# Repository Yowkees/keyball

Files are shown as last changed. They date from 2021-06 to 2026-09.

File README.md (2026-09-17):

# Keyball Series

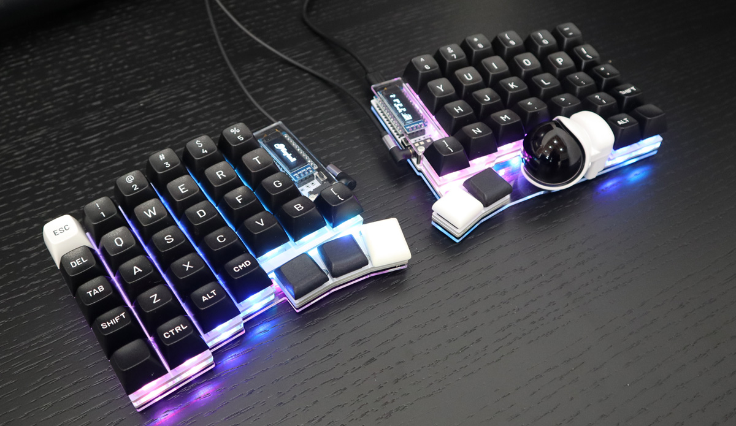
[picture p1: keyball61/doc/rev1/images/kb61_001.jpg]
Keyball61


Keyball series is keyboard family which have 100% track ball.

Keyboards in the family are:

* Available
    * Keyball39: split + 39 keys + a track ball
    * Keyball44: split + 44 keys + a track ball
    * Keyball61: split + 61 keys + a track ball
    * Keyball+ : split + 38 or 39 keys + a track ball
* Unavailable
    * Keyball46 (first one!)
    * One47

## Where to Buy

|Keyboard |Shirogane Lab / 白銀ラボ |Yushakobo / 遊舎工房 |
|---|---|---|
|Keyball39  |<https://shiroganelab.com/products/keyball39> |<https://shop.yushakobo.jp/products/5357>  |
|Keyball44  |<https://shiroganelab.com/products/keyball44> |<https://shop.yushakobo.jp/products/8337>  |
|Keyball61  |<https://shiroganelab.com/products/keyball61> |<https://shop.yushakobo.jp/products/5358>  |
|Keyball+  |[TOKYO KEYBOARD EXPO 2026](https://tkx.yushakobo.jp/tkx2026/)|[TOKYO KEYBOARD EXPO 2026](https://tkx.yushakobo.jp/tkx2026/)|

## Build Guide

*   Keyball39:
    [English/英語](/keyball39/doc/rev1/buildguide_en.md),
    [日本語/Japanese](./keyball39/doc/rev1/buildguide_jp.md)
*   Keyball44:
    [English/英語](./keyball44/doc/rev1/buildguide_en.md),
    [日本語/Japanese](./keyball44/doc/rev1/buildguide_jp.md)
*   Keyball61:
    [English/英語](./keyball61/doc/rev1/buildguide_en.md),
    [日本語/Japanese](./keyball61/doc/rev1/buildguide_jp.md)
*   Keyball+:
    [English/英語](./keyballplus/doc/rev1/buildguide_en.md),
    [日本語/Japanese](./keyballplus/doc/rev1/buildguide_jp.md)
    
## Firmware

See [document for firmware source code](./qmk_firmware/keyboards/keyball/readme.md).

### Pre-compiled Firmwares

(TO BE DOCUMENTED)

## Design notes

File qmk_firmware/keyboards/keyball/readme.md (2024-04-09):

# Keyball series

This directory includes source code of Keyball keyboard series:

| Name | Description
|---|---
|[Keyball46](./keyball46)|A split keyboard with 46 vertically staggered keys and 34mm track ball.
|[Keyball61](./keyball61)|A split keyboard with 61 vertically staggered keys and 34mm track ball.
|[Keyball39](./keyball39)|A split keyboard with 39 vertically staggered keys and 34mm track ball.
|[ONE47](./one47)|A keyboard with 47 vertically keys and 34mm trackball. It will support BLE Micro Pro.
|[Keyball44](./keyball44)|A split keyboard with 44 vertically staggered keys and 34mm track ball.

* Keyboard Designer: [@Yowkees](https://twitter.com/Yowkees)  
* Hardware Supported: ProMicro like footprint
* Hardware Availability: See [Where to Buy](../../../README.md#where-to-buy)

See each directories for each keyboards in a table above.

## How to build

1. Check out this repository.

    ```console
    $ git clone https://github.com/Yowkees/keyball.git keyball
    ```

2. Check out [qmk/qmk_firmware](https://github.com/qmk/qmk_firmware/) repository in another place.

    ```console
    $ git clone https://github.com/qmk/qmk_firmware.git --depth 1 --recurse-submodules --shallow-submodules -b 0.22.14 qmk
    ```

    Currently Keyball firmwares are verified to compile with QMK 0.22.14

3. Create a symbolic link to this `keyball/` directory from [qmk/qmk_firmware]'s `keyboards/` directory.

    ```console
    $ ls
    keyball/ qmk/

    $ cd qmk/keyboards
    $ ln -s ../../keyball/qmk_firmware/keyboards/keyball keyball
    $ ls keyball/
    drivers/  keyball39/  keyball44/  keyball46/  keyball61/  lib/  one47/  readme.md
    $ cd ..
    ```

4. `make` your Keyball firmware.

    ```console
    # Build Keyball39 firmware with "default" keymap
    $ make SKIP_GIT=yes keyball/keyball39:default

    # Build Keyball44 firmware with "default" keymap
    $ make SKIP_GIT=yes keyball/keyball44:default

    # Build Keyball61 firmware with "default" keymap
    $ make SKIP_GIT=yes keyball/keyball61:default
    ```

There are three keymaps provided at least:

* `via` - Standard version with [Remap](https://remap-keys.app/) or VIA to change keymap
* `test` - Easy-to-use version for checking operation at build time
* `default` - Base version for creating your own customized firmware

## How to create your keymap

1. Fork this Yowkees/keyball repository
2. Checkout forked repository
3. (OPTIONAL) Create a new branch
4. Add a your keymap, or make some changes
5. Commit changes and push it to your forked repository
6. Open your forked repository with web browser
7. Click and open "Actions" tab
8. Click "Build a firmware on demand" in Workflows on left panel
9. Press "Run workflow" button on right side, then you will see forms
10. (OPTIONAL) Select a your working branch
11. Select a "Keyboard" from drop-down list
12. Enter the "keymap" you want to build
13. Click "Run workflow"
14. Wait a minute until the firmware build is finished
15. Click a latest workflow run and open details
16. Download built firmware in "Artifacts" section

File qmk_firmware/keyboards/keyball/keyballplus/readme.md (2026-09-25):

# Keyballplus

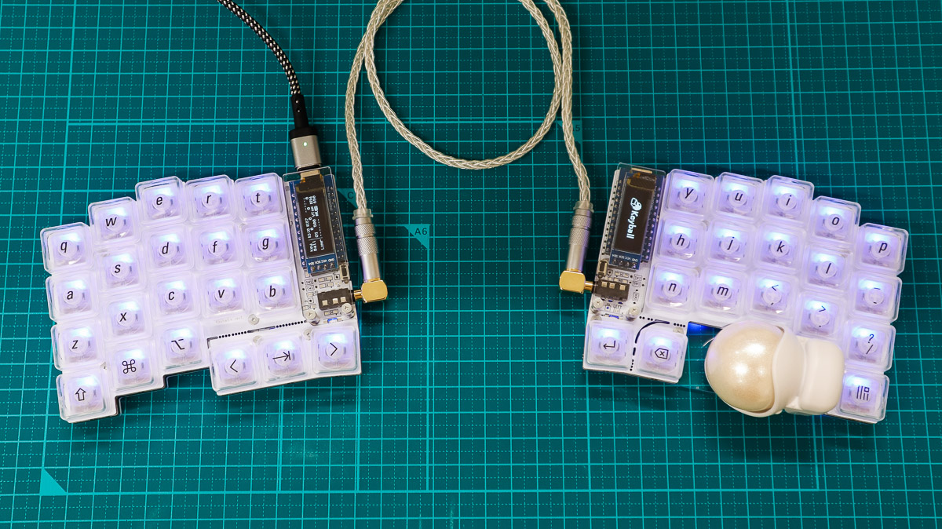
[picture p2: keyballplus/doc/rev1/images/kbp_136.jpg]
keyballplus


A split keyboard with 39 or 38 vertically staggered keys and 34mm track ball.

* Keyboard Maintainer: [@Yowkees](https://twitter.com/Yowkees)
* Hardware Supported: keyballPlus PCB, ProMicro
* Hardware Availability:
    * <https://shop.yushakobo.jp>
    * <https://shiroganelab.com>

Make example for this keyboard (after setting up your build environment):

    make keyball/keyballPlus:default

See the [build environment setup](https://docs.qmk.fm/#/getting_started_build_tools) and the [make instructions](https://docs.qmk.fm/#/getting_started_make_guide) for more information. Brand new to QMK? Start with our [Complete Newbs Guide](https://docs.qmk.fm/#/newbs).

## Special keycodes

See [Special Keycode](../lib/keyball/keycodes.md) file.

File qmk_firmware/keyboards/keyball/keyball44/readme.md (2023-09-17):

# Keyball44

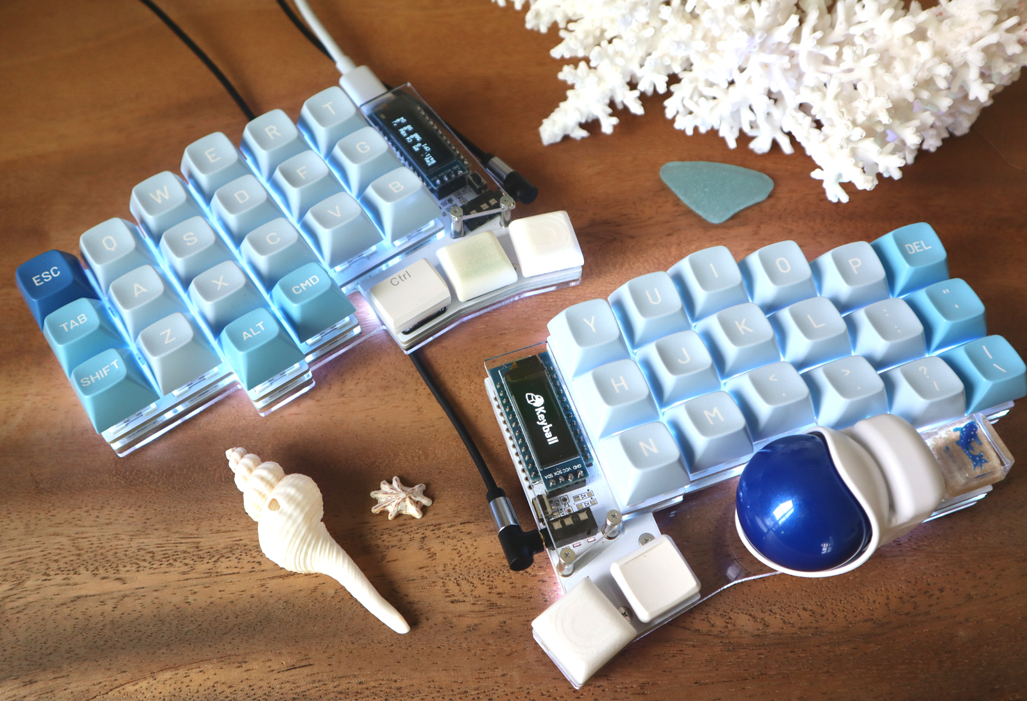
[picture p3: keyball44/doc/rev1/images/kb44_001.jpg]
Keyball44


A split keyboard with 44 vertically staggered keys and 34mm track ball.

* Keyboard Maintainer: [@Yowkees](https://twitter.com/Yowkees)
* Hardware Supported: Keyball44 PCB, ProMicro
* Hardware Availability:
    * <https://shirogane-lab.net/items/64b7a006eb6dbe00346cd0c5>

Make example for this keyboard (after setting up your build environment):

    make keyball/keyball44:default

See the [build environment setup](https://docs.qmk.fm/#/getting_started_build_tools) and the [make instructions](https://docs.qmk.fm/#/getting_started_make_guide) for more information. Brand new to QMK? Start with our [Complete Newbs Guide](https://docs.qmk.fm/#/newbs).

## Special keycodes

See [Special Keycode](../lib/keyball/keycodes.md) file.

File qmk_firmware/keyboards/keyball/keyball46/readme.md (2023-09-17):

# Keyball46

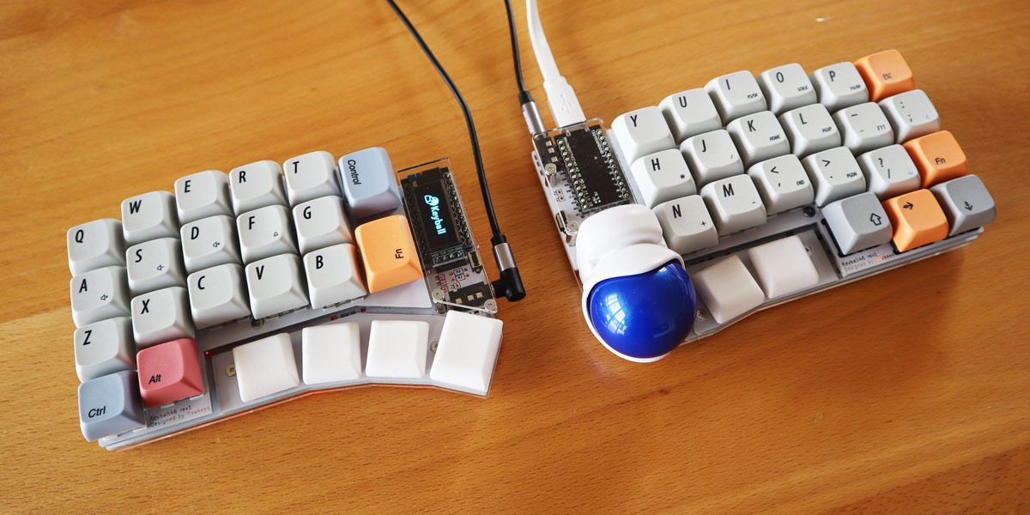
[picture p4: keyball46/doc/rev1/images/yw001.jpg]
Keyball46


A split keyboard with 4x6 vertically staggered keys and 34mm track ball.

* Keyboard Maintainer: [@Yowkees](https://twitter.com/Yowkees)
* Hardware Supported: Keyball46 PCB, ProMicro
* Hardware Availability:
  Unavailable
  * ~~[BOOTH](https://yowkees.booth.pm/)~~

Make example for this keyboard (after setting up your build environment):

    make keyball/keyball46:default

See the [build environment setup](https://docs.qmk.fm/#/getting_started_build_tools) and the [make instructions](https://docs.qmk.fm/#/getting_started_make_guide) for more information. Brand new to QMK? Start with our [Complete Newbs Guide](https://docs.qmk.fm/#/newbs).

## Special keycodes

See [Special Keycode](../lib/keyball/keycodes.md) file.

## Changes

* Keyball46 firmware V2 has some incompatibles with V1. See [document](./docs/diff_from_v1.md) for details.

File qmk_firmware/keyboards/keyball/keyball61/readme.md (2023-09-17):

# Keyball61

Keyball61

A split keyboard with 61 vertically staggered keys and 34mm track ball.

* Keyboard Maintainer: [@Yowkees](https://twitter.com/Yowkees)
* Hardware Supported: Keyball61 PCB, ProMicro
* Hardware Availability:
    * <https://shop.yushakobo.jp/products/5358>
    * <https://shirogane-lab.net/items/64b8ed191435c1002bc4cd30>

Make example for this keyboard (after setting up your build environment):

    make keyball/keyball61:default

See the [build environment setup](https://docs.qmk.fm/#/getting_started_build_tools) and the [make instructions](https://docs.qmk.fm/#/getting_started_make_guide) for more information. Brand new to QMK? Start with our [Complete Newbs Guide](https://docs.qmk.fm/#/newbs).

## Special keycodes

See [Special Keycode](../lib/keyball/keycodes.md) file.

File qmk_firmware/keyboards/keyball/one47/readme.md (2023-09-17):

# KeyballONE47

![KeyballONE47]()

A split keyboard with 47 vertically staggered keys and 34mm track ball.

* Keyboard Maintainer: [@Yowkees](https://twitter.com/Yowkees)
* Hardware Supported: KeyballONE47 PCB, ProMicro
* Hardware Availability:
    Unavailable

Make example for this keyboard (after setting up your build environment):

    make keyball/one47:test

See the [build environment setup](https://docs.qmk.fm/#/getting_started_build_tools) and the [make instructions](https://docs.qmk.fm/#/getting_started_make_guide) for more information. Brand new to QMK? Start with our [Complete Newbs Guide](https://docs.qmk.fm/#/newbs).

## Special keycodes

See [Special Keycode](../lib/keyball/keycodes.md) file.

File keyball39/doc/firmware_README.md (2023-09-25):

# Keyball39 firmwares README

## Description in English

This archive includes firmwares for Keyball39.

Included variations of firmware are below:

* `default` - base version for customization
* `test` - used for testing during assembly
* `via` - Recommended version that can use [Remap][remap]

The recommended usage of these firmwares is:

1.  Please use `test` version during assemble the keyboard.
    It is designed to help verifying that the soldering of diodes and switch
    sockets is correct, and easy to check the operation of RGB LED.
2.  After confirming the operation, rewrite it with `via` version.

## 日本語の説明

このアーカイブには Keyball39 のファームウェアが含まれています。

含まれているファームウェアのバリエーションは以下の通りです:

* `default` - カスタマイズの基礎となる版
* `test` - 組立時のテストに用いる版
* `via` - [Remap][remap] で利用できる、推奨版

推奨する使い方は次の通りです:

1.  キーボードを組み立てる際は `test` を使ってください。
    ダイオードやスイッチソケットのハンダ付けが正しいか確認できる他、
    RGB LEDの動作確認が容易になるように構成してあります。
2.  動作確認が取れたあとは `via` に書き換えて利用してください。

## Fixed keymap for `test`

This keymap does not use any layers or QMK function keys to make it easier to test.

```
KC_Q     KC_W     KC_E     KC_R     KC_T                            KC_Y     KC_U     KC_I     KC_O     KC_P
KC_A     KC_S     KC_D     KC_F     KC_G                            KC_H     KC_J     KC_K     KC_L     KC_SCLN
KC_Z     KC_X     KC_C     KC_V     KC_B                            KC_N     KC_M     KC_COMM  KC_DOT   KC_SLSH
KC_LCTL (KC_LGUI  KC_LALT  KC_ESC)  KC_SPC   KC_TAB        KC_BSPC  KC_ENT  (KC_ESC   KC_RALT  KC_RGUI) KC_RSFT
```

The area enclosed in parentheses may be replaced by a trackball.

<https://config.qmk.fm/#/test> is useful for testing keys.

[remap]:https://remap-keys.app/

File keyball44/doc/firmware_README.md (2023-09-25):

# Keyball44 firmwares README

## Description in English

This archive includes firmwares for Keyball44.

Included variations of firmware are below:

* `default` - base version for customization
* `test` - used for testing during assembly
* `via` - Recommended version that can use [Remap][remap]

The recommended usage of these firmwares is:

1.  Please use `test` version during assemble the keyboard.
    It is designed to help verifying that the soldering of diodes and switch
    sockets is correct, and easy to check the operation of RGB LED.
2.  After confirming the operation, rewrite it with `via` version.

## 日本語の説明

このアーカイブには Keyball44 のファームウェアが含まれています。

含まれているファームウェアのバリエーションは以下の通りです:

* `default` - カスタマイズの基礎となる版
* `test` - 組立時のテストに用いる版
* `via` - [Remap][remap] で利用できる、推奨版

推奨する使い方は次の通りです:

1.  キーボードを組み立てる際は `test` を使ってください。
    ダイオードやスイッチソケットのハンダ付けが正しいか確認できる他、
    RGB LEDの動作確認が容易になるように構成してあります。
2.  動作確認が取れたあとは `via` に書き換えて利用してください。

## Fixed keymap for `test`

This keymap does not use any layers or QMK function keys to make it easier to test.

```
KC_ESC   KC_Q     KC_W     KC_E     KC_R     KC_T                           KC_Y     KC_U     KC_I     KC_O     KC_P     KC_MINS
KC_TAB   KC_A     KC_S     KC_D     KC_F     KC_G                           KC_H     KC_J     KC_K     KC_L     KC_SCLN  KC_QUOT
KC_LSFT  KC_Z     KC_X     KC_C     KC_V     KC_B                           KC_N     KC_M     KC_COMM  KC_DOT   KC_SLSH  KC_RSFT
         KC_LCTL    (KC_LGUI   KC_LALT)      KC_SPC   KC_DEL       KC_BSPC  KC_ENT     (KC_RALT   KC_RGUI)      KC_RCTL
```

The area enclosed in parentheses may be replaced by a trackball.

<https://config.qmk.fm/#/test> is useful for testing keys.

[remap]:https://remap-keys.app/

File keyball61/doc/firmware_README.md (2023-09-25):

# Keyball61 firmwares README

## Description in English

This archive includes firmwares for Keyball61.

Included variations of firmware are below:

* `default` - base version for customization
* `test` - used for testing during assembly
* `via` - Recommended version that can use [Remap][remap]

The recommended usage of these firmwares is:

1.  Please use `test` version during assemble the keyboard.
    It is designed to help verifying that the soldering of diodes and switch
    sockets is correct, and easy to check the operation of RGB LED.
2.  After confirming the operation, rewrite it with `via` version.

## 日本語の説明

このアーカイブには Keyball61 のファームウェアが含まれています。

含まれているファームウェアのバリエーションは以下の通りです:

* `default` - カスタマイズの基礎となる版
* `test` - 組立時のテストに用いる版
* `via` - [Remap][remap] で利用できる、推奨版

推奨する使い方は次の通りです:

1.  キーボードを組み立てる際は `test` を使ってください。
    ダイオードやスイッチソケットのハンダ付けが正しいか確認できる他、
    RGB LEDの動作確認が容易になるように構成してあります。
2.  動作確認が取れたあとは `via` に書き換えて利用してください。

## Fixed keymap for `test`

This keymap does not use any layers or QMK function keys to make it easier to test.

```
KC_ESC   KC_1     KC_2     KC_3     KC_4     KC_5                            KC_6     KC_7     KC_8     KC_9     KC_0     KC_MINS
KC_GRV   KC_Q     KC_W     KC_E     KC_R     KC_T                            KC_Y     KC_U     KC_I     KC_O     KC_P     KC_EQL
KC_LCTL  KC_A     KC_S     KC_D     KC_F     KC_G                            KC_H     KC_J     KC_K     KC_L     KC_SCLN  KC_QUOT
KC_LSFT  KC_Z     KC_X     KC_C     KC_V     KC_B     KC_LBRC       KC_RBRC  KC_N     KC_M     KC_COMM  KC_DOT   KC_SLSH  KC_RSFT
KC_LGUI  KC_APP  (KC_HOME  KC_END   KC_LALT) KC_SPC   KC_TAB        KC_BSPC  KC_ENT  (KC_RALT  KC_PGUP  KC_PGDN) KC_BSLS  KC_RGUI
```

The area enclosed in parentheses may be replaced by a trackball.

<https://config.qmk.fm/#/test> is useful for testing keys.

[remap]:https://remap-keys.app/

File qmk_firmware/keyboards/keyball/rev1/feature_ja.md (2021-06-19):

# Keyball のカスタマイズ可能な機能

## トラックボール

### `TRACKBALL_DRIVER_DISABLE`

Keyballに付属のデフォルトのトラックボールドライバーを無効化する設定項目です。
各キーマップで独自のドライバーを用意する場合に設定することで、デフォルトドライ
バーが省略されその分ファームウェアが小さくなります。

各キーマップの config.h で設定できます。

設定例:

```c
#define TRACKBALL_DRIVER_DISABLE 100
```

### `TRACKBALL_SAMPLE_COUNT`

トラックボールでは光学センサから数回に渡って読み取った平均値をポインティングデ
バイスの移動量として送信しており、 `TRACKBALL_SAMPLE_COUNT` はその回数を指定す
る設定項目です。

各キーマップの config.h で設定できます。デフォルトは `10` で `0` 以下の値を設定
するとコンパイルエラーになります。

設定例:

```c
#define TRACKBALL_SAMPLE_COUNT 100
```

### `TRACKBALL_SCROLL_DIVIDER`

スクロールモードが有効な場合、トラックボールはトラックボールの移動量をマウスカーソルではなくスクロール量として送信しますが、送る時に移動量が小さくなるように割っており、 `TRACKBALL_SCROLL_DIVIDER` はその分母を指定する設定項目です。

各キーマップの config.h で設定できます。デフォルトは `10` で `0` 以下の値を設定
するとコンパイルエラーになります。

### `trackball_process_delta_user()`

`trackball_process_delta_user()` 関数を定義するとトラックボールの移動量をどのよ
うに扱うかをユーザーがカスタマイズできます。`trackball_process_delta_user()` は
ドライバーがトラックボールの移動を検知した際に、その移動量を引数にして呼び出し
ます。ユーザーはポインティングデバイスとしてレポートを送っても良いですし、それ
以外のことをしてもかまいません。

各キーマップの keymap.c で定義できます。

定義例: マウスカーソルに上下反転させて適用する

```c
void trackball_process_delta_user(int8_t dx, int8_t dy) {
    report_mouse_t r = pointing_device_get_report();
    r.x = -dx;
    r.y = -dy;
    pointing_device_set_report(r);
}
```

### `bool trackball_get_scroll_mode(void)` API

トラックボールの現在のスクロールモードを取得します。

### `void trackball_set_scroll_mode(bool mode)` API

トラックボールのスクロールモードを変更します。

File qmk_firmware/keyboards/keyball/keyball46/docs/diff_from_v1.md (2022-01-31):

# Differences from V1

* `KEYBALL_SCROLL_DIVIDER` - deleted

  V2 is able to change scroll divider dynamically by keycodes:

  * `SCRL_DVI` - increment scroll divider (maximum 7)
  * `SCRL_DVD` - decrement scroll divider (mininum 1)

  The effect of scroll divider is changed.
  It is applied as `1 / (2 ^ (n-1))`.
  Therefore, its divider will be like this table:

  Value | Divider
  -----:|-------:
  1     | 1 / 1
  2     | 1 / 2
  3     | 1 / 4
  4     | 1 / 8
  5     | 1 / 16
  6     | 1 / 32
  7     | 1 / 64

  Default is 4, it can be changed by defining `KEYBALL_SCROLL_DIV_DEFAULT` in your config.h

* `KEYBALL_POINTER_DIVIDER` - deleted

  V2 controls resolution (CPI) of optical sensor PMW3360DM directly.
  The minimum is 100, and the maximum is 12000, with 100 step.

  CPI can be changed by keycodes:

  * `CPI_I1K`  - increase 1000 CPI 
  * `CPI_I100` - increase 100 CPI
  * `CPI_D100` - decrease 100 CPI
  * `CPI_D1K`  - decrease 1000 CPI

  Default is 500, it can be changed by defiing `KEYBALL_CPI_DEFAULT` in your
  config.h

* `void keyball_process_trackball_default()` API - deleted

* `void keyball_process_trackball_user()` overridable function - deleted

* `TRACKBALL_MAX_NUMBER` constant - deleted

* `TRACKBALL_SAMPLE_COUNT` - deleted

  V2 controls resolution (CPI) of optical sensor PMW3360DM directly.

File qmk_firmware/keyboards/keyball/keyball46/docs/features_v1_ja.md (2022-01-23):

# Keyball のカスタマイズ可能な機能

## キーマップで利用可能な Keyball の機能

### `bool keyball_get_scroll_mode(void)` API

トラックボールの現在のスクロールモードを取得します。

### `void keyball_set_scroll_mode(bool mode)` API

トラックボールのスクロールモードを変更します。

### `KEYBALL_SCROLL_DIVIDER`

スクロールモードではトラックボールの移動量を `KEYBALL_SCROLL_DIVIDER` で割るこ
とで程よいスクロール量に調整しています。

各キーマップの config.h で設定できます。デフォルトは `10` で `0` 以下の値を設定
するとコンパイルエラーになります。

### `KEYBALL_POINTER_DIVIDER`

トラックボールによるポインタの移動量を `KEYBALL_POINTER_DIVIDER` で割ることで調
整できます。

各キーマップの config.h で設定できます。デフォルトは `1` で `0` 以下の値を設定
するとコンパイルエラーになります。

### `void keyball_process_trackball_default()` API

トラックボールイベントのデフォルトハンドラです。1つ目のトラックボールはマウスポ
インタに、2つ目のトラックボールはスクロール量に反映されます。

### `void keyball_process_trackball_user()` オーバーライド可能な関数

トラックボールの移動方法を独自に定義できます。トラックボールの移動量をOLEDに表
示したい時などに `keyball_process_trackball_default` と合わせて利用できます。

例:

```c
void keyball_process_trackball_user(
        const trackball_delta_t *primary,
        const trackball_delta_t *secondary) {
    // FIXME: modify or apply deltas for your purpose.
}
```

## トラックボールドライバ

Keyballに搭載されているトラックボールのドライバーです。

### `TRACKBALL_MAX_NUMBER` 定数

サポート可能な最大のトラックボール数で現在は `2` です。

### `TRACKBALL_SAMPLE_COUNT`

トラックボールでは光学センサから数回に渡って読み取った平均値をポインティングデ
バイスの移動量として送信しており `TRACKBALL_SAMPLE_COUNT` はその回数を指定する
設定項目です。

各キーマップの config.h で設定できます。デフォルトは `10` で `0` 以下の値を設定
するとコンパイルエラーになります。

設定例:

```c
#define TRACKBALL_SAMPLE_COUNT 100
```

## OLED Kit

OLED KitはKeyballのキーマップがOLEDにロゴなどの各種情報を表示するのを容易にする
ためのライブラリです。キーマップの rules.mk に `OLED_ENABLE = yes` を追
加すれば自動的に利用されますが、キーマップで表示内容をカスタマイズすることもで
きます。

表示内容をカスタマイズするには keymap.c 等に以下の2つを追加してください。

1. `#include "lib/oledkit/oledkit.h"`
2. `void oledkit_render_info_user(void)` を定義する

`oledkit_render_info_user()` はプライマリ(USBケーブルが接続されている)側のキー
ボードに情報を表示する際にコールバックされる関数です。レイヤー状態などの各種情
報を `oled_write_*()` を用いてプライマリ側のOLEDに描画することができます。

例: keymaps/default/keymap.c より抜粋

```c
#ifdef OLED_ENABLE

void oledkit_render_info_user(void) {
    const char *n;
    switch (get_highest_layer(layer_state)) {
        case _QWERTY:
            n = PSTR("Default");
            break;
        case _RAISE:
            n = PSTR("Raise");
            break;
        case _LOWER:
            n = PSTR("Lower");
            break;
        case _BALL:
            n = PSTR("Adjust");
            break;
        default:
            n = PSTR("Undefined");
            break;
    }
    oled_write_P(PSTR("Layer: "), false);
    oled_write_ln_P(n, false);
}

#endif
```

この例は現在アクティブなレイヤー名を表示するという、OLEDの良くある利用方法で
す。

以下では OLED Kit の設定項目を解説します。

### `OLEDKIT_DISABLE` define マクロ

OLED Kitを無効化する設定項目です。各キーマップでOLED Kitを使いたくない場合、す
なわちOLED表示を完全に自身でコントロールしたい場合に設定してください。

各キーマップの config.h で設定できます。

設定例:

```c
#define OLEDKIT_DISABLE
```

### `oledkit_render_info_user()` オーバーライド可能関数

`oledkit_render_info_user()` 関数を定義するとプライマリ側のOLEDに表示する内容を
カスタマイズできます。デフォルトではロゴを表示するようになっています。

各キーマップの keymap.c で定義できます。

設定例は上述してあります。

### `oledkit_render_logo_user()` オーバーライド可能関数

`oledkit_render_logo_user` 関数を定義するとセカンダリ(USBケーブルが接続されてい
ない)側のOLEDに表示する内容をカスタマイズできます。デフォルトではロゴを表示する
ようになっています。ただしキーボードとしての主要な情報はほぼプライマリ側に集約
されているため、アクティブなレイヤーやタイプしたキーなどの情報を表示することは
できません。

各キーマップの keymap.c で定義できます。

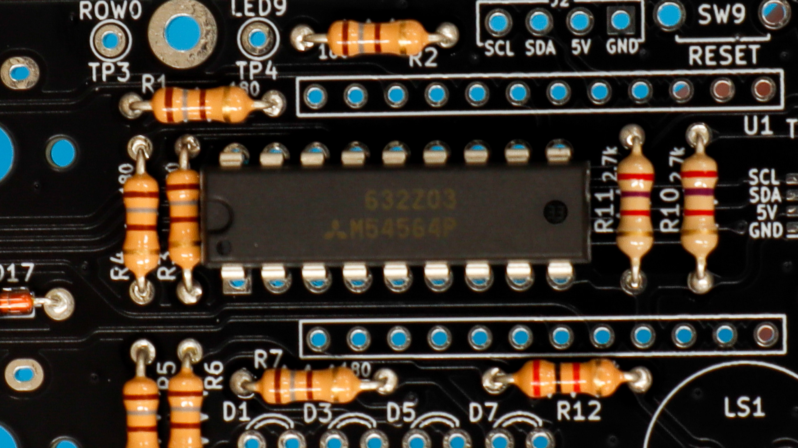
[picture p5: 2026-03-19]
Keybit8/doc/rev1/images/_MG_8466.jpg

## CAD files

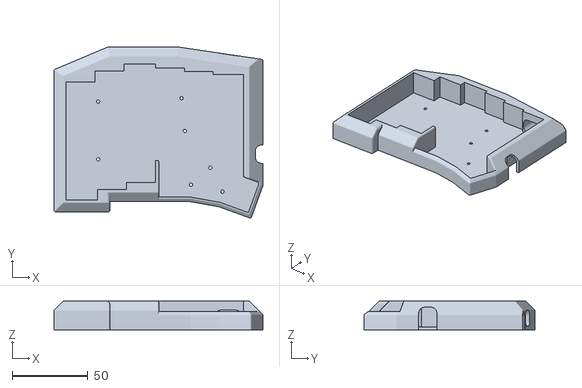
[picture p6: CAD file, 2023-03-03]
keyball39/3D_Printer_STL/Keyball39Case1_NoBall_Left_mm.stl
138.0 x 112.9 x 19.0

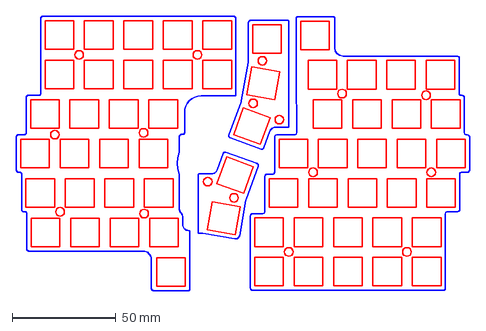
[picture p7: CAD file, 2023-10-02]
keyball61/design_data/Keyball61_MiddleAcryl_3mm.dxf
218.6 x 132.3 mm

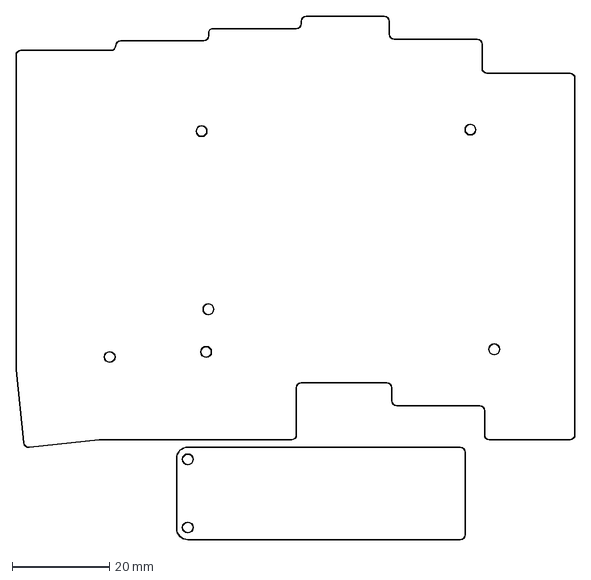
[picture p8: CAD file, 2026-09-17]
keyballplus/design_data/KeyballPlus_Left_Bottom_AcrylicPlate_2mm.dxf
114.7 x 107.4 mm

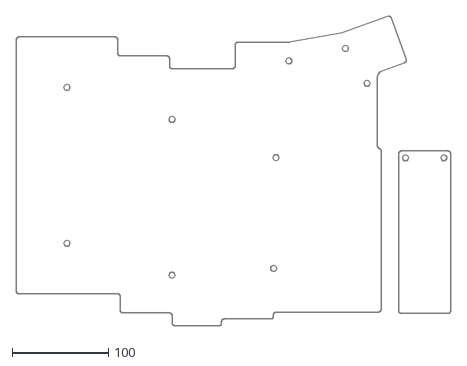
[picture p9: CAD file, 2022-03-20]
keyball61/design_data/Keyball61_Rev1_NoBallSide_Bottom_Acryl_Clear2mm.dxf
450.9 x 321.5

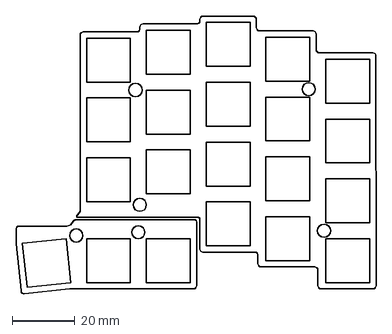
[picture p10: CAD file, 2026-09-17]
keyballplus/design_data/KeyballPlus_Left_Middle_AcrylicPlate_3mm.dxf
114.7 x 88.5 mm

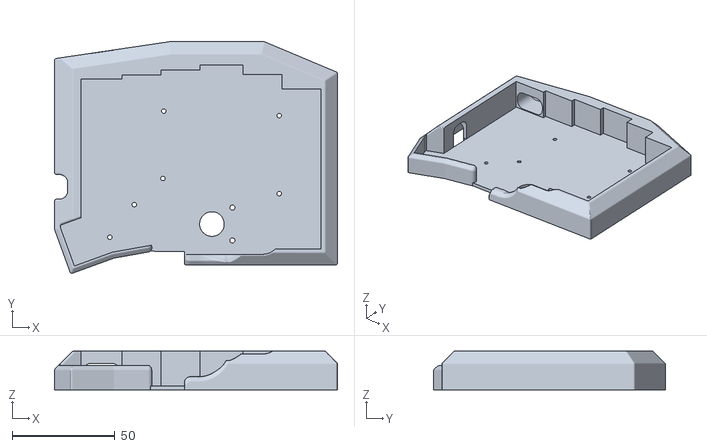
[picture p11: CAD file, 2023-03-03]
keyball39/3D_Printer_STL/Keyball39Case1_Ball_Right_mm.stl
138.0 x 112.9 x 19.0

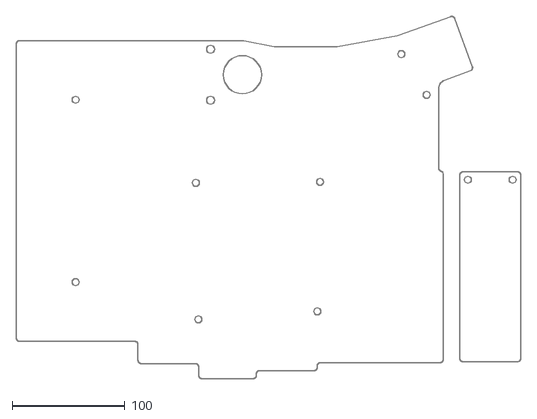
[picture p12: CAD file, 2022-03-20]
keyball61/design_data/Keyball61_Rev1_BallSide_Bottom_Acryl_Clear2mm.dxf
447.2 x 321.2

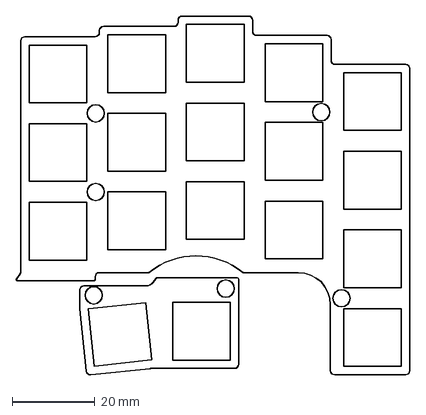
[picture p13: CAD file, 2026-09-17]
keyballplus/design_data/KeyballPlus_Right_Middle_AcrylicPlate_3mm.dxf
95.4 x 87.0 mm

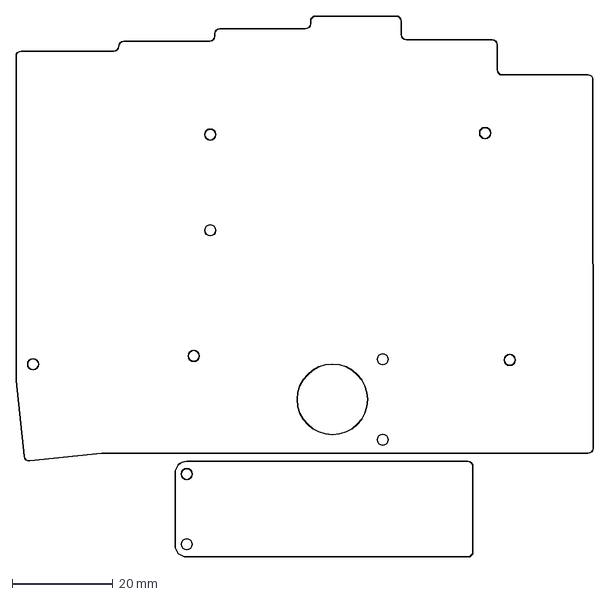
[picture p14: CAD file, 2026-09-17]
keyballplus/design_data/KeyballPlus_Right_Bottom_AcrylicPlate_2mm.dxf
114.7 x 107.5 mm

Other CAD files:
keyball39/design_data/Keyball39_BottomAcryl_2mm_136x185mm.dxf
keyball39/3D_Printer_STL/Keyball39Case1_NoBall_Right_mm.stl
keyball39/design_data/Keyball39_MiddleAcryl_3mm_98x187mm.dxf

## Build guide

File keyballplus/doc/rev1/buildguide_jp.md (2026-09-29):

<!--
  このビルドガイドは Keyball39 のビルドガイド（keyball39/doc/rev1/buildguide_jp.md）をベースに、
  Keyball+ 向けに書き起こした「たたき台」です。
  - キット同梱品リスト（1章）は Keyball+ の説明書（＋説明書A4）の内容を反映済みです。
  - images/ 内の画像は暫定的に Keyball39 のものをコピーして流用しています。
    Keyball+ の実物写真が用意でき次第、同じファイル名で差し替えてください。
  - 残りの「TODO」コメントは、いずれも Keyball+ の実物写真への差し替え待ちです。
-->

# Build Guide for Keyball+

このガイドでは、Keyball+ の組み立て手順を詳しく説明します。

Keyball+ はトラックボール付きの左右分割キーボードキット（39キー）です。Keyball39 をベースに、
MX スイッチとロープロファイル（Kailh Choc）スイッチの**両方**に対応しており、キットには MX 用・
Choc 用それぞれの PCB ソケットとスペーサーが同梱されています。お好みでどちらか一方（または混在）で
組み立てられます。
右手側の親指キーを1つ切り離して 38キー で組むこともできます（[6章](#anchor6)）。

**English build guide for Keyball+ is [here](buildguide_en.md).**

<!-- TODO: Keyball+ の外観写真に差し替え -->


## 【目次】

> **準備編**
 - [1. 部品確認](#anchor1)
   - [1-1. キット同梱品](#anchor1-1)
   - [1-2. 組立前にお客様自身で準備いただく部品](#anchor1-2)
   - [1-3. 組立後でも取り付けられる部品とオプション](#anchor1-3)
 - [2. 準備](#anchor2)
   - [2-1. 必要な工具](#anchor2-1)
   - [2-2. ファームウェア](#anchor2-2)

> **実装編**
 - [3. 実装](#anchor3)
   - [3-1. はんだ付けの前に](#anchor3-1)
   - [3-2. ダイオードの取り付け](#anchor3-2)
   - [3-3. キーソケットのはんだ付け](#anchor3-3)
   - [3-4. LED（オプション）のはんだ付け](#anchor3-4)
   - [3-5. ジャンパのはんだ付け](#anchor3-5)
   - [3-6. TRRSソケット・タクトスイッチ・4連ピンソケット](#anchor3-6)
   - [3-7. ProMicroのはんだ付け](#anchor3-7)
 - [4. トラックボール読み取り基板の組み立て](#anchor4)
   - [4-1. センサーのはんだ付け](#anchor4-1)
   - [4-2. L字コンスルーのはんだ付け](#anchor4-2)
 - [5. 左手側の左右判定ジャンパーをはんだ付け](#anchor5)
 - [6. トッププレートのカット（オプション）](#anchor6)

> **組み立て編**
 - [7. 組み立て](#anchor7)
   - [7-1. 保護プレートの取り付け](#anchor7-1)
   - [7-2. トッププレートの組み立て](#anchor7-2)
   - [7-3. ファームウェアの書き込みと動作確認](#anchor7-3)
   - [7-4. ボトムプレートの組み立て](#anchor7-4)
 - [8. トラックボール取り付け](#anchor8)
   - [8-1. ボール読み取り基板差し込み](#anchor8-1)
   - [8-2. トラックボールケースの組み立て](#anchor8-2)
   - [8-3. トラックボールケース装着](#anchor8-3)

> **仕上げ編**
 - [9. 総仕上げ](#anchor9)
 - [10. キーマップの変更・ファームウェアの更新](#anchor10)
 - [11. Keyball+の使い方♪](#anchor11)

## 1. 部品確認

キットが届きましたらキット同梱品がすべて入っているかご確認ください。

### 1-1. キット同梱品

標準セットは左右どちらかに1つ親指トラックボールを搭載できます。

<!--左右両方にトラックボールを搭載するデュアルボール仕様や、左右両方トラックボール無しで組み立てることもできるように、片手のみのキットも販売しています。--> 

<!--片手セットやデュアルボールセットをご購入の場合は、キットに同封の部品リストにて同梱品をご確認ください。-->

**Keyball+ キットの同梱品一覧**
| 部品名 | 数量 | 備考 |
|:---|:----:|:-----|
| ミドルPCB(左右) | 1組 | メインボード |
| トップPCB(左右) | 1組 | キースイッチ固定用 |
| ミドルアクリルプレート(左右) | 1組 | 親指部を含む |
| ボトムアクリルプレート(左右) | 1組 | 底面カバー |
| ProMicro保護プレート | 2枚 | 基板保護用 |
| 34mmトラックボール保持ケース(上下) | 1組 | ボール固定用 |
| トラックボール読取り基板 | 1枚 | センサー基板 |
| L字コンスルーピン(7ピン) | 1個 | センサー接続用 |
| トラックボール読取りIC＋レンズ | 1セット | PMW3360＋光学レンズ |
| 平頭ネジ M1.7 | 2本 | トラックボールケース固定用 |
| 小頭ネジ M1.7 | 2本 | トラックボールケース同士の固定用 |
| TRRSジャック | 2個 | TRRSケーブル接続用 |
| タクトスイッチ | 2個 | ProMicroリセット用 |
| コンスルーピン(12ピン) | 4個 | ProMicro接続用 |
| ダイオード（チップタイプ） | 48個 | キーマトリクス誤認識防止用（実装はトラックボール側21個・無し側24個の計45個、残りは予備） |
| OLEDモジュール | 2個 | ディスプレイ |
| OLED用ピンソケット＋ピンヘッダ | 2セット | OLED接続用 |
| MXスイッチ用PCBソケット | 40個 | MX仕様で組む場合に使用（実装39個＋予備1個） |
| Chocスイッチ用PCBソケット | 40個 | ロープロ仕様で組む場合に使用（実装39個＋予備1個） |
| スペーサー M2 9mm | 4本 | ProMicro保護プレート用 |
| スペーサー M2 7mm | 12本 | MX仕様のトッププレート用 |
| スペーサー M2 4mm | 12本 | ロープロ仕様のトッププレート用 |
| ネジ M2 3.5mm | 32本 | プレート固定用 |
| クッションゴム | 8個 | 底面の滑り止め用 |

> MX スイッチ用ソケットと Choc スイッチ用ソケットは、実際に使うのはどちらか一方です（キー単位で混在させることもできます）。スペーサーも同様に、MX 仕様なら 7mm、ロープロ仕様なら 4mm を使用します。

### 1-2. 組立前にお客様自身で準備いただく部品

以下の部品はキットに含まれていないため、別途ご購入いただく必要があります。

| 部品名 | 数量 | 備考 |
|:---|:----:|:-----|
| ProMicro | 2個 | 安価なものやUSB Type-C対応のもの等選べます |
| キースイッチ | 39個 | MX 互換 または ロープロファイル（Kailh Choc）。MX/Choc の使い分けは [3-3章](#anchor3-3) 参照。右手親指キーを1つ切り離す場合は38個（[6章](#anchor6)） |
| キーキャップ | 39個 | 1u。使用するスイッチ（MX／Choc）に合わせたもの。右手親指キーを切り離す場合は38個 |
| 直径34mmトラックボール | 1個 | トラックボール使用時に必要 |
| TRSケーブル | 1本 | 左右の接続用。TRRS(4極)ケーブルでも可 |
| USBケーブル | 1本 | PCとの接続用。ご購入いただいたProMicroに対応するもの |

<!-- TODO: Keyball+ 向けの写真に差し替え -->
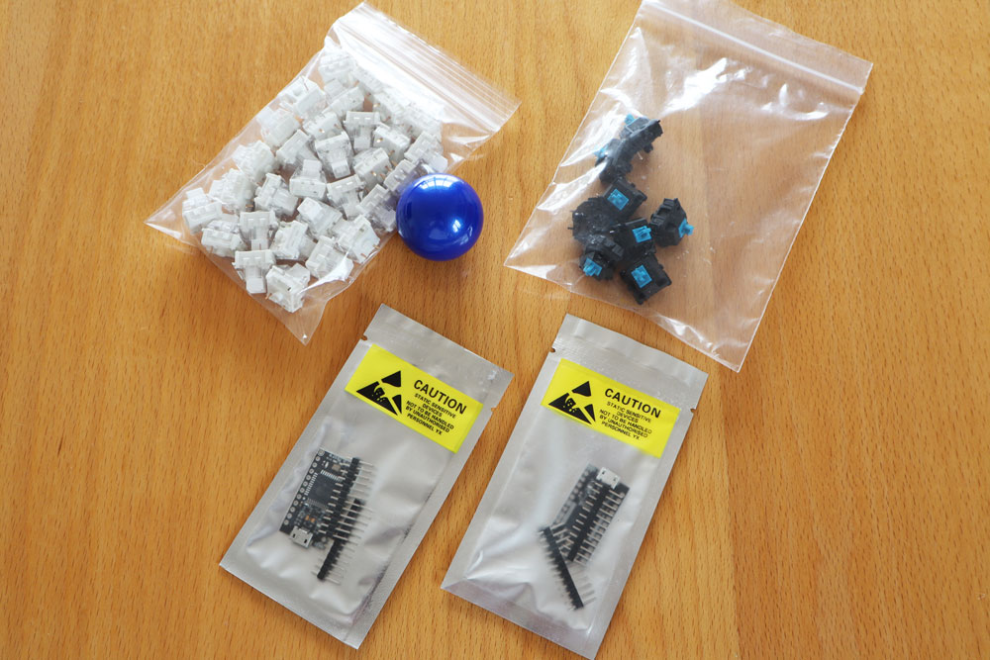
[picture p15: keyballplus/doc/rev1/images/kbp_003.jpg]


### 1-3. 組立後でも取り付けられる部品とオプション

以下の部品はお好みで搭載でき、組み立て後でも取り付けられます。

| 部品名 | 数量 | 備考 |
|:---|:----:|:-----|
| フルカラーLED（YS-SK6812MINI-E） | 55個 | 各キー裏＋アンダーグロー。左手29個・右手26個。右手親指キーを切り離す場合は54個（[6章](#anchor6)）※SK6812MINIは使用できません |

<!-- TODO: Keyball+ 向けの写真に差し替え -->
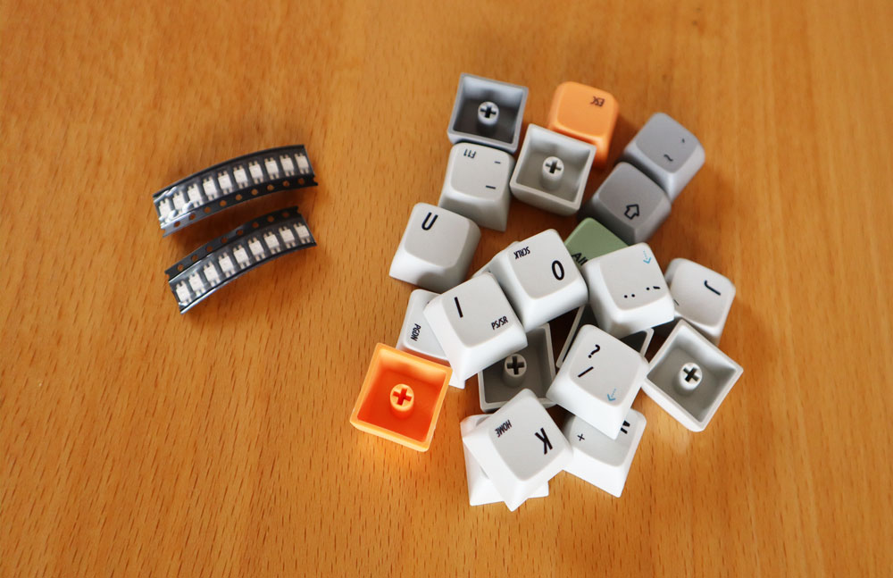
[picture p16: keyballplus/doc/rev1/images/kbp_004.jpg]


## 2. 準備

### 2-1. 必要な工具

Keyball+ の組み立てには下記の工具が必要です。すべて揃っているかご確認ください。

| 工具名 | 用途 |
|:---|:-----|
| はんだごて(LEDを実装する場合は温度調整可能なもの) | はんだ付け作業 |
| はんだ(LEDを実装する場合は低融点のものが有効) | 接続用 |
| 0番＋精密ドライバー | ネジ締め用 |
| ピンセット | 部品取り扱い用 |
| 150番手くらいの紙やすり | プレートを切り離した時の研磨用 |

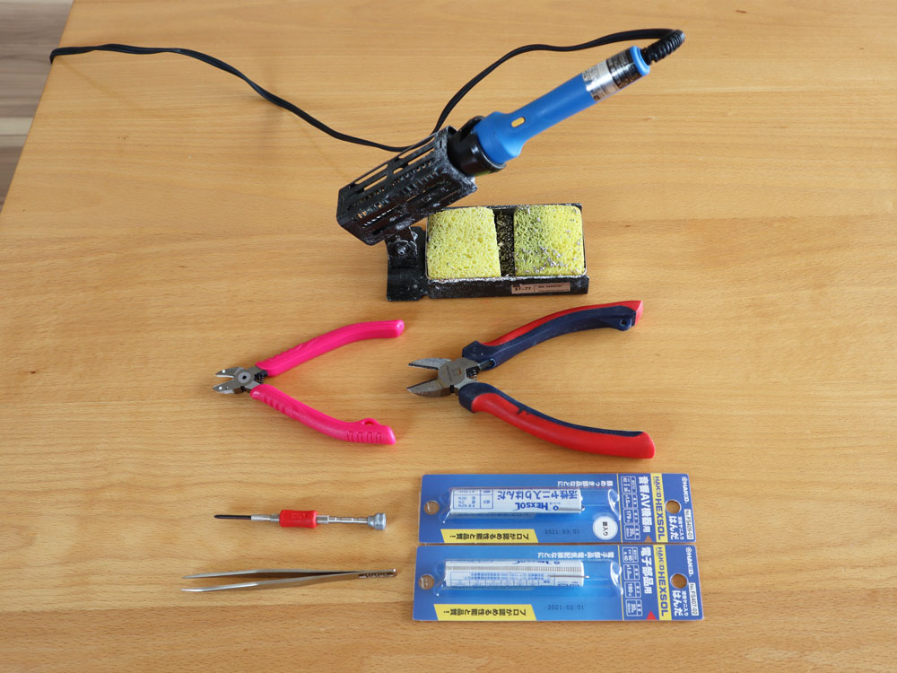
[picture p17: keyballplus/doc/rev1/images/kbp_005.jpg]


### 2-2. ファームウェア

Keyball+ を動作させるには、ご購入いただいたProMicroへのファームウェアの書き込みが必要です。

Keyball+ のファームウェアは、ブラウザから直接キーマップの編集・書き込みができるWebツール **[Keyball Link](https://keyball-link.shiroganelab.com/)** から書き込みます。特別なソフトのインストールは不要です（Google Chrome など WebHID/WebSerial に対応したブラウザが必要です）。

## 3. 実装

ここからはんだ付け作業に入ります。

PCBはリバーシブルになっているので、最初にどちらを左手用/右手用にするか決めます。
右手親指でトラックボールを操作する場合は下写真の赤丸で示した、PCBが欠けている部分にトラックボールが付きます。

<!-- TODO: Keyball+ のPCB写真に差し替え -->
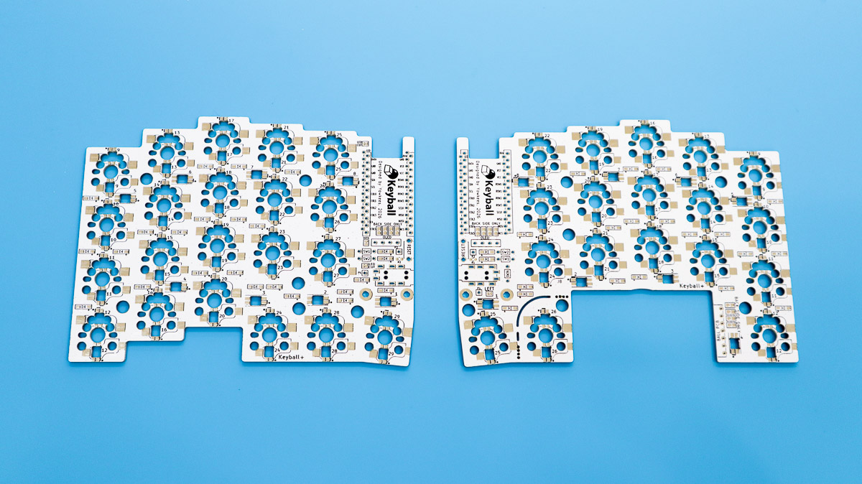
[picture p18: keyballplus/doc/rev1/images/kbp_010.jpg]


左手親指でトラックボールを操作する場合は下写真のような配置です。

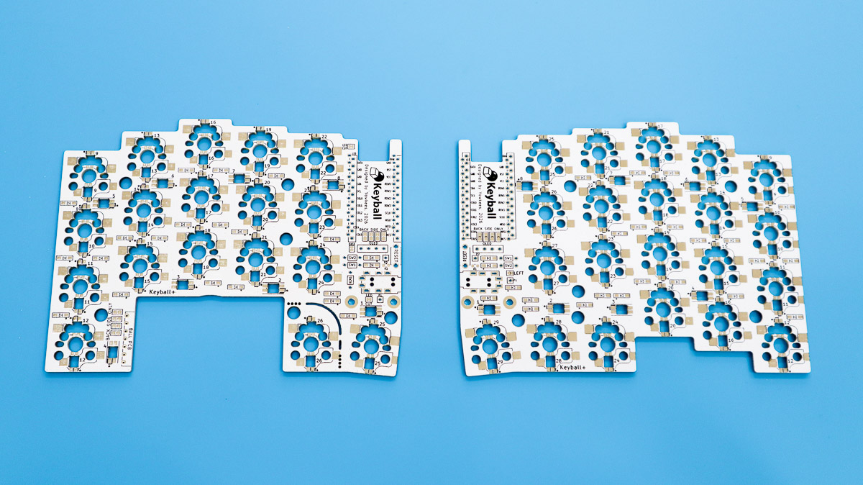
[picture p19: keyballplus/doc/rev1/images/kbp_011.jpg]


本ビルドガイドでは右手にトラックボール付ける仕様で説明します。
>**⚡️ 注意**:裏表を間違えてはんだ付けをしてしまうとやり直しが非常に困難になります。
>下記写真のようにミス防止のため表面にマスキングテープ等の目印を付けてください。

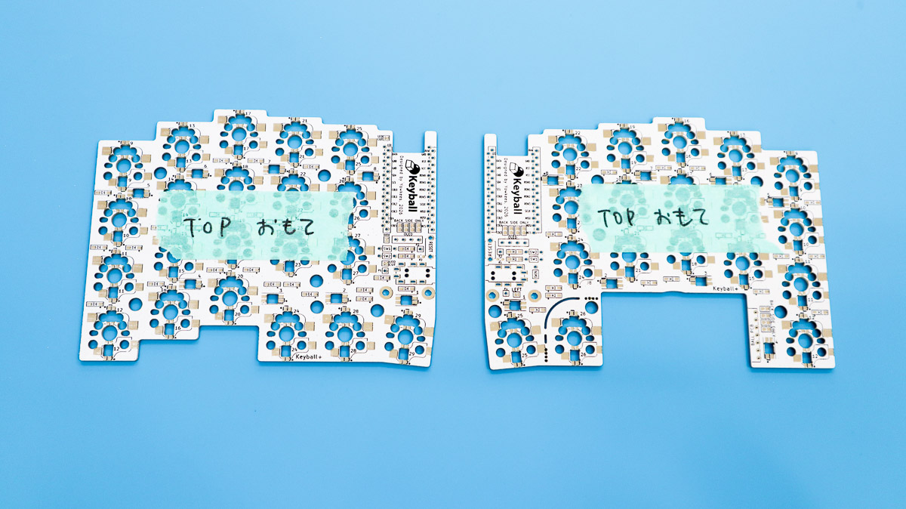
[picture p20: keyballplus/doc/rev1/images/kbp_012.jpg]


### 3-1. はんだ付けの前に
はんだごての"こて先"は竹槍の先端のような形状のものだと平面にはんだを乗せたり、余分なはんだを"すくい取る"事が出来るので使いやすいです。

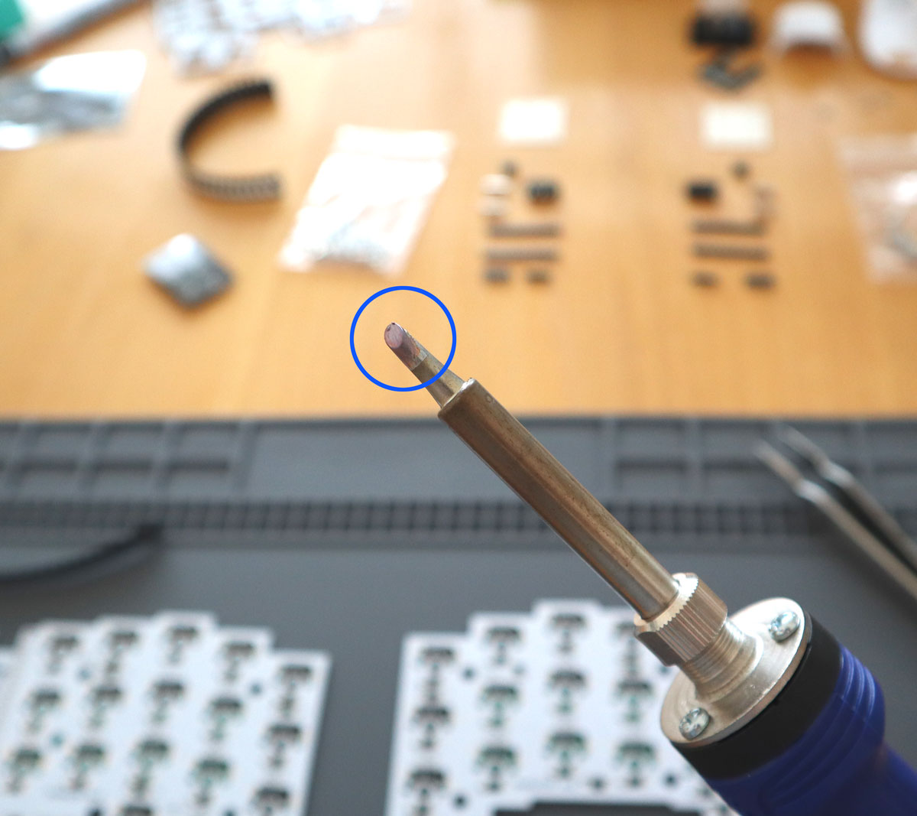
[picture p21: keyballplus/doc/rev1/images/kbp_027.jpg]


### 3-2. ダイオードの取り付け
それではダイオードを順にはんだ付けしていきます。
ダイオードはすべて**裏面**にはんだ付けします。

ダイオードのシルクマークは下写真の矢印で示したマークで、**トラックボール側21個・トラックボール無し側24個（左右で合計45個）** あります。
> **⚡️注意**: ダイオードには極性がありますので、正しい向きで取り付けてください。
向きは部品上の直線とシルクマーク内の矢印の先についている直線が一致する方向です。
> 下記写真をよく見て向きを確認してください。
> 同一基板上のダイオードの向きはすべて同じ向きで配置されています。
はんだ付けを進める中で回りのダイオードと同じ向きになっているか確認しながら行ってください。

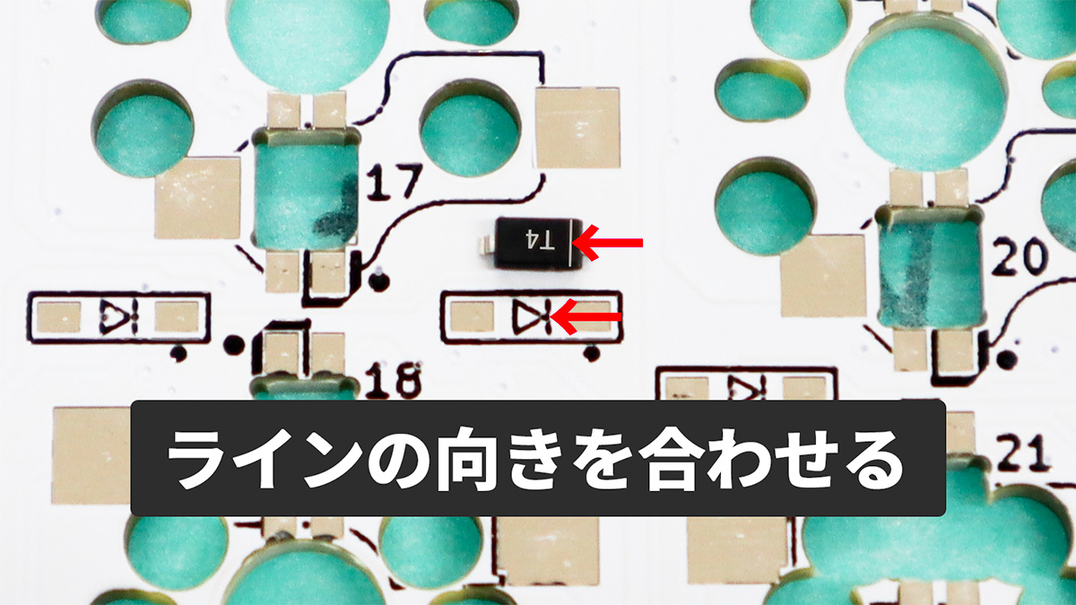
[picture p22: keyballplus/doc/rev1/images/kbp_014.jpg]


ダイオードのシルクには下記写真の赤で示すような黒点があるのでダイオードのはんだ付け後にも極性確認ができます。

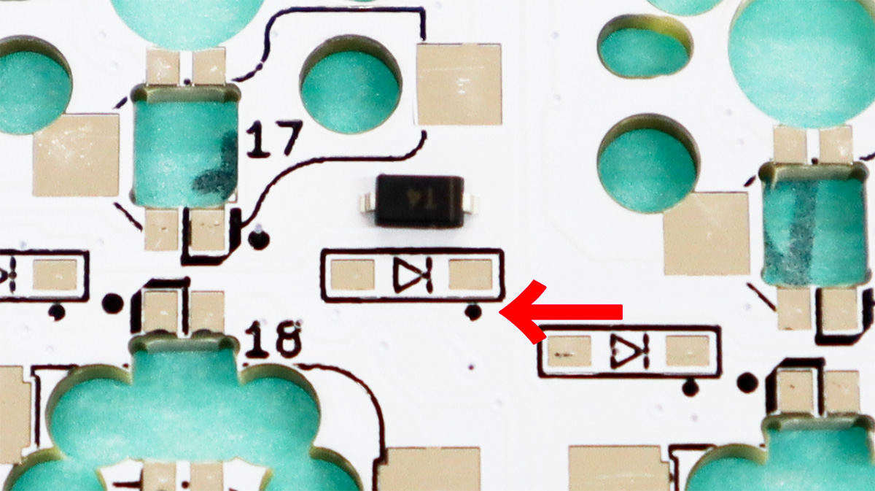
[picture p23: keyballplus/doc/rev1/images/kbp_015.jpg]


はんだ付け開始です。
まずダイオード用パッドの片側にはんだを盛ります。

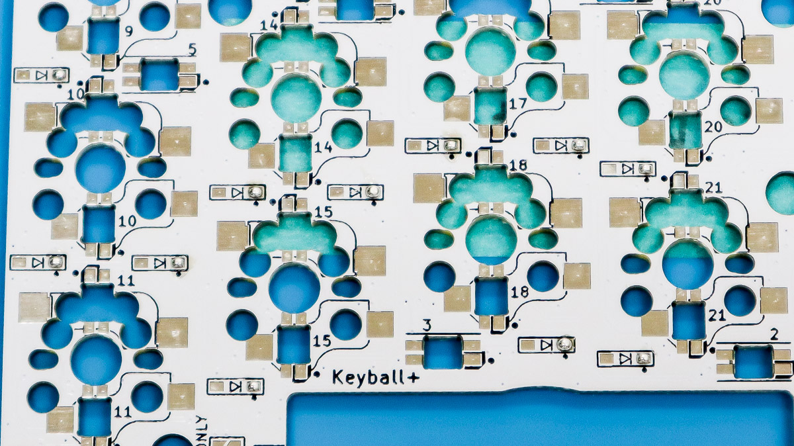
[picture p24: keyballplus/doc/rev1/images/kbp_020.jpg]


ピンセットでダイオードを掴み、事前に盛ったはんだを溶かしながらダイオードを固定します。

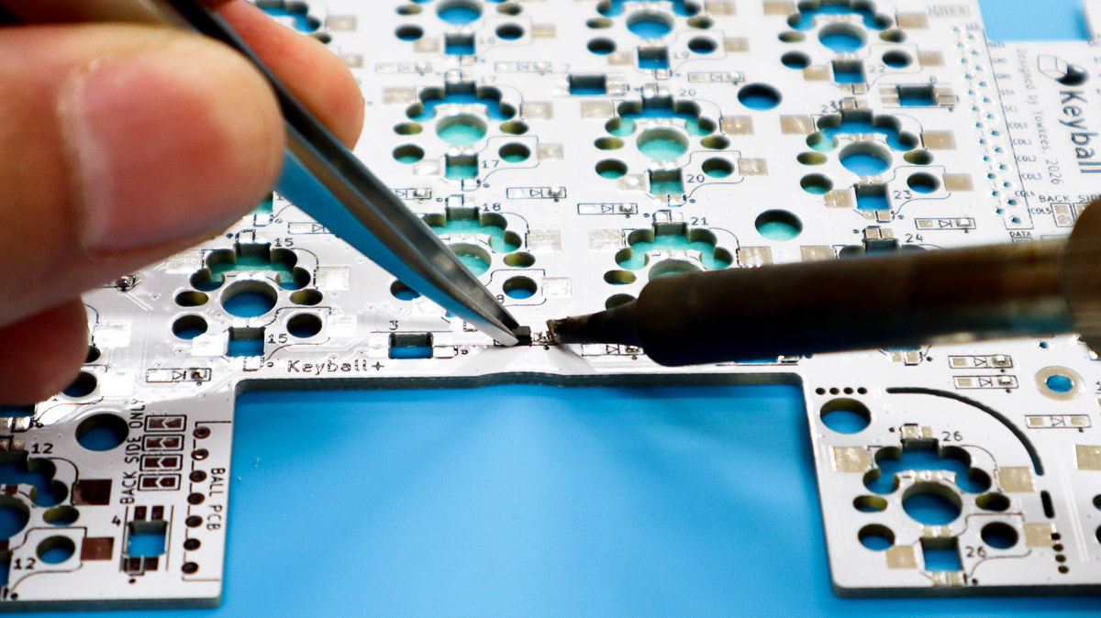
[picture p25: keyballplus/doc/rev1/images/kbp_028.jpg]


基板を180度回転させてダイオードの反対側の足にもはんだを流します。
最後に両方の足をこて先で触り、ダイオードが脱落しなければ両足ともはんだ付けされています。

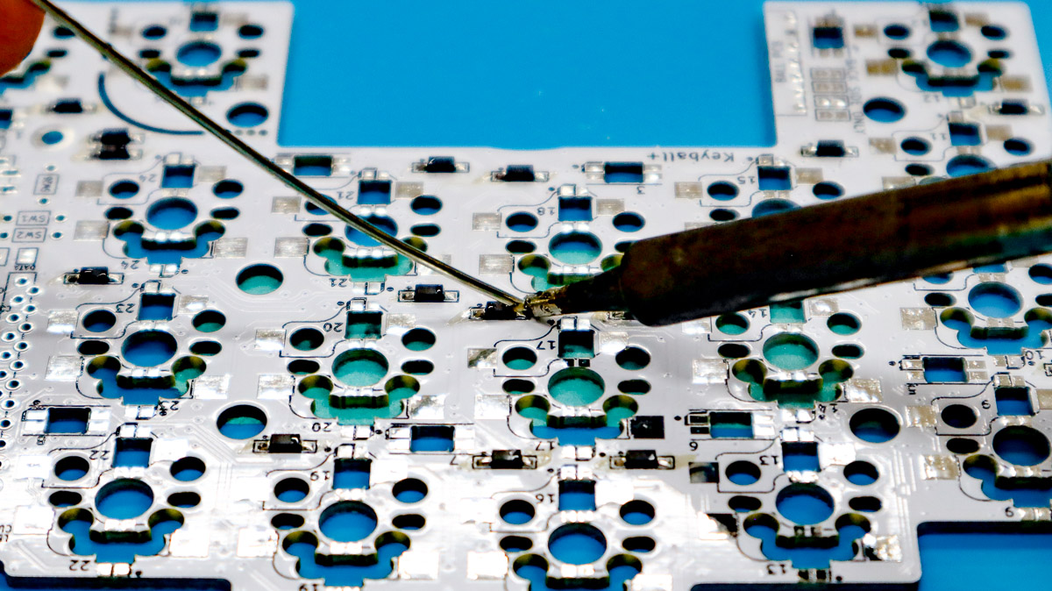
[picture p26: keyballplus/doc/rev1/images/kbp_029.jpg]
反対の足もはんだ付け


トラックボール側21個・トラックボール無し側24個、左右で合計45個のダイオードを取り付けます。

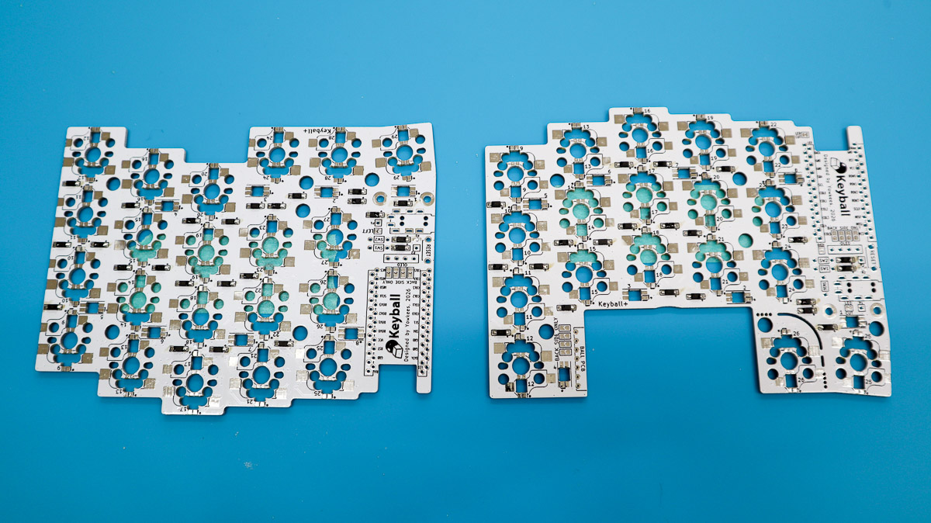
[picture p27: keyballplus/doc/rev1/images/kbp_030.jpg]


### 3-3. キーソケットのはんだ付け
キーソケットはダイオードと同様にすべて**裏面**にはんだ付けします。
Keyball+ には **MXスイッチ用ソケット** と **Chocスイッチ用ソケット** の両方が同梱されています。

下記の **3通り** のうちどれか1つを選んではんだ付けします（キーごとに選べます）。

**ビルドガイドではChoc＋LEDの組み合わせで進めていきます。**

| 組み合わせ | 使えるスイッチ | LED |
|:--|:--|:--:|
| **MXソケット ＋ Chocソケット** | MX / Choc の両方（スイッチを差し替えて使い分け可能） | 付けられない |
| **MXソケット ＋ LED** | MX のみ | 付けられる |
| **Chocソケット ＋ LED** | Choc のみ | 付けられる |

> MX と Choc を差し替えて両方使いたい場合はLEDなし、LEDを付けたい場合は MX か Choc のどちらか一方に固定、という選択になります。LEDのはんだ付けは [3-4章](#anchor3-4) で行います。

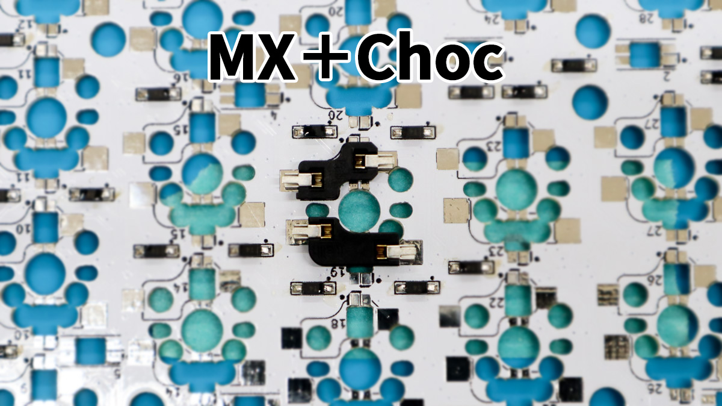
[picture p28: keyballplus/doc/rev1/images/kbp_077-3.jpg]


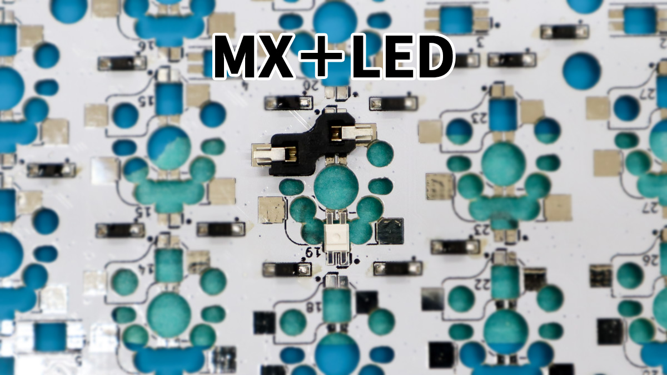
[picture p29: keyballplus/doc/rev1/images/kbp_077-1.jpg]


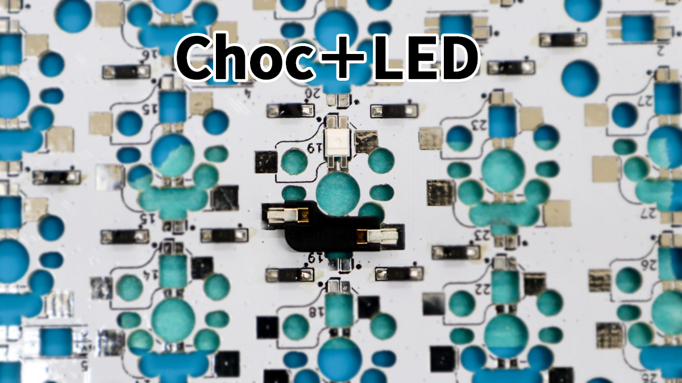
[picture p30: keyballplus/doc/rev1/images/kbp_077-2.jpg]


はんだ付けするソケットの数は、選んだ組み合わせによって変わります。MX と Choc の両方を付ける位置は1か所につき2個（MX用＋Choc用）、LEDを付ける位置は1個です。
右手親指キーを1つ切り離して38キーにする場合（[6章](#anchor6)）は、その位置のソケットは省略できます。
シルクマークと形状が合うようにセットしてはんだ付けします。

>**⚡️注意**:シルクからはみ出すようであれば方向が違います。
>正しい向きを下記写真で確認してください。

**MXスイッチ用ソケットの場合**

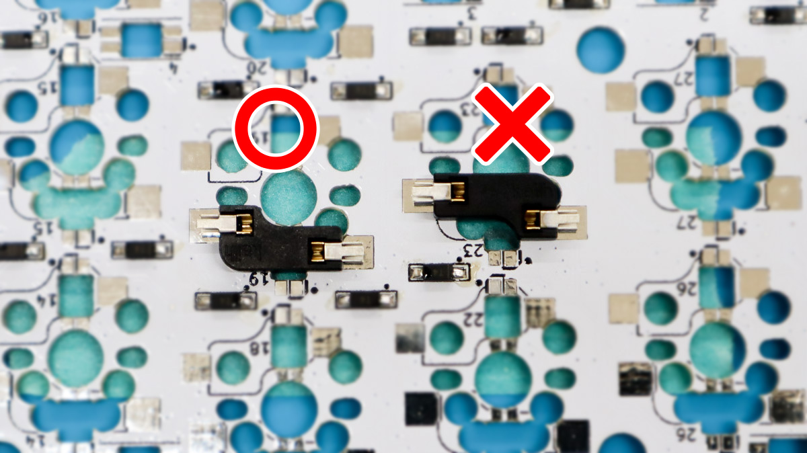
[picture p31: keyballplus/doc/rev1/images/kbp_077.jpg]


**Chocスイッチ用ソケットの場合**
Chocソケットにも向きがあります。下記写真のように黒い樹脂部分が八角形のような形の端子をスイッチの中心付近に配置します。

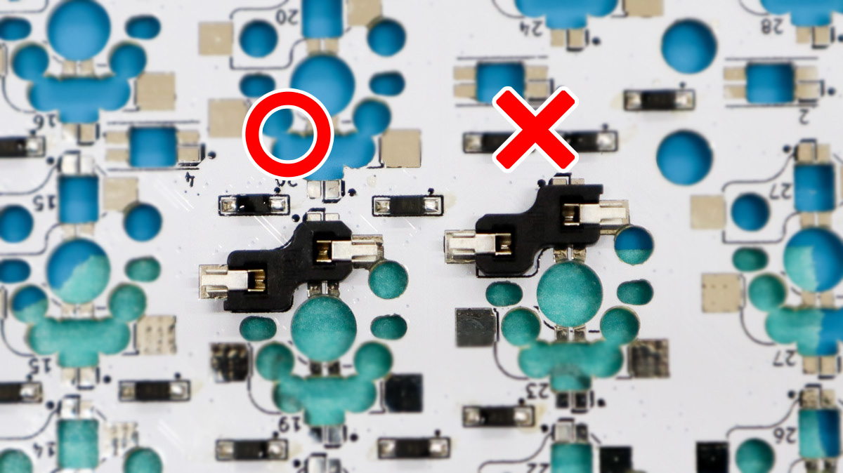
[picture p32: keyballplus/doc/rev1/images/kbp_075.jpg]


ソケットの両端のツメを写真のようにピンセットなどで折り曲げてからはんだ付けしてください。

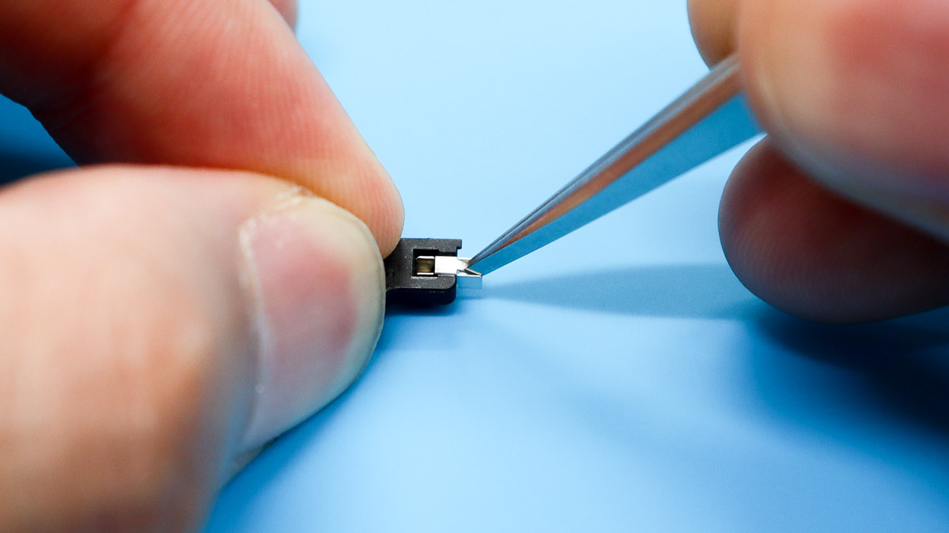
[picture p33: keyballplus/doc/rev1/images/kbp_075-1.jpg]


はんだ付けは青丸で示すように事前にソケット用パッドの片側にはんだを盛っておきます。

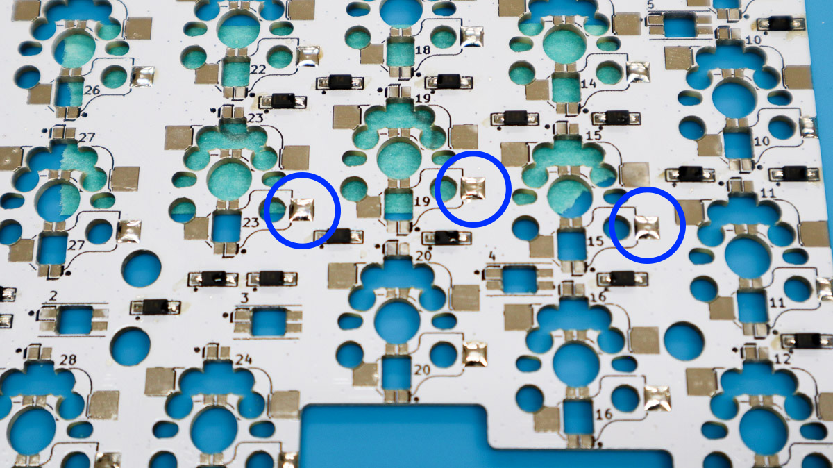
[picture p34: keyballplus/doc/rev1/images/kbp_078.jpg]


ソケットをはめて上からピンセットで抑えて端子の横からはんだを少し載せたこて先を当てると、はんだが溶けてソケットが沈み込みます。
経験上、この方法が一番テンプラ（接続不良）しにくいです。

Chocソケットをはんだ付けする場合はソケット位置がずれやすいので、位置を調整しながら取り付けてください。

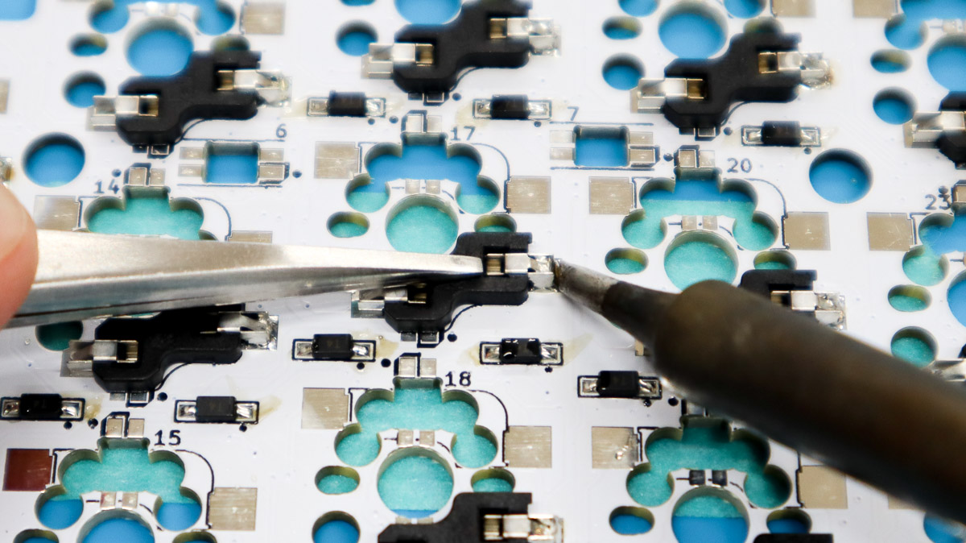
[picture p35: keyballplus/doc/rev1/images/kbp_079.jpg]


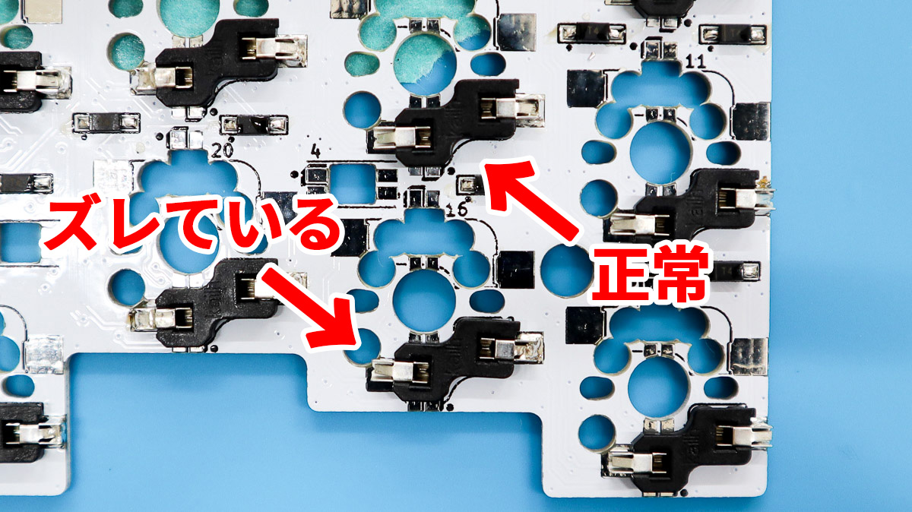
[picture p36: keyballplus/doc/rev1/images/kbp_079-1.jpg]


基板を180度回転させて反対側の端子もはんだ付けします。

39か所（右手親指キーを切り離した場合は38か所）すべてのキー位置に、選んだソケットをはんだ付けして完了です。

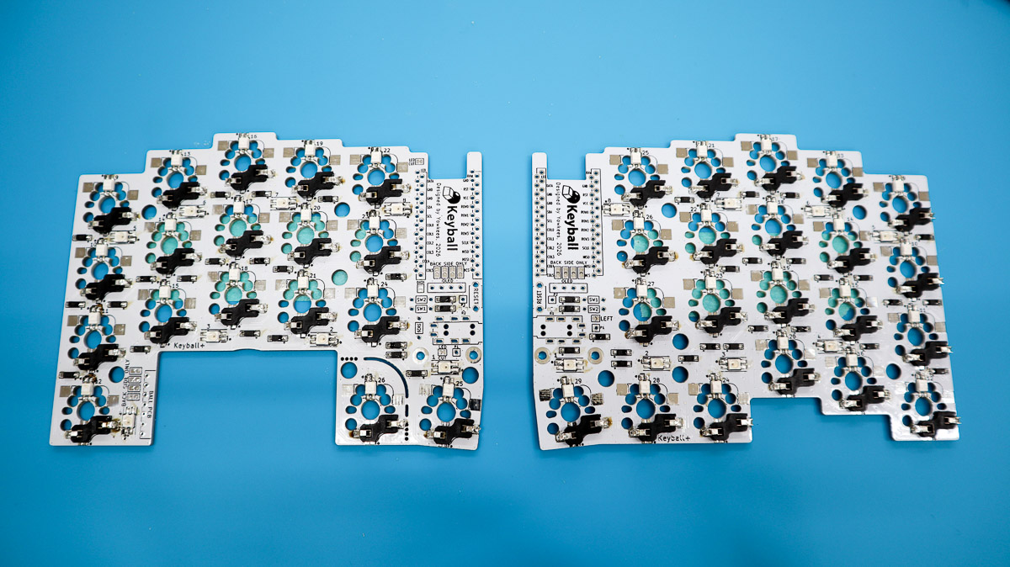
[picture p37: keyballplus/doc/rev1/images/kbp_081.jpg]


### 3-4. LED（オプション）のはんだ付け
LED（YS-SK6812MINI-E）はオプションになります。
Keyball+ は各キー裏＋アンダーグロー用として、**左手側29個・右手側26個（合計55個）** 取り付け可能です。左右で個数が異なる点にご注意ください（トラックボールを搭載する側が26個、搭載しない側が29個です）。
右手親指キーを切り離して38キーにした場合（[6章](#anchor6)）は、その位置の LED も無くなるため、トラックボール側が25個・合計54個になります。

>**⚡️注意**:LEDを付けられるのは、[3-3章](#anchor3-3) でキーソケットを **MX・Choc のどちらか一方だけ** にした位置です。MX と Choc の両方のソケットを付けた位置には、そのキー裏のLEDは付けられません（アンダーグロー用のLEDは影響を受けません）。
ただしLEDは非常に熱に弱いので、こて先温度を**220度～280度**に調整して行ってください。
こて先の温度が低いため、パッドに熱が伝わらずはんだがテンプラ（接続不良）しやすいです。
LED無しでもキーボードは使用できますし、すべてのLEDを点灯させるのは難易度が高いです。
まずはLEDなしで完成させることをおすすめします。後からでもLEDを追加できます。

LEDはすべて**裏面**にはんだ付けします。

YS-SK6812MINI-Eの4ピンのうち切り欠きがある足と、マーキングされているパッドを合わせてLEDを載せてはんだ付けします。

LEDには上向きと下向きに付けるものが混在しますが、下写真のようにピンの切り欠きとマーキングを合わせると自動的に上下が合います。

一度に4ピンすべてのはんだ付けをすると部品の温度が上がり壊れやすいので、2ピンづつを目安に時間を空けながらはんだ付けしてください。
そのために10個ほどのLEDを一度に載せて、一度はんだを当てたら次のLEDのはんだ付けに移るようにします。
こうすると1つのLEDに熱を加え続けることを防げます。

<!-- TODO: Keyball+ のLED配置写真に差し替え（左右非対称・合計55個） -->
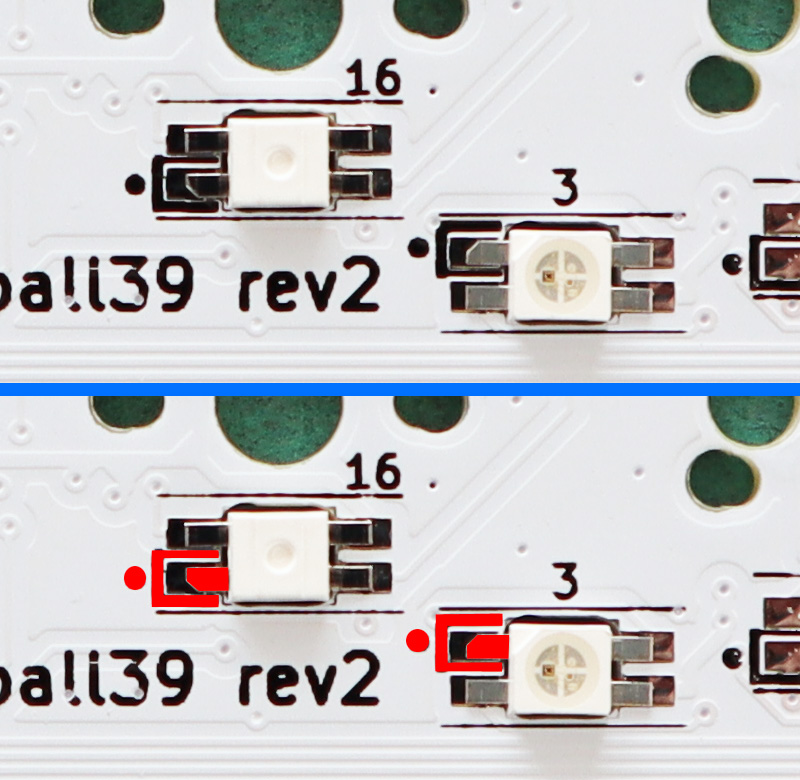
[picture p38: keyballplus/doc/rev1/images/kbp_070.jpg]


全てのLEDのはんだ付けが完了したら次の工程へ進めます。
LEDの点灯確認は、キースイッチを取り付けたあと [7-3章](#anchor7-3) で行います。

### 3-5. ジャンパのはんだ付け
OLEDモジュールを動作させるためにジャンパをショートさせる必要があります。

>**⚡️注意**:ジャンパのはんだ付けも**裏面のみ**に行います。
"Back Side Only"の表示があり、左右の基板に各【4個ずつ】あります。
パッドをこて先で温めてから、はんだを溶かすとブリッジできます。

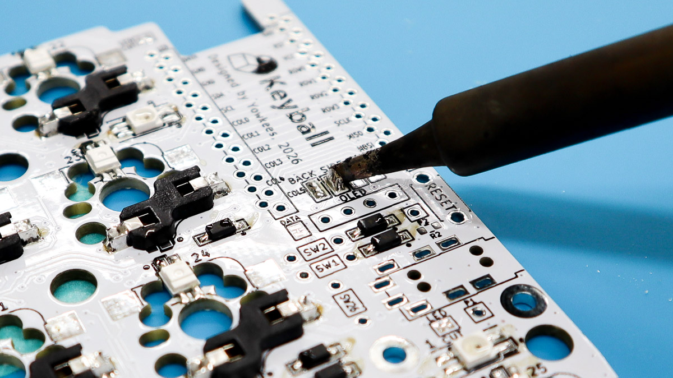
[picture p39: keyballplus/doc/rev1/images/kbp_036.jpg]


はんだ付けに自信が無い方やブリッジ作業が苦手な方は、下記写真のようにまずは8個のパッドにはんだを付ける事を行ってみてください。

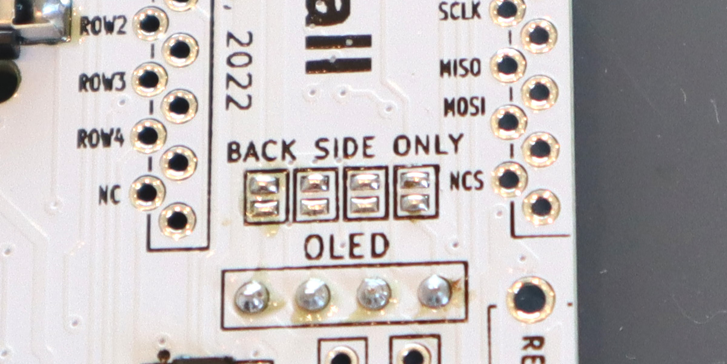
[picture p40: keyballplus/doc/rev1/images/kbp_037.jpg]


ここにはんだを追加することで、楽にブリッジさせられると思います。

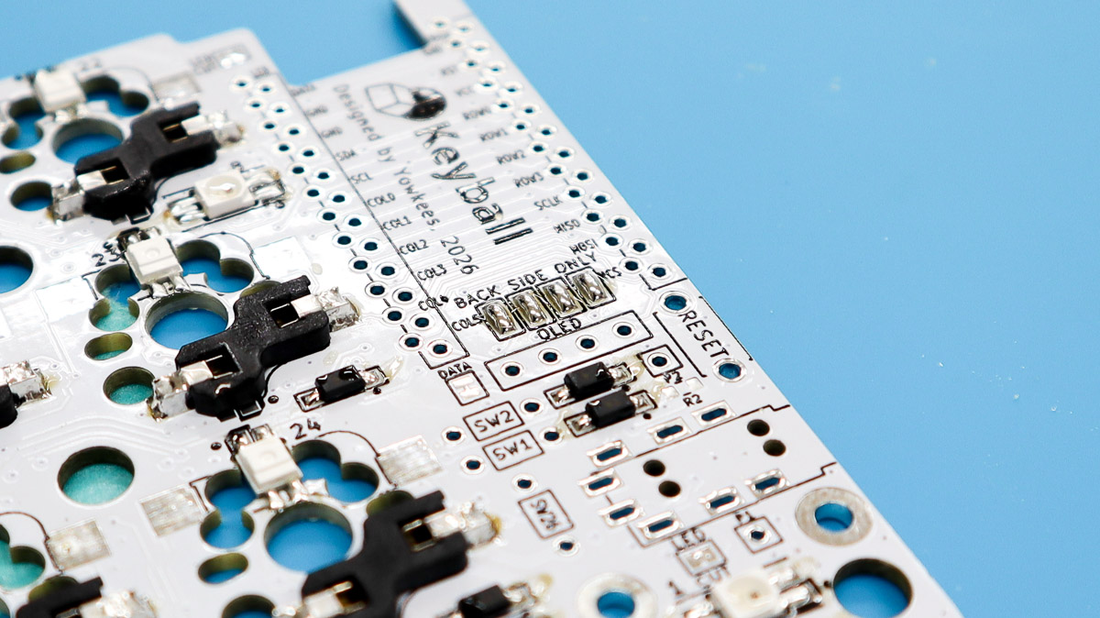
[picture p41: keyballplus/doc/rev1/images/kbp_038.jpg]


はんだの鮮度が落ちる（何度も温め直す）と表面張力が落ちてうまくブリッジできません。
一度はんだを払ってしまい、はんだやフラックスを足してやり直してください。
うまくブリッジできると下写真のようになります。
左右とも、計8か所をブリッジします。

この他にもジャンパがいくつかあると思いますが、これらは追って説明しますので、ひとまず左右4箇所ずつだけはんだ付けしてください。

### 3-6. TRRSソケット・タクトスイッチ・4連ピンソケット
下記写真の部品をはんだ付けします。
>**⚡️注意**:今度はすべて**表面のみ**に取付けますのでご注意ください。

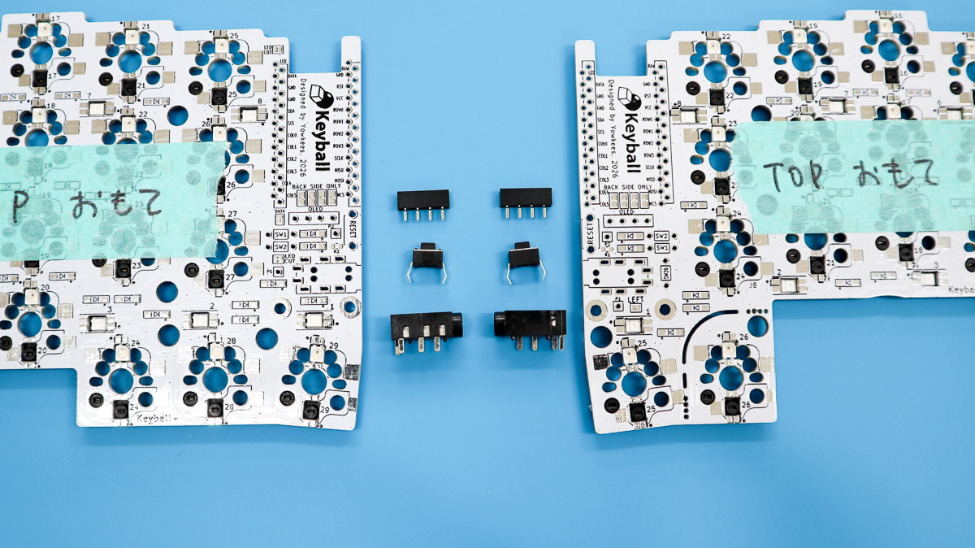
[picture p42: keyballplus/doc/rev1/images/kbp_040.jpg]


部品が浮いてしまうのが心配であれば、マスキングテープ等で固定してはんだ付けします。

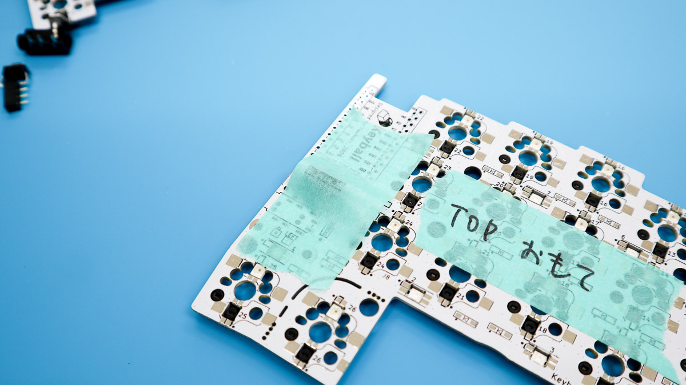
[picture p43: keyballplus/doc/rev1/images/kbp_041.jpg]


すべて取り付けると下写真のようになります。

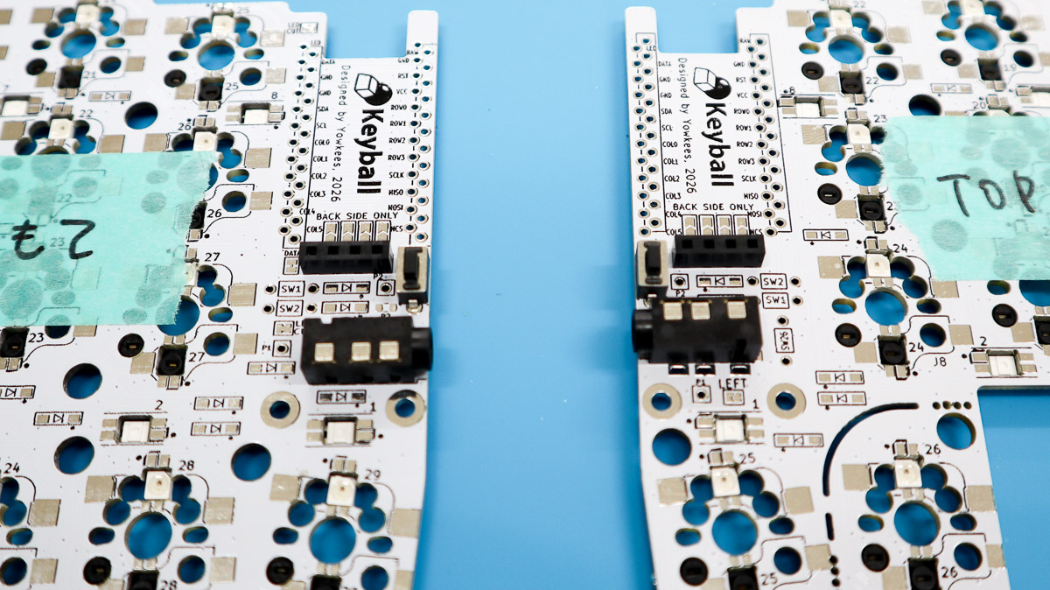
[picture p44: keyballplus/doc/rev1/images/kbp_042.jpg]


### 3-7. ProMicroのはんだ付け
ProMicroは下記写真のコンスルーピンを使用してはんだ付けすることで、ProMicroの故障時に交換が容易になります。
コンスルーピンには取付け方向がありますので写真をよく見て作業してください。

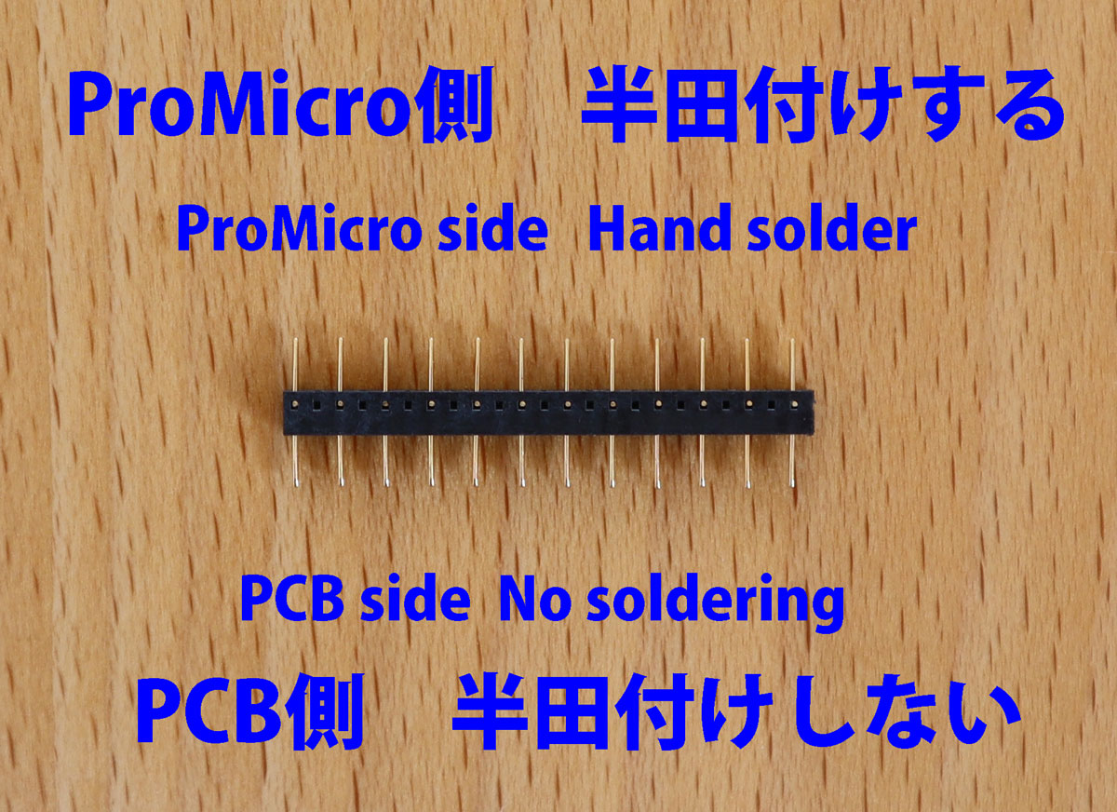
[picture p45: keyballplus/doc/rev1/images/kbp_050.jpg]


まずコンスルーピンを基板【表面】に軽く差し込みます。（しっかりと差し込まなくて大丈夫です）

**シルクの四角枠**に合うようにコンスルーを差し込んでください。
シルクの黒枠がコンスルーとずれているようであれば差し込む穴が間違っています。

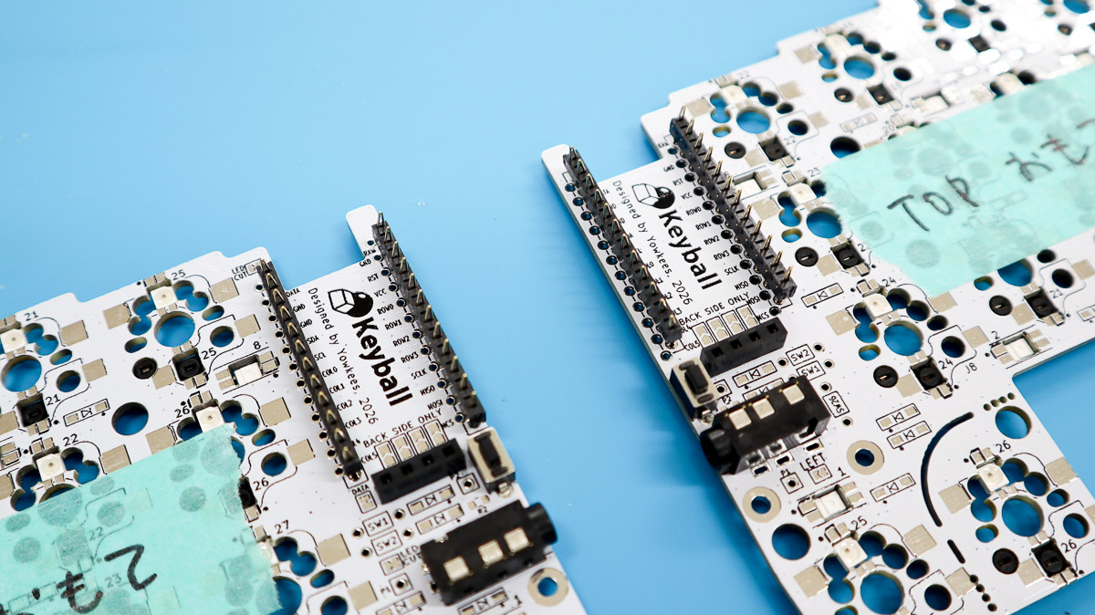
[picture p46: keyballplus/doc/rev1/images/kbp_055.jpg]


差し込んだコンスルーピンにProMicroを軽く乗せてProMicroを押し込むことでコンスルーピンもしっかりと差し込むことができます。

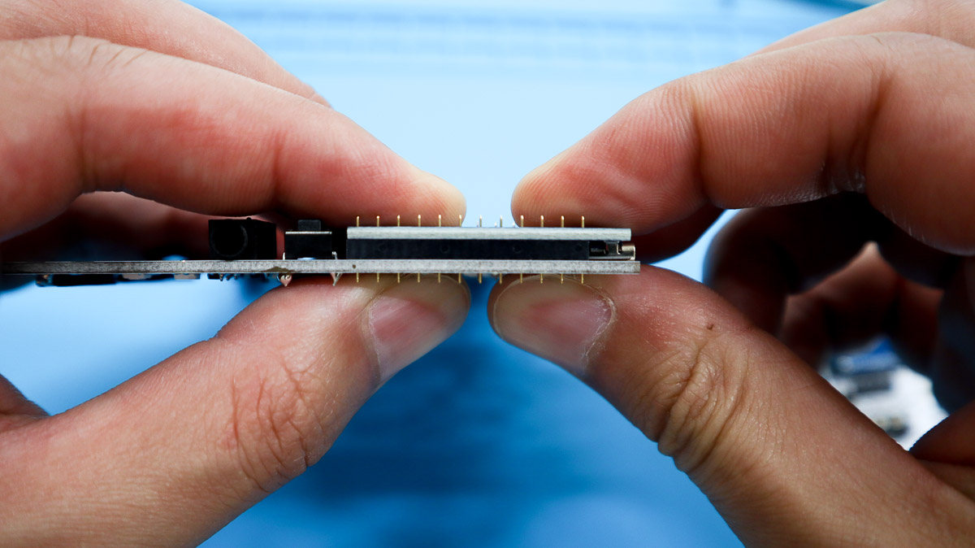
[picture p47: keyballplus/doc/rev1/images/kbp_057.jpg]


しっかり最後まで差し込んだ状態で**ProMicro側のみ**はんだ付けします。
基板に差し込んだ状態ではんだ付けすることで、コンスルーピンが斜めに取り付けられてしまうことを防げます。
>**⚡️注意**:コンスルーピンをミドルPCB側にもはんだ付けしてしまうとProMicro故障時に取り替えが非常に困難になります。

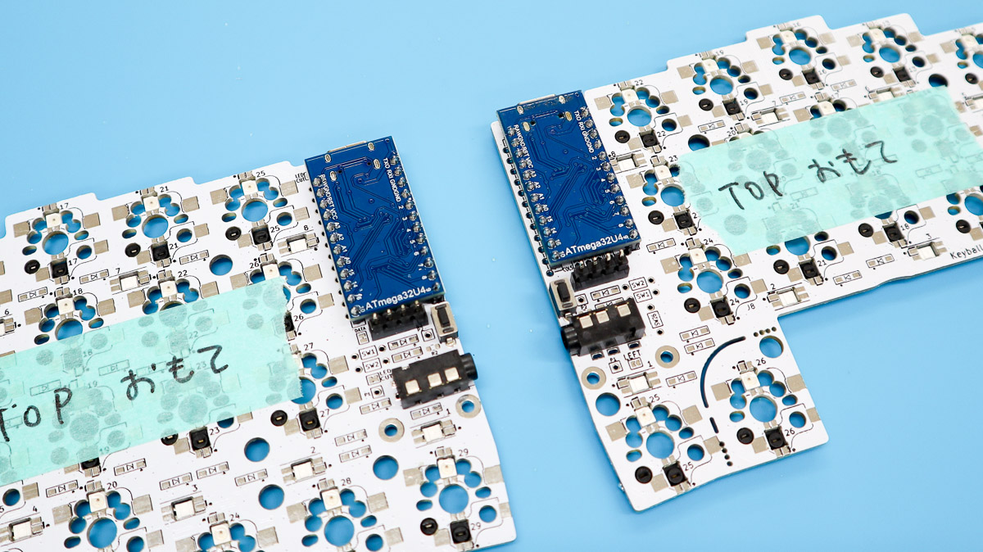
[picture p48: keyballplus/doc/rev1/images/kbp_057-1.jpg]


左右の基板には標準でOLEDが搭載できます。
4連ピンソケットに4連ピンヘッダを挿入してOLEDモジュールを載せます。
そして、4ピンのうちの**1つだけ**をはんだ付けします。

1つだけはんだ付けしたピンのはんだを溶かしながらOLEDモジュールを上から押して浮かないようにします。
またProMicroと並行になるように調整すると見栄えが良くなります。

位置が決まったら残り3ピンをはんだ付けします。

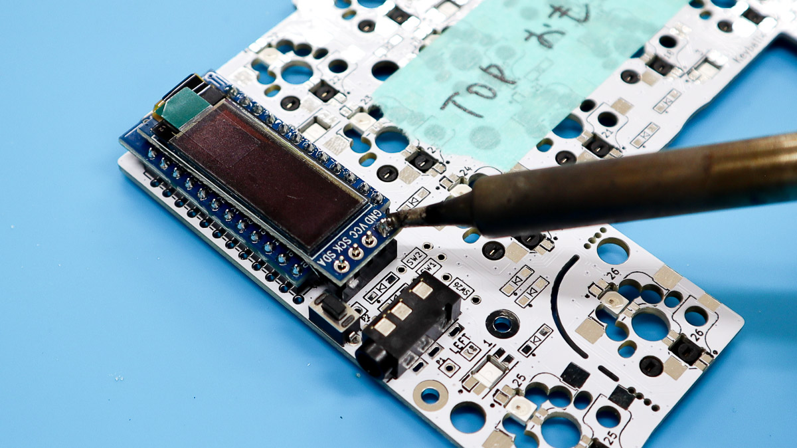
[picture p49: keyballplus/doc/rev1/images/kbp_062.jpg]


メイン基板側のはんだ付けはこれで完了です（このあと [4章](#anchor4) でトラックボール読み取り基板、[5章](#anchor5) で左右判定ジャンパのはんだ付けがあります）。
ファームウェアの書き込みとキー入力・LEDの動作確認は、キースイッチを取り付けたあと [7-3章](#anchor7-3) で行います。

## 4. トラックボール読み取り基板の組み立て
下写真の基板（以下、ボール基板）と光学センサーを準備します。

※センサーや基板の品質確認のため、はんだ付け済のボール基板が届く場合があります。
その際はこの工程を飛ばして、[4-2章](#anchor4-2)のL字コンスルーはんだ付けに進んでください。

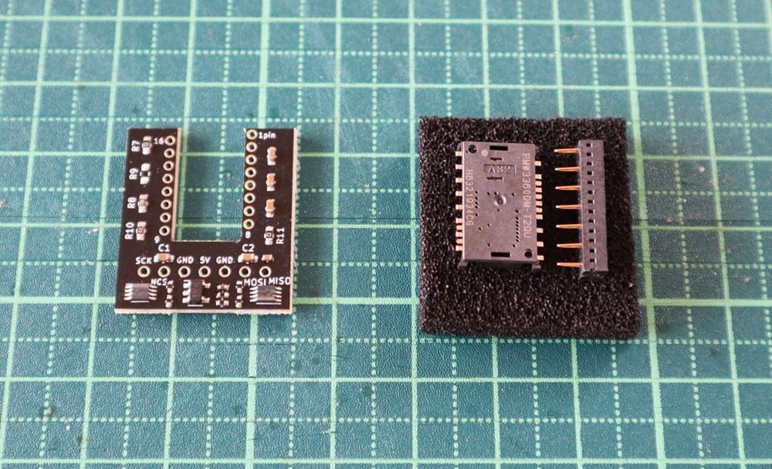
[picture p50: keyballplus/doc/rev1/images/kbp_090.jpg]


### 4-1. センサーのはんだ付け

センサーICはボール基板の部品が実装されていない裏面から差し込みます。
>**⚡️注意**:センサーの極性を間違えると、修理がとても大変です！
正しい向きで、正しい方向から挿入しているかしっかりと確認してからはんだ付けしてください！
ICの１ピンを示すくぼみと基板の【1pin】のシルクを合わせます。

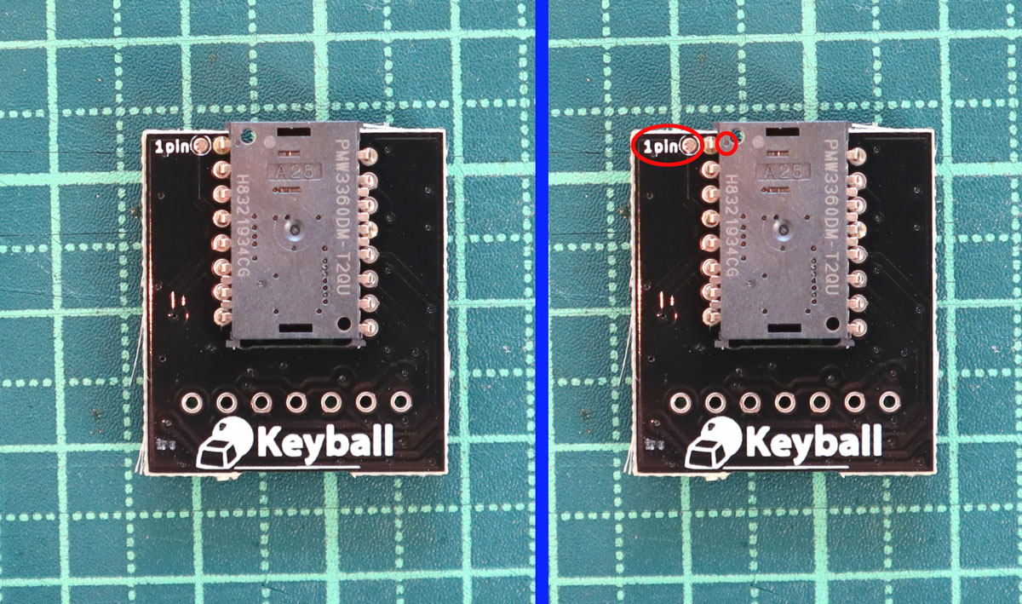
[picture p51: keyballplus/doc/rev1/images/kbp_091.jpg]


ICを裏から見るとこのような方向です。
表面実装部品が実装されている表面側（Keyballロゴの無い面側）から全ピンをはんだ付けしてください。

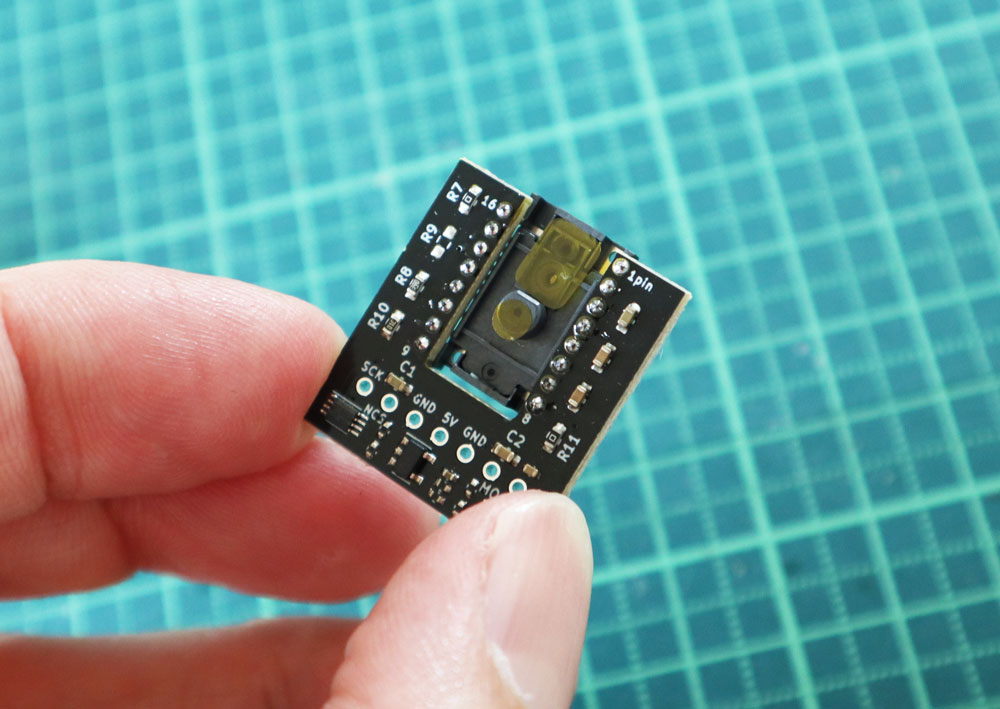
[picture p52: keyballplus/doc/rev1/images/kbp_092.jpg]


ピンセットを使って保護シール【２枚】をはがします。

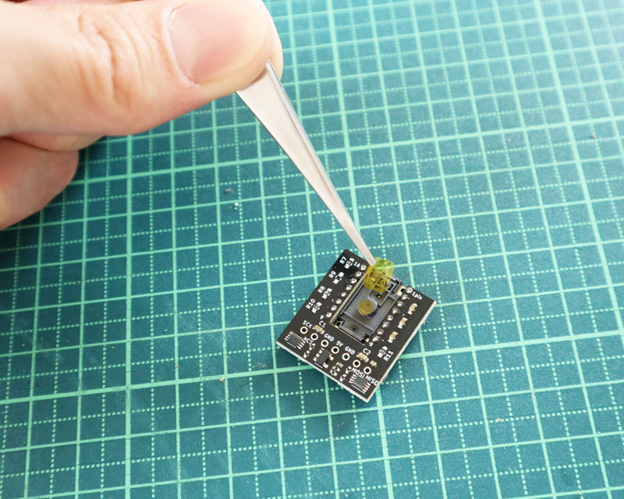
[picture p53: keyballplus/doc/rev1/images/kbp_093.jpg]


保護シールをはがした面側にセンサーレンズを取り付けます。
レンズには方向があり、方向が違うとレンズの細いピン2本が折れてしまう恐れがあるため方向をしっかりとご確認ください。
レンズ手前に下記写真の矢印のような突起があり、これが上側にくるように取り付けます。

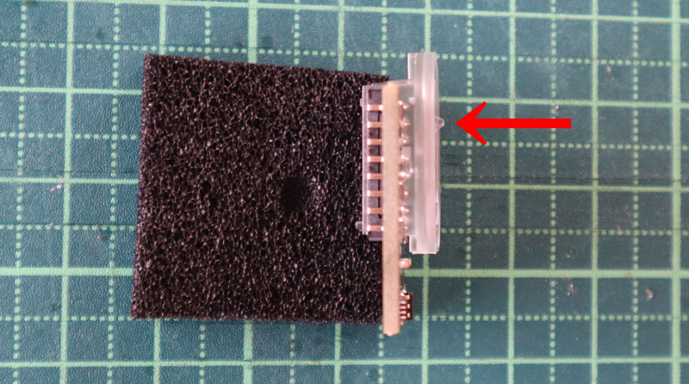
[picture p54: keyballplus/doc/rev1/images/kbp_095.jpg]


レンズとICの方向が合えば、レンズのピン2本がICに無理なく差し込めるはずです。ゆっくりと差し込んでください。



### 4-2. L字コンスルーのはんだ付け
次にL字コンスルーピンをトラックボールを搭載する基板の**表面**に取付けます。
L字コンスルーにも方向があります。
ピンがU字型になっていない方をミドル基板に差し込んではんだ付けします。



部品が浮かないようにマスキングテープ等を貼って裏面からはんだ付けしてください。



次に光学センサー用信号線のジャンパ４個をはんだ付けします。
>**⚡️注意**:はんだ付けしたコンスルーの近くにジャンパがありますので、これを**裏面のみ**はんだを盛って下記写真のようにショートさせてください。



## 5. 左手側の左右判定ジャンパーをはんだ付け

>**⚡️注意**:Keyball+ の標準ファームウェアにはキーボードの左右を自動で判定する機能があります。
判定のために**左手側の基板だけ**に１個所ジャンパーをはんだ付けします。

左手側基板を裏から見ると下記写真赤丸部に**LEFT**というシルクがあります。
この隣のジャンパをはんだ付けしてショートさせてください。



左手側にトラックボールを載せる場合は位置が少し異なり、LEFTジャンパは下写真の位置になります。

>**⚡️注意**:必ず**左手側の基板だけ**にジャンパーします。



以上ではんだ付け作業は完了です。

余談ですがはんだごての電気を落とす前に、こて先にたっっぷりとはんだを付けておきましょう。次回使用するときにこのはんだを落とせば、ピカピカのこて先で作業を再開できますよ！



## 6. トッププレートのカット（オプション）

トッププレートには、必要な場合のみ切り離せる部分がミシン目で用意されています。
MXスイッチとChocスイッチを組み合わせて使用する場合はミシン目で切り離してください。
切り離す場合は、カッターで表面と裏面のミシン目に切り込みを入れてから折って切り離し、断面を150番手くらいの紙やすりで整えます。

### ① 右手親指キーを1つ減らす（38キーにする）

<!-- TODO: 右手親指キーの切り離し位置がわかる Keyball+ の写真を追加 -->
トラックボール側の親指キーのうち、**トラックボールに最も近い1キー**を切り離せます。
トラックボール操作時に親指がこのキーに当たってしまう方向けのオプションです。
切り離すと総キー数は **38キー** になります。この位置は LED も一緒に切り離されるため、LED を実装する場合はトラックボール側が1個減り **合計54個** になります。
この場合、別途用意するキースイッチとキーキャップは **38個** で足ります。切り離した位置のキーソケットは、はんだ付けしても使用しないため省略してかまいません。

### ② 親指部分だけ Choc、その他は MX にする

親指部分を Choc スイッチ、それ以外を MX スイッチにする組み方ができます（逆の組み合わせもできますが実用的なスイッチの混在はこの組み合わせのみです）。
この場合、親指部分（Choc＝4mm スペーサ）とそれ以外（MX＝7mm スペーサ）でトッププレートの高さが変わるため、親指部分をミシン目で切り離します。
**すべて MX、またはすべて Choc で組む場合は、このカットは不要です。**

この組み方ではすべてのキー位置でスイッチ種が固定されるため、**親指を「Choc＋LED」、その他を「MX＋LED」** にすれば全キー位置にキー裏LEDを付けられます（合計55個。[3-3章](#anchor3-3) の組み合わせを参照）。



切り離した断面は150番手くらいの紙やすりで整えてください。



## 7. 組み立て

### 7-1. 保護プレートの取り付け

ミドル基板にProMicro保護プレートを取り付けます。

まず 9mm スペーサをネジ止めしてからアクリル保護プレートをスペーサにネジ止めします。

トラックボール有側も無側も保護プレートの形状は共通です。表裏もありません。



### 7-2. トッププレートの組み立て

トッププレートの**裏面**にスペーサをネジ止めします。
MX スイッチで組む場合は **7mm** スペーサ、ロープロファイル（Choc）スイッチで組む場合は **4mm** スペーサを使用します（左右で計12本）。



まずトッププレートの四隅にキースイッチをはめ込みます。こうしておくとプレート同士の位置決め精度が上がります。

MXスイッチを取り付ける場合はトッププレートとミドルアクリルプレートのネジ穴を合わせ、プレート同士を重ねます。



次にはんだ付けしたミドル基板もネジ穴を合わせ、キースイッチの端子がしっかりキーソケットに入ることを確認しながら重ねます。



プレートを重ねたら、**残りのキースイッチをすべて取り付けます**（38キー仕様なら38個）。スイッチの端子が曲がっていないか確認しながらトッププレート側から垂直に押し込み、ミドル基板裏側のソケットから端子が2本とも出ていることを確認してください。この後の [7-3章](#anchor7-3) でキー入力を確認するため、この段階で全キー分のスイッチが必要です。

### 7-3. ファームウェアの書き込みと動作確認

キースイッチを取り付けたこの段階で、ファームウェアを書き込み、キー入力とLEDの動作を確認します。
**ボトムプレートを取り付けると ProMicro・LED・基板裏面に手が届かなくなるため、この段階で確認してください。**

Keyball+ には Keyball39 のようなテスト専用ファームウェアはありません。[Keyball Link](https://keyball-link.shiroganelab.com/) から製品版ファームウェアを書き込みます。
ファームウェアには **通常版** と **LED版** の2種類があり、**LEDを実装した場合は「LED版」、実装していない場合は「通常版」** を選びます（「通常版」はLEDが点灯しない代わりに、より多くの機能が使えます）。
Keyball+ のファームウェアは、トラックボールを左右どちら側に載せた場合でも共通です。

Keyball Link を開き、Keyball+ をUSBケーブルでPCに接続してから、画面の案内にしたがってファームウェアを書き込み（FLASH）してください。
USBケーブルを接続しているのにキーボードが認識されない場合は、はんだ付けしたRESETスイッチを素早く2回押すと認識されると思います。
※必ず左右両方の Pro Micro に同じ版のファームウェアを書き込んでください。

書き込みが完了したら、テキストエディタなどを開いて **すべてのキーを1つずつ押し、正しく入力されるか** を確認します。
左右が反転している場合は [5章](#anchor5) の左右判定ジャンパを見直してください。反応しないキーがあれば、そのキーのソケットとダイオードのはんだ付けをやり直します。



LEDを実装した場合は点灯確認も行います。
LEDは直列に配線されているので、途中までしか光らない場合の不具合箇所の特定がしやすいです。
例えば12番のLEDまでは点灯したが13番以降が点灯しない場合、【12番か13番】のLEDのはんだ付けに問題がある可能性が高いので、それらをやり直してください。改善しない場合は13番のLEDを交換します。
点灯確認とはんだ付け修正を繰り返して、すべてのLEDが点灯するようにします。

Keyball+ のファームウェアを直接編集してご自身でビルドしたい場合は、[keyball-plus-firmware リポジトリ](https://github.com/ineno771/keyball-plus-firmware) をご活用ください（詳しくは [10章](#anchor10)）。

### 7-4. ボトムプレートの組み立て

動作確認が終わったら、アクリルボトムプレートの保護シートを剥がし、本体裏面に重ねてネジ止めします。
次にキーボード裏の四隅にクッションゴムを張り付けてください。

## 8. トラックボール取り付け

### 8-1. ボール読み取り基板差し込み

組み立てたトラックボール読み取り基板を７ピンコンスルーへ差し込みます。
基板は垂直にして差し込みます。



### 8-2. トラックボールケースの組み立て

トラックボールケースには事前にセラミックボール3個が固定されています。
万が一セラミックボールが脱落している場合にはお手数ですが予備のセラミックボールを適当なボンドで固定してください。
セラミックボールの予備は今後ボールを紛失した時のために保管しておいてください。

ケースを振ってみて、セラミックボールが脱落しないか確認してください。



ケース下の穴へ、ケース上のピン２本が挿入できます。
上下からゆっくり力を入れて結合します。（ぴったりと結合しなくてもこの後のネジ絞めでくっつきますので大丈夫です。）



M1.7のタッピングネジを付けます。
キットには**頭の小さなネジ**と**頭の平らなネジ**が同梱されていますが、**頭の小さなネジ**を使用します。



ケース裏から見て、この２個所をネジ止めします。
>**⚡️注意**:締め付けすぎにご注意ください。



### 8-3. トラックボールケース装着

完成したケースを本体に取付けます。
ケース裏側のセンサー収納部にボール基板が入ります。
矢印で示すボール基板がケース中央くらいにくるようにしながら、上からゆっくりとはめます。
引っ掛かりがある場合は無理に押し込まず、一度引き抜いて再度入れ直してください。

それほど力を入れなくても最後まで入るはずです。



本体裏から確認するとメイン基板とボール基板の間に、矢印で示すような隙間が出来ている場合があります。



その時は、軽～くケース手前（指マークの方向）から押します。
力を入れすぎるとL字コンスルーが破損する可能性があるので、やさしく押してください。
下写真のように隙間がなくなれば、青丸部のネジ穴が合うと思います。



キットに同梱のM1.7トルクスネジの**頭が平らなネジ**２本を本体裏から絞めます。
この時ボール保持ケースが回転しないように指で抑えながらネジを絞めてください。

## 9. 総仕上げ

完成間近です！最後に34mmトラックボールとキーキャップを取り付けて完成です！
お疲れ様でした。



<!-- TODO: Keyball+ の完成写真に差し替え -->
keyball+完成品

## 10. キーマップの変更・ファームウェアの更新

ファームウェアの書き込みは [7-3章](#anchor7-3) で完了しています。この章は、あとからキーマップを変更したり、ファームウェアを新しい版に入れ直したりするときの参考です。

Keyball+ のキーマップは、Keyball専用のWebツール **[Keyball Link](https://keyball-link.shiroganelab.com/)** からブラウザで変更・書き込みできます。特別なソフトのインストールは不要です。

ファームウェアを入れ直す場合は **通常版** と **LED版** に注意してください。
**LEDをはんだ付けした場合は「LED版」、はんだ付けしていない場合は「通常版」** を選びます（LEDを載せていないのにLED版を書き込むと、使わないLED制御に容量が取られ、通常版で使える一部の機能が省かれます）。

>**⚡️注意**:必ず左右両方のPro Microに同じ版のファームウェアを書き込んでください。キーマップはUSBケーブルを差した側のProMicroへ書き込まれます。

**ご自身でファームウェアをビルドする場合**
Keyball+ の最新ファームウェアは [keyballplus-firmware リポジトリ](https://github.com/Yowkees/keyball/tree/main/qmk_firmware/keyboards/keyball/keyballplus) にて公開しています。
リポジトリ内の `keyboards/keyball` フォルダをお手持ちの QMK Firmware の `keyboards` へコピーして、自由にキーマップ等を編集してビルドしてください。

## 11. Keyball+の使い方♪
   - トラックボールはスクロールレイヤーに切り替わっている間は上下左右スクロールに変わります。

   - [Keyball Link](https://keyball-link.shiroganelab.com/) で簡単にキーマップの確認・変更・書込みが可能です。

   - USBケーブルは左右どちらに差しても使用できます。
   ただしキーマップはUSBケーブルを差した側のProMicroへ書き込まれるため、初めて差し替えた場合はキーマップを見直してください。

   - Keyballシリーズ用に特別に用意されたキーコードが用意されています。
   トラックボールをスクロールに変化させたり、カーソル速度やスクロール速度変更に使用できます。

   >**⚡️注意**:KeyballとPCを接続した状態（電源が入った状態）でTRSケーブルを抜くと故障の原因となります。
   TRSケーブルを抜き挿しする際は必ず先にUSBケーブルを抜いてから行ってください。

以上で Keyball+ のビルドガイドは終了です。
Keyball+ についてのご質問や不具合等については [Yowkees/keyball の Discussions](https://github.com/Yowkees/keyball/discussions) へご投稿ください。
なるべく早くご回答させていただきます。

―謝辞―
Keyball+ のファームウェアは、Keyball39 のファームウェアをベースにしています。Keyball39 のファームウェアは [KoRoN@香り屋様](https://www.kaoriya.net/) の多大なるご協力のおかげでトラックボールの動作が大幅にスムーズになったことに加え、メモリ容量の大幅な削減によりとてもたくさんのLEDアクションが楽しめます。この場を借りて深くお礼させていただきます。本当にありがとうございました。
　@Yowkees

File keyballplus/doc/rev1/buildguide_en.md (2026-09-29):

<!--
  This build guide is a DRAFT written by adapting the Keyball39 build guide
  (keyball39/doc/rev1/buildguide_en.md) for Keyball+.
  - The kit contents list (chapter 1) reflects the Keyball+ instruction sheet.
  - The images under images/ are provisional copies of Keyball39's photos.
    Replace them in place (same file names) with Keyball+ photos once available.
  - The remaining "TODO" comments are all placeholders waiting for real Keyball+ photos.
-->

# Build Guide for Keyball+

This guide provides detailed instructions for assembling the Keyball+.

Keyball+ is a split keyboard kit with a thumb trackball (39 keys). Based on Keyball39, it supports
**both** MX switches and low-profile (Kailh Choc) switches; the kit includes PCB sockets and spacers
for each. You can build it with either type (or mix them per key). The key count and key layout are
identical to Keyball39, and most of the assembly procedure is shared with Keyball39.
You can also separate one right-hand thumb key and build it as a **38-key** board (see [Chapter 6](#anchor6)).

**日本語版のKeyball+ビルドガイドは[こちら](buildguide_jp.md)です。**

<!-- TODO: replace with a photo of Keyball+ -->


## 【Table of Contents】

> **Preparation**
 - [1. Parts Check](#anchor1)
   - [1-1. Kit Contents](#anchor1-1)
   - [1-2. Parts You Need to Prepare Yourself Before Assembly](#anchor1-2)
   - [1-3. Parts and Options That Can Be Installed After Assembly](#anchor1-3)
 - [2. Preparation](#anchor2)
   - [2-1. Required Tools](#anchor2-1)
   - [2-2. Firmware](#anchor2-2)

> **Implementation**
 - [3. Implementation](#anchor3)
   - [3-1. Before Soldering](#anchor3-1)
   - [3-2. Installing Diodes](#anchor3-2)
   - [3-3. Soldering Key Sockets](#anchor3-3)
   - [3-4. Soldering LEDs (Optional)](#anchor3-4)
   - [3-5. Soldering Jumpers](#anchor3-5)
   - [3-6. TRRS Socket, Tactile Switch, and 4-pin Socket](#anchor3-6)
   - [3-7. Soldering ProMicro](#anchor3-7)
 - [4. Assembling the Trackball Reading Board](#anchor4)
   - [4-1. Soldering the Sensor](#anchor4-1)
   - [4-2. Soldering the L-shaped Connector](#anchor4-2)
 - [5. Soldering the Left-Right Detection Jumper on the Left Side](#anchor5)
 - [6. Cutting the Top Plate (Optional)](#anchor6)

> **Assembly**
 - [7. Assembly](#anchor7)
   - [7-1. Installing the Protection Plate](#anchor7-1)
   - [7-2. Assembling the Top Plate](#anchor7-2)
   - [7-3. Writing the Firmware and Checking Operation](#anchor7-3)
   - [7-4. Assembling the Bottom Plate](#anchor7-4)
 - [8. Installing the Trackball](#anchor8)
   - [8-1. Inserting the Ball Reading Board](#anchor8-1)
   - [8-2. Assembling the Trackball Case](#anchor8-2)
   - [8-3. Installing the Trackball Case](#anchor8-3)

> **Finishing**
 - [9. Final Assembly](#anchor9)
 - [10. Changing the Keymap / Updating the Firmware](#anchor10)
 - [11. How to Use Keyball+♪](#anchor11)

## 1. Parts Check

Please check that all kit contents are included when your kit arrives.

### 1-1. Kit Contents

The standard set can accommodate one thumb trackball on either the left or right side.

<!-- Single-hand kits are also available for dual-ball specifications with trackballs on both sides, or for assembly without trackballs on either side. -->

<!-- If you purchased a single-hand set or dual-ball set, please check the included parts list in your kit for the contents. -->

**Keyball+ Kit Contents**
| Part Name | Quantity | Notes |
|:---|:----:|:-----|
| Middle PCB (Left/Right) | 1 set | Main board |
| Top PCB (Left/Right) | 1 set | For key switch mounting |
| Middle Acrylic Plate (Left/Right) | 1 set | Includes the thumb section |
| Bottom Acrylic Plate (Left/Right) | 1 set | Bottom cover |
| ProMicro Protection Plate | 2 pieces | For board protection |
| 34mm Trackball Holding Case (Top/Bottom) | 1 set | For ball mounting |
| Trackball Reading Board | 1 piece | Sensor board |
| L-shaped Connector Pin (7-pin) | 1 piece | For sensor connection |
| Trackball Reading IC + Lens | 1 set | PMW3360 + optical lens |
| Flat Head Screw M1.7 | 2 pieces | For trackball case mounting |
| Small Head Screw M1.7 | 2 pieces | For trackball case assembly |
| TRRS Jack | 2 pieces | For TRRS cable connection |
| Tactile Switch | 2 pieces | For ProMicro reset |
| Connector Pin (12-pin) | 4 pieces | For ProMicro connection |
| Diode (chip type) | 48 pieces | For key matrix error prevention (21 mounted on the trackball side + 24 on the non-trackball side = 45; the rest are spares) |
| OLED Module | 2 pieces | Display |
| OLED Pin Socket + Pin Header | 2 sets | For OLED connection |
| PCB Socket for MX switches | 40 pieces | Use when building with MX switches (39 mounted + 1 spare) |
| PCB Socket for Choc switches | 40 pieces | Use when building with low-profile switches (39 mounted + 1 spare) |
| Spacer M2 9mm | 4 pieces | For the ProMicro protection plate |
| Spacer M2 7mm | 12 pieces | For the top plate in the MX build |
| Spacer M2 4mm | 12 pieces | For the top plate in the low-profile build |
| Screw M2 3.5mm | 32 pieces | For plate mounting |
| Cushion Rubber | 8 pieces | For bottom anti-slip |

> You only use one of the two socket types (MX or Choc); they can also be mixed per key. Likewise, use the 7mm spacers for an MX build and the 4mm spacers for a low-profile build.

<!-- TODO: replace with a photo of the Keyball+ kit contents -->


### 1-2. Parts You Need to Prepare Yourself Before Assembly

The following parts are not included in the kit and need to be purchased separately.

| Part Name | Quantity | Notes |
|:---|:----:|:-----|
| ProMicro | 2 pieces | You can choose inexpensive ones or USB Type-C compatible ones |
| Key Switches | 39 pieces | MX compatible or low-profile (Kailh Choc). See [Chapter 3-3](#anchor3-3) for how MX/Choc are used. 38 pieces if you separate one right-hand thumb key ([Chapter 6](#anchor6)) |
| Keycaps | 39 pieces | 1u. Match the switch type you use (MX / Choc). 38 pieces if you separate the right-hand thumb key |
| 34mm Diameter Trackball | 1 piece | Required when using trackball |
| TRS Cable | 1 piece | For left/right connection. TRRS (4-pole) cable is also acceptable |
| USB Cable | 1 piece | For connecting to a PC. Compatible with the ProMicro you purchased |

<!-- TODO: replace with a photo for Keyball+ -->


### 1-3. Parts and Options That Can Be Installed After Assembly

The following parts are optional and can be installed even after assembly.

| Part Name | Quantity | Notes |
|:---|:----:|:-----|
| Full-color LED (YS-SK6812MINI-E) | 55 pieces | Under each key + underglow. 29 on the left / 26 on the right. 54 pieces if you separate the right-hand thumb key ([Chapter 6](#anchor6)) ※SK6812MINI cannot be used |

<!-- TODO: replace with a photo for Keyball+ -->


## 2. Preparation

### 2-1. Required Tools

The following tools are required for assembling Keyball+. Please check that you have all of them.

| Tool Name | Purpose |
|:---|:-----|
| Soldering Iron (Temperature adjustable if implementing LEDs) | Soldering work |
| Solder (Low melting point is effective if implementing LEDs) | For connections |
| #0 + Precision Driver | For screw tightening |
| Tweezers | For handling parts |
| 150 grit sandpaper | For polishing when cutting plates |



### 2-2. Firmware

To operate Keyball+, firmware needs to be written to the ProMicro you purchased.

Keyball+ firmware is written using **[Keyball Link](https://keyball-link.shiroganelab.com/)**, a web tool that lets you edit keymaps and flash firmware directly from your browser. No special software installation is required (a WebHID/WebSerial capable browser such as Google Chrome is needed).

## 3. Implementation

Now we begin soldering work.

The PCB is reversible, so first decide which side will be left/right hand.
When operating the trackball with your right thumb, the trackball will be attached to the area where the PCB is cut, as shown in the red circle in the photo below.

<!-- TODO: replace with a photo of the Keyball+ PCB -->


When operating the trackball with your left thumb, the layout is as shown in the photo below.



This build guide explains the specification with the trackball on the right hand.
>**⚡️ Warning**: If you solder the wrong side, rework will be very difficult.
>Please mark the front side with masking tape or similar as shown in the photo below to prevent mistakes.



### 3-1. Before Soldering
The soldering iron tip should be shaped like a bamboo spear tip, which makes it easier to place solder on flat surfaces and "scoop up" excess solder.



### 3-2. Installing Diodes
Now let's solder the diodes in order.
All diodes are soldered on the **back side**.

The diode silk marks are the marks shown by the arrows in the photo below: **21 on the trackball side and 24 on the non-trackball side (45 pieces total for both sides)**.
> **⚡️Warning**: Diodes have polarity, so please install them in the correct orientation.
The orientation is where the straight line on the component matches the straight line at the tip of the arrow in the silk mark.
> Please check the orientation carefully by looking at the photo below.
> All diodes on the same board are arranged in the same orientation.
Please check that the orientation matches the surrounding diodes as you proceed with soldering.



The diode silk has black dots as shown in red in the photo below, so you can verify polarity after soldering the diodes.



Let's start soldering.
First, apply solder to one side of the diode pad.



Grab the diode with tweezers and fix it while melting the pre-applied solder.



Rotate the board 180 degrees and flow solder to the other leg of the diode.
Finally, touch both legs with the iron tip, and if the diode doesn't fall off, both legs are soldered.

Solder the other leg

Install 21 diodes on the trackball side and 24 on the non-trackball side, for a total of 45 on both sides.



### 3-3. Soldering Key Sockets
Key sockets are soldered on the **back side** like diodes.
The kit includes both **MX switch sockets** and **Choc switch sockets**.

For each key position, choose **one of the three combinations** below and solder that (you can choose per key).

**This build guide proceeds with the Choc + LED combination.**

| Combination | Usable switches | LED at this position |
|:--|:--|:--:|
| **MX socket + Choc socket** | Both MX and Choc (swap the switch to change type) | Not possible |
| **MX socket + LED** | MX only | Possible |
| **Choc socket + LED** | Choc only | Possible |

> A position where you want to swap between MX and Choc gets no LED; a position where you want an LED is fixed to either MX or Choc. LED soldering is done in [Chapter 3-4](#anchor3-4).







The number of sockets you solder depends on the combinations you chose: a position with both MX and Choc uses 2 sockets (MX + Choc), a position with an LED uses 1.
If you separate one right-hand thumb key to make a 38-key board (see [Chapter 6](#anchor6)), the socket at that position can be omitted.
Set them to match the silk mark and shape for soldering.

>**⚡️Warning**: If they protrude from the silk, the orientation is wrong.
>Please check the correct orientation in the photo below.

**For MX switch sockets**



**For Choc switch sockets**
Choc sockets also have an orientation. As shown in the photo below, place the terminal with the black resin part in an octagonal shape near the center of the switch.



Bend both tabs at the ends of the socket with tweezers or similar, as shown in the photo, before soldering.



For soldering, apply solder to one side of the socket pad as shown in the blue circle.



Fit the socket and press down with tweezers from above, then touch the iron tip with a little solder from the side of the terminal, and the solder will melt and the socket will sink.
Based on experience, this method is least likely to cause "tempura" (poor connection).

Choc sockets tend to shift position when soldered, so adjust the position as you attach it.





Rotate the board 180 degrees and solder the other terminal.

Solder the chosen socket(s) at all 39 key positions (38 if you separated the right-hand thumb key).



### 3-4. Soldering LEDs (Optional)
LEDs (YS-SK6812MINI-E) are optional.
On Keyball+, LEDs are placed under each key plus underglow: **29 on the left side and 26 on the right side (55 total)**. Note that the count differs between left and right (the side with the trackball has 26, the side without has 29).
If you separate the right-hand thumb key to make a 38-key board (see [Chapter 6](#anchor6)), the LED at that position is also removed, so the trackball side has 25 and the total is 54.

>**⚡️Warning**: A per-key (under-key) LED can only be fitted at a position where the key socket in [Chapter 3-3](#anchor3-3) is **MX only or Choc only**. A position with both MX and Choc sockets cannot have its under-key LED (underglow LEDs are unaffected).
However, LEDs are very sensitive to heat, so please adjust the iron tip temperature to **220°C to 280°C**.
Since the iron tip temperature is low, heat may not transfer to the pad, making it easy for solder to become "tempura" (poor connection).
The keyboard can be used without LEDs, and lighting all LEDs is quite difficult.
We recommend completing it without LEDs first. LEDs can be added later.

All LEDs are soldered on the **back side**.

Match the leg with the notch on the YS-SK6812MINI-E 4-pin with the marked pad and place the LED for soldering.

LEDs are mixed with upward and downward facing ones, but if you match the pin notch with the marking as shown in the photo below, the up/down orientation will automatically match.

Soldering all 4 pins at once can cause the component temperature to rise and damage it, so please solder 2 pins at a time with intervals.
For this reason, place about 10 LEDs at once, and move to the next LED soldering after applying solder once.
This prevents continuously heating one LED.

<!-- TODO: replace with a photo of the Keyball+ LED layout (asymmetric, 55 total) -->


After all LED soldering is complete, proceed to the next step.
The LED lighting check is done after the key switches are mounted, in [Chapter 7-3](#anchor7-3).

### 3-5. Soldering Jumpers
Jumpers need to be shorted to operate the OLED module.

>**⚡️Warning**: Jumper soldering is done **only on the back side**.
There are "Back Side Only" markings, with [4 pieces each] on the left and right boards.
Warm the pad with the iron tip, then melt solder to create a bridge.



If you're not confident in soldering or not good at bridge work, try applying solder to the 8 pads first as shown in the photo below.

40b

Adding solder here should make bridging easier.

40b

If the solder freshness deteriorates (heated multiple times), surface tension decreases and bridging becomes difficult.
Scrape off the solder once and add solder or flux to try again.
When bridging is successful, it should look like the photo below.
Bridge a total of 8 locations on both sides.

There are other jumpers, but these will be explained later, so please solder only 4 locations each on the left and right for now.

### 3-6. TRRS Socket, Tactile Switch, and 4-pin Socket
Solder the parts shown in the photo below.
>**⚡️Warning**: This time all are installed **only on the front side**, so please be careful.



If you're worried about parts floating, fix them with masking tape or similar for soldering.



When all are installed, it should look like the photo below.



### 3-7. Soldering ProMicro
ProMicro is soldered using the connector pins shown in the photo below, which makes replacement easier when ProMicro fails.
Connector pins have installation direction, so please look at the photo carefully for the work.



First, insert the connector pin into the board [front side] loosely. (It does not need to be fully seated yet.)

Insert the connector to match the **square silk frame**.
If the black silk frame is misaligned with the connector, the insertion hole is wrong.



Rest ProMicro loosely on the inserted connector pin, then press ProMicro down — this also seats the connector pin firmly.



Solder **only the ProMicro side** in a state where it's firmly inserted to the end.
Soldering while inserted into the board prevents the connector pin from being installed at an angle.
>**⚡️Warning**: If you solder the connector pin to the middle PCB side as well, replacement will be very difficult when ProMicro fails.



OLED can be installed on both left and right boards as standard.
Insert a 4-pin header into the 4-pin socket and place the OLED module.
Then solder **only one** of the 4 pins.

While melting the solder of the single soldered pin, press the OLED module from above to prevent it from floating.
Also, adjusting it to be parallel with ProMicro will look better.

Once the position is determined, solder the remaining 3 pins.



The main-board soldering is done here (the trackball reading board follows in [Chapter 4](#anchor4), and the left-right detection jumper in [Chapter 5](#anchor5)).
Firmware writing and the key-input / LED operation check are done after the key switches are mounted, in [Chapter 7-3](#anchor7-3).

## 4. Assembling the Trackball Reading Board
Prepare the board shown in the photo below (hereinafter, ball board) and optical sensor.

※For quality confirmation of sensors and boards, pre-soldered ball boards may arrive.
In that case, skip this step and proceed to L-shaped connector soldering in [Chapter 4-2](#anchor4-2).



### 4-1. Soldering the Sensor

The sensor IC is inserted from the back side where no components are mounted on the ball board.
>**⚡️Warning**: If the sensor polarity is wrong, repair will be very difficult!
Please carefully confirm that it's inserted in the correct orientation and from the correct direction before soldering!
Match the notch indicating pin 1 of the IC with the [1pin] silk on the board.



The IC looks like this from the back.
Solder all pins from the front side where SMD components are mounted (the side without the Keyball logo).



Use tweezers to peel off the protective seals [2 pieces].



Attach the sensor lens to the side where the protective seals were peeled off.
The lens has direction, and if the direction is wrong, the two thin pins of the lens may break, so please check the direction carefully.
There's a protrusion like the arrow in the photo below at the front of the lens, and this should be on the top side when mounting.



If the lens and IC directions match, the two pins of the lens should insert into the IC without force. Please insert slowly.



### 4-2. Soldering the L-shaped Connector
Next, install the L-shaped connector pin on the **front side** of the board where the trackball will be mounted.
The L-shaped connector also has direction.
Insert the side where the pins are not U-shaped into the middle board for soldering.



Apply masking tape or similar to prevent parts from floating and solder from the back side.



Next, solder the 4 jumpers for optical sensor signal lines.
>**⚡️Warning**: There are jumpers near the soldered connector, so apply solder to **only the back side** and short them as shown in the photo below.



## 5. Soldering the Left-Right Detection Jumper on the Left Side

>**⚡️Warning**: The standard Keyball+ firmware has a function to automatically detect the left/right of the keyboard.
For detection, solder a jumper at **one location only on the left side board**.

When looking at the left side board from the back, there's a **LEFT** silk as shown in the red circle in the photo below.
Please solder the jumper next to this to short it.



If mounting the trackball on the left side, the position is slightly different, and the LEFT jumper will be at the position shown in the photo below.

>**⚡️Warning**: Be sure to jumper **only the left side board**.



The soldering work is now complete.

As a side note, before turning off the soldering iron, apply plenty of solder to the tip. When you use it next time, if you remove this solder, you can resume work with a shiny tip!



## 6. Cutting the Top Plate (Optional)

The top plate has sections that can be separated along a perforation only if you need to.
If you are combining MX and Choc switches, cut along the perforation.
When cutting, use a cutter to score the perforation on both the front and back sides, then fold to separate, and polish the cut edge with about 150 grit sandpaper.

### ① Remove one right-hand thumb key (make it a 38-key board)

<!-- TODO: add a Keyball+ photo showing where the right-hand thumb key is separated -->
You can separate the **thumb key closest to the trackball**, on the trackball side.
This is an option for people whose thumb hits this key while operating the trackball.
After separating it, the board has **38 keys**. The LED at that position is separated together with the key, so if you install LEDs the trackball side has one fewer, for **54 in total**.
In that case you only need **38** key switches and **38** keycaps. The key socket at that position is unused even if soldered, so you may skip it.

### ② Choc thumb section with MX everywhere else

You can build the thumb section with Choc switches and the rest with MX switches (the reverse combination is also possible, but this is the only practical switch mix).
In that case the thumb section (Choc = 4mm spacer) and the rest (MX = 7mm spacer) end up at different top-plate heights, so separate the thumb section along the perforation.
**If you build with all MX or all Choc switches, this cut is not needed.**

Since every key position has a fixed switch type in this build, you can use **"Choc + LED" for the thumb keys and "MX + LED" for the rest** to fit an under-key LED at every position (55 total; see the combinations in [Chapter 3-3](#anchor3-3)).



Polish the cut surface with about 150 grit sandpaper.



## 7. Assembly

### 7-1. Installing the Protection Plate

Install the ProMicro protection plate on the middle board.

First screw the 9mm spacer, then screw the acrylic protection plate to it.

The protection plate shape is common for both trackball and non-trackball sides. There's no front/back.



### 7-2. Assembling the Top Plate

Screw the spacer to the **back side** of the top plate.
Use the **7mm** spacers for an MX build, or the **4mm** spacers for a low-profile (Choc) build (12 pieces total for both sides).



First, insert key switches into the four corners of the top plate. This improves the positioning accuracy between plates.

For an MX build, match the screw holes of the top plate and middle acrylic plate, and stack the plates.



Next, also match the screw holes of the soldered middle board, and stack while confirming that the key switch terminals fit firmly into the key sockets.



Once the plates are stacked, **install all the remaining key switches** (38 for a 38-key build). Push each switch straight down from the top-plate side, checking that the terminals don't bend, and confirm on the back of the middle board that both terminals came out of the socket. You need every switch installed at this stage so you can check key input in [Chapter 7-3](#anchor7-3).

### 7-3. Writing the Firmware and Checking Operation

Now that the key switches are installed, write the firmware and check key input and LED operation.
**Once the bottom plate is attached you can no longer reach the ProMicro, LEDs, or the back of the boards, so check at this stage.**

Keyball+ has no test-only firmware like Keyball39. You write the production firmware from [Keyball Link](https://keyball-link.shiroganelab.com/).
There are two versions, a **standard version** and an **LED version**: choose the **LED version if you installed LEDs, or the standard version if you did not** (the standard version does not light LEDs but lets you use more features).
Keyball+ firmware is common regardless of which side the trackball is mounted on.

Open Keyball Link, connect Keyball+ to your PC with a USB cable, and follow the on-screen instructions to write (FLASH) the firmware.
If the keyboard is not recognized even with the USB cable connected, try pressing the soldered RESET switch quickly twice.
※Be sure to write the same firmware version to both left and right Pro Micros.

When writing is done, open a text editor and **press every key one by one to confirm it registers correctly**.
If left and right are reversed, re-check the left-right detection jumper in [Chapter 5](#anchor5). If a key does not respond, redo the soldering of that key's socket and diode.



If you installed LEDs, also check that they light up.
LEDs are wired in series, so it's easy to identify a problem area if only some light up.
For example, if LEDs up to number 12 light up but number 13 onward do not, the soldering of [LED 12 or 13] is likely at fault, so redo those. If that does not help, replace LED 13.
Repeat the lighting check and soldering correction until all LEDs light up.

If you want to directly edit Keyball+ firmware and build it yourself, use the [keyball-plus-firmware repository](https://github.com/ineno771/keyball-plus-firmware) (see [Chapter 10](#anchor10)).

### 7-4. Assembling the Bottom Plate

Once the operation check is done, peel off the protective sheet of the acrylic bottom plate, place it on the back of the main body, and screw it.
Next, attach cushion rubber to the four corners of the keyboard back.

## 8. Installing the Trackball

### 8-1. Inserting the Ball Reading Board

Insert the assembled trackball reading board into the 7-pin connector.
Insert the board vertically.



### 8-2. Assembling the Trackball Case

The trackball case has 3 ceramic balls pre-fixed.
If ceramic balls happen to fall off, please fix the spare ceramic ball with appropriate bond.
Please keep the spare ceramic ball for future use in case you lose the ball.

Shake the case to check that the ceramic balls don't fall off.



The two pins on the case top can be inserted into the hole in the case bottom.
Apply force slowly from top and bottom to combine. (It doesn't need to fit perfectly as it will stick together with the subsequent screw tightening.)



Attach M1.7 tapping screws.
The kit includes **small head screws** and **flat head screws**, but use the **small head screws**.



From the back of the case, screw these 2 locations.
>**⚡️Warning**: Be careful not to overtighten.



### 8-3. Installing the Trackball Case

Install the completed case to the main body.
The ball board goes into the sensor storage area on the back of the case.
While making sure the ball board shown by the arrow is around the center of the case, slowly fit it from above.
If there's resistance, don't force it in, but pull it out once and try inserting again.

It should go all the way in without much force.



When checking from the back of the main body, there may be a gap as shown by the arrow between the main board and ball board.



In that case, gently push from the front of the case (in the direction of the finger mark).
Applying too much force may damage the L-shaped connector, so push gently.
When the gap disappears as shown in the photo below, the screw holes in the blue circle should match.



Tighten the **flat head screws** 2 pieces of M1.7 torx screws included in the kit from the back of the main body.
At this time, hold the ball holding case with your finger to prevent it from rotating while tightening the screws.

## 9. Final Assembly

Almost complete! Finish by pushing in the 34mm trackball and fitting your keycaps!
Thank you for your hard work.



<!-- TODO: replace with a photo of the completed Keyball+ -->
Keyball+ completed

## 10. Changing the Keymap / Updating the Firmware

The firmware was already written in [Chapter 7-3](#anchor7-3). This chapter is for reference when you later change the keymap or re-flash the firmware to a newer version.

The Keyball+ keymap can be changed and flashed from your browser with the dedicated web tool **[Keyball Link](https://keyball-link.shiroganelab.com/)**. No special software installation is required.

If you re-flash the firmware, mind the **standard version** vs **LED version**.
Choose the **LED version if you soldered the LEDs, or the standard version if you did not** (if you flash the LED version without any LEDs installed, capacity is spent on unused LED control and some features available in the standard version are dropped).

>**⚡️Warning**: Be sure to write the same firmware version to both left and right Pro Micros. The keymap is written to the ProMicro on the side where the USB cable is connected.

**If you want to build firmware yourself**
The latest Keyball+ firmware is published in the [keyballplus-firmware repository](https://github.com/Yowkees/keyball/tree/main/qmk_firmware/keyboards/keyball/keyballplus).
Copy the `keyboards/keyball` folder from the repository to your QMK Firmware `keyboards` directory and freely edit keymaps etc. to build.

## 11. How to Use Keyball+♪
   - The trackball changes to up/down/left/right scroll while switched to the scroll layer.

   - [Keyball Link](https://keyball-link.shiroganelab.com/) allows easy keymap checking, changing, and writing.

   - USB cable can be inserted into either left or right side.
   However, keymaps are written to the ProMicro on the side where the USB cable is inserted, so please review the keymap when switching for the first time.

   - Specially prepared keycodes for the Keyball series are available.
   They can be used to change the trackball to scroll, or change cursor speed and scroll speed.

   >**⚡️Warning**: Disconnecting the TRS cable while Keyball is connected to PC (powered on) can cause malfunction.
   When disconnecting/connecting the TRS cable, always disconnect the USB cable first.

This concludes the Keyball+ build guide.
For questions or issues about Keyball+, please post to the [Yowkees/keyball Discussions](https://github.com/Yowkees/keyball/discussions).
We will respond as quickly as possible.

―Acknowledgments―
The Keyball+ firmware is based on the Keyball39 firmware. Thanks to the tremendous cooperation of [KoRoN@Kaoriya](https://www.kaoriya.net/), the Keyball39 firmware has significantly improved trackball operation smoothness, and the substantial memory reduction allows enjoyment of many LED actions. I would like to express my deep gratitude here. Thank you very much.
　@Yowkees

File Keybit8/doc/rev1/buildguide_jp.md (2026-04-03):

# Build Guide for Keybit8

このガイドでは、Keybit8の組み立て手順から使い方まで詳しく説明します。 
Keybit8キットのご購入は[こちら](https://shiroganelab.com/products/keybit8)から。  
基板の色は不定期で変更になることがあります。  
本ビルドガイドは黒基板を元に説明していますが、基板の色によって手順が変わることはありません。



## 【目次】

> **準備編**
 - [1. キット同梱品の確認](#anchor1)
 - [2. 準備](#anchor2)
   - [2-1. 必要な工具](#anchor2-1)
   - [2-2. ファームウェア](#anchor2-2)

> **実装**
 - [3. 実装・組み立て](#anchor3)
   - [3-1. はんだ付けの前に](#anchor3-1)
   - [3-2. 抵抗器の取り付け](#anchor3-2)
   - [3-3. ダイオードの取り付け](#anchor3-3)
   - [3-4. トランジスタアレイの取り付け](#anchor3-4)
   - [3-5. LEDの取り付け](#anchor3-5)
   - [3-6. ProMicro・ピンヘッダ・ピンソケットの取り付け](#anchor3-6)
   - [3-7. タクトスイッチ・圧電スピーカーの取り付け](#anchor3-7)
   - [3-8. キースイッチの取り付け](#anchor3-8)

> **仕上げ編**
 - [4. 仕上げ](#anchor4)
 - [5. 正規ファームウェアの書き込み](#anchor5)
 - [6. キーマップの変更方法](#anchor6)
 - [7. Arduino IDEの使用方法](#anchor7)

## 1. キット同梱品の確認
まず最初にキットに同梱されている内容物一覧を確認し、内容物が全て入っているかご確認ください。

**Keybit8 標準キットの同梱品一覧**
| 部品名 | 回路番号 | 数量 | 備考 |
|:---|:---:|:-----:|-----:|
| 抵抗器180Ω 茶灰茶金 | R1〜R9 | 9本 |  |
| 抵抗器2.7kΩ 赤紫赤金 | R10,R11 | 2本 |  |
| 抵抗器2kΩ 赤黒赤金 | R12 | 1本 |  |
| 赤色LED（透明色レンズ）| D1〜D8 | 8本 |  |
| 緑色LED（緑色レンズ）| D9 | 1本 |  |
| ガラス封入ダイオード | D10〜D17 | 8本 |  |
| ProMicro / USB type-Cコネクタ版 | U1 | 1本 | 教材用キットにのみ同梱されています |
| ProMicro用ピンヘッダ 12P 1.5mm | U1 | 2本 |  |
| ProMicro用ピンソケット 12P 3.5mm | U1 | 2本 |  |
| 8ch トランジスタアレイ TBD62783A | U2 | 1本 |  |
| 圧電スピーカー 13mm | LS1 | 1本 |  |
| サイレントリニア MX クリアスイッチ | SW1〜SW8 | 8個 | 同梱されていない一般向けキットがあります |
| タクトスイッチ | SW9 | 1個 |  |
| キーキャップ |  | 8個 | 同梱されていない一般向けキットがあります |
| クッションゴム |  | 4個 |  |
| Keybit8 基板 |  | 1枚 |  |
| 保護プレート |  | 1枚 | 教材用キットには同梱されていません |
| M2丸型スペーサー 11mm (ARB-2011E) |  | 4本 | 教材用キットには同梱されていません |
| M2ネジ L3.5mm 「FX-0235E」 |  | 8本 | 教材用キットには同梱されていません |



## 2. 準備

### 2-1. 必要な工具

Keybit8の組み立てには下記の工具が必要です。すべて揃っているかご確認ください。

| 工具名 | 用途 |
|:---|:-----|
| はんだごて| はんだ付け作業 |
| はんだ| 接続用 |
| ニッパー | 余分なピンの切断用 |
| ピンセット | 部品取り扱い用 |
| 0番＋精密ドライバー | 保護プレート組み立て用（教材用セットの場合は不要） |



### 2-2. ファームウェア

Keybit8を動作させるには、ProMicroへのファームウェアの書き込みが必要です。  
すでにビルド済みのファームウェアを、[REMAP](https://remap-keys.app/)というウェブ上のキーボード管理ソフトにて簡単に書き込みができます。  
書き込みについてはこの後の[5章](#5-正規ファームウェアの書き込み)で製品版ファームウェアの書き込みについて詳しく説明しています。

## 3. 実装・組み立て

ここからはんだ付けと組み立て作業を行なっていきます。  
はんだ付けパーツは全て基板の表面から差し込んで裏面にはんだ付けをしていきます。  

下記画像が基板（表面）です。  
  

下記画像が基板（裏面）です。  
  

### 3-1. はんだ付けの前に
はんだごての"こて先"は竹槍の先端のような形状のものだと平面にはんだを乗せたり、余分なはんだを"すくい取る"事が出来るので使いやすいです。  


### 3-2. 抵抗器の取り付け
それでは抵抗器を取り付けていきます。  
画像を参考にし、基板に記載されている抵抗値と抵抗器の色帯を確認しながら、正しい抵抗器を取り付けてください。    

>**⚡️注意**:抵抗器の取り付け箇所を間違えると動作しなくなるので、1個ずつ確認しながら取り付けを行ってください。  
取り付け箇所を間違えた場合は、はんだ吸い取り機、又ははんだ吸い取り線ではんだを除去して部品を取り外してください。

まずR12の抵抗器（赤黒赤金の色帯）を取り付けて、はんだ付けをします。  
   

画像のように抵抗器のピンを折り曲げて基板のスルーホールに差し込みます。  
  

基板裏面から抵抗器のピンを折り曲げて抵抗器が外れないように固定すると、はんだ付けしやすいです。  
  
  
はんだ付けをした後は余分なピンをニッパーでカットします。  
ピンをカットした後はんだを再加熱すると、きれいに仕上がります。（気になる方は実施してください。）  


次にR10とR11の抵抗器（赤紫赤金の色帯）を1個ずつ取り付けて、はんだ付けをしてください。   
 

最後にR1〜R9までの抵抗器（茶灰茶金の色帯）を同様に1個ずつ取り付けて、はんだ付けをしてください。  
全部で12本の抵抗器を取り付けます。  
取り付けた抵抗器が抵抗値と一致しているか最後に確認をしてください。  


### 3-3. ダイオードの取り付け
次にダイオードを取り付けていきます。ダイオードには取り付ける方向があるので注意してください。  
ダイオードは全部で8本取り付けます。  
抵抗器と同じようにピンを折り曲げてからスルーホールに差し込みます。  


ダイオードの黒いライン（極性マーク）の向きを基板上の白いラインと合わせて取り付けます。
>**⚡️注意**:ダイオードの向きは8個全て同じ向きで取り付けます。  
はんだ付けをする前に極性マークの向きと、他のダイオードと同じ向きになっているか、確認してからはんだ付けしてください。   



抵抗器と同様に差し込んだ後にピンを折り曲げて固定すると、はんだ付けしやすいです。  


はんだ付け後  


### 3-4. トランジスタアレイの取り付け
トランジスタアレイを取り付けていきます。  
  

トランジスタアレイには半円形の切り欠きがあります。  
基板上の半円形マークと向きを合わせて差し込みます。  
  

トランジスタアレイを差し込んだ状態で、余ったピンをカットしてからはんだ付けすると、きれいに仕上がります。  
>**⚡️注意**:トランジスタアレイが浮いた状態ではんだ付けをしてしまうと修正が難しいので、はんだ付けをする前にしっかりと差し込まれた状態か確認してからはんだ付けをしてください。  
（難しい場合はマスキングテープで固定をすると作業しやすいです。）    



### 3-5. LEDの取り付け
LEDを取り付けていきます。  
LEDにも極性があり、下記画像のようにLEDの切り欠き（平らな部分）と基板の円形マークの切り欠き部分に合わせて取り付けてください。  
LEDには赤LED（透明レンズ）が8本と緑LED（緑レンズ）が1本あります。  
緑LEDの取り付け箇所には「GREEN」の表記があるので間違えないように注意してください。  


LEDの切り欠き部分を基板のシルクの円形の切り欠き部分に合わせて差し込みます。  


ピンが短い方が切り欠き方向になります。  


LEDも同様にはんだ付けが難しい場合はマスキングテープなどで固定してからはんだ付けしてください。  
はんだ付け後は余分なピンをカットしてください。  


取り付け後イメージ  


### 3-6. ProMicro・ピンヘッダ・ピンソケットの取り付け

後から差し込みづらくならないようにProMicro・ピンヘッダ・ピンソケットを全て基板に取り付けた状態ではんだ付けを行ってください。  
ピンヘッダーをピンソケットに差し込むにはコツが必要です。  
ProMicro・ピンヘッダ・ピンソケットを全て基板に軽く差し込んだ状態でProMicroを押さえながら差し込むと、しっかり奥まで差し込むことができます。  
※ピンヘッダとピンソケットは、はんだ付け後も着脱可能な状態が正常です。  
  

ProMicroのはんだ付けをする際はProMicroの基板をマスキングテープで保護してからはんだ付けをしてください。  
はんだカスがProMicroの基板部分に付着して故障の原因になることがあります。
>⚠️ピンの数が多いパーツはまず1〜2箇所はんだ付けを行い、目視でパーツが浮いていないことを確認してから残りのはんだ付けも完了させます。



### 3-7. タクトスイッチ・圧電スピーカーの取り付け

タクトスイッチの取り付けを行います。  
  

タクトスイッチを差し込んだ後に、余ったピンをニッパーでカットしてから、はんだ付けをするときれいに仕上がります。  


仕上がりイメージ  


次に圧電スピーカーの取り付けを行います。  
余分なピンをカットしてから基板に差し込みます。  
差し込んだ後にピンを折り曲げて固定してから、はんだ付けを行います。  


はんだ付け後、余分なピンをカットします。  
気になる方は、はんだを再加熱してきれいに仕上げてください。  


### 3-8. キースイッチの取り付け

キースイッチは8個全てを差し込んでから、はんだ付けをすると安定して取り付けられます。  


ピンは折れ曲がりやすいので、8個全て基板に当たって折れ曲がっていないか確認をしてください。  


スルーホールからはみ出した余分なピンはカットしてからはんだ付けをすると、きれいに仕上がります。  


## 4. 仕上げ

最後にキーキャップを取り付けて、クッションゴムを基板裏面の4つ角に取り付けたらKeybit8の完成です！  
お疲れ様でした。  

完成イメージ 表  
  

完成イメージ 裏  
 

## 5. 正規ファームウェアの書き込み

それでは最後に正規のファームウェアをProMicroに書き込みましょう。  

Keybit8は[Remap](https://remap-keys.app/)に対応しているので、特別なソフトをインストールしなくても、ブラウザからファームウェアの書き込みとキーマップの変更が可能です。  
Remapの使用方法について詳しく知りたい方は[自キ温泉ガイドのサリチル酸](https://salicylic-acid3.hatenablog.com/entry/remap-manual)の記事をご覧ください。

Remapを使用するために[RemapカタログのKeybit8ファームウェアページ](https://remap-keys.app/catalog/LeRwa1B3uvwBCAaavuI7)を開き、Keybit8_viaのファームウェアを書き込みます。  
※上記のリンクからアクセスした場合は手順3から始めてください。

1.[Remap](https://remap-keys.app/)にアクセスしてトップページの「キーボードを探す」を選択します。  
   

2.「Keybit8」を検索して選択します。  
 

3.「ファームウェア」のタブを選択し、Keybit8をUSBケーブルでデバイスに接続してから「書き込み」を選択します。  
 
  
4.再度「書き込み」を選択してからKeybit8のポートを選択します。  
USBケーブルを接続しているのにキーボードが認識されない場合は、はんだ付けしたリセットスイッチ（タクトスイッチ）を素早く2回押すと認識されます。  
Keybit8のポートを選択し、「接続」を押すとファームウェアの書き込みが開始されます。  
 

これで書き込みは完了です。  

**ご自身でファームウェアをビルドする場合**   
Keybit8の最新ファームウェアは[Githubのリポジトリ](https://github.com/Yowkees/qmk_firmware/tree/master/keyboards/keybit8)にて公開しています。  
このkeybit8フォルダをお手持ちのQMK_Firmware/keyboardsへコピーして自由にキーマップ等を編集してmakeしてください。  

## 6. キーマップの変更方法 
   [Remap](https://remap-keys.app/configure)で簡単にキーマップの確認・変更・書き込みが可能です。  
   [Remap](https://remap-keys.app/)のトップページから「キーボードをカスタマイズ」を選択し、「+キーボード」からKeybit8を選択します。

   ①変更したいキーのレイヤーを選択します。  
      

   ②使用したいキーを変更したいキーへドラッグ&ドロップするだけで簡単に変更できます。  
      

   その他の変更方法として、変更したいキーをクリックすると下記画像のようにポップアップが表示されるので、「キーコード」の入力欄に使用したいキーを入力します。  
   又は「キーコード」の入力欄を選択すると、使用できるキーの一覧が表示されるので、一覧から使用したいキーを選択することも可能です。  
   「Ctrl＋C」等のショートカットキーを1キーで入力したい場合は下記画像のように修飾キーを選択します。  
      

   「ホールド/タップ」タブを選択すると、キーを短く押したとき（タップ）と押し続けたとき（ホールド）で、それぞれ異なるキー入力を設定できます。  
     

   「カスタム」のタブでは使用したいキーが見つからない場合等に16進数でキーを割り当てることが可能です。  
   分からない場合はAIに「〇〇（入力したいキーや機能）のVIAキーコードの16進数は？」等と質問すると回答してくれるので、コピペして設定することも可能です。  
   「ラベル」には自動で名前が付けられますが、自分で名前をつけることもできます。  
      

   Keybit8はキーボードとして使用する方法以外に、8個のキーと9個のLEDと圧電スピーカーを使用したゲームで遊ぶことができます。  
   左側4つのキー(1.2.3.4)を同時に長押しすることで「キー入力モード」と「ゲームモード」を切り替えられます。 （キーの番号は下記画像を参照） 

   ゲームモードのとき、次のキーの組み合わせを同時に押すと、それぞれのゲームで遊ぶことができます  
   1 + 3 を同時に押す → 「オルガン」  
   1 + 5 を同時に押す → 「ルーレットゲーム  
   1 + 7 を同時に押す → 「タイピングゲーム」  

   以上の3つのゲームが正規のファームウェアに書き込まれています。   

   各ゲームを終了するには右側4つのキー(5.6.7.8)を同時に長押ししてください。※各ゲームを終了しても引き続きゲームモードの状態は維持されています。  
   キー入力モードに切り替えたい場合は左側4つのキー(1.2.3.4)を同時に長押ししてください。  
    

## 7. Arduino IDEの使用方法

   Keybit8は[Arduino IDE](https://www.arduino.cc/en/software)を使用して自分でプログラムを書くことで、ゲームなどを作成して楽しむことができます。

   [Arduino IDE](https://www.arduino.cc/en/software)の使用方法  
   
   1.Arduino IDEをインストールする。  
   

   2.Arduino IDEを開いてボードの設定をする。（ツール → ボード → Arduino AVR Boards → Arduino Leonardo を選ぶ）  
   

   3.コードを書く  
   

   4.Keybit8をPCに接続してからTool → PortでKeybit8のポートを選ぶ。  
   どれがKeybit8のポートか分からない場合は、一度ケーブルを抜き、再度挿した時に新しく増えた番号を選択してください。  
   ポートが表示されない場合はKeybit8のリセットスイッチを2回素早く押すと表示されます。   
   多くの場合、Port番号の末尾に「Arduino Leonardo」と記載があります。  
     

   5.画面左上のマイコンボードに書き込むボタン（赤枠のボタン）を押して、Keybit8のリセットスイッチを「カチカチッ」と素早く2回押します。  
     
   画面右下に「Done uploading」と表示されれば成功です。

   - Arduino IDEの入門としてLEDをチカチカさせるコードを2通り記載します。ぜひお試しください。
      ```
      // LED を1秒ごとにチカチカさせる

      int ledPin = 9;  // 緑LEDのピン番号

      void setup() {
        pinMode(ledPin, OUTPUT);  // ピンを出力に設定
      }

      void loop() {
        digitalWrite(ledPin, HIGH);  // 点灯
        delay(1000);                 // 1秒待つ
        digitalWrite(ledPin, LOW);   // 消灯
        delay(1000);                 // 1秒待つ
      }
      // delay(1000) の数字を変えると点滅の速さが変わるので試してみてください。
      ```
      
      ```
      // キーを押すとLEDがチカチカする

      // キースイッチマトリクス（2×4）
      const int ROW[2] = {21, 20};
      const int COL[4] = {4, 5, 6, 7};

      // キー対応LED 9個　LED[0]～LED[7]が赤、LED[9]が緑
      const int LED[9] = {1, 0, 8, 16, 14, 15, 18, 19, 9};

      // 圧電スピーカー
      const int buzzerPin = 10;

      void setup() {
        pinMode(LED[0], OUTPUT);  // LED1を出力に設定
        pinMode(ROW[0], OUTPUT);  // ROW1を出力に設定
        pinMode(COL[0], INPUT_PULLUP);  // COL1を入力に設定
        digitalWrite(ROW[0], LOW);  //ROW1をLOW(GND)にする
      }

      void loop() {
        digitalWrite(LED[0], HIGH); // LED1点灯
        delay(500); //500ミリ秒待ち
        digitalWrite(LED[0], LOW); // LED1消灯
        if(digitalRead(COL[0]) == LOW){
          delay(500); //もしSW1が押されていれば500mS待ち
        }
      }
      ```

以上でKeybit8のビルドガイドは終了です。    
お疲れ様でした。  

Keybit8についてのご質問や不具合等についてはShiroganeLabオンラインショップの[お問い合わせ](https://shiroganelab.com/pages/contact)からお気軽にご連絡下さい。    
プログラミングで自分だけのゲームを作ったり、使いやすいキーボードに設定したりして、ぜひいろいろ試して楽しんでください。

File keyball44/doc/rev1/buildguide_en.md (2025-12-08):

# Build Guide for Keyball44

This guide provides detailed instructions for assembling the Keyball44.  
※This guide uses photos of the white PCB version of Keyball44, but the same procedure applies to the black PCB version.  
Sections that require special attention for black PCB sets are marked with ⚫️ at the beginning.

**日本語版のKeyball44ビルドガイドは[こちら](buildguide_jp2.md)です。**



## 【Table of Contents】

> **Preparation**
 - [1. Parts Check](#anchor1)
   - [1-1. Kit Contents](#anchor11)
   - [1-2. Parts You Need to Prepare Yourself Before Assembly](#anchor1-2)
   - [1-3. Parts and Options That Can Be Installed After Assembly](#anchor1-3)
 - [2. Preparation](#anchor2)
   - [2-1. Required Tools](#anchor2-1)
   - [2-2. Firmware](#anchor2-2)

> **Implementation**
 - [3. Implementation](#anchor4)
   - [3-1. Before Soldering](#anchor3-1)
   - [3-2. Installing Diodes](#anchor3-2)
   - [3-3. Soldering LEDs (Optional)](#anchor3-8)
   - [3-4. Soldering Key Sockets](#anchor3-3)
   - [3-5. Soldering Jumpers](#anchor3-4)
   - [3-6. TRRS Socket, Tactile Switch, and 4-pin Socket](#anchor3-5)
   - [3-7. Soldering ProMicro](#anchor3-6)
   - [3-8. ProMicro Programming and Operation Check](#anchor3-7)
 - [4. Assembling the Trackball Reading Board](#anchor4)
   - [4-1. Soldering the Sensor](#anchor4-1)
   - [4-2. Soldering the L-shaped Connector](#anchor4-2)
 - [5. Cutting the Top Plate (Optional)](#anchor5)

> **Assembly**
 - [6. Assembly](#anchor6)
   - [6-1. Installing the Protection Plate](#anchor6-1)
   - [6-2. Assembling the Top Plate](#anchor6-2)
   - [6-3. Assembling the Bottom Plate](#anchor6-3)
 - [7. Installing the Trackball](#anchor7)
   - [7-1. Inserting the Ball Reading Board](#anchor7-1)
   - [7-2. Assembling the Trackball Case](#anchor7-2)
   - [7-3. Installing the Trackball Case](#anchor7-3)

> **Finishing**
 - [8. Final Assembly](#anchor8)
 - [9. Writing the Official Firmware](#anchor9)
 - [10. How to Use Keyball♪](#anchor10)

## 1. Parts Check

Please check that all kit contents are included when your kit arrives.

### 1-1. Kit Contents

The standard set can accommodate one thumb trackball on either the left or right side.

Single-hand kits are also available for dual-ball specifications with trackballs on both sides, or for assembly without trackballs on either side.

If you purchased a single-hand set or dual-ball set, please check the included parts list in your kit for the contents.

 ⚠️ If ProMicro pin headers + pin sockets are included instead of 12P connectors, please use the [build guide here](https://github.com/Yowkees/keyball/blob/main/keyball44/doc/rev1/buildguide_jp_pinheader.md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).

**Keyball44 Standard Kit Contents**
| Part Name | Quantity | Notes |
|:---|:----:|:-----|
| Middle PCB (Left/Right) | 1 set | Main board |
| Top PCB Plate (Left/Right) | 1 set | For key switch mounting |
| Middle Acrylic Plate (Left/Right)| 1 set | For key switch mounting |
| Bottom Acrylic Plate (Left/Right) | 1 set | Bottom cover |
| ProMicro Protection Plate | 2 pieces | For board protection |
| Trackball Holding Case (Top/Bottom) | 1 set | For ball mounting |
| Φ2 Ceramic Ball | 1 piece | Spare |
| Trackball Reading Board | 1 piece | Sensor board |
| L-shaped Connector Pin (7-pin) | 1 piece | For sensor connection |
| Trackball Reading IC | 1 piece | PMW3360 |
| Reading IC Lens | 1 piece | Optical lens |
| Flat Head Tapping Screw M1.7 | 2 pieces | For trackball case mounting |
| Small Head Tapping Screw M1.7 | 2 pieces | For trackball case assembly |
| TRRS Jack | 2 pieces | For left/right connection |
| Tactile Switch | 2 pieces | For reset |
| Straight Connector Pin (12-pin) | 4 pieces | For ProMicro connection |
| Diode (SMD type) | 50+ pieces | For key matrix error prevention |
| Kailh PCB Socket CherryMX compatible | 44+ pieces | For key switches |
| Kailh PCB Socket choc compatible| 5 pieces | Used when modifying thumb keys to low profile |
| OLED Module | 2 pieces | Display |
| 4-pin Header  | 2 pieces | For OLED connection |
| 4-pin Socket | 2 pieces | For OLED connection |
| Spacer M2 7mm | 14+ pieces | Standard spacers |
| Spacer M2 9mm | 4 pieces | For height adjustment |
| Spacer M2 4mm | 4 pieces | Used for thumb low profile specification |
| Screw M2 3.5mm | 36+ pieces | For plate mounting |
| Cushion Rubber | 10 pieces | For bottom anti-slip |



### 1-2. Parts You Need to Prepare Yourself Before Assembly

The following parts are not included in the kit and need to be purchased separately.

| Part Name | Quantity | Notes |
|:---|:----:|:-----|
| ProMicro | 2 pieces | You can choose inexpensive ones or USB Type-C compatible ones |
| CherryMX Compatible Key Switches | 44 pieces | 39 pieces if using thumb low profile specification |
| Low Profile Key Switches | 5 pieces | Only if using thumb low profile specification |
| 34mm Diameter Trackball | 1 piece | Required when using trackball |
| TRS (3-pole) Cable | 1 piece | TRRS (4-pole) cable is also acceptable |
| Micro USB Cable | 1 piece | Compatible with the ProMicro you purchased |



### 1-3. Parts and Options That Can Be Installed After Assembly

The following parts can be installed after assembly and can be customized according to your preferences.

| Part Name | Quantity | Notes |
|:---|:----:|:-----|
| Keycaps | 44 pieces | 1u 44 pieces |
| Low Profile Keycaps | 5 pieces | Only for thumb low profile specification - 1u 5 pieces |
| YS-SK6812MINI-E | 59 pieces | ※SK6812MINI cannot be used |



## 2. Preparation

### 2-1. Required Tools

The following tools are required for assembling Keyball44. Please check that you have all of them.

| Tool Name | Purpose |
|:---|:-----|
| Soldering Iron (Temperature adjustable if implementing LEDs) | Soldering work |
| Solder (Low melting point is effective if implementing LEDs) | For connections |
| #0 + Precision Driver | For screw tightening |
| Tweezers | For handling parts |
| Cutter | For cutting thumb section parts of top plate |
| 150 grit sandpaper | For polishing when cutting plates |



### 2-2. Firmware

To operate Keyball44, firmware needs to be written to the ProMicro you purchased.

 Pre-built firmware can be easily written using [REMAP](https://remap-keys.app/), a web-based keyboard management software.
 
 Writing is explained in detail in [Chapter 3-7](#anchor3-7) for test firmware writing and [Chapter 10](#anchor10) for production firmware writing.

## 3. Implementation

Now we begin soldering work. 

 The PCB is reversible, so first decide which side will be left/right hand.  
 When operating the trackball with your right thumb, the trackball will be attached to the area where the PCB is cut, as shown in the red circle in the photo below.    



When operating the trackball with your left thumb, the layout is as shown in the photo below. 



This build guide explains the specification with the trackball on the right hand.  
>**⚡️ Warning**: If you solder the wrong side, rework will be very difficult.  
>Please mark the front side with masking tape or similar as shown in the photo below to prevent mistakes.



⚫️ For black PCB sets, you can optionally fill the sides of the top PCB and middle PCB with a black marker for a cleaner finish.



### 3-1. Before Soldering
The soldering iron tip should be shaped like a bamboo spear tip, which makes it easier to place solder on flat surfaces and "scoop up" excess solder.



### 3-2. Installing Diodes
Now let's solder the diodes in order.  
All diodes are soldered on the **back side**.  
  
The diode silk marks are the marks shown by the arrows in the photo below, with a total of 46 pieces on both sides.  
> **⚡️Warning**: Diodes have polarity, so please install them in the correct orientation.  
The orientation is where the straight line on the component matches the straight line at the tip of the arrow in the silk mark.  
> Please check the orientation carefully by looking at the photo below.  
> All diodes on the same board are arranged in the same orientation.  
Please check that the orientation matches the surrounding diodes as you proceed with soldering.


  
The diode silk has black dots as shown in red in the photo below, so you can verify polarity after soldering the diodes.



Let's start soldering.  
First, apply solder to one side of the diode pad.



Grab the diode with tweezers and fix it while melting the pre-applied solder.



Rotate the board 180 degrees and flow solder to the other leg of the diode.  
Finally, touch both legs with the iron tip, and if the diode doesn't fall off, both legs are soldered.

Solder the other leg

Install a total of 46 diodes on both sides.



### 3-3. Soldering LEDs (Optional)
LEDs (YS-SK6812MINI-E) are optional.  
A total of 59 pieces can be installed on both sides.  
However, LEDs are very sensitive to heat, so please adjust the iron tip temperature to **220°C to 280°C**. 
Silver-containing solder or other low-melting point solder works well.  
Since the iron tip temperature is low, heat may not transfer to the pad, making it easy for solder to become "tempura" (poor connection).  
The keyboard can be used without LEDs, and lighting all LEDs is quite difficult.  
We recommend completing it without LEDs first. LEDs can be added later. 

If you're soldering LEDs, this timing is good for workability.

All LEDs are soldered on the **back side**. 
  
Match the leg with the notch on the YS-SK6812MINI-E 4-pin with the marked pad and place the LED for soldering.

LEDs are mixed with upward and downward facing ones, but if you match the pin notch with the marking as shown in the photo below, the up/down orientation will automatically match.

Soldering all 4 pins at once can cause the component temperature to rise and damage it, so please solder 2 pins at a time with intervals.  
For this reason, place about 10 LEDs at once, and move to the next LED soldering after applying solder once.  
This prevents continuously heating one LED.



After all LED soldering is complete, proceed to the next step.  
LED lighting check will be performed later.



### 3-4. Soldering Key Sockets
Key sockets are soldered on the **back side** like diodes.  
Set them to match the silk mark and shape for soldering.  

>**⚡️Warning**: If they protrude from the silk, the orientation is wrong.  
>Please check the correct orientation in the photo below.



If assembling thumb keys in low profile specification, solder low profile sockets to the thumb key locations (5 keys on both sides).  
These low profile sockets also have orientation.

As shown in the photo below, place the terminal with the black resin part in an octagonal shape near the center of the switch.



For soldering, apply solder to one side of the socket pad as shown in the blue circle.



Fit the socket and press down with tweezers from above, then touch the iron tip with a little solder from the side of the terminal, and the solder will melt and the socket will sink.  
Based on experience, this method is least likely to cause "tempura" (poor connection).  



Rotate the board 180 degrees and solder the other terminal.

Solder a total of 44 pieces on both sides.  
For thumb key PCB sockets, either CherryMX compatible sockets or low profile sockets alone are fine.  
※Both are installed in the photo.



### 3-5. Soldering Jumpers
Jumpers need to be shorted to operate the OLED module.

>**⚡️Warning**: Jumper soldering is done **only on the back side**.  
There are "Back Side Only" markings, with [4 pieces each] on the left and right boards.  
Warm the pad with the iron tip, then melt solder to create a bridge.



If you're not confident in soldering or not good at bridge work, try applying solder to the 8 pads first as shown in the photo below.

40b

Adding solder here should make bridging easier.

40b

If the solder freshness deteriorates (heated multiple times), surface tension decreases and bridging becomes difficult.  
Scrape off the solder once and add solder or flux to try again.  
Bridge a total of 8 locations on both sides.

Next, short the jumpers for trackball signal lines.  
Solder the 4 jumpers at the positions shown in the photo below as shown in the photo.  
This is also done **only on the back side**.

40b

Finally, short the left hand detection jumper.  
As shown in the photo below, there's one jumper with **LEFT** marking near the pinky key on the side designated as left hand.  
This is also shorted **only on the back side**.

40b

The completion of all jumper soldering is shown in the photo below.  
Please check that all 4 blue circle areas are soldered.

40b

### 3-6. TRRS Socket, Tactile Switch, and 4-pin Socket
Solder the parts shown in the photo below.  
>**⚡️Warning**: This time all are installed **only on the front side**, so please be careful.  



If you're worried about parts floating, fix them with masking tape or similar for soldering.



When all are installed, it should look like the photo below.



Photo of the back side after soldering.



### 3-7. Soldering ProMicro
ProMicro is soldered using the connector pins shown in the photo below, which makes replacement easier when ProMicro fails.  
Connector pins have installation direction, so please look at the photo carefully for the work.

>⚠️ If ProMicro pin headers + pin sockets are included instead of 12P connectors, please use the [build guide here](https://github.com/Yowkees/keyball/blob/main/keyball44/doc/rev1/buildguide_jp_pinheader.md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).



First, insert the connector pin into the board [front side].

Insert the connector to match the **square silk frame**.  
If the black silk frame is misaligned with the connector, the insertion hole is wrong.



Insert ProMicro into the inserted connector pin.  
Solder **only the ProMicro side** in a state where it's firmly inserted to the end.  
Soldering while inserted into the board prevents the connector pin from being installed at an angle.
>**⚡️Warning**: If you solder the connector pin to the middle PCB side as well, replacement will be very difficult when ProMicro fails.



OLED can be installed on both left and right boards as standard.  
Insert a 4-pin header into the 4-pin socket and place the OLED module.
Then solder **only one** of the 4 pins.  

While melting the solder of the single soldered pin, press the OLED module from above to prevent it from floating.  
Also, adjusting it to be parallel with ProMicro will look better.

Once the position is determined, solder the remaining 3 pins.



### 3-8. ProMicro Programming and Operation Check
Let's write test firmware to ProMicro.   
The test firmware has a keymap layout that's easy to verify operation, and LEDs light up in red→green→blue sequence, making it easy to find problematic areas.  
If you're skipping LED soldering, etc., and don't need test firmware, you can write the official firmware from [Chapter 10](#anchor10) here.

Keyball44 firmware is common regardless of which side the trackball is mounted on.  
Please write (FLASH) the [Keyball_test.hex](https://remap-keys.app/catalog/tAJ9Htme4oNabUkx4832/firmware) registered in REMAP.
Clicking the FLASH button in the link above will display instructions for the writing method.  
If the keyboard is not recognized even with the USB cable connected, try pressing the soldered RESET switch quickly twice.  
※Be sure to write the same hex file to both left and right Pro Micros.

  If you want to directly edit Keyball44 firmware and build it yourself, source files are available in [this repository](https://github.com/Yowkees/keyball/tree/main/qmk_firmware/keyboards/keyball), so please download and use them.

After writing is complete, check that characters are input to a text editor by shorting the key switch pad with tweezers as shown in the photo below. 
The keyboard left and right may be reversed, but that's not a problem for now.  
Please just check that some characters are input and ProMicro is working.  
You don't need to test all keys yet, but checking operation early makes problem isolation easier.  
※Firmware writing must be done for both left and right Pro Micros.  

At this timing, also perform LED lighting check.  
LEDs are wired in series, so it's easy to identify the problematic area if only some light up.

For example, if LEDs up to number 12 light up but LEDs from number 13 onwards don't light up, there's likely a problem with the soldering of [LED number 12 or 13], so please redo the soldering of those LEDs.  
If it still doesn't improve, LED failure is suspected, so please replace LED number 13.

Repeat the lighting check and soldering correction until all LEDs light up.



## 4. Assembling the Trackball Reading Board
Prepare the board shown in the photo below (hereinafter, ball board) and optical sensor.

※For quality confirmation of sensors and boards, pre-soldered ball boards may arrive.  
In that case, skip this step and proceed to L-shaped connector soldering in [Chapter 4-2](#anchor4-2).

  

### 4-1. Soldering the Sensor  

The sensor IC is inserted from the back side where no components are mounted on the ball board.  
>**⚡️Warning**: If the sensor polarity is wrong, repair will be very difficult!  
Please carefully confirm that it's inserted in the correct orientation and from the correct direction before soldering!  
Match the notch indicating pin 1 of the IC with the [1pin] silk on the board.



The IC looks like this from the back.  
Solder all pins from the front side where SMD components are mounted (the side without the Keyball logo).



Use tweezers to peel off the protective seals [2 pieces].



Attach the sensor lens to the side where the protective seals were peeled off.  
The lens has direction, and if the direction is wrong, the two thin pins of the lens may break, so please check the direction carefully.  
There's a protrusion like the arrow in the photo below at the front of the lens, and this should be on the top side when mounting.



If the lens and IC directions match, the two pins of the lens should insert into the IC without force. Please insert slowly.



### 4-2. Soldering the L-shaped Connector
Next, install the L-shaped connector pin on the **front side** of the board where the trackball will be mounted.  
The L-shaped connector also has direction.
Insert the side where the pins are not U-shaped into the middle board for soldering.



Apply masking tape or similar to prevent parts from floating and solder from the back side.



Solder the 7 pins from the back side.



The soldering work is now complete.

As a side note, before turning off the soldering iron, apply plenty of solder to the tip. When you use it next time, if you remove this solder, you can resume work with a shiny tip!



## 5. Cutting the Top Plate (Optional)

Keyball44 can switch 5 thumb keys to choc low profile switches.  
In that case, the plate height for thumb keys changes, so the perforated section of the top plate needs to be cut.

If cutting, use a cutter to make cuts in the perforated sections on both front and back sides, then fold and separate.

If using normal Cherry MX switches for thumb keys, there's no need to cut the board, but if you want to use both, we recommend cutting it.



Polish the cut surface with about 150 grit sandpaper.



## 6. Assembly 

### 6-1. Installing the Protection Plate

Install the ProMicro protection plate on the middle board.
First, screw the 9mm spacer.



Screw the acrylic protection plate to the spacer.

The protection plate shape is common for both trackball and non-trackball sides. There's no front/back.  

  

### 6-2. Assembling the Top Plate

Screw the 7mm spacer to the **back side** of the top plate.  

If assembling thumb keys in low profile specification, attach 4mm spacers to the thumb key top plate.



Insert key switches into the four corners of the top plate and the thumb plate.

This improves the positioning accuracy between plates.



Match the screw holes of the top plate and middle acrylic plate, and stack the plates.



Next, also match the screw holes of the soldered middle board, and stack while confirming that the key switch terminals fit firmly into the key sockets.



### 6-3. Assembling the Bottom Plate

Peel off the protective sheet of the acrylic bottom plate, place it on the back of the main body, and screw it.  
Next, attach cushion rubber to the four corners of the keyboard back.



## 7. Installing the Trackball 

### 7-1. Inserting the Ball Reading Board

Insert the assembled trackball reading board into the 7-pin connector.  
It's shown at an angle for clarity, but insert the board vertically.



The ball board is now standing vertically.



### 7-2. Assembling the Trackball Case

The trackball case has 3 ceramic balls pre-fixed.  
If ceramic balls happen to fall off, please fix the spare ceramic ball with appropriate bond.  
Please keep the spare ceramic ball for future use in case you lose the ball.

Shake the case to check that the ceramic balls don't fall off.



The two pins on the case top can be inserted into the hole in the case bottom.  
Apply force slowly from top and bottom to combine. (It doesn't need to fit perfectly as it will stick together with the subsequent screw tightening.)



Attach M1.7 tapping screws.  
The kit includes **small head screws** and **flat head screws**, but use the **small head screws**.  



From the back of the case, screw these 2 locations.
>**⚡️Warning**: Be careful not to overtighten.



### 7-3. Installing the Trackball Case

Install the completed case to the main body.  
The ball board goes into the sensor storage area on the back of the case.  
While making sure the ball board shown by the arrow is around the center of the case, slowly fit it from above.  
If there's resistance, don't force it in, but pull it out once and try inserting again.

It should go all the way in without much force.



When checking from the back of the main body, there may be a gap as shown by the arrow between the main board and ball board.



In that case, gently push from the front of the case (in the direction of the finger mark).  
Applying too much force may damage the L-shaped connector, so push gently.  
When the gap disappears as shown in the photo below, the screw holes in the blue circle should match.



Tighten the **flat head screws** 2 pieces of M1.7 torx screws included in the kit from the back of the main body.  
At this time, hold the ball holding case with your finger to prevent it from rotating while tightening the screws.



## 8. Final Assembly 

Almost complete! Insert your preferred key switches and keycaps.

Finally, push the 34mm trackball into the case to complete!  
Thank you for your hard work.  



Keyball44 completed

## 9. Writing the Official Firmware 

Now let's write the official firmware to ProMicro as the final step.

Keyball44 is compatible with [ReMAP](https://remap-keys.app/configure), so firmware writing and keymap changes are possible without installing special software. For instructions on using Remap, please refer to the article by [Salicylic Acid's Self-Key Onsen Guide](https://salicylic-acid3.hatenablog.com/entry/remap-manual) for detailed information.  

To use ReMAP, open the [REMAP catalog Keyball44 firmware page](https://remap-keys.app/catalog/tAJ9Htme4oNabUkx4832/firmware) and FLASH (write) the Keyball44_via firmware.

As written in [Chapter 3-7](#anchor3-7), clicking the FLASH button will display instructions for the writing method.
If the keyboard is not recognized even with the USB cable connected, try pressing the soldered RESET switch quickly twice.

>**⚡️Warning**: Be sure to write the same hex file to both left and right Pro Micros.

**If you want to build firmware yourself**   
The latest Keyball44 firmware is published in the [Github repository](https://github.com/Yowkees/keyball/tree/main/qmk_firmware/keyboards/keyball).  
Copy this keyball folder to your QMK_Firmware/keyboards and freely edit keymaps etc. to make.  

## 10. How to Use Keyball♪ 
   - The trackball changes to [up/down/left/right scroll](../../../qmk_firmware/keyboards/keyball/lib/keyball/README.md#scroll-snap-spec) while switched to layer 3.

   - [ReMAP](https://remap-keys.app/configure) allows easy keymap checking, changing, and writing.

   - USB cable can be inserted into either left or right side.  
   However, keymaps are written to the ProMicro on the side where the USB cable is inserted, so please review the keymap when switching for the first time.

   - Specially prepared keycodes for the Keyball series are arranged in layer 3.  
   They can be used to change the trackball to scroll, or change cursor speed and scroll speed.  
   For details, please refer to the [Keycode List](../../../qmk_firmware/keyboards/keyball/lib/keyball/keycodes.md#japanese).

   >**⚡️Warning**: Disconnecting the TRS cable while Keyball is connected to PC (powered on) can cause malfunction.  
   When disconnecting/connecting the TRS cable, always disconnect the USB cable first.

This concludes the Keyball44 build guide.  
For questions or issues about Keyball44, please post to the Github repository, [Yowkees/keyball Discussions](https://github.com/Yowkees/keyball/discussions).  
We will respond as quickly as possible.

―Acknowledgments―  
Thanks to the tremendous cooperation of [KoRoN@Kaoriya](https://www.kaoriya.net/), the Keyball44 firmware has significantly improved trackball operation smoothness, and the substantial memory reduction allows enjoyment of many LED actions. With such wonderful firmware created quickly, we were able to start selling Keyball44 very smoothly. I would like to express my deep gratitude here. Thank you very much.
　@Yowkees

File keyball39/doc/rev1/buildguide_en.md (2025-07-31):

# Build Guide for Keyball39

This guide provides detailed instructions for assembling the Keyball39.  
※This guide uses photos of the white PCB version of Keyball39, but the same procedure applies to the black PCB version.  
Sections that require special attention for black PCB sets are marked with ⚫️ at the beginning.

**日本語版のKeyball39ビルドガイドは[こちら](buildguide_jp2.md)です。**



## 【Table of Contents】

> **Preparation**
 - [1. Parts Check](#anchor1)
   - [1-1. Kit Contents](#anchor1-1)
   - [1-2. Parts You Need to Prepare Yourself Before Assembly](#anchor1-2)
   - [1-3. Parts and Options That Can Be Installed After Assembly](#anchor1-3)
 - [2. Preparation](#anchor2)
   - [2-1. Required Tools](#anchor2-1)
   - [2-2. Firmware](#anchor2-2)

> **Implementation**
 - [3. Implementation](#anchor3)
   - [3-1. Before Soldering](#anchor3-1)
   - [3-2. Installing Diodes](#anchor3-2)
   - [3-3. Soldering LEDs (Optional)](#anchor3-3)
   - [3-4. Soldering Key Sockets](#anchor3-4)
   - [3-5. Soldering Jumpers](#anchor3-5)
   - [3-6. TRRS Socket, Tactile Switch, and 4-pin Socket](#anchor3-6)
   - [3-7. Soldering ProMicro](#anchor3-7)
   - [3-8. ProMicro Programming and Operation Check](#anchor3-8)
 - [4. Assembling the Trackball Reading Board](#anchor4)
   - [4-1. Soldering the Sensor](#anchor4-1)
   - [4-2. Soldering the L-shaped Connector](#anchor4-2)
 - [5. Soldering the Left-Right Detection Jumper on the Left Side](#anchor5)
 - [6. Cutting the Top Plate (Optional)](#anchor6)

> **Assembly**
 - [7. Assembly](#anchor7)
   - [7-1. Installing the Protection Plate](#anchor7-1)
   - [7-2. Assembling the Top Plate](#anchor7-2)
   - [7-3. Assembling the Bottom Plate](#anchor7-3)
 - [8. Installing the Trackball](#anchor8)
   - [8-1. Inserting the Ball Reading Board](#anchor8-1)
   - [8-2. Assembling the Trackball Case](#anchor8-2)
   - [8-3. Installing the Trackball Case](#anchor8-3)

> **Finishing**
 - [9. Final Assembly](#anchor9)
 - [10. Writing the Official Firmware](#anchor10)
 - [11. How to Use Keyball♪](#anchor11)

## 1. Parts Check

Please check that all kit contents are included when your kit arrives.

### 1-1. Kit Contents

The standard set can accommodate one thumb trackball on either the left or right side.

Single-hand kits are also available for dual-ball specifications with trackballs on both sides, or for assembly without trackballs on either side.

If you purchased a single-hand set or dual-ball set, please check the included parts list in your kit for the contents.

 ⚠️ If ProMicro pin headers + pin sockets are included instead of 12P connectors, please use the [build guide here](https://github.com/Yowkees/keyball/blob/main/keyball39/doc/rev1/buildguide_jp_pinheader.md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).

**Keyball39 Standard Kit Contents**
| Part Name | Quantity | Notes |
|:---|:----:|:-----|
| Middle PCB (Left/Right) | 1 set | Main board |
| Top PCB Plate (Left/Right) | 1 set | For key switch mounting |
| Middle Acrylic Plate (Left/Right)| 1 set | For key switch mounting |
| Bottom Acrylic Plate (Left/Right) | 1 set | Bottom cover |
| ProMicro Protection Plate | 2 pieces | For board protection |
| Trackball Holding Case (Top/Bottom) | 1 set | For ball mounting |
| Φ2 Ceramic Ball | 1 piece | Spare |
| Trackball Reading Board | 1 piece | Sensor board |
| L-shaped Connector Pin (7-pin) | 1 piece | For sensor connection |
| Trackball Reading IC | 1 piece | PMW3360 |
| Reading IC Lens | 1 piece | Optical lens |
| Flat Head Tapping Screw M1.7 | 2 pieces | For trackball case mounting |
| Small Head Tapping Screw M1.7 | 2 pieces | For trackball case assembly |
| TRRS Jack | 2 pieces | For left/right connection |
| Tactile Switch | 2 pieces | For reset |
| Straight Connector Pin (12-pin) | 4 pieces | For ProMicro connection |
| Diode (SMD type) | 50+ pieces | For key matrix error prevention |
| Kailh PCB Socket CherryMX compatible | 42+ pieces | For key switches |
| Kailh PCB Socket choc compatible| 5 pieces | Used when modifying thumb keys to low profile |
| OLED Module | 2 pieces | Display |
| 4-pin Header  | 2 pieces | For OLED connection |
| 4-pin Socket | 2 pieces | For OLED connection |
| Spacer M2 7mm | 13+ pieces | Standard spacers |
| Spacer M2 9mm | 4 pieces | For height adjustment |
| Spacer M2 4mm | 5 pieces | Used for thumb low profile specification |
| Screw M2 3.5mm | 34+ pieces | For plate mounting |
| Cushion Rubber | 4 pieces | For bottom anti-slip |



### 1-2. Parts You Need to Prepare Yourself Before Assembly

The following parts are not included in the kit and need to be purchased separately.

| Part Name | Quantity | Notes |
|:---|:----:|:-----|
| ProMicro | 2 pieces | You can choose inexpensive ones or USB Type-C compatible ones |
| CherryMX Compatible Key Switches | 39 pieces | 34 pieces if using thumb low profile specification |
| Low Profile Key Switches | 5 pieces | Only if using thumb low profile specification |
| 34mm Diameter Trackball | 1 piece | Required when using trackball |
| TRS (3-pole) Cable | 1 piece | TRRS (4-pole) cable is also acceptable |
| Micro USB Cable | 1 piece | Compatible with the ProMicro you purchased |



### 1-3. Parts and Options That Can Be Installed After Assembly

The following parts can be installed after assembly and can be customized according to your preferences.

| Part Name | Quantity | Notes |
|:---|:----:|:-----|
| Keycaps | 39 pieces | 1u 39 pieces |
| Low Profile Keycaps | 5 pieces | Only for thumb low profile specification - 1u 5 pieces |
| YS-SK6812MINI-E | 46 pieces | ※SK6812MINI cannot be used |



## 2. Preparation

### 2-1. Required Tools

The following tools are required for assembling Keyball39. Please check that you have all of them.

| Tool Name | Purpose |
|:---|:-----|
| Soldering Iron (Temperature adjustable if implementing LEDs) | Soldering work |
| Solder (Low melting point is effective if implementing LEDs) | For connections |
| #0 + Precision Driver | For screw tightening |
| Tweezers | For handling parts |
| 150 grit sandpaper | For polishing when cutting plates |



### 2-2. Firmware

To operate Keyball39, firmware needs to be written to the ProMicro you purchased.

 Pre-built firmware can be easily written using [REMAP](https://remap-keys.app/), a web-based keyboard management software.
 
 Writing is explained in detail in [Chapter 3-7](#anchor3-7) for test firmware writing and [Chapter 10](#anchor10) for production firmware writing.

## 3. Implementation

Now we begin soldering work. 

 The PCB is reversible, so first decide which side will be left/right hand.  
 When operating the trackball with your right thumb, the trackball will be attached to the area where the PCB is cut, as shown in the red circle in the photo below.    



When operating the trackball with your left thumb, the layout is as shown in the photo below. 



This build guide explains the specification with the trackball on the right hand.  
>**⚡️ Warning**: If you solder the wrong side, rework will be very difficult.  
>Please mark the front side with masking tape or similar as shown in the photo below to prevent mistakes.



⚫️ For black PCB sets, you can optionally fill the sides of the top PCB and middle PCB with a black marker for a cleaner finish.



### 3-1. Before Soldering
The soldering iron tip should be shaped like a bamboo spear tip, which makes it easier to place solder on flat surfaces and "scoop up" excess solder.



### 3-2. Installing Diodes
Now let's solder the diodes in order.  
All diodes are soldered on the **back side**.  
  
The diode silk marks are the marks shown by the arrows in the photo below, with a total of 45 pieces on both sides.  
> **⚡️Warning**: Diodes have polarity, so please install them in the correct orientation.  
The orientation is where the straight line on the component matches the straight line at the tip of the arrow in the silk mark.  
> Please check the orientation carefully by looking at the photo below.  
> All diodes on the same board are arranged in the same orientation.  
Please check that the orientation matches the surrounding diodes as you proceed with soldering.


  
The diode silk has black dots as shown in red in the photo below, so you can verify polarity after soldering the diodes.



Let's start soldering.  
First, apply solder to one side of the diode pad.



Grab the diode with tweezers and fix it while melting the pre-applied solder.



Rotate the board 180 degrees and flow solder to the other leg of the diode.  
Finally, touch both legs with the iron tip, and if the diode doesn't fall off, both legs are soldered.

Solder the other leg

Install a total of 45 diodes on both sides.



### 3-3. Soldering LEDs (Optional)
LEDs (YS-SK6812MINI-E) are optional.  
A total of 46 pieces can be installed on both sides.  
However, LEDs are very sensitive to heat, so please adjust the iron tip temperature to **220°C to 280°C**.  
Since the iron tip temperature is low, heat may not transfer to the pad, making it easy for solder to become "tempura" (poor connection).  
The keyboard can be used without LEDs, and lighting all LEDs is quite difficult.  
We recommend completing it without LEDs first. LEDs can be added later.

All LEDs are soldered on the **back side**. 
  
Match the leg with the notch on the YS-SK6812MINI-E 4-pin with the marked pad and place the LED for soldering.

LEDs are mixed with upward and downward facing ones, but if you match the pin notch with the marking as shown in the photo below, the up/down orientation will automatically match.

Soldering all 4 pins at once can cause the component temperature to rise and damage it, so please solder 2 pins at a time with intervals.  
For this reason, place about 10 LEDs at once, and move to the next LED soldering after applying solder once.  
This prevents continuously heating one LED.



After soldering is complete, connect the USB cable and check the lighting. 

LEDs are wired in series, so it's easy to identify the problematic area if only some light up.

For example, if LEDs up to number 12 light up but LEDs from number 13 onwards don't light up, there's likely a problem with the soldering of [LED number 12 or 13], so please redo the soldering of those LEDs.  
If it still doesn't improve, LED failure is suspected, so please replace LED number 13.

Repeat the lighting check and soldering correction until all LEDs light up.



### 3-4. Soldering Key Sockets
Key sockets are soldered on the **back side** like diodes.  
Set them to match the silk mark and shape for soldering.  

>**⚡️Warning**: If they protrude from the silk, the orientation is wrong.  
>Please check the correct orientation in the photo below.



If assembling thumb keys in low profile specification, solder low profile sockets to the thumb key locations (5 keys on both sides).  
These low profile sockets also have orientation.

As shown in the photo below, place the terminal with the black resin part in an octagonal shape near the center of the switch.



For soldering, apply solder to one side of the socket pad as shown in the blue circle.



Fit the socket and press down with tweezers from above, then touch the iron tip with a little solder from the side of the terminal, and the solder will melt and the socket will sink.  
Based on experience, this method is least likely to cause "tempura" (poor connection).  



Rotate the board 180 degrees and solder the other terminal.

Solder a total of 39 pieces on both sides.  
For thumb key PCB sockets, either CherryMX compatible sockets or low profile sockets alone are fine.  
※Both are installed in the photo.



### 3-5. Soldering Jumpers
Jumpers need to be shorted to operate the OLED module.

>**⚡️Warning**: Jumper soldering is done **only on the back side**.  
There are "Back Side Only" markings, with [4 pieces each] on the left and right boards.  
Warm the pad with the iron tip, then melt solder to create a bridge.



If you're not confident in soldering or not good at bridge work, try applying solder to the 8 pads first as shown in the photo below.

40b

Adding solder here should make bridging easier.

40b

If the solder freshness deteriorates (heated multiple times), surface tension decreases and bridging becomes difficult.  
Scrape off the solder once and add solder or flux to try again.  
When bridging is successful, it should look like the photo below.
Bridge a total of 8 locations on both sides.

There are other jumpers, but these will be explained later, so please solder only 4 locations each on the left and right for now.

### 3-6. TRRS Socket, Tactile Switch, and 4-pin Socket
Solder the parts shown in the photo below.  
>**⚡️Warning**: This time all are installed **only on the front side**, so please be careful.  



If you're worried about parts floating, fix them with masking tape or similar for soldering.



When all are installed, it should look like the photo below.



### 3-7. Soldering ProMicro
ProMicro is soldered using the connector pins shown in the photo below, which makes replacement easier when ProMicro fails.  
Connector pins have installation direction, so please look at the photo carefully for the work.

>⚠️ If ProMicro pin headers + pin sockets are included instead of 12P connectors, please use the [build guide here](https://github.com/Yowkees/keyball/blob/main/keyball39/doc/rev1/buildguide_jp_pinheader.md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).



First, insert the connector pin into the board [front side].



Insert the connector to match the **square silk frame**.  
If the black silk frame is misaligned with the connector, the insertion hole is wrong.



Insert ProMicro into the inserted connector pin.  
Solder **only the ProMicro side** in a state where it's firmly inserted to the end.  
Soldering while inserted into the board prevents the connector pin from being installed at an angle.
>**⚡️Warning**: If you solder the connector pin to the middle PCB side as well, replacement will be very difficult when ProMicro fails.



OLED can be installed on both left and right boards as standard.  
Insert a 4-pin header into the 4-pin socket and place the OLED module.
Then solder **only one** of the 4 pins.  

While melting the solder of the single soldered pin, press the OLED module from above to prevent it from floating.  
Also, adjusting it to be parallel with ProMicro will look better.

Once the position is determined, solder the remaining 3 pins.



### 3-8. ProMicro Programming and Operation Check
Let's write test firmware to ProMicro.   
The test firmware has a keymap layout that's easy to verify operation, and LEDs light up in red→green→blue sequence, making it easy to find problematic areas.  
If you're skipping LED soldering, etc., and don't need test firmware, you can write the official firmware from [Chapter 10](#anchor10) here.

Keyball39 firmware is common regardless of which side the trackball is mounted on.  
Please write (FLASH) the [Keyball_test.hex](https://remap-keys.app/catalog/k895xiCpsM5zlYZCPTEN/firmware) registered in REMAP.  
Clicking the FLASH button in the link above will display instructions for the writing method.  
If the keyboard is not recognized even with the USB cable connected, try pressing the soldered RESET switch quickly twice.  
※Be sure to write the same hex file to both left and right Pro Micros.

  If you want to directly edit Keyball39 firmware and build it yourself, source files are available in [this repository](https://github.com/Yowkees/keyball/tree/main/qmk_firmware/keyboards/keyball), so please download and use them.

After writing is complete, check that characters are input to a text editor by shorting the key switch pad with tweezers as shown in the photo below. 
The keyboard left and right may be reversed, but that's not a problem for now.  
Please just check that some characters are input and ProMicro is working.  
You don't need to test all keys yet, but checking operation early makes problem isolation easier.  
※Firmware writing must be done for both left and right Pro Micros.



## 4. Assembling the Trackball Reading Board
Prepare the board shown in the photo below (hereinafter, ball board) and optical sensor.

※For quality confirmation of sensors and boards, pre-soldered ball boards may arrive.  
In that case, skip this step and proceed to L-shaped connector soldering in [Chapter 4-2](#anchor4-2).

  

### 4-1. Soldering the Sensor  

The sensor IC is inserted from the back side where no components are mounted on the ball board.  
>**⚡️Warning**: If the sensor polarity is wrong, repair will be very difficult!  
Please carefully confirm that it's inserted in the correct orientation and from the correct direction before soldering!  
Match the notch indicating pin 1 of the IC with the [1pin] silk on the board.



The IC looks like this from the back.  
Solder all pins from the front side where SMD components are mounted (the side without the Keyball logo).



Use tweezers to peel off the protective seals [2 pieces].



Attach the sensor lens to the side where the protective seals were peeled off.  
The lens has direction, and if the direction is wrong, the two thin pins of the lens may break, so please check the direction carefully.  
There's a protrusion like the arrow in the photo below at the front of the lens, and this should be on the top side when mounting.



If the lens and IC directions match, the two pins of the lens should insert into the IC without force. Please insert slowly.



### 4-2. Soldering the L-shaped Connector
Next, install the L-shaped connector pin on the **front side** of the board where the trackball will be mounted.  
The L-shaped connector also has direction.
Insert the side where the pins are not U-shaped into the middle board for soldering.



Apply masking tape or similar to prevent parts from floating and solder from the back side.



Next, solder the 4 jumpers for optical sensor signal lines.
>**⚡️Warning**: There are jumpers near the soldered connector, so apply solder to **only the back side** and short them as shown in the photo below.



## 5. Soldering the Left-Right Detection Jumper on the Left Side

>**⚡️Warning**: The standard Keyball39 firmware has a function to automatically detect the left/right of the keyboard.  
For detection, solder a jumper at **one location only on the left side board**.  

When looking at the left side board from the back, there's a **LEFT** silk as shown in the red circle in the photo below.  
Please solder the jumper next to this to short it.



If mounting the trackball on the left side, the position is slightly different, and the LEFT jumper will be at the position shown in the photo below.

>**⚡️Warning**: Be sure to jumper **only the left side board**.



The soldering work is now complete.

As a side note, before turning off the soldering iron, apply plenty of solder to the tip. When you use it next time, if you remove this solder, you can resume work with a shiny tip!



## 6. Cutting the Top Plate (Optional)

Keyball39 requires cutting the perforated thumb key section of the top plate for assembly.  
Use a cutter to make cuts in the perforated sections on both front and back sides, then fold and separate.



Polish the cut surface with about 150 grit sandpaper.



## 7. Assembly 

### 7-1. Installing the Protection Plate

Install the ProMicro protection plate on the middle board.
First, screw the 9mm spacer.



Screw the acrylic protection plate to the spacer.

The protection plate shape is common for both trackball and non-trackball sides. There's no front/back.  

  

### 7-2. Assembling the Top Plate

Screw the 7mm spacer to the **back side** of the top plate.  

If assembling thumb keys in low profile specification, attach 4mm spacers to the thumb key top plate.



Insert key switches into the four corners of the top plate and the thumb plate.

This improves the positioning accuracy between plates.



Match the screw holes of the top plate and middle acrylic plate, and stack the plates.



Next, also match the screw holes of the soldered middle board, and stack while confirming that the key switch terminals fit firmly into the key sockets.



### 7-3. Assembling the Bottom Plate

※Previously there were donut-shaped acrylic spacers, but they were discontinued because the effect couldn't be obtained due to variations in acrylic thickness.  
If acrylic spacers are included in your kit, please discard them.

Peel off the protective sheet of the acrylic bottom plate, place it on the back of the main body, and screw it.  
Next, attach cushion rubber to the four corners of the keyboard back.

## 8. Installing the Trackball 

### 8-1. Inserting the Ball Reading Board

Insert the assembled trackball reading board into the 7-pin connector.  
It's shown at an angle for clarity, but insert the board vertically.



The ball board is now standing vertically.



### 8-2. Assembling the Trackball Case

The trackball case has 3 ceramic balls pre-fixed.  
If ceramic balls happen to fall off, please fix the spare ceramic ball with appropriate bond.  
Please keep the spare ceramic ball for future use in case you lose the ball.

Shake the case to check that the ceramic balls don't fall off.



The two pins on the case top can be inserted into the hole in the case bottom.  
Apply force slowly from top and bottom to combine. (It doesn't need to fit perfectly as it will stick together with the subsequent screw tightening.)



Attach M1.7 tapping screws.  
The kit includes **small head screws** and **flat head screws**, but use the **small head screws**.  



From the back of the case, screw these 2 locations.
>**⚡️Warning**: Be careful not to overtighten.



### 8-3. Installing the Trackball Case

Install the completed case to the main body.  
The ball board goes into the sensor storage area on the back of the case.  
While making sure the ball board shown by the arrow is around the center of the case, slowly fit it from above.  
If there's resistance, don't force it in, but pull it out once and try inserting again.

It should go all the way in without much force.



When checking from the back of the main body, there may be a gap as shown by the arrow between the main board and ball board.



In that case, gently push from the front of the case (in the direction of the finger mark).  
Applying too much force may damage the L-shaped connector, so push gently.  
When the gap disappears as shown in the photo below, the screw holes in the blue circle should match.



Tighten the **flat head screws** 2 pieces of M1.7 torx screws included in the kit from the back of the main body.  
At this time, hold the ball holding case with your finger to prevent it from rotating while tightening the screws.



## 9. Final Assembly 

Almost complete! Insert your preferred key switches and keycaps.

Finally, push the 34mm trackball into the case to complete!  
Thank you for your hard work.  



Keyball39 completed

## 10. Writing the Official Firmware 

Now let's write the official firmware to ProMicro as the final step.

Keyball39 is compatible with [ReMAP](https://remap-keys.app/configure), so firmware writing and keymap changes are possible without installing special software. For instructions on using Remap, please refer to the article by [Salicylic Acid's Self-Key Onsen Guide](https://salicylic-acid3.hatenablog.com/entry/remap-manual) for detailed information.  

To use ReMAP, open the [REMAP catalog Keyball39 firmware page](https://remap-keys.app/catalog/k895xiCpsM5zlYZCPTEN/firmware) and FLASH (write) the Keyball39_via firmware.

As written in [Chapter 3-7](#anchor3-7), clicking the FLASH button will display instructions for the writing method.
If the keyboard is not recognized even with the USB cable connected, try pressing the soldered RESET switch quickly twice.

>**⚡️Warning**: Be sure to write the same hex file to both left and right Pro Micros.

**If you want to build firmware yourself**   
The latest Keyball39 firmware is published in the [Github repository](https://github.com/Yowkees/keyball/tree/main/qmk_firmware/keyboards/keyball).  
Copy this keyball folder to your QMK_Firmware/keyboards and freely edit keymaps etc. to make.  

## 11. How to Use Keyball♪ 
   - The trackball changes to [up/down/left/right scroll](../../../qmk_firmware/keyboards/keyball/lib/keyball/README.md#scroll-snap-spec) while switched to layer 3.

   - [ReMAP](https://remap-keys.app/configure) allows easy keymap checking, changing, and writing.

   - USB cable can be inserted into either left or right side.  
   However, keymaps are written to the ProMicro on the side where the USB cable is inserted, so please review the keymap when switching for the first time.

   - Specially prepared keycodes for the Keyball series are arranged in layer 3.  
   They can be used to change the trackball to scroll, or change cursor speed and scroll speed.  
   For details, please refer to the [Keycode List](../../../qmk_firmware/keyboards/keyball/lib/keyball/keycodes.md#japanese).

   >**⚡️Warning**: Disconnecting the TRS cable while Keyball is connected to PC (powered on) can cause malfunction.  
   When disconnecting/connecting the TRS cable, always disconnect the USB cable first.

This concludes the Keyball39 build guide.  
For questions or issues about Keyball39, please post to the Github repository, [Yowkees/keyball Discussions](https://github.com/Yowkees/keyball/discussions).  
We will respond as quickly as possible.

―Acknowledgments―  
Thanks to the tremendous cooperation of [KoRoN@Kaoriya](https://www.kaoriya.net/), the Keyball39 firmware has significantly improved trackball operation smoothness, and the substantial memory reduction allows enjoyment of many LED actions. With such wonderful firmware created quickly, we were able to start selling Keyball39 very smoothly. I would like to express my deep gratitude here. Thank you very much.
　@Yowkees

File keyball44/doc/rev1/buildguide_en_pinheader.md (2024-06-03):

# Build Guide for Keyball44

This is the build guide for Keyball44.

●[日本語のビルドガイドはこちら](https://github.com/Yowkees/keyball/blob/main/keyball44/doc/rev1/buildguide_jp.md).



## 【Contents of Build Guide for Keyball44】

  - [1. Parts Check](#1)
    - [1-1. Items included in the kit](#1-1)
    - [1-2. Parts to be prepared by the customer before assembly](#1-2)
    - [1-3. Parts and options that can be installed after assembly](#1-3)
  - [2. Preparation](#2)
    - [2-1. Required Tools](#2-1)
    - [2-2．Firmware](#2-2)
  - [3. Mounting](#3)
    - [3-1. Before Soldering](#3-1)
    - [3-2. Soldering the Diodes](#3-2)
    - [3-3. Soldering LEDs (option)](#3-3)
    - [3-4. Soldering the key socket](#3-4)
    - [3-5. Soldering Jumpers](#3-5)
    - [3-6. 4 pin sockets, TRRS socket, tact switch](#3-6)
    - [3-7. Soldering ProMicro and OLED](#3-7)
    - [3-8. Writing and operation check of ProMicro](#3-8)
  - [4. Assemble the ball reader board](#4)
    - [4-1. Soldering the sensor](#4-1)
  - [5. Soldering the L-shaped spring-loaded pin headers](#5)
  - [6. Cut the top plate (option)](#6)
  - [7. Assembly](#7)
    - [7-1. Assemble the Top Plate](#7-1)
    - [7-2. Assemble the Bottom Plate](#7-2)
    - [7-3. Install the protection plate](#7-3)
  - [8. Trackball Installation](#8)
    - [8-1. Insert ball reader board](#8-1)
    - [8-2. Assemble the trackball case](#8-2)
    - [8-3. Trackball Case Installation](#8-3)
  - [9. Finishing](#9)
  - [10. Write the official firmware](#10)
  - [11. How to use Keyball](#11)

## 1. Parts Check

When you receive your kit, please make sure whether all the items included in the kit.

### 1-1. Items included in the kit

The Keyball44 has one Trackball that can be attached on Right or Left side.

Included parts in the Keyball44 Standard Kit are the following

*If your kit includes 12P conthru pinheaders instead of 12P pinsockets, please see [this buildguide](https://github.com/Yowkees/keyball/blob/main/keyball44/doc/rev1/buildguide_en.md#1-1).

| Name | Number | Note |
|:-|:-|:-|
| Middle PCBs (left and right) | 1 set | |
| Top PCB plates (left and right) | 1 set | |
| Middle Acrylic plates (left and right) | 1 set | Main and Thumb plates |
| Bottom Acrylic plates (left and right) | 1 set | |
| ProMicro protection plate (left and right) | 1 set ||
| Trackball holding case white (top and bottom) | 1 set ||
| Φ2 Ceramic ball (spare) | 1 pcs ||
| Trackball reader circuit board | 1 plate ||
| Trackball readout IC | 1 pcs ||
| Lense for Trackball readout IC | 1 pcs ||
| L-shaped Conthrough pin (7-pin) | 1 pcs ||
| Flat head screw M1.7 | 2 pcs ||
| Small head screw M1.7 | 2 pcs ||
| TRRS Jack | 2 pcs ||
| Tact Switch | 2 pcs ||
| Pinheader and Pinsockets for ProMicro (12 pin) | 4 sets | |
| Diodes (Surface mounting type) | more 50 pcs ||
| Kailh PCB Socket for Cherry MX | more 44 pcs ||
| Kailh PCB Socket for choc | 5 pcs | For Thumb low-profile modification |
| OLED module | 2 pcs ||
| Pin header for OLED (4 pin) | 2 pcs ||
| Pin socket for OLED (4 pin) | 2 pcs ||
| Spacer M2 7mm | more 14 pcs ||
| Spacer M2 11mm | 4 pcs ||
| Spacer M2 4mm | 4 pcs | For Thumb low-profile modification |
| Screws M2 3.5mm | more 36 pcs + ||
| Cushion rubber | 10 pcs ||



### 1-2．Parts to be prepared by customers themselves before assembly

| Name | Number | Note |
|:-|:-|:-|
| ProMicro | 2 pcs |  You can choose from inexpensive ones or USB Type-C supported ones. |
| CherryMX Compatible Key Switches | 44 pcs | 39 pcs for Thumb low-profile |
| Low-profile choc Key Switches | 5  pcs | For Thumb low-profile |
| Trackball (34mm diameter) | 1 pc | Used to check operation |
| TRS (3-pole) cable | 1 cable | TRRS (4-pole) cable is also acceptable |
| Micro USB cable | 1 cable | Compatible with ProMicro you purchased |



### 1-3． Parts and options that can be installed even after assembled.

| Name | Number | Note |
|:-|:-|:-|
| CherryMX Compatible Keycaps | 44  pcs | 1u size x 44 pcs |
| Low-profile choc Keycaps | 5 pcs | For Thumb low-profile |
| [YS-SK6812MINI-E](https://shirogane-lab.net/items/64b8f178cbce52004b9555f9) | 59 pcs | *Notice: Cannot be used with SK6812MINI. |

## ２．Preparation

### 2-1．Required tools

You will need the following tools to assemble the Keyball44.

| Name |
|:-|
| Soldering iron (with adjustable temperature if you are mounting LEDs) |
| Solder (low melting point is effective when mounting LEDs) 
| No. 0 + precision screwdriver |
| Tweezers |
| cutter |
| Sandpaper of about 150-grit |



### 2-2．Firmware

In order for the Keyball44 to work, the firmware must be written to the ProMicro that you purchased.
Already-built firmware is available for easy writing with [REMAP](https://remap-keys.app/)a web-based keyboard management software.

Writing is explained in detail in [Chapter 3-8](#3-8Promicro Writing and Operation Verification) and [Chapter 10](#10 Writing the Firmware for the Product Version).

## ３. Mounting parts

Now it's time to start the soldering process.    
The PCB is reversible, so you first need to decide which one is for the left hand and which one is for the right hand.   

The trackball will be attached to the PCB missing position, indicated by the red circle.  
If you want to use your right thumb to control the trackball, Placement will look like the picture below.   



If you operate the trackball with your left hand, Placement is as shown in the picture below.  



In this build guide, we will use the specification to put the trackball on the right hand.  
Place the PCB as shown below, and put masking tape on the surface to prevent mistakes.
I wanted to write "TOP FACE" on masking tape.



### 3-1．Before soldering
The tip of the soldering iron should be shaped like a bamboo spear, so that you can put solder on a flat surface and scoop out excess solder.



### 3-2．Soldering the diodes
Now let's solder the diodes one by one.   
All the diodes should be soldered on 【BACK SIDE ONLY】.  
  
The silk marks on the diodes look like the arrows in the picture below. There are 45 diodes in total.  
Diodes have polarity, so be sure to install them in the correct orientation. The orientation is the direction where the straight line on the component matches the straight line on the end of the arrow on the silk mark.  

Look carefully at the picture below to confirm the orientation.  
All the diodes on the same board are oriented in the same direction, except for the diodes that are rotated 90 degrees. As you proceed with the soldering, make sure that the diodes are facing the same direction as the diodes around them.


  
The diode silk is marked with a black dot as shown in red in the following photo. So you can check the polarity even after the diode is soldered.



Aligning the diodes and counting the number of diodes before soldering will prevent reversing or forgetting to solder the diodes.

Twenty-two diodes are aligned near the board on the side with the trackball, and 24 diodes are aligned near the board on the side without the trackball.



Now let's start soldering. At first, put some solder on one side of the diode pad.



Grab the diode with tweezers and hold it in place while you melt the solder that was previously applied.



Rotate the board 180 degrees and apply solder to the legs on the other side of the diode.
Finally, touch both legs with a soldering tip, and if the diode does not fall out, both legs are soldered.

Soldering other side

Install a total of 46 diodes on the left and right sides.

Please check the diode in the blue circle in the photo below, as we often forget to attach the diode.



### 3-3．Soldering the LEDs (optional)
LEDs (YS-SK6812MINI-E) are option.It is not included in the kit and should be obtained from[here](https://shirogane-lab.net/items/64b8f178cbce52004b9555f9)or other sources.

A total of 59 LEDs can be installed on both sides.

However, LEDs are very sensitive to heat, so adjust the soldering iron temperature from 220°C to 280°C, before soldering.

Since the tip temperature is low, the heat will not be transferred to the pad and it is easy to be failure soldering.  
The keyboard can be used without LEDs. I recommend to complete the project without LEDs first. You can add LEDs later.  

If LEDs are to be soldered, this is a good time to work with them.

Please note that all LEDs are soldered on the 【BACK SIDE】
  
Place the LED on the YS-SK6812MINI-E and solder by aligning the notched leg of the four pins of the YS-SK6812MINI-E with the marked pad.

Some LED faces up and some LED faces down, but as long as the notches and markings on the pins are aligned as shown in the photo below, the top and bottom will automatically align.

Soldering all four pins at once will cause the component to overheat and break easily, so solder two pins at a time. To do this, put about 10 LEDs on the board at a time, and once the solder is applied, move on to soldering the next LED. This way you can avoid continually applying heat to one LED.



When all LEDs have been soldered, we cannot yet confirm that the LEDs are lit at this time, so we proceed to the next step.



### 3-4．Soldering the key socket
The key socket is soldered on the 【BACK SIDE】 as diodes.

Set the key socket. Key socket's shape matches the silk mark, and solder it.  
If it protrudes from the silk, the direction is wrong.



When assembling with thumb low-profile specifications, solder low-profile sockets to the thumb keys (Total 5 keys). This low-profile socket also has a direction.

Please confirm the direction with the following pictures. The correct direction is that the terminal with the black plastic part close to the octagonal shape is near the middle of the switch.



First, insert the PCB socket in the correct orientation before soldering.



While warming the socket terminals, melt the solder from the direction of the red arrow (the other side).      



If you apply a tip with a little solder on it from the side of the terminal and hold the socket by tweezers from above, the solder will melt and the socket will sink.  
In my experience, this method is the least likely to result in a poor connection.  



Rotate the board 180 degrees and solder the terminals on the other side in the same way.

44 of these are soldered on the left and right sides together, This task is finished.
The PCB socket for the thumb keys can be just either a CherryMX compatible socket or a low-pro socket. In the photo, both are attached.



### 3-5. Soldering the jumpers
You need to short the jumpers to control the OLED module and trackball sensor.

The jumper is soldered on __【Back Side Only】__.  

First, short the jumper for the OLED.

"Back Side Only" is indicated, and there are 【4】 each on the left and right boards, so jumper them all.

The photo below shows the two left sides jumpered.
The pattern has been changed to a triangle type pattern for easier bridging.

You can bridge the pads by heating them with an iron tip to melt the solder.



If the solder is not fresh enough, the surface tension will drop and it will not bridge properly.
In this case, remove the solder and add more fresh solder or flux and try again.

Next, short the jumpers on the signal line for the trackball.
Solder the four jumpers in the positions shown in the photo below as shown in the photo. This is also done only on the [back side].



Finally, short the left hand judgment jumper.
There should be one jumper near the pinky key on the left-hand side of the board that is labeled LEFT, as shown in the photo below. Short-circuit this as well, but only on the back side.



The photo below shows all jumpers soldered in place.

Make sure that all four blue circles are soldered.



### 3-6．TRRS Socket・Tact Swicth・4-pin Socket
Solder the components shown in the photo below.  
Mount all of them on the __【TOP SURFACE】__.  



If you are worried about the parts floating around or moving, fix them with masking tape before soldering.

Note that too much solder (too long working time) when soldering a pin socket may cause the solder to flow inside the pin socket and prevent the pin header from sticking.
If you feel that solder is being sucked into a through-hole, finish soldering that pin and move on to the next pin.



When all are installed, it will look like the photo below.



Insert the component from the [front side] and solder the [back side] as shown in the photo below.



### 3-7．Soldering of ProMicro and OLED
ProMicro by soldering using pin sockets and pin headers for ProMicro,Facilitates replacement in the event of ProMicro failure.
【The pin headers included with ProMicro are not used】

If 12P Conthrough were included instead of pin headers + pin sockets for ProMicro[【here】](https://github.com/Yowkees/keyball/blob/main/keyball44/doc/rev1/buildguide_en.md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)Please use this build guide.

First, insert the Conthrough pin headers on【TOP FACE】 of board.

Insert the conslue so that it fits the square frame of the silk. If the black frame of the silk is out of alignment with the conslue, the hole to insert is wrong.



Secure the pin socket with masking tape or other means to prevent it from floating or falling out.



Turn the board over and solder on the [back side] and fix the pin sockets.
If you are worried about the parts floating, secure them with masking tape or other means and solder them.

Note that too much solder (too long working time) when soldering a pin socket may cause solder to flow inside the pin socket and prevent the pin header from sticking.

When solder is felt being sucked into the through-hole, soldering of that terminal should be completed and the next terminal should be moved on.



Once soldered, insert the 12-pin header into the 12-pin socket.[Do not use the pin headers included with ProMicro] Use the pin headers in the same bag as the pin sockets (the height of the parts is different)] Insert them properly all the way to the back.



Insert the ProMicro into the inserted pin header.  
Solder the ProMicro side as shown in the photo below.



The top of ProMicro can be equipped with an OLED.  
Insert a 4-pin header into the 4-pin socket and place the OLED module on it.
And solder only one pin of 4 pins.  

While melting the solder, push the OLED module from above so that it does not float. You can also adjust it so that it is parallel to the ProMicro for a better look.



Once the position is set, solder the remaining 3 pins.

### 3-8．Write and check operation of ProMicro
OK, let's write the test firmware to the ProMicro.

The test firmware has a concise keymap for easy operation checks, and the RGB LEDs light red, green, and blue in that order, making it easy to detect solder defects.
If you think you do not need the test firmware, for example, if you are forgoing LED soldering this time, you can use the regular firmware in [Chapter 10](#10 Writing Regular Firmware) You may write it here.
  
The firmware for the Keyball44 is the same whether the trackball is placed in the right or left hand.
Please write (FLASH) [Keyball44_test.hex](https://remap-keys.app/catalog/tAJ9Htme4oNabUkx4832/firmware)that is registered in REMAP.
Press the FLASH button in the above link to see the instructions on how to write.

If the keyboard is not recognized even though the USB cable is connected, it will be recognized when the soldered RESET switch is pressed twice quickly.

*Be sure to write the same hex file to both the left and right ProMicro.

If you want to edit the Keyball44 firmware directly and build it yourself, you can find the source in [this repository](https://github.com/Yowkees/keyball/tree/main/qmk_firmware/keyboards/keyball).Source code is available for download.

After the writing is completed, short the key switch pad with tweezers as shown in the picture below to check the operation.  
sides of the keyboard may be reversed, but this is no problem right now. Please just check that some characters are entered and that ProMicro is working. It is not necessary to try all keys yet.
The earlier you check the operation, the easier it will be to isolate the problem.

Also, check the LEDs at this time.
The LEDs are wired in series and assigned numbers. If LEDs 1 through 12 light up, but 13 and beyond do not, there is a problem with the soldering of LEDs 12 or 13. Try re-soldering or replacing the LEDs.

*Be sure to write the same hex file to both the left and right ProMicro.



## ４．Assemble the ball-reading board
Prepare the board shown in the photo below (hereinafter referred to as the "ball board") and the sensor.

In some cases, you may receive a pre-soldered board to check the quality of the sensor and board. If this case, please skip this step and proceed to Chapter 5, Soldering the L-shaped 7pin Conthrough header.

  

## 4-1. Soldering the optical sensor  

Insert the sensor IC from the __【BACK SIDE】__ of the ball board where no electric components are mounted.
Align the indentation indicating pin 1 of the IC with the pad mark on the board.



This is the direction of the IC when viewed from the back. Solder all pins from the surface where the component is mounted.



Use tweezers to peel off the protective stickers 【2 sheets】.



Attach the sensor lens to the side where the stickers were removed.
The lens has an direction. Please make sure the direction is correct, as the two thin pins of the lens may break if the direction is wrong.  
The lens has a protrusion in front of it as shown by the arrow in the photo below.



If the direction of the lens and IC match, the two pins of the lens should be able to be inserted into the IC softly and smoothly. Notice: Insert Lens slowly!



### ５．Soldering the L-shaped conthrough pin header
Next, attach the L-shaped spring-loaded 7pin headers to the right-hand board __【TOP FACE】__.  
The L-shaped spring-loaded pin headers also have a direction, and should be installed in the same way as in the picture below.  
Solder the one straight pins that does not have a U-shape.



Put a masking tape on the component to prevent it from floating.



And solder it from back side.



This completes the soldering process.

As a side note, before de-energizing the soldering iron, put plenty of solder on the tip. The next time you use the soldering iron, you can remove the solder and resume work with a shiny soldering tip!



## ６．Cutting of top plate  

Keyball44 can switch 5 thumb keys to choc low profile switches.

In this case, the perforations on the top plate must be cut away.

To cut them off, use a cutter to cut into the perforated areas on the front and back sides, then fold and separate them.

If you want to use regular Cherry MX switches for the thumb keys, you do not need to detach the board.

Even if you detach the board, you can install either choc switches or MX switches on the thumb keys, so if you want to try using both, we recommend you to detach the board here.



The detached cross section should be prepared with about 150-grit sandpaper.



## ７．Assembly 

### 7-1. Assembling the top plates  

Screw the 7mm spacers to the 【BACK SIDE】 of the top plate.

When assembling thumbs with low-profile specifications, install 4mm spacers on the top plate for thumb keys.



Next, screw the four 11mm spacers to the left and right middle boards.

Note that if you forget to do this and install the bottom plate, the 11mm spacers will not be able to be screwed in place.



Insert the key switches into the four corners of the top plate and the thumb plate.

This will improve the positioning accuracy between the plates.



Align the screw holes on the top plate and middle acrylic plate and stack the plates on top of each other.



Next, the soldered middle board is also stacked, making sure that the screw holes are aligned and the key switch terminals are firmly inserted into the key sockets.



### 7-2. Assembling the bottom plates 

Overlap the acrylic bottom plate from the back side and screw it in place.
Next, attach the cushion rubbers to the four corners of the keyboard.



### 7-3.Installation of protection plate  

Screw the acrylic protection plate onto the 11mm spacer.

The shape of the protection plate is the same for both sides with and without trackball. There is no front or back.

  

## ８．Trackball installation 

### 8-1. Insert the trackball reading board  

Insert the assembled trackball reader board into the 7-pin conthrough pin header. The board should be inserted vertically.



The ball board is now standing vertically.



### 8-2.Assemble the trackball case  

3 ceramic balls are fixed to the trackball case in advance. If the ceramic balls have fallen off, please fix by spare ceramic ball with a suitable bond.  
Please keep the spare ceramic ball in case you lose them in the future.

Shake the case to make sure the ceramic ball does not fall out.



The 2 pins on the top case can be inserted into the holes on the bottom case.  
Gently apply pressure from above and below to join them. (It's okay if you don't get a tight fit, because it will stick after this screw tightening.)



Attach an M1.7 tapping screw. The kit includes two types of screws: "small head screws" and "flat head screws". In this process, please use "small head screws".



Screw in these two locations as seen from the back of the case. Be careful not to over-tighten them.



### 8-3. Trackball case installation  

Attach the completed ball case to the main unit. The ball board is placed in the sensor compartment on the back side of the case.  
Gently fit the case from the top, making sure that the ball board indicated by the arrow is at the center of the case. If there is any sticking, do not force it in, but pull it out and reinsert it.

It should go all the way in without much effort.



If you check from the back of the unit, there may be a gap between the main board and the ball board, as indicated by the arrow.



In this case, lightly push from the front of the case (in the direction of the finger mark). If you use too much force, the L-shaped construe may be damaged, so press lightly.  
If the gap disappears as shown in the picture below, the screw holes in the blue circle will fit.



Tighten the two M1.7 Torx screws with __【wide flat heads】__ from the back of the body. Tighten the screws while holding the ball retainer case with your fingers to prevent it from rotating.



## ９．Total finish 

We are nearing completion! Fit the key switches of your choice.

Finally, push the 34mm trackball into the case and Keyball61 Building have done! 
Thank you for your hard working.  



keyball44完成品

## １０．Write the regular firmware

Finally, let's write the firmware to ProMicro.

Keyball44 supports[ReMAP](https://remap-keys.app/configure), you can write firmware and change the keymap without installing any special software. 

To use REMAP, please write the following VIA-supported firmware

   - Keyball44 VIA-supported firmware [Keyball44 firmware page in the REMAP catalog](https://remap-keys.app/catalog/tAJ9Htme4oNabUkx4832/firmware), open the Keyball44_via and FLASH the firmware.

For writing, as written in[Chapter 3-8](#3-8 Write and check operation of ProMicro),press the FLASH button and instructions on how to write will appear.
If the keyboard is not recognized even though the USB cable is connected, press the soldered RESET switch twice quickly and it will be recognized.

*Be sure to write the same hex file to both left and right Pro Micro.

■If you want to build the firmware by yourself   
The latest firmware for Keyball44 is available at[Github repository](https://github.com/Yowkees/keyball/tree/main/qmk_firmware/keyboards/keyball). Copy this keyball folder to your QMK_Firmware/keyboards and edit the keymap etc. freely and build.  

## １１． How to use Keyball
   - The trackball motion will change to scroll up, down, left and right while switching to layer 3.
   - Keyball supports [ReMAP](https://remap-keys.app/configure),so you can check, change and write keymap easily.
   - The USB cable can be plugged in either left or right. However, since the keymap is written to the ProMicro on the side where the USB cable is plugged in, please review the keymap when replacing the cable for the first time.
   - There are Special keys for Keyball users as below list. It is located on Layer 3. These key codes can be used for switching Cursor action to Scroll or Changing CPI and Speed of Scroll.

See [Special Keycode](../../../qmk_firmware/keyboards/keyball/lib/keyball/keycodes.md#japanese) also.

This concludes the Keyball44 build guide.
If you have any questions or problems with Keyball, please post them to the Github repository 
[Yowkees/keyball Discussions](https://github.com/Yowkees/keyball/discussions). We'll get back to you as soon as possible.

Thank you very much. @Yowkees

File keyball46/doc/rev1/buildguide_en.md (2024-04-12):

# Build Guide for Keyball46

This is the build guide for Keyball46.

Keyball46 is a split keyboard with integrated thumb trackball.

●[日本語のビルドガイドはこちら](https://github.com/Yowkees/keyball/blob/main/keyball46/doc/rev1/buildguide_jp.md)



## [Contents of Build Guide for Keyball46]
  - [1. Parts Check](#1)
    - [1-1. Kit Bundled Items](#1-1)
    - [1-2. Parts to be prepared by the customer before assembly](#1-2)
    - [1-3. Parts and options that can be installed after assembly](#1-3)
  - [2. Preparation](#2)
    - [2-1. Required Tools](#2-1)
    - [2-2. Firmware](#2-2)
  - [3. Mounting](#3)
    - [3-1. Before Soldering](#3-1)
    - [3-2. Soldering the Diodes](#3-2)
    - [3-3. Soldering Jumpers](#3-3)
    - [3-4. 4 pin sockets, TRRS socket, tact switch](#3-4)
    - [3-5. Soldering ProMicro](#3-5)
    - [3-6. Writing and operation check of ProMicro](#3-6)
    - [3-7. Soldering the underglow LED (option)](#3-7)
    - [3-8. Soldering the key socket](#3-8)
  - [4. Assemble the ball reader board](#4)
  - [4-1. Soldering the sensor](#4-1)
    - [4-2. Soldering the L-shaped spring-loaded pin headers](#4-2)
  - [5. Solder the left-hand side left-right jumper](#5)
  - [6. Cut the top plate (option)](#6)
  - [7. Assembly](#7)
    - [7-1. Install the protection plate](#7-1)
    - [7-2. Assemble the Top Plate](#7-2)
    - [7-3. Assemble the Bottom Plate](#7-3)
  - [8. Trackball Installation](#8)
    - [8-1. Insert ball reader board](#8-1)
    - [8-2. Assemble the trackball case](#8-2)
    - [8-3. Trackball Case Installation](#8-3)
  - [9. Finishing](#9)
  - [10. Write the official firmware](#10)
  - [11. How to use Keyball](#11)

## 1. Check the parts

When you receive your kit, please make sure whether all the items included in the kit.

### 1-1. Items included in the kit

| Name | Number | Note |
|:-|:-|:-|
| PCB (left and right) | 1 set | | 
| Top PCB plate (left and right) | 1 set | | 
| Bottom acrylic plate (left and right) | 1 set ||
| ProMicro protection plate (left and right) | 1 set ||
| Trackball holding case white (top and bottom) | 1 set ||
| Φ2 Ceramic ball (spare) | 1 pcs ||
| Trackball reader circuit board | 1 plate ||
| Trackball readout IC | 1 pcs ||
| Lense for Trackball readout IC | 1 pcs ||
| Flat head screw M1.7 | 2 pcs ||
| Small head screw M1.7 | 2 pcs ||
| TRRS Jack | 2 pcs ||
| Tact Switch | 2 pcs ||
| Diode (Surface mounting type) | 52 pcs + | Lead type also available (option) |
| Kailh PCB Socket | 50 pcs ||
| OLED module | 2 pcs ||
| Pin header (4 pin) | 2 pcs ||
| Pin socket (4 pin) | 2 pcs ||
| Spacer M2 7mm | 15 pcs ||
| Spacer M2 9mm | 5 pcs ||
| Screws M2 3.5mm | 38 pcs + ||
| Cushion rubber | 8 pcs ||



### 1-2. Parts to be prepared by customers themselves before assembly

The following are the parts you need to prepare before assembly.

| Name | Number | Note |
|:-|:-|:-|
| ProMicro | 2 pcs | You can choose from inexpensive ones or USB Type-C supported ones. |
| Keyswitches | 46 pcs | CherryMX compatible keyswitches |
| Trackball (34mm diameter) | 1 pc | Used to check operation |
| TRS (3-pole) cable | 1 cable | TRRS (4-pole) cable is also acceptable |
| Micro USB cable | 1 cable | Compatible with ProMicro you purchased |



### 1-3. Parts and options that can be installed even after assembled.

| Name | Number | Note |
|:-|:-|:-|
| Keycaps | 46 pcs | 1U size x 45 pcs, 1.25U size x 1 pcs |
| YS-SK6812MINI-E | 14 pcs | For underglow *Notice: Cannot be used with SK6812MINI. |



## 2. Preparation

### 2-1. Required tools

You will need the following tools to assemble the Keyball46.

| Name |
|:-|
| Soldering iron (with adjustable temperature if you are mounting LEDs) |
| Solder (low melting point is effective when mounting LEDs) |
| Nippers |
| No. 0 + precision screwdriver |
| Tweezers |



### 2-2. Firmware

In order to run the Keyball46, you need to write the firmware to the ProMicros you purchased.
For more information about QMK Toolbox, please refer to [Corne's Firmware](https://github.com/foostan/crkbd/blob/fbb146fe372ce8b2b1543ced67367bf19e910945/doc/firmware_en.md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) about QMK Toolbox, please read the first half of the link and prepare QMK Toolbox.  

For more information on writing firmware, see [Chapter 3-6](#3-6) for writing test firmware, and [Chapter 10](#10) for writing production firmware.

<a id="3"></A></a>
## 3. Mounting

Now it's time to start the soldering process.  
The PCB is reversible, so you first need to decide which one is for the left hand and which one is for the right hand.  

The trackball will be attached to the PCB missing position, indicated by the red circle.  
If you want to use your right thumb to control the trackball, Placement will look like the picture below.  



If you operate the trackball with your left hand, Placement is as shown in the picture below. 



In this build guide, we will use the specification to put the trackball on the right hand.  
Place the PCB as shown below, and put masking tape on the surface to prevent mistakes.
I wanted to write "TOP FACE" on masking tape.



### 3-1. Before Soldering
The tip of the soldering iron should be shaped like a bamboo spear, so that you can put solder on a flat surface and scoop out excess solder.



.
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

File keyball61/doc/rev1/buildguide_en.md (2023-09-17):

# Build Guide for Keyball61

This is the build guide for Keyball61.

Keyball61 is a 60% split keyboard with integrated 100% useful thumb trackball.

●[日本語のビルドガイドはこちら](https://github.com/Yowkees/keyball/blob/main/keyball61/doc/rev1/buildguide_jp.md)



## [Contents of Build Guide for Keyball61]

  - [1. Parts Check](#1)
    - [1-1. Items included in the kit](#1-1)
    - [1-2. Parts to be prepared by the customer before assembly](#1-2)
    - [1-3. Parts and options that can be installed after assembly](#1-3)
  - [2. Preparation](#2)
    - [2-1. Required Tools](#2-1)
  - [3. Mounting](#3)
    - [3-1. Before Soldering](#3-1)
    - [3-2. Soldering the Diodes](#3-2)
    - [3-3. Soldering the key socket](#3-3)
    - [3-4. Soldering Jumpers](#3-4)
    - [3-5. 4 pin sockets, TRRS socket, tact switch](#3-5)
    - [3-6. Soldering ProMicro](#3-6)
    - [3-7. Writing and operation check of ProMicro](#3-7)
    - [3-8. Soldering LEDs (option)](#3-8)
  - [4. Assemble the ball reader board](#4)
    - [4-1. Soldering the sensor](#4-1)
    - [4-2. Soldering the L-shaped spring-loaded pin headers](#4-2)
  - [5. Solder the left-hand side left-right jumper](#5)
  - [6. Cut the top plate (option)](#6)
  - [7. Assembly](#7)
    - [7-1. Install the protection plate](#7-1)
    - [7-2. Assemble the Top Plate](#7-2)
    - [7-3. Assemble the Bottom Plate](#7-3)
  - [8. Trackball Installation](#8)
    - [8-1. Insert ball reader board](#8-1)
    - [8-2. Assemble the trackball case](#8-2)
    - [8-3. Trackball Case Installation](#8-3)
  - [9. Finishing](#9)
  - [10. Write the official firmware](#10)
  - [11. How to use Keyball](#11)

## 1. Parts Check

When you receive your kit, please make sure whether all the items included in the kit.

### 1-1. Items included in the kit

The Keyball61 Standard set has one Trackball that can be attached on Right or Left side.

Other choices are also available in a dual-ball version with trackballs on both the left and right sides, or in a single-handed version with separate left and right keyboards so that they can be assembled without trackballs.

Included parts in the Keyball61 Standard Kit are the following
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

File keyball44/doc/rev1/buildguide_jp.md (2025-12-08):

# Build Guide for Keyball44

このガイドでは、Keyball44の組み立て手順を詳しく説明します。  
※Keyball44の白基板の写真をメインに説明していますが黒基板も同様の手順になります。  
黒基板セットのみ対応が必要な箇所は文頭に ⚫️ を付けています。

**English build guide for Keyball44 is [here](buildguide_en.md).**



## 【目次】

> **準備編**
 - [1. 部品確認](#anchor1)
   - [1-1. キット同梱品](#anchor11)
   - [1-2. 組立前にお客様自身で準備いただく部品](#anchor1-2)
   - [1-3. 組立後でも取り付けられる部品とオプション](#anchor1-3)
 - [2. 準備](#anchor2)
   - [2-1. 必要な工具](#anchor2-1)
   - [2-2. ファームウェア](#anchor2-2)
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

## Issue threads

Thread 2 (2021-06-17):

エポキシ接着剤の着色についての言及を検討

koron, 2021-06-17:
トラックボールケースにエポキシ接着剤を付ける時に
接着剤が透明がかった白なので
付いたかどうか非常に分かりにくく不安でした。

[ちょっと調べるとレジン用の着色剤など油性のものと相性が良い](https://sweetsdeco.co.kr/article.php?contentsno=159&lang=ja) ようです。
作りやすさを考慮すると接着剤を着色するというオプションに言及するのが良いのではないでしょうか。

Yowkees, 2021-06-19:
いろいろ検討しまして、やはりセラミックボールは全数私がボンド付けして出荷することとしました。エポキシ接着剤は不要となります。

Closed 2021-06-19.

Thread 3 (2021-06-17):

左右のうちトラックボールがある方にUSBを接続する制限があることを付け加える

koron, 2021-06-17:
これはファームウェアの熟成で解決されることかもしれませんが、
現在はトラックボールがある方をmaster(=USB接続がある)にしなければ
トラックボールが機能しません。

そのことをビルドガイドに書いておけば、
いざ完成してトラックボールをテストしてみよう
となった時のトラブルが減ると予想されます。

Yowkees, 2021-06-19:
ビルドガイドに注記を追加しました。

Closed 2021-06-19.

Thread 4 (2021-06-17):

LEDのマーキングが判別しにくいのをフォローする

koron, 2021-06-17:
製造時の個体差・誤差かもしれませんが
PCB上のLEDのマーキングがパッドに近く判別しにくかったです。

対処法としては以下が考えられます。

* 次回製造時に線描だけでなく、少し(1mmくらい?)離れた位置にドット等を追加する
* 全体を写した写真にマーキングの意味をアノテーションする

    アノテーションに使う画像の1候補

    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

Yowkees, 2021-06-19:
ご意見ありがとうございます。次回ロットよりシルクを変更します。

Closed 2021-06-19.

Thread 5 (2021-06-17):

LEDの点灯順序を明示する

koron, 2021-06-17:
LEDの点灯順序(配線順序)をビルドガイド中に明示してあると助かります。

SK6812mini-Eは慣れるとハンダ付けの失敗もそうそうしませんが
逆に言えば慣れない人はやはり失敗します。
そのような時に番号がふってあれば
どのLEDに問題があるのかが伝えやすくなります。

また少し慣れた人であれば配線順序がわかれば
それをもとに不良個所を推定でき自己解決しやすくなるでしょう。

Yowkees, 2021-06-19:
次回ロットより番号を追加します！

Closed 2021-06-19.

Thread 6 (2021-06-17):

組み立て済みボール読み取り基板について言及する

koron, 2021-06-17:
購入したキットではボール読み取り基板が組み立て済みでした。

そのため [この手順](https://github.com/Yowkees/keyball/blob/main/keyball46/doc/rev1/buildguide_jp.md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) に到達した際に若干困惑しました。
ひとこと言及があると助かります。

Yowkees, 2021-06-19:
ビルドガイドに組み立て済みである場合があることを追記しました。

Closed 2021-06-19.

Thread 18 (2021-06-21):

ボールの有無で2種類のファームを作る

koron, 2021-06-21:
ボールの有無=基板の種類で2種類のファームを作る。

名前は rev1/ball および rev1/noball とする。

それに先立ち `LAYOUT` の整理をしたほうが良い。
これについては別途 issue を作ります。

---

### Discussed in https://github.com/Yowkees/keyball/discussions/17

<div type='discussions-op-text'>

<sup>Originally posted by **koron** June 21, 2021</sup>
いまボールの有無(基板の違い)によらずファームは1種類ですが、これを分けたほうが良いのではないかとのアイデアを得ました。思考の推移は以下の通りです。

* 左右自動判定やボールの有無の自動判定をやりたい
* ボールの有無の自動判定は何らかの方法でできそう (PMWにResetなげてレスポンスを見てみる)
* 左右の自動判定は無理そう

    ProMicroの未使用ピンがない & 異なる基板で未使用マトリックスが異なるため、1種のファームで2種の基板の左右を判定する(4通り!)ほどよい手段がない。ボールの有無を判定したのち、それに応じてチェックする未使用マトリックスを変えることはできるかもだが…複雑であまり好ましいアイデアとはいえない。

* ならいっそPCB毎に別のファームを用意したらどうか(名前の例: `rev1/onball`, `rev1/offball`)

    名前はあとで変更可

* これなら未使用マトリックスで左右判定できる
* ファームウェアのサイズ削減にもつながり一石二鳥
    * offballはPMWのファームがまるまる要らなくなる(大きな効果)
    * onballはトラックボールの有無判定が要らなくなる(小さな効果)
    * offballにだけviaを入れてUSBを繋ぐ(masterにする)ようにすると、onballからviaを消せてファームに余裕ができるのでは?

        VIAはUSBを繋いでるほうだけで良いはず。TRRSの通信内容はマトリクスの転送やRGB LEDのタイミング同期だけでVIA固有のものはない

* 判定に使うマトリクスは onball が `F7, B5` で offball が `F6, B5` を予定
    * これはonballが右手の default キーマップでは MBTN1 と MBTN2 に相当
* `rev1` は引き続き自動判定なし、トラックボール側にUSBを接続する&左手ボールの場合は適切なファームを使う、で使える</div>

koron, 2021-06-21:
@Yowkees 問題なければぼく = koron に assign しておいてください。

Yowkees, 2021-06-21:
@koron Git初心者でお手数おかけします。assignしました！

koron, 2021-06-23:
#23 でボール有用のファームウェアが完了しました。

あとはボール無し用のファームウェア作って…
両者をつなぐ組み合わせの対応をする必要があります。

koron, 2021-06-24:
おおよそめどはたったのでここで残りの問題点を整理

* [ ] single trackball on secondary のケースでマウスカーソルの動きが1/10になってしまう
* [ ] secondary に繋いでいるモノ次第、それに依存して matrix_mask を変更する必要がある
* [ ] RGBLIGHTのアニメーションを増やす
* [ ] VIAを含めたファームを検討する
* [ ] [VUSBに逆流するProMicro](https://zenn.dev/koron/articles/7cdfd5382f9ee3)への対応を入れる(暫定的にやったらキーボードがハングした)

koron, 2021-06-26:
> single trackball on secondary のケースでマウスカーソルの動きが1/10になってしまう

trackball 周りのファームを書き直して整理しなおしました。

> VIAを含めたファームを検討する

rev1/ball/via, rev1/noball/via, rev1/ball/via_Left, rev1/noball/via_Left がコンパイルできることを確認しました。

最新版はココで作業してます。
https://github.com/koron/qmk_firmware/commit/9a3c4825dbd8516658e0003ce2acc6bf1564b839

koron, 2021-06-26:
> RGBLIGHTのアニメーションを増やす

Via無しでギリギリ入った。

Yowkees, 2021-06-27:
ファームウェアの整備、誠にありがとうございます！
最新版のファームを試してみました！USBをどちらに差しても使用できるのは実に爽快です！TRSケーブル内にトラックボール情報が流れてるのか～と見入ってしまいました。
koronさんは現在ご自身のリポジトリで作業されているということで、Keyball46のビルドガイドに掲載する最新ファームウェアのリンク先をkoron/qmk_firmwareとしても大丈夫でしょうか？

それと１点、わたしのキーボードですとレイヤー３への切り替えが機能しないようなのですが、koronさんのものでは問題ないでしょうか？私のmakeや書き込みが悪かったのかもしれませんので、もう少しいろいろ試してみます。

koron, 2021-06-27:
ああ最新のファームウェアは
こちらの Yowkees さんのレポジトリに置きませんか?
やはり Yowkees さんのハードなんで。

後程方法を考えましょう。DisussionのAnnouncementにZIPで添付するのが良いかもしれません。

koron, 2021-06-27:
> secondary に繋いでいるモノ次第、それに依存して matrix_mask を変更する必要がある

done

> RGBLIGHTのアニメーションを増やす

容量的に VIA + フルRGBLIGHT + トラックボールドライバは不可能なので初版では諦めましょう。

将来的には トラックボール無し側にVIA+ フルRGBLIGHTのファームを、
トラックボール有り側に RGBLIGHT + トラックボールドライバのファームを書いて
トラックボール側にUSBを繋ぐという制限でVIA+RGBLIGHTが同居できるとは思います。

koron, 2021-06-27:
> VUSBに逆流するProMicroへの対応を入れる(暫定的にやったらキーボードがハングした)

試したところ待ち時間を200msくらいにするとハングした。
正確には secondary と判断されてUSBキーボードとして機能しなくなる。
手元では300msにすれば問題なく動くが、安全マージンを見て500msにしておく。

Yowkees, 2021-06-27:
最新ファームウェアの位置了解しました。お送りいただければこちらで管理いたします。

koron, 2021-06-27:
> わたしのキーボードですとレイヤー３への切り替えが機能しないようなのですが、koronさんのものでは問題ないでしょうか？

いま default キーマップと via で試してみましたが、問題なく _BALL レイヤーに切り替えられました。
一応これで作業がひと段落したので、いまからPR作ります。

Closed 2021-06-27.

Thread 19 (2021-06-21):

`LAYOUT` マクロの修正&整理

koron, 2021-06-21:
related https://github.com/Yowkees/keyball/issues/18

今の `LAYOUT` マクロにはいくつか問題があるので修正したほうが良いです。
修正内容は以下の通り。

* 右側ボール、左側ボール、ダブルボール、ノーボール(これいる?)の構成に向けてそれぞれ LAYOUT を用意する

    命名例: `LAYOUT_rightball`, `LAYOUT_leftball`, `LAYOUT_doubleballs`, and `LAYOUT_noballs`

* `LAYOUT` を `LAYOUT_rightball` のエイリアスとする

* 各レイアウトで割当不可能なキー隠す

    例: 右側ボールにおける左の F6, B5 と 右の F7, B5

    handiness の自動判定を考慮すると使えないキーにはキーマップを設定できないほう良い。

* `LAYOUT_kc` の廃止

    `MO(1)` などを記述するのにわざわざ `KC_*` なキーコードを定義する必要があり、QMKの流儀とは著しく異なる。多少手間でも `KC_Q` などはそのまま書いておいた方が良い。qmk c2json や json2c のことを考えるとあまり良いアイデアとは言えない。

    * 既存の `LAYOUT_kc` を使ってるキーマップを前述の `LAYOUT_rightball` もしくは `LAYOUT` を使ったものに置き換える

koron, 2021-06-21:
@Yowkees こちら、問題なければわたし=koronにassignしておいてください。

koron, 2021-06-21:
今の `LAYOUT_kc` そのものは残しておくことはできます。
ただ提供しているキーマップでは使わない方が良いでしょう。

Yowkees, 2021-06-21:
ノーボールを選択する稀有な方はいないでしょうが、一応準備しますか？

>多少手間でも KC_Q などはそのまま書いておいた方が良い。
そうなのですね。ご指摘ありがとうございます！勉強になります。

koron, 2021-06-22:
#22 で完了しました。これでダブルトラックボールの本題に取り掛かれます。

Closed 2021-06-22.

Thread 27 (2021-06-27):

ダブルトラックボールにおけるポインタのhandness設定

koron, 2021-06-27:
現在、ダブルトラックボール構成ではUSBを繋いだ側がポインタ、
繋いでいない側がスクロールとなっています。

これをconfig.hで左右により固定できるようにします。
ただしdual ballで使ってる人はほぼいないので後回し。

---

When you use Keyball with double ball combination,
a ball on USB connected side is treated as mouse move.
And other side ball is scroll wheel.

We make it configurable by config.h or so: depending right or left.
But this is low priority because there are few peoples who use double ball.

koron, 2022-09-10:
需要が見込めないのでやらない、ということで閉じます。

---

I close this because I can't expect the demand.

Yowkees, 2022-09-10:
dual ball仕様でKeyballを長いこと使ってみましたがなかなか２つのボールを活用できる方法が見つかっていません。
ゲーム用途、CAD用途等でハマる活用法があったら良かったのですが、今後そういう話をいただくことに期待したいです。

Closed 2022-09-10.

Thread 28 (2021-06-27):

レイヤー３への切り替え不具合

Yowkees, 2021-06-27:
最新ファームウェアにてレイヤー３への切り替えが出来ていないかも知れません。
レイヤー３はRGBの変更の他、トラックボールをスクロールに変える機能を持っています。
デフォルトキーマップでは左手親指の一番内側のキーに割り当てられています。

ご確認いただければ幸いです。

koron, 2021-06-27:
https://github.com/Yowkees/keyball/pull/29 こちらでPRしたファームウェアを用いたところ、
問題なくレイヤー3への切り替えができていますので、そちらをお試しください。

なおリリース候補のファームウェアは現在準備中です。

koron, 2021-06-27:
> なおリリース候補のファームウェアは現在準備中です

こちらにビルド済みファームウェアを置きました!

https://github.com/Yowkees/keyball/discussions/31

本当はタグ打ってGithubのリリースを作った方が良いのかもですが
あくまでも仮=RC1ということで。

Yowkees, 2021-06-27:
ありがとうございました！確認します！

Yowkees, 2021-06-27:
申し訳ありません。まったく問題なくレイヤー３使用できました！
これで今後のキット購入者への対応もばっちりだと思います。本当にありがとうございます！

Closed 2021-06-27.

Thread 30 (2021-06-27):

VIAのPRODUCT_IDについて

Yowkees, 2021-06-27:
VIA対応をするために、右きき版と左きき版のjsonファイルを作成しました。
VIAを起動した際に自動でどちらが接続されているか判別する方法として、PRODUCT_ID＝0001なら右、0002なら左と判定しようと考えています。
今はmake前にrev1/config.hの中を１→２と手で書き換えていますが、これが自動で切り替わるようにPRODUCT_IDの位置を変更できると嬉しいです。
それか別のアイデアがあればご提案いただければと思います。
ご検討いただければ幸いです。

koron, 2021-06-27:
ああ僕がやっときますのでアサインお願いします。

* `1` = 右トラックボール
* `2` = 左トラックボール
* `3` = ダブルトラックボールとしときましょうか

koron, 2021-06-27:
ビルド済みファームはここに上げておきました。

https://github.com/Yowkees/keyball/discussions/31#discussioncomment-927740

Yowkees, 2021-06-27:
早速のご対応ありがとうございました！

Closed 2021-06-27.

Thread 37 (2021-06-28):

TRSケーブルを繋がないとボールが動かない

koron, 2021-06-28:
ボールのある側だけをUSBにつないで
TRSをつながないとボールが反応しない。

シリアル通信成功後に光学センサーをスキャンしていることが原因。
TRSを繋いでいない場合はシリアル通信が決して成功せずスキャンしない。

スキャンしてからシリアル通信をするように変更する。
またボールのhandness判定も問題で左の片側だけだとポインタが動かないのも併せて修正する。

koron, 2021-06-28:
1.0.0-rc.2 でなおしました。

Closed 2021-06-28.

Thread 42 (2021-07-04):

Remap Review Result

yoichiro, 2021-07-04:
Hi, thank you for submitting the review request for this keyboard. However, we have rejected the request, because the PRODUCT value does not match the value written in the `config.h` file. For instance, you filled `Keyball64` in to the review request form, but the value in the `config.h` file is [`keyball`](https://github.com/qmk/qmk_firmware/pull/13185/files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). You need to fill `keyball` in to the review request form, or you need to change the PRODUCT value in the `config.h` file to `Keyball64`. Then, please resend the review request.

こんにちは、このキーボードについてレビュー申請を送っていただきまして、ありがとうございます。しかし、そのリクエストは既にリジェクトさせていただいております。理由といたしましては、PRODUCT値が `config.h` ファイルに書かれた値と一致していません。具体的には、レビューリクエストフォームに `Keyball64` と記入されていましたが、 `config.h` ファイル内の値は、 [`keyball`](https://github.com/qmk/qmk_firmware/pull/13185/files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) でした。レビューリクエストフォームに `keyball` と記載していただくか、もしくは `config.h` ファイル内の PRODUCT 値を `Keyball64` に変更していただく必要がございます。その後、レビューリクエストを再送信していただけますと助かります。

Yowkees, 2021-07-12:
ご連絡ありがとうございます。
丁寧に教えていただいた通りPRODUCT値を修正して、無事にレビュー通ったようです。
すばらしいRemapサービスのご提供、ありがとうございます！

yoichiro, 2021-07-12:
再申請ありがとうございました。閉じます。

Closed 2021-07-12.

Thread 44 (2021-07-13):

KC_BTN1~8を使えるようにする

koron, 2021-07-13:
https://twitter.com/Ryo46671803/status/1414767783083008002

> 左右クリックが設定できない😭
> 「Mouse Btn1」と「Mouse Btn2」を設定しても実行されない。

サイズ削減のためにMOUSEKEYが無効なので
KC_MS_BTN1\~8 (=KC_BTN1\~8) が解釈されていない。
代替として自前でKC_MBTNを定義してるが
これではVIAなどで設定が容易ではない。

おそらくVIAはKC_BTNを設定していると推測される。
なのでKC_BTNを独自に解釈すれば対応できるはず。

修正のための参考コード。
まだテストはしていない。

https://github.com/koron/qmk_firmware/commit/fa08f61500194397faf6aba4ad27a7c05214eaa0

koron, 2021-07-13:
この修正を取り込んだ各ファームを https://github.com/Yowkees/keyball/discussions/46 にアップロードしておきました。

Closed 2021-07-13.

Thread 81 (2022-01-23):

Keyball61 firmware

koron, 2022-01-23:
* [x] duplex matrix scanner
* [x] new PMW3360DM (optical sensor) driver
* [x] new left right communication
* [x] declare combination by layout options in VIA
* [x] configurable CPI
* [x] scroll mode keycodes
* [x] configurable scroll divider
* [x] pack many features in VIA firmware
* [x] brush up
* [x] test (QC)
* [ ] document

koron, 2022-01-23:
#82 merged to main branch

koron, 2022-03-07:
documentation task is not completed.
but it should make a issue for  documentation.

Closed 2022-03-07.

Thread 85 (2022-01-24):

Scroll_modeへの入り方について

Yowkees, 2022-01-24:
@koron 様
公開されましたKeyball61のVIA対応ファームウェアを使用してみてのご提案になります。REMAPを使用してみました。
新しいファームウェアでは、"SCRL_MO"が追加され、これを押下中にスクロールモードに入ることを理解しました。

私が以前より使い慣れたキー配列ですと、左手親指キーの外側キーは、HOLDでLayer3＝scrollモードになり、TAPでかな入力になるように使用していました。これと同じキー配置にしようと試したところ、"SCRL_MO"はHOLDに設定できないようです。@yoichiro さんに伺ったところ、HOLDに指定できるキーはQMK_Firmware側で限定されていたような、、との回答でおそらく出来ないようです。

そこで、新設の"SCRL_MO"は残したまま、Layer3に切り替え中にScrollモードとなる仕様を復活させるのはどうでしょうか？
もし、「Layer3とスクロールモードの連動で問題が発生したために"SCRL_MO"を新設した」というような事情があるようでしたら、作戦考えたいと思いますのでお教えいただければ幸いです。

大変お手数ですが、ご検討いただければ幸いです。

koron, 2022-01-24:
そうですね。VIAキーマップでのみLayer 3でscroll modeをenableする仕様を組み込みましょう。

koron, 2022-01-24:
@Yowkees https://github.com/Yowkees/keyball/actions/runs/1739670752

とりあえず `via` キーマップのみ layer 3 に同期して scroll mode をenableするようにしました。
これで問題ないか確認してみてください。

その上で `default` キーマップにも適用するか検討しましょう。

なお `test` と `develop` にはこれらのキーマップの目的から使い道がないので適用しません。

Yowkees, 2022-01-24:
早速のご対応ありがとうございます！
自キ始めた頃の僕のようなReMAP以外は無理っなユーザーへの自由度が上がると思います🙏
よーし！もう完璧な気はしてますが最終確認です！

koron, 2022-01-24:
せっかくなんで Keyball46 に合わせる意味も込めて `default` も入れておきましょう。

Closed 2022-01-24.

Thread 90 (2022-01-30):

Keyball46 failed to resume from sleep

koron, 2022-01-30:
https://twitter.com/kaspinMTH/status/1487649434263785472

> windows 10 proを使用しているのですが、スリープモードから復帰した際、keyball46を認識しません。OLEDにkeyballのロゴが表示された状態になります。 TRRSケーブルを抜き差ししたら認識します。
どうすればスリープ復帰した時点でkeyball46を認識しますか？

QMK由来の問題か、Keyballとの合わせ技の問題か、まずその切り分けが必要。

kaspinning, 2022-01-30:
PC側のUSB3.0端子に直差ししていたケーブルをUSB2.0端子に繋ぎ変えたら解決しました。

PCをスリープモードにすると、keyballの基板LEDは点灯したままで、トラックボール以外のキーを入力するとスリープモードから復帰し、keyballは認識されたまま使えました。

yswallow, 2022-01-30:
ProMicroのみで左手のファームウェアを試したところ、Ball Rightの左手のみだと問題がなく、Ball Leftの左手のみだと問題が発生したので、Keyballとの合わせ技の問題だと思います。マウスの移動情報を送り続けているためだと思っています。

~~仮説が正しければBall Rightでも左右を接続して左手にUSBケーブルを挿すと問題が発生するはずですがいかがでしょうか？（Ball Leftなら 右手のみ→問題なし、左右接続して右手にUSB→問題あり となるはず）~~

↑手元で試します

koron, 2022-09-10:
no one reports how to reproduce this problem.
so we can't fix it now.

i'll close this once.

please open this again, when you have further information.

---

問題を再現する方法を誰も提示できないので、現在のところ修正の見通しがありません。

よって本件はいったん閉じます。

もしも再現に関して追加情報があったら、再度issueを開きましょう。

Closed 2022-09-10.

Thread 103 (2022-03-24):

Unit of DXF files

fooker, 2022-03-24:
The provided DXF files are (per design) untiless. They do not seem to be in millimeters nor inch. What is the unit of these files?

Yowkees, 2022-03-27:
My Adobe Illustrator said 1 unit = 1 Points.
I am not good at DXF files. If you need another scaled DXF, Please tell me.
Thank you.

fooker, 2022-03-29:
No worries. Usually it is 1 unit = 1 inch or 1 unit = 1 mm (preferred).

For the record: 1 point is 0.352778 mm.

Closed 2022-03-29.

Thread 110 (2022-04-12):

auto shift doesn't work in remote desktop: adjust tap code parameters

koron, 2022-04-12:
One reports me that auto shift does't work correctly in Windows's remote desktop with Keyball61.
And I found an issue in QMK https://github.com/qmk/qmk_firmware/issues/13708

It says `TAP_CODE_DELAY` work for the case.
But I don't try it yet.

Additionaly, there are some version inconsistencies in the issue.
It says 0.13.x has issue. But I verified that 0.15.x is not affected, and 0.16.x is affected again.

Anyway, it would be better to start TAP parameter adjusting.

koron, 2022-04-12:
it may not "auto shift".

`*Shift+` or `(*S+` keycodes in remap-keys.app

koron, 2022-04-12:
related? https://superuser.com/questions/219461/shift-and-control-keys-out-of-sync-with-normal-keys-over-rdp

koron, 2022-04-16:
> You may also run into issues when using Remote Desktop Connection on Windows. Because these keycodes send key events faster than a human, Remote Desktop could miss them. To fix this, open Remote Desktop Connection, click on “Show Options”, open the “Local Resources” tab, and in the keyboard section, change the drop down to “On this Computer”. This will fix the issue, and allow the characters to work correctly. It can also be mitigated by increasing [TAP_CODE_DELAY](https://docs.qmk.fm/#/config_options?id=behaviors-that-can-be-configured).

https://docs.qmk.fm/#/mod_tap?id=caveats

koron, 2022-04-16:
Japanese translation

> これを解決するには、Remote Desktop Connectionを開き、「オプションを表示」をクリックし、「ローカルリソース」タブを開き、キーボードセクションのドロップダウンを「このコンピュータ上」に変更します。

Closed 2022-09-10.

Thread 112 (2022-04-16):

Keyball61: another key is pressed when pressing two keys

koron, 2022-04-16:
Keyball61, without the ball, left side.

when pressing `v` and `a`, `]` is pressed unexpectedly.

Original report: https://twitter.com/jomatsu_/status/1514968357841543168

> 自分のkeyball61はvとaを同時押しすると[が入力されてしまいます。

(He maps  `[` at `]`'s default position)

koron, 2022-04-16:
We know that Keyball61 has a problem that when pressing specified two keys
(a key on left side of row 3 and a key on right side of row 4)
other key on  row4 and col3 (`]`) is pressed by noise sometime.

koron, 2022-04-16:
But I confirmed that it doesn't happen when using QMK + ProMicro with my Keyball61.
So there may be some conditions to reproduce this problem:

* soldering status
* enviornmental radio wave
* or so

koron, 2022-04-17:
It looks like that pressing three keys make Keyball61 unstable.

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

---

describe in Japanese

3つのキーを押すと3つのダイオードを通してROW3が L となっても不思議ではない。
ダイオードによる電圧降下を0.7V程度と見做せば、2.6~2.9V程度にはなっていそう。
仮にRP2040で動かした場合は1.1V程度でかなり不安定になりそう。

なお左手側ではLEFT判定のJP9がショートしているので条件を満たしやすい。

koron, 2022-04-17:
> 仮にRP2040で動かした場合は1.1V程度でかなり不安定になりそう。

実際に1N4148使って実験した結果、
1.6VでLo判定で、ちょっとしたノイズでHiにもなりそうだった。

koron, 2022-04-17:
1N4148Wのデータシートによると電流が小さくなると順電圧が小さくなるので、
ハンダ付け不良などにより抵抗が大きくなってLo判定を受ける、という仮説を思いついた。

koron, 2022-04-18:
参考情報: https://blog.ikejima.org/make/keyboard/2019/12/14/keyboard-circuit.html

> 理想的なダイオードは片方に電気を完全に通し、 逆方向には全く通さない。 しかし、現実のダイオードはいくつか理想的ではないふるまいをする。 例えば、ダイオードを図のように接続すると、完全に0Vではなく電位差がある。 良く使われている1N4148はキーボードに使うと最高0.9V低くなる。

これは「最高0.9V低くなる」であって場合によっては「0.5Vしか低くならない場合もある」
このケースにひっかかると0.5x3で1.5Vになり、Lo判定≒ゴーストが発生しうる。
また0.85Vになって2.55Vとなると辛うじてHi判定になるが、
ちょっとしたノイズなどで2.5Vを割ってしまい、ノイズ耐性がないということが起こりうる。

Yowkees, 2022-04-18:
詳細なご考察、ゴースト発生個所に関する図まで本当にありがとうございます。とても分かりやすく理解できました。
また、参考情報リンクも読ませていただきました。ダイオードの電位差のバラつき次第でギリギリなのですね。けっこう危ない橋を渡っていることに気づかされました。
ProMicroが市場からなくなった際にはKeyball61は再設計の必要があると覚悟しました。

koron, 2022-09-10:
rev.2 では回路が修正されたため閉じます。

修正の具体的な内容は、裏のマトリックスとの間でrowかco線のどちらかにダイオードを1個ずつ追加すること。

Closed 2022-09-10.

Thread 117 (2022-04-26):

Question: Upstreaming with QMK?

fooker, 2022-04-26:
While hacking on the firmware of my keyball61, I have seen that there are a few components that are self-implemented. Remarkable this is the support for the pmw3360 sensor and the mouse key handling. Is there any reason why these are implemented differently from what upstream QMK provides?

I have managed to build a firmware using the upstream drivers. It looks like it"s working fine. Is there interest in a pull-request for such a change?

In addition I would like to to see support for the keyball boards in upstream QMK. I think that would simplify firware builds and increases visibility of these great keyboards.

Yowkees, 2022-04-26:
Ummm..
I want ask about it Mr.KoRoN.
I think he would find some problem (bug) in PMW3360 upstream drivers.

I hope some day qmk firmware accepts my pull requests.

Any way, thank you for your suggestion. See you on QMK firmware. Thanks!

fooker, 2022-04-26:
Oh, I did not realize that there are already attempts to bring it upstream.

koron, 2022-05-08:
> Is there any reason why these are implemented differently from what upstream QMK provides?

There were two problems on a driver in upstream to use with Keyball.

* The size is too big
    Upstream one includes a frimware for PMW3360DM called SROM.
    But it is not mandatory for PMW3360DM working.

* BUG: can't read registers
    There is a bug to read registers from PMW3360DM.
    Reading registers is required to checking trackball is provided or not.

> Is there interest in a pull-request for such a change?

No thanks.
Current Keyball's driver is working very fine for Keyball.
I don't want to have any extra hassle that doesn't involve Keyball.

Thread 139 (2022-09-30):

Keyball61 is missing top PCB

shigmas, 2022-09-30:
Bottom acrylic, mid PCB is there. But, no top PBC/acrylic.

Yowkees, 2022-10-25:
Hi. I am sorry for my late reply.
I added gerber data of Keyball61's Top PCB.
Check it out.

shigmas, 2022-10-26:
Great! Thanks!

Closed 2022-10-25.

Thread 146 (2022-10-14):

Added to upstream

drashna, 2022-10-14:
These really should be PRed to upstream QMK.

If you need any help with that, I'd be more than willing to help out.

Yowkees, 2022-10-25:
OK! I will PR later! Thank you for your help.

drashna, 2022-10-26:
In case it helps, the pointing device code has significantly improved in the last year.  Including support for splits in the core code:

https://docs.qmk.fm/#/feature_pointing_device?id=split-keyboard-configuration
and
https://docs.qmk.fm/#/feature_pointing_device?id=split-keyboard-callbacks-and-functions

There are also a number of keyboards you can look at for reference (bastardkb has the charybdis and dilemma, both of which are split boards with pointing device support).

koron, 2023-01-22:
It looks like there is no time to add it to the upstream.

So let's close this isssue and reopen it when we can take that time.

Closed 2023-01-22.

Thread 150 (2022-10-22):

can't combine KC_BTN1 with C(...)

koron, 2022-10-22:
`C(KC_BTN1)` doesn't work.
Because, Keyball firmware implements own minimal MOUSE key feature for size.

koron, 2022-10-23:
fixed by #152

koron, 2022-10-23:
keycodeの判定時に`QK_MODS` を考慮しない値で比較していたため、
`C(KC_BTN1)` のようなmodifierを伴うキーコードが機能しなくなっていた。

* QK_MODS をあらかじめ消した上で比較するようにした
* KC_BTN1~8の場合はprocess_record_kbでtrueを返すようにした
  QK_MODS分をQMKに処置させるため

Yowkees, 2022-10-23:
Keyballシリーズのソフトメンテナンスにご尽力いただき本当にありがとうございます！
私も気づいていなかった不具合でしたが益々ファームウェアの完成度が上がりました。
早速正規ファームウェアとして公開したいと思います。
誠にありがとうございます！！

Closed 2022-10-23.

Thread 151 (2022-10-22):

compile error with `MOUSEKEY_ENABLE = yes`

koron, 2022-10-22:
it will be failed that compile with `MOUSEKEY_ENABLE = yes` in rules.mk

koron, 2022-10-23:
fixed by #152

koron, 2022-10-23:
switch 内の {} ブロックの範囲が間違っており、
マクロのdefine次第で無効なブロックができてしまってた。

Closed 2022-10-23.

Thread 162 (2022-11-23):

Trackball not working with qmk>= 0.18.0

zhyu, 2022-11-23:
The last qmk version which works well with my keyball39 is 0.17.9.

There are some minor changes needed to compile with qmk 0.18.0, e.g., [RESET to QK_BOOT migration](https://docs.qmk.fm/#/ChangeLog/20220827?id=reset-2-qk_boot), but I still managed to compile keyball firmware with qmk 0.18.0. However, after flashing the firmware, the movement of the trackball is not recognized at all. Maybe it's related to the [pointing device improvements](https://docs.qmk.fm/#/ChangeLog/20220827?id=pointing-device-improvements) mentioned in the changelog.

**Why update?**

There would be a nice feature coming in the next breaking release of qmk that allows automatically activate the mouse layer when the mouse cursor is moved (https://github.com/qmk/qmk_firmware/pull/17962).

Btw, as #126 pointed out, `SAFE_RANGE` has been changed. From my experience, the special keycodes of keyball should be `+1` (e.g., `0x5DA5` -> `0x5DA6`) in qmk 0.16.x. And it should be `+8` (e.g., `0x5DA5` -> `0x5DAD`) in qmk 0.17.x.

zhyu, 2022-12-03:
I have tried to build various commits between qmk 0.17.9 and 0.18.0, and it seems https://github.com/qmk/qmk_firmware/pull/17840 is the change that causing the issue.

zhyu, 2022-12-03:
Confirmed the trackball works fine with qmk 0.18.17 (the last release before 0.19.0) after reverting the commit causing issues.

I tried to build qmk 0.19.0 as well. The trackball still works fine, however, the keymap is no longer recognized by REMAP any more. I guess it could be related to the VIA V3 update: https://github.com/qmk/qmk_firmware/pull/18222

zhyu, 2022-12-03:
Cherrypicked the auto mouse layer feature on qmk 0.18.17, and everything works as expected. So I'm happy with it right now.

If I could find time and fix the trackball issue without reverting the upstream commit, I could send a PR to make keyball firmwares compatible with qmk 0.18.x.

Yowkees, 2022-12-03:
I am sorry I haven't had any action about this issue, because of I am quiet busy lately.
This PR will be helpful to catch up QMK.

Thank you so much for your cooperation;-)

zhyu, 2022-12-04:
Since the issue preventing the trackball from working is about RPC, as a workaround, instead of reverting the corresponding commit, plugging the USB cable to the side with the trackball also works.

This way, the trackball is on the master side, so no slave-to-master trackball reporting is needed, then no RPC issues :)

Closed 2023-01-22.

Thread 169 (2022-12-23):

can't work with USB hub (docking station)

knttnk, 2022-12-23:
USBハブに接続して使おうとしても、すべてのキーとトラックボールが動作しません。

USBハブを使わず、PCに直接繋いだりtypeC-typeA変換ケーブルに繋いだりすると、正常に動作します。
普通のマウスはこのUSBハブに接続しても動作しますので、USBハブの問題ではないと思います。

通常繋いだ方のKeyballにはキーやボールの情報が表示されると思いますが、USBハブに繋ぐとKeyballのロゴが表示されます。この現象と関連がある気がしますが、いかがでしょうか？

### 環境
- Keyball61 rev2
- ファーム: https://remap-keys.app/catalog/RZSU1CrvEW4lns0ww5BM/firmware のKeyball61_via
- USBハブ: https://direct.sanwa.co.jp/ItemPage/400-HUB091S など

koron, 2023-01-22:
こちらで把握している問題としては、
バスパワー(ACアダプタ無し)のUSBハブを用いると電力不足で不安定になるケースがある
というモノがあります。
特にその際はOLEDの表示がされないか不安定になることが知られてします。

ですので、まずはいったんACアダプタを繋いだ状態でも、
引き継き問題が発生するか確認してみてください。

その上で knttnk さんが紹介されている製品 400-HUB091S は、
正確にはUSBハブではなくドッキングステーションであるため、
いわゆる普通のUSBハブとは若干性質が異なっています。
Keyballが利用している、
Pro Microに搭載されているMCUチップ=ATmega32U4や
ベースとなる共通ファームウェア=QMK firmwareが
それらに対応できていない可能性も、わずかながら存在しています。

そのような場合は別の接続手段を取るようにしてください。

knttnk, 2023-01-24:
コメントありがとうございます。

ACアダプタをドッキングステーションに繋いでも、変わりませんでした。

knttnk, 2023-01-24:
masterとslaveの認識がうまく行っていないように見えたので、`qmk_firmware\keyboards\keyball\keyball61\config.h`の
```h config.h
#define SPLIT_USB_DETECT
#define SPLIT_USB_TIMEOUT       500
```
の部分をコメントアウトしてみたところ、使えるようになりました。

もっとうまい解決策はあるでしょうか？これで生じる弊害がなければこのままでもいいのですが。

koron, 2023-09-16:
knttnk さんの環境で `SPLIT_USB_DETECT` を無効化することでうまく動くのであれば
そのようにして使っていただいて大丈夫です。
とくに問題はないと思います。

しかしデフォルトの設定としては現状のままとします。

ProMicroには互換機が何種類もあります。
そのうちの入手が容易ないくつかは `SPLIT_USB_DETECT` が無いと
secondary (slave) 側が動かないという不具合を生じることがわかっています。
(参考: https://zenn.dev/koron/articles/7cdfd5382f9ee3)

そのため、ユーザーが利用しているProMicro互換機を指定できない以上、
この `SPLIT_USB_DETECT` の設定はデフォルトでしておいた方が有利であると
考えて現状維持と決定しました。

あしからずご了承ください。

koron, 2023-09-16:
## まとめ

`SPLIT_USB_DETECT` を設定することで
ドッキングステーション経由でKeyballが認識されない問題が生じることが分かった。

ドッキングステーションにUSB HIDデバイスを接続した(≒Keyballに電源が入った)際に
USBの通信が確率するまでに500msec以上の時間が経過していることが原因だと推定される。

しかし `SPLIT_USB_DETECT` は有効なままとすることにした。
雑多なProMicro互換機の中にはこれがないと正常に機能しないものがあり
(参考: https://zenn.dev/koron/articles/7cdfd5382f9ee3)
現時点においてはそのケースを救うほうを優先した。

knttnk, 2023-09-17:
なるほど，丁寧なご対応ありがとうございました．

zhyu, 2023-10-29:
I was facing the same issue.

I understand `SPLIT_USB_DETECT` is required for some ProMicro compatible boards, but probably setting `SPLIT_WATCHDOG_ENABLE` as well is a better default.

By enabling the watchdog, the keyboard will be rebooted automatically if `SPLIT_USB_DETECT` fails, I can confirm it resolves my issue with a USB switch.

Ref:
* https://docs.qmk.fm/#/feature_split_keyboard?id=hardware-configuration-options
* https://github.com/qmk/qmk_firmware/pull/18599

Closed 2023-09-16.

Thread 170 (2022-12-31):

QMK firmware update: ファームウェアが破壊的なアップデートをして昔のプログラムがエラーになる

metoro0530, 2022-12-31:
http://www.neko.ne.jp/~freewing/hardware/qmk_update_program_with_newest_firmware_2022/
As I found something like this article happen, and in the end, this gives such a error:

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

`register_button' is not defined.
How this suppose to work? And how can it be fixed?

koron, 2023-01-22:
https://github.com/Yowkees/keyball/pull/182#issuecomment-1399414981

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

please use QMK 0.16.x (0.16.3 recommended/tested), or use `support-qmk_firmware-0.19-or-above` branch which include #182

metoro0530, 2023-01-22:
Although I somehow managed to use keyball after uninstalling drivers and replacing a USB cable which was too long and could not supply power enough, this advice should be the point.
Thank you.

Closed 2023-01-22.

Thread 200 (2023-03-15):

stl files for the trackball mount

shigmas, 2023-03-15:
Since this has been out of stock for such a long time, I am looking at printing everything myself. I assume the trackball PCB in keyball46 is universal. But, it seems like there is no 3D printer files for the trackball mount.

Am I missing something?

Yowkees, 2023-04-06:
Sorry. I have not released stl data of ball case, because it is not good design for 3D printing.

shigmas, 2023-04-12:
Okay. I missed the one day it was available last time. I'll wait for the next time.

Closed 2023-04-06.

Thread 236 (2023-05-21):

Left keyball PCB doesn't work

AlgusDark, 2023-05-21:
Hi, I followed the tutorial for keyball44.
I'm in the testing part. I can't make the left PCB (the one without trackball) to work.

I can write the hex on the pro micro, so that makes sure it works; but I just don't know what else could I do to test. I finished the trackball right hand side and everything works correctly.

Any tips would be helpful 🙏

This are the things I did:

- I tried to click reset button on PCB twice. Doesn't work.
- I tried to jump ground and reset while pro micro mounted on PCB. Doesn't work.
- if I do the above when the pro micro isn't attached to the PCB, I can write the hex. Once I insert it again, I can't make it work.
- I switched pro micro's and both work correct on the right hand side (the one with the trackball)
- I checked all the diode continuity (all working)

I also sent an email through the contact mail from shirogane-lab.com if you need more information from the purchase I can provide.

Thank you!

Yowkees, 2023-05-22:
Hi. OK.
I want to see your PCB picture.
I will e-mail you. Thank you.

Closed 2023-05-22.

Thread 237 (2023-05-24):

スクロールモードから復帰したあと、中クリックの１クリック目が反応しない

bambooRake, 2023-05-24:
・0x5DADを押してのスクロール
・Layer3に移行してのスクロール
どちらの場合でも、復帰後中クリック(MouseBtn3)の１クリック目が反応しない
２クリック目以降は反応する。

備考：
復帰後にMouseBtn1,2をクリックしたりしても変わらず、
MouseBtn3は2回目以降のクリックしか反応しない

私の環境だけでしたら申し訳ないのですが、ご報告までに。

bambooRake, 2023-05-27:
申し訳ございません。常駐ソフト(AHK)による影響でした。
keyball自体は問題ございませんでした。
閉じます。

問題なく動くようになって改めて、すばらしい製品だと思いました。

Closed 2023-05-27.

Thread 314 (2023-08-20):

Support current version of QMK

sohrab-, 2023-08-20:
The QMK configuration in this repository is implemented using a QMK version from 2-3 years ago. It does not work with the current version of QMK.

For users that have advanced QMK configuration, they have to compile the firmware from source, instead of REMAP/VIA. This is currently not possible unless we drop down to a much older version of QMK.

Is it possible to update the QMK config to be compatible with the newer versions of QMK? Starting point would be defining a [`info.json`](https://docs.qmk.fm/#/reference_info_json) file. Thanks!

PS. I believe QMK now [supports](https://docs.qmk.fm/#/feature_pointing_device?id=pmw-3360-and-pmw-3389-sensor) pmw-3360 out of the box.

koron, 2023-09-16:
have supported QMK 0.19.10 now. cf https://github.com/Yowkees/keyball/pull/183
i'm going to upgrade QMK 0.22.x

(it is happen by [remap supporting 0.22.2 or higher](https://remap-keys.app/docs/support-qmk-022))

> I believe QMK now [supports](https://docs.qmk.fm/#/feature_pointing_device?id=pmw-3360-and-pmw-3389-sensor) pmw-3360 out of the box.

i know it. but it had many problems with bundled driver.
so i keep to using own one.

koron, 2023-09-16:
Continue to https://github.com/Yowkees/keyball/issues/342

Closed 2023-09-16.

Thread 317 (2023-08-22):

Support RGB_MATRIX

hden, 2023-08-22:
## これは何か

キー操作と連動した LED アニメーションを利用することが可能になります。

## 課題

```
RGB_MATRIX_ENABLE = no      # Enable RGB_MATRIX (not work yet)
```

[rules.mk](https://github.com/Yowkees/keyball/blob/main/qmk_firmware/keyboards/keyball/keyball61/rules.mk#L38) にも書かれていたとおり現状 RGB_MATRIX への対応が未実装だがたまたま成功例を発見しましたので共有します。

ref: https://note.com/co_ke/n/nf89d0de0d718

koron, 2024-03-21:
There are no plans to support RGB_MATRIX.
Therefore, this issue will be closed for now.

However, pull requests to support it are welcome.

koron, 2024-03-21:
RGB_MATRIXに対応する計画は現時点ではありません。
よって一旦このissueは閉じます。

しかしPRは歓迎します。

Closed 2024-03-21.

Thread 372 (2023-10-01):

keyball39の動作について

nakahata106, 2023-10-01:
先日、遊舎工房でkeyball39を購入し、制作しましたが、キーの動作を確認したところ、３つのキーを除く全てのキーが反応しませんでした。
半田付けが完全かはわかりませんが、工房の方に電気が通るか確認していただいたところ、通っているとのことです。この状態でほとんどのキーが反応しないとなると、その方だと原因が特定できるかわからないので、こちらで相談した方が良いとご提案いただきご連絡差し上げました。
以降の対処についてご指示を頂ければ幸いです。よろしくお願いします。

Closed 2023-10-09.

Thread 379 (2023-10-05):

stl files for the trackball mount

glompos21, 2023-10-05:
I want to try to build a hand wire Keyball44 but i cannot find the stl for the trackball mount. Where i can found it?

mskry, 2024-08-14:
> I want to try to build a hand wire Keyball44 but i cannot find the stl for the trackball mount. Where i can found it?
Here
https://www.thingiverse.com/kepeo/designs

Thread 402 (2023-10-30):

keyball61 rev2 トラックボールをつけるとトラックボール側（右側）の横四つのキーが反応しない

emp-temp, 2023-10-30:
突然すみません。先日keyball61を遊舎工房にて購入し、トラックボールICを壊してしまったためshirogane labより購入させていただいたものです。届いたので取り付けたところ、写真にある通り4つのキーが反応しなくなってしまいました。トラックボール基盤を指す前まではちゃんと使えていました。解決する方法がわからないので教えていただけると幸いです。
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

Yowkees, 2023-11-09:
ご連絡ありがとうございます。
ご質問はDiscussionsに書いていただければ幸いです。気付くのが遅くなってしまいました。

症状了解しました。
下記画像の赤丸２か所が隣の端子とショートしてしまっているように見えます。
ご指摘の４キーはROW3という信号線を使用しており、ちょうど緑矢印の端子がROW3なので症状と合いそうです。

半田ごてでショートしている部分を加熱して、半田を引き離してください。

以上、お手数ですがご対応お願いいたします。

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

Closed 2023-11-09.

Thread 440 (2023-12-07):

Impossible to compile for RP2040

tcastelly, 2023-12-07:
Hello,

I'm trying to compile for RP2040, I've this output:

> qmk compile -kb keyball/keyball44 -km default -e CONVERT_TO=elite_pi

```
Compiling: keyboards/keyball/drivers/pmw3360/pmw3360.c                                             keyboards/keyball/drivers/pmw3360/pmw3360.c: In function 'pmw3360_spi_start':
keyboards/keyball/drivers/pmw3360/pmw3360.c:22:30: error: 'F_CPU' undeclared (first use in this function); did you mean 'HF_CONU'?
 #define PMW3360_SPI_DIVISOR (F_CPU / PMW3360_CLOCKS)
                              ^~~~~
keyboards/keyball/drivers/pmw3360/pmw3360.c:26:64: note: in expansion of macro 'PMW3360_SPI_DIVISOR'
     return spi_start(PMW3360_NCS_PIN, false, PMW3360_SPI_MODE, PMW3360_SPI_DIVISOR);
                                                                ^~~~~~~~~~~~~~~~~~~
keyboards/keyball/drivers/pmw3360/pmw3360.c:22:30: note: each undeclared identifier is reported only once for each function it appears in
 #define PMW3360_SPI_DIVISOR (F_CPU / PMW3360_CLOCKS)
                              ^~~~~
keyboards/keyball/drivers/pmw3360/pmw3360.c:26:64: note: in expansion of macro 'PMW3360_SPI_DIVISOR'
     return spi_start(PMW3360_NCS_PIN, false, PMW3360_SPI_MODE, PMW3360_SPI_DIVISOR);
                                                                ^~~~~~~~~~~~~~~~~~~
keyboards/keyball/drivers/pmw3360/pmw3360.c:27:1: error: control reaches end of non-void function [-Werror=return-type]
 }
 ^
cc1: all warnings being treated as errors
 [ERRORS]
 |
 ```

I'm not sure that setting a value for `F_CPU` is a good solution.

## My setup:
> qmk doctor
```
qmk doctor
Ψ QMK Doctor is checking your environment.
Ψ CLI version: 1.1.2
Ψ QMK home: /Users/tcy/qmk_firmware
Ψ Detected macOS 14.1 (Apple Silicon).
Ψ Userspace enabled: False
Ψ Git branch: master
Ψ Repo version: 0.22.14
Ψ - Latest master: 2023-12-07 11:44:00 +0100 (6baad0f26c) -- Merge branch 'master' of https://github.com/qmk/qmk_firmware
Ψ - Latest upstream/master: 2023-12-06 17:39:59 +0000 (834fb0b1fe) -- [Keyboard] Add Argyle (#22607)
Ψ - Latest upstream/develop: 2023-11-23 05:08:37 +0000 (3a74fa5bf7) -- Merge remote-tracking branch 'origin/master' into develop
Ψ - Common ancestor with upstream/master: 2023-12-06 17:39:59 +0000 (834fb0b1fe) -- [Keyboard] Add Argyle (#22607)
Ψ - Common ancestor with upstream/develop: 2023-11-23 05:08:37 +0000 (3a74fa5bf7) -- Merge remote-tracking branch 'origin/master' into develop
Ψ CLI installed in virtualenv.
Ψ All dependencies are installed.
Ψ Found arm-none-eabi-gcc version 8.3.1
Ψ Found avr-gcc version 8.5.0
Ψ Found avrdude version 7.2
Ψ Found dfu-programmer version 1.1.0
Ψ Found dfu-util version 0.11
Ψ Submodules are up to date.
Ψ Submodule status:
Ψ - lib/chibios: 2023-04-15 13:48:04 +0000 --  (11edb1610)
Ψ - lib/chibios-contrib: 2023-07-17 11:39:05 +0200 --  (da78eb37)
Ψ - lib/googletest: 2021-06-11 06:37:43 -0700 --  (e2239ee6)
Ψ - lib/lufa: 2022-08-26 12:09:55 +1000 --  (549b97320)
Ψ - lib/vusb: 2022-06-13 09:18:17 +1000 --  (819dbc1)
Ψ - lib/printf: 2022-06-29 23:59:58 +0300 --  (c2e3b4e)
Ψ - lib/pico-sdk: 2023-02-12 20:19:37 +0100 --  (a3398d8)
Ψ - lib/lvgl: 2022-04-11 04:44:53 -0600 --  (e19410f8)
Ψ QMK is ready to go
```

I'm up-to-date on the `main` branch of:
> git@github.com:Yowkees/keyball.git

Thank you very much.

idank, 2023-12-11:
It looks like the stock driver in QMK is doing this:

```
#if !defined(PMW33XX_SPI_DIVISOR)
#    ifdef __AVR__
#        define PMW33XX_SPI_DIVISOR (F_CPU / PMW33XX_CLOCK_SPEED)
#    else
#        define PMW33XX_SPI_DIVISOR 64
#    endif
#endif
```

So try setting the divisor to 64?

@Yowkees any reason you're not using the driver provided by QMK?

tcastelly, 2023-12-11:
> So try setting the divisor to 64?

Hello,

Thank you for your help.

I've tried to define F_CPU and PMW33XX_SPI_DIVISOR. And I've a bunch of other errors.

```
platforms/chibios/drivers/spi_master.h:31:25: error: 'B13' undeclared (first use in this function); did you mean 'B1'?
 #    define SPI_SCK_PIN B13
                         ^~~
./lib/chibios/os/hal/ports/RP/LLD/GPIOv1/hal_pal_lld.h:389:32: note: in definition of macro 'pal_lld_setpadmode'
   __pal_lld_pad_set_mode(port, pad, mode)
                                ^~~
./lib/chibios/os/hal/include/hal_pal.h:809:3: note: in expansion of macro 'palSetPadMode'
   palSetPadMode(PAL_PORT(line), PAL_PAD(line), mode)
   ^~~~~~~~~~~~~
./lib/chibios/os/hal/include/hal_pal.h:809:33: note: in expansion of macro 'PAL_PAD'
   palSetPadMode(PAL_PORT(line), PAL_PAD(line), mode)
                                 ^~~~~~~
platforms/chibios/gpio.h:25:26: note: in expansion of macro 'palSetLineMode'
 #define setPinInput(pin) palSetLineMode((pin), PAL_MODE_INPUT)
```

I've tried to add `promicro` as `pin_compatible`, same errors.

https://github.com/tcastelly/qmk_firmware/commit/42219470cd89152f1d8b456a6253b914be34e421

idank, 2023-12-13:
You're trying to convert from promicro to rp2040, but promicro doesn't have a `B13` pin. Just assign `SPI_SCK_PIN` to the GPxx pin.

koron, 2024-03-21:
I don't plan to support RP2040 for now.

So I close this issue, but I am welcome the pull request to fix this.

Closed 2024-03-21.

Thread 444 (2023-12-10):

Sensor pcb broken

tangbonze, 2023-12-10:
Hi there: I try to build a keyball by myself, found sensor pcb gerber you provide is broken. Could you please kindly check? Thanks a lot.

tangbonze, 2023-12-10:
https://github.com/Yowkees/keyball/blob/main/keyball46/ball_design_data/Trackball_PCB_gerber.zip
here's the file.

koron, 2024-03-24:
FYI @Yowkees

KastenTaco, 2024-04-15:
This issue is still persisting it seems?

tangbonze, 2024-04-22:
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
This is gerber file I upload to jlc. You can see it definitely broken.

tangbonze, 2024-05-24:
any update? If this pcb is close source, please just let me know. thanks.

tangbonze, 2024-06-14:
close this by myself since no response at all. If it is close sourced material, you can just say it.

ya-luotao, 2024-11-04:
I also encountered the same issue; it seems that the drill layer is missing in the exported Gerber file.

Closed 2024-06-14.

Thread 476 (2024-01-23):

基盤にmicroproを挿し込むとPC側で認識できなくなる

ancoromochi100, 2024-01-23:
質問失礼致します。
現在keyball61の作成をしています。

【現状】
基盤に挿し込む前にusb接続をするとキーボードとして認識できるのですが、基盤に取り付けると認識できなくなってしまいます。

【原因】
可能性としてはOLEDのソケットの半田付けに失敗してしまったのですが、原因となりうるでしょうか…？

お手数をおかけしてしまい恐縮ですが、お助けいただけると幸いです。
よろしくお願いいたします。

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

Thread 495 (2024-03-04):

Incorrect handedness since qmk 0.24.0

zhyu, 2024-03-04:
The default behavior of `SPLIT_HAND_MATRIX_GRID` has been changed in https://github.com/qmk/qmk_firmware/pull/22775.

We need to define `SPLIT_HAND_MATRIX_GRID_LOW_IS_LEFT` to make keyball works with qmk 0.24.0.

koron, 2024-03-24:
Currently, there are no reasons to use QMK 0.24.x.
So we won't do it now.

Of course, if we find out the benefits of going to 0.24 or higher, we'll do it then.

koron, 2024-03-25:
There are no plans to respond at this time, so I close the issue.

Please let me know and re-open this if there are any benefits for 0.24 or later.

Closed 2024-03-25.

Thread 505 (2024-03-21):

PCに接続しましたが認識されません。KEYBALL44。

etom423, 2024-03-21:
当方初心者です。
作り方に従って作業し、テスト用のファームウェアをkeymicroに書き込むところで、PCが認識していない？ようで、ファームウェアの書き込みができない状態になってしまいました。

BOOTHで販売されているkey microを使用しています。コンスルーに対応しているとのことで、はんだ付けは行っておりません。
ケーブルの抜き差し、リセットボタンを押すと接続、切断の音はなるのですが。。。
どなたかご教授いただけると幸いです。
よろしくお願いいたします。

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

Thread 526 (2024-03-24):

Secondary OLED don't resume when operate primary

koron, 2024-03-24:
1. wait a moment without touching Keyball
2. Logo disappears on secondary
3. Touch primary (type key or move ball)

Expected: at 3, logo is resumed
Actual: keep off

I have the keyball set up so that the LED lights up when the layer changes.
When I tried AML, when I moved the ball, the layers changed and the LEDs lit up.
At that time, it felt very unnatural that the OLED did not turn on.

koron, 2024-03-25:
https://docs.qmk.fm/#/feature_split_keyboard?id=data-sync-options

There is SPLIT_OLED_ENABLE in data sync option.
This might be worth a try.

koron, 2024-03-25:
I confirmed `SPLIT_OLED_ENABLE` works for the issue.

Closed 2024-03-25.

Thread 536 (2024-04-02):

[Keyball44] コンスルーを用いてビルドしたときにファームウェアの書き込みができない

kk-shinoda, 2024-04-02:
## 背景
Keyball44 と別途 12P 2.5mm のコンスルーを購入し、[ビルドガイド](https://github.com/Yowkees/keyball/blob/main/keyball44/doc/rev1/buildguide_jp_sub.md#build-guide-for-keyball44) を参考に組み立てを行っています。

ただ、[3.8章 ProMicroの書き込みと動作確認](https://github.com/Yowkees/keyball/blob/main/keyball44/doc/rev1/buildguide_jp_sub.md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) でファームウェアの書き込みができず困っています。

### ファームウェアの書き込みができない

左右ともに同じ症状が発生しているため、はんだづけ等の問題というより何か勘違いがありそうなので相談させていただきたいです。何か誤った組み立てや確認事項に漏れがあればご教示ください。

**症状**
- PC に接続しても OLED になにも出力されない
- remap から以下のファームウェアの書き込みを試みたが、そもそも接続の候補に Keyball が上がってこない
    - Firmware: Keyball44_test_v1.3.2 for Keyball44
    - Bootloader: caterina

**確認したこと**
- PC への接続
ProMicro に USB を接続すると赤い LED が点灯するため PC への接続は問題なさそうです。

- コンスルーの向き
[ブログ記事](https://yushakobo.zendesk.com/hc/ja/articles/360044233974-%E3%82%B3%E3%83%B3%E3%82%B9%E3%83%AB%E3%83%BC-%E3%82%B9%E3%83%97%E3%83%AA%E3%83%B3%E3%82%B0%E3%83%94%E3%83%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) を参考にピン窓に近い方に ProMicro が来ることと、2つのコンスルーのピン窓が同じ方向(画像手前側)を向いていることを確認しました。

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

- シルクの場所
コンスルーと ProMicro をはんだづけした部品を基盤のシルクに合わせました。また、他方の列に装着してもうまくいかなかったためここは被疑箇所ではないと思っています。

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

kk-shinoda, 2024-04-02:
https://github.com/Yowkees/keyball/discussions/538 にて質問させていただいたため、こちらではクローズさせていただきます。

kk-shinoda, 2024-04-02:
https://github.com/Yowkees/keyball/discussions/538 にて質問させていただいたため、こちらではクローズさせていただきます。

Closed 2024-04-02.

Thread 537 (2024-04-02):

[Keyball44] コンスルーを用いてビルドしたときに OLED と ProMicro 間の隙間が気になる

kk-shinoda, 2024-04-02:
## 背景
Keyball44 と別途 12P 2.5mm のコンスルーを購入し、[ビルドガイド](https://github.com/Yowkees/keyball/blob/main/keyball44/doc/rev1/buildguide_jp_sub.md#build-guide-for-keyball44) を参考に組み立てを行っています。

その際、OLED の高さ(ソケット+ピンヘッダ)に対して ProMicro(コンスルー+ProMicro の高さ) の高さが低いため支えてあげないと OLED が垂れてしまいます。

なにか解決方法があれば教えていただきたいです。

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

Closed 2024-04-02.

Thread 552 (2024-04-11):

QMK Toolboxの使い方のリンク切れ

sounisi5011, 2024-04-11:
例えば、以下の文章内において、「[Corneのファームウェア](https://github.com/foostan/crkbd/blob/master/doc/firmware_jp.md)」へのリンクが切れています。

[https://github.com/Yowkees/keyball/blob/f5665173e073a343132da147f429458be47283cf/keyball61/doc/rev1/buildguide_jp.md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ファームウェア](https://github.com/Yowkees/keyball/blob/f5665173e073a343132da147f429458be47283cf/keyball61/doc/rev1/buildguide_jp.md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)

URLが同じであることから、おそらく他のドキュメントでも同様のことが起こっているものと思われます。

https://github.com/search?q=repo%3AYowkees%2Fkeyball%20crkbd&type=code

koron, 2024-04-12:
本来やりたいことはQMK Toolboxの使い方を説明すること。
Corneのドキュメントにリンクすることではない。
現行の[Corneのドキュメント](https://github.com/foostan/crkbd/blob/5cda058e32b16c7600dd50a4d55f43982eb20254/docs/firmware/rev1/firmware_jp.md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)を見てみたが、
QMK Toolboxの解説として適切とは考えられない。

それを踏まえて検討すると取れる対策は以下のどれか

1. 古いCorneのドキュメントをチェックしたうえで、良さそうならpermalinkでリンクしなおす
2. QMK Toolbox のより良い解説文章を探してリンクする
3. いっそ自分で書いちゃう

koron, 2024-04-12:
> 古いCorneのドキュメントをチェックしたうえで、良さそうならpermalinkでリンクしなおす

* 日本語: https://github.com/foostan/crkbd/blob/fbb146fe372ce8b2b1543ced67367bf19e910945/doc/firmware_jp.md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
* English: https://github.com/foostan/crkbd/blob/fbb146fe372ce8b2b1543ced67367bf19e910945/doc/firmware_en.md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

悪くはなさそう。とりあえずこちらへのリンク差し替えで対応するべきだろう。

koron, 2024-04-12:
チェックしたところリンクが使われているのは 46 と 61 の合計4つのファイルだけだった。
#553 で修正を用意した。

念のため 39 と 44 も再度確認する。

koron, 2024-04-12:
みてみたところ Remap のリンクを案内しているようだった。

例: https://remap-keys.app/catalog/tAJ9Htme4oNabUkx4832/firmware

46は良いとして、61のほうは書き換えたほうが良いかもしれない。

koron, 2024-04-12:
61のドキュメントを見たら、英語版からは当該リンクを含む `2-2 ファームウェア` がなくなってる。
というか最初の commit からなかった。
消しちゃって良さそう。

koron, 2024-04-12:
39と44の日本語版には別の書き方がされてそう。それにあわせるか。

koron, 2024-04-12:
## まとめ

QMK Toolboxの説明に関して、切れていたリンクは4ファイル4か所でした。
その内、現状販売されていないKeyball 46の2ファイル2か所についてはpermalinkを用いてリンクを書き換えました。

現行機種であるKeyball 61については
同じく現行機種であるKeyball 39 や Keyball 44 のドキュメントに合わせて
REMAPへと案内するように文言の修正をした結果、
該当リンクを削除することになりました。

変更の詳細は #553 を参考にしてください。

Closed 2024-04-12.

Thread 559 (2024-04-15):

Scroll snap methods

koron, 2024-04-15:
Current scroll snap supports only vertical.
This is sufficient for many people, but is a bit inflexible

Problems are:

* Does not support horizontal scroll snap
* An extra step to use free scrolling needed

It is not realistic to use the rotation of the trackball to solve these problems.
I tried such an experiment in the past, but it wasn't good.

## Idea 1: how about using keys to switch the scroll snapping methods?

There are three mods:

1. Vertical scroll snap
2. Horizontal scroll snap
3. Free scroll

You can switch/toggle between these modes with some keys.
It is necessary to consider whether to keep the current behavior of transitioning to free scrolling
when moving strongly to the opposite side while scroll snapping in one direction.

## Idea 2: How about creating new customization points for the scroll snap algorithm?

For those who compile Keyball firmware themselves, we can provide a function with a weak attribute.
By implementing the function, they can replace the existing scroll snap with their own.

related PR: #555

koron, 2024-04-15:
Japanse Translation/ 日本語粗訳

現在のスクロールスナップには2つの問題がある

1. 水平にスナップできない
2. 自由スクロールするのに手間がかかる

この解決にボールの回転を利用するのは、過去の実験からほぼ無理筋だと考えている。
それを踏まえて、この問題を解決するのに個別の2つのアイデアがある。

1つ目はスナップ方法をキーで切り替えること。
トグルかモーメンタリかはわからないが
キーで垂直スナップ、水平スナップ、自由スクロールを切り替えれば良いじゃん、Key & ballなんだから。
この場合、既存の大きく反対方向に動かすとスナップが解除される使用を残すかは要検討。

2つ目はボール回転をスクロールへ割り当ててる関数を、weakにしてオーバーライドできるようにする。
カスタマイズできるひとならそこで自由に書き換えられる。

koron, 2024-04-15:
I'm implementing on #560

koron, 2024-04-16:
#560 is merged.

Closed 2024-04-16.

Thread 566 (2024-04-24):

【keyball39】QMK firmwareでビルドしたhexファイルを書き込むとキーマップが反転する

TakumiMurai, 2024-04-24:
### 背景
オートマウスレイヤーやOLEDをカスタマイズしたく、QMK firmwareの環境構築を行い公式のファームウェアをビルドして動作確認しようとしたところ、キーマップやポインタの動きが反転してしまいました(裏返して使っているようなイメージ)

### やったこと

1. QMK firmwareのインストール
2. keyballリポジトリのクローン
3. `make keyball/keyball39:via`コマンドの実行
4. pro micro web updaterを用いて書き込み

### 環境
QMK firmware ver. 0.24.7
windows 11

### その他
公式で案内のあったremap上のファームウェア書き込みでは正しく動作しております。
逆転症状が発生している状態でremapを確認すると、正しいキーマップが表示されます。

何卒よろしくお願いいたします。

okuRaku, 2024-04-24:
Keyball relies on an older version of QMK than 0.24.7.  I noticed the same behavior you did when I tried to use newer QMK, however other features will also break I believe.   Try 0.22.14 instead.   How to check out this specific version for your local build environment is detailed [here](https://github.com/Yowkees/keyball/tree/main/qmk_firmware/keyboards/keyball) in step 2 (basically, check out the versioned tag)

TakumiMurai, 2024-04-24:
Thanks! With 0.22.14, built firmware worked correctly.
I didn't know there is official firmware build guide.

I will close this issue.

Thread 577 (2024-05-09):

基盤から剥がれてしまいました。

Toru-Takagi, 2024-05-09:
初めての自作キーボードになりますので、問い合わせ先が間違えていたら申し訳ございません。

作成している途中でキースイッチを取り付ける際に基盤から剥がれてしまいました。

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

こちら専用の接着剤のようなもので治るものなのでしょうか？
それとも、もう基盤として使い物にならない状態になってしまったのでしょうか？

Closed 2024-05-11.

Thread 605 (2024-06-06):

Windowsでは動作、iPadでは認識しない。

Okada-K2, 2024-06-06:
Keyball39を利用しています。Windows 11では動作して、iPadでは動作しないというエラーで困っております。私はkeyball61も同時に利用しており、そちらではWindows11、iPadともに動作しております。ケーブルを付け替えたり、2台のipad に接続して比較しても同様に動作しない状態です。何か解決のヒントをいただけませんか。

tadanaka, 2024-06-30:
Pro micro type-c のものって、中華製だとコストを下げるために抵抗を省略した結果、接続先もtype-cだとデータ通信されないんじゃなかったでしたっけ？

windows11のpcにtype-cのポートがあれば試してみてくた゛さい。

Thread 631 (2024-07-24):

Error when building locally

Asqiir, 2024-07-24:
I try to build the `keyball/keyball39:default` firmware locally.

This behaviour happens both for

* `qmk compile -kb keyball/keyball39 -km default`
* and  `make SKIP_GIT=yes keyball/keyball39:default`

This happens:

```
$ qmk compile -kb keyball/keyball39 -km default
Ψ Compiling keymap with make --jobs=1 keyball/keyball39:default

QMK Firmware 0.15.13
☒ Not including data from file: keyboards/keyball/keyball39/info.json
☒     rgblight: Additional properties are not allowed ('driver' was unexpected)
Making keyball/keyball39 with keymap default

☒ Not including data from file: keyboards/keyball/keyball39/info.json
☒     rgblight: Additional properties are not allowed ('driver' was unexpected)
avr-gcc (GCC) 8.5.0
Copyright (C) 2018 Free Software Foundation, Inc.
This is free software; see the source for copying conditions.  There is NO
warranty; not even for MERCHANTABILITY or FITNESS FOR A PARTICULAR PURPOSE.

In file included from keyboards/keyball/lib/keyball/keyball.c:23:
keyboards/keyball/lib/keyball/keyball.h:93:16: error: ‘QK_KB_0’ undeclared here (not in a function); did you mean ‘KC_KP_0’?
     KBC_RST  = QK_KB_0, // Keyball configuration: reset to default
                ^~~~~~~
                KC_KP_0
keyboards/keyball/lib/keyball/keyball.h:94:16: error: ‘QK_KB_1’ undeclared here (not in a function); did you mean ‘MI_B_1’?
     KBC_SAVE = QK_KB_1, // Keyball configuration: save to EEPROM
                ^~~~~~~
                MI_B_1
keyboards/keyball/lib/keyball/keyball.h:96:16: error: ‘QK_KB_2’ undeclared here (not in a function); did you mean ‘MI_B_2’?
     CPI_I100 = QK_KB_2, // CPI +100 CPI
                ^~~~~~~
                MI_B_2
keyboards/keyball/lib/keyball/keyball.h:97:16: error: ‘QK_KB_3’ undeclared here (not in a function); did you mean ‘MI_B_3’?
     CPI_D100 = QK_KB_3, // CPI -100 CPI
                ^~~~~~~
                MI_B_3
keyboards/keyball/lib/keyball/keyball.h:98:16: error: ‘QK_KB_4’ undeclared here (not in a function); did you mean ‘MI_B_4’?
     CPI_I1K  = QK_KB_4, // CPI +1000 CPI
                ^~~~~~~
                MI_B_4
keyboards/keyball/lib/keyball/keyball.h:99:16: error: ‘QK_KB_5’ undeclared here (not in a function); did you mean ‘MI_B_5’?
     CPI_D1K  = QK_KB_5, // CPI -1000 CPI
                ^~~~~~~
                MI_B_5
keyboards/keyball/lib/keyball/keyball.h:103:16: error: ‘QK_KB_6’ undeclared here (not in a function); did you mean ‘KC_KP_6’?
     SCRL_TO  = QK_KB_6, // Toggle scroll mode
                ^~~~~~~
                KC_KP_6
keyboards/keyball/lib/keyball/keyball.h:104:16: error: ‘QK_KB_7’ undeclared here (not in a function); did you mean ‘KC_KP_7’?
     SCRL_MO  = QK_KB_7, // Momentary scroll mode
                ^~~~~~~
                KC_KP_7
keyboards/keyball/lib/keyball/keyball.h:105:16: error: ‘QK_KB_8’ undeclared here (not in a function); did you mean ‘KC_KP_8’?
     SCRL_DVI = QK_KB_8, // Increment scroll divider
                ^~~~~~~
                KC_KP_8
keyboards/keyball/lib/keyball/keyball.h:106:16: error: ‘QK_KB_9’ undeclared here (not in a function); did you mean ‘KC_KP_9’?
     SCRL_DVD = QK_KB_9, // Decrement scroll divider
                ^~~~~~~
                KC_KP_9
keyboards/keyball/lib/keyball/keyball.h:108:16: error: ‘QK_KB_13’ undeclared here (not in a function); did you mean ‘MI_B_3’?
     SSNP_VRT = QK_KB_13, // Set scroll snap mode as vertical
                ^~~~~~~~
                MI_B_3
keyboards/keyball/lib/keyball/keyball.h:109:16: error: ‘QK_KB_14’ undeclared here (not in a function); did you mean ‘MI_B_4’?
     SSNP_HOR = QK_KB_14, // Set scroll snap mode as horizontal
                ^~~~~~~~
                MI_B_4
keyboards/keyball/lib/keyball/keyball.h:110:16: error: ‘QK_KB_15’ undeclared here (not in a function); did you mean ‘MI_B_5’?
     SSNP_FRE = QK_KB_15, // Set scroll snap mode as disable (free scroll)
                ^~~~~~~~
                MI_B_5
keyboards/keyball/lib/keyball/keyball.h:114:16: error: ‘QK_KB_10’ undeclared here (not in a function); did you mean ‘MI_B_1’?
     AML_TO   = QK_KB_10, // Toggle automatic mouse layer
                ^~~~~~~~
                MI_B_1
keyboards/keyball/lib/keyball/keyball.h:115:16: error: ‘QK_KB_11’ undeclared here (not in a function); did you mean ‘MI_B_1’?
     AML_I50  = QK_KB_11, // Increment automatic mouse layer timeout
                ^~~~~~~~
                MI_B_1
keyboards/keyball/lib/keyball/keyball.h:116:16: error: ‘QK_KB_12’ undeclared here (not in a function); did you mean ‘MI_B_2’?
     AML_D50  = QK_KB_12, // Decrement automatic mouse layer timeout
                ^~~~~~~~
                MI_B_2
keyboards/keyball/lib/keyball/keyball.h:119:26: error: ‘QK_USER_0’ undeclared here (not in a function)
     KEYBALL_SAFE_RANGE = QK_USER_0,
                          ^~~~~~~~~
keyboards/keyball/lib/keyball/keyball.c: In function ‘keyball_oled_render_layerinfo’:
keyboards/keyball/lib/keyball/keyball.c:500:9: error: implicit declaration of function ‘get_auto_mouse_enable’ [-Werror=implicit-function-declaration]
     if (get_auto_mouse_enable()) {
         ^~~~~~~~~~~~~~~~~~~~~
keyboards/keyball/lib/keyball/keyball.c:506:26: error: implicit declaration of function ‘get_auto_mouse_timeout’; did you mean ‘has_oneshot_mods_timed_out’? [-Werror=implicit-function-declaration]
     oled_write(format_4d(get_auto_mouse_timeout() / 10) + 1, false);
                          ^~~~~~~~~~~~~~~~~~~~~~
                          has_oneshot_mods_timed_out
keyboards/keyball/lib/keyball/keyball.c: In function ‘keyboard_post_init_kb’:
keyboards/keyball/lib/keyball/keyball.c:584:9: error: implicit declaration of function ‘set_auto_mouse_enable’ [-Werror=implicit-function-declaration]
         set_auto_mouse_enable(c.amle);
         ^~~~~~~~~~~~~~~~~~~~~
keyboards/keyball/lib/keyball/keyball.c:585:9: error: implicit declaration of function ‘set_auto_mouse_timeout’; did you mean ‘has_oneshot_mods_timed_out’? [-Werror=implicit-function-declaration]
         set_auto_mouse_timeout(c.amlto == 0 ? AUTO_MOUSE_TIME : (c.amlto + 1) * AML_TIMEOUT_QU);
         ^~~~~~~~~~~~~~~~~~~~~~
         has_oneshot_mods_timed_out
keyboards/keyball/lib/keyball/keyball.c:585:47: error: ‘AUTO_MOUSE_TIME’ undeclared (first use in this function); did you mean ‘ACT_MOUSEKEY’?
         set_auto_mouse_timeout(c.amlto == 0 ? AUTO_MOUSE_TIME : (c.amlto + 1) * AML_TIMEOUT_QU);
                                               ^~~~~~~~~~~~~~~
                                               ACT_MOUSEKEY
keyboards/keyball/lib/keyball/keyball.c:585:47: note: each undeclared identifier is reported only once for each function it appears in
keyboards/keyball/lib/keyball/keyball.c: In function ‘is_mouse_record_kb’:
keyboards/keyball/lib/keyball/keyball.c:634:12: error: implicit declaration of function ‘is_mouse_record_user’; did you mean ‘is_mouse_record_kb’? [-Werror=implicit-function-declaration]
     return is_mouse_record_user(keycode, record);
            ^~~~~~~~~~~~~~~~~~~~
            is_mouse_record_kb
keyboards/keyball/lib/keyball/keyball.c: In function ‘process_record_kb’:
keyboards/keyball/lib/keyball/keyball.c:681:40: error: ‘AUTO_MOUSE_TIME’ undeclared (first use in this function); did you mean ‘ACT_MOUSEKEY’?
                 set_auto_mouse_timeout(AUTO_MOUSE_TIME);
                                        ^~~~~~~~~~~~~~~
                                        ACT_MOUSEKEY
keyboards/keyball/lib/keyball/keyball.c:741:44: error: implicit declaration of function ‘MIN’; did you mean ‘PIN0’? [-Werror=implicit-function-declaration]
                     set_auto_mouse_timeout(MIN(v, AML_TIMEOUT_MAX));
                                            ^~~
                                            PIN0
keyboards/keyball/lib/keyball/keyball.c:747:44: error: implicit declaration of function ‘MAX’ [-Werror=implicit-function-declaration]
                     set_auto_mouse_timeout(MAX(v, AML_TIMEOUT_MIN));
                                            ^~~
cc1: all warnings being treated as errors
Compiling: keyboards/keyball/lib/keyball/keyball.c                                                  [ERRORS]
 |
 |
 |
make[1]: *** [tmk_core/rules.mk:457: .build/obj_keyball_keyball39_default/lib/keyball/keyball.o] Error 1
Make finished with errors
make: *** [Makefile:478: keyball/keyball39:default] Error 1
```

I installed `gnumake`, `qmk`, and avr-gcc.

You can get the exactly same build environment with the following `nix develop` environment:
```nix
{
  inputs = {
    nixpkgs.url = "github:nixos/nixpkgs/nixos-unstable";
  };
  outputs = {nixpkgs,...}: let
    supportedSystems = [ "x86_64-linux" "x86_64-darwin" "aarch64-linux" "aarch64-darwin" ];
    forAllSystems = nixpkgs.lib.genAttrs supportedSystems;
    nixpkgsFor = forAllSystems (system: import nixpkgs { inherit system; });
  in {
    devShells = forAllSystems (system: let
      pkgs = nixpkgsFor.${system};
    in {
      default = pkgs.mkShell {
        packages = with pkgs; [
          gnumake
          qmk
          pkgsCross.avr.buildPackages.gcc
        ];
      };
    });
  };
}
```

Is there anything I am missing that should be installed, upgraded or downgraded?

Any more information I should add?

Asqiir, 2024-07-25:
This only happens on main, it is not an issue on tag `v1.3.2`. Most likely a qmk firmware version issue.

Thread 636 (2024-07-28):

トラックボールの一時的速度変更について

masatosuzuta, 2024-07-28:
先日Keyball 39を購入させていただき、試行錯誤しながら大変便利に使わさせていただいてます。

1つ質問なのですが、特定のキーを押している間のみトラックボールのCPIを上げるまたは下げることは可能でしょうか？

私がトラックボールの使用が初めてなのと、アイコンの小さいソフトウェアを使うことが多く、調度良いCPIがなかなか見つからず、精密な作業用の遅いCPIと通常のカーソル移動用の速いCPIの2つを切り替えられたら便利だと考えた次第です。

お忙しい中恐縮ですが、ご教授いただければ幸いです。よろしくお願い致します。

yoichi, 2024-10-14:
例えばkeymap.cで以下のようにすると、Kb 18を押している間だけCPI=200になり、離すと元に戻ります。

```
bool process_record_user(uint16_t keycode, keyrecord_t *record) {
    static uint8_t prev_cpi_value;
    switch (keycode) {
    case QK_KB_18:
        if (record->event.pressed) {
            prev_cpi_value = keyball_get_cpi();
            keyball_set_cpi(2); // 一時的に使うCPIを100で割った値を指定
        } else {
            keyball_set_cpi(prev_cpi_value);
        }
        return false;
    default:
        break;
    }
    return true;
}

```
　

（keyball_set_cpi()のヘッダコメントが間違っていたので後でPull Request出しておきます）

masatosuzuta, 2024-10-15:
yoichi様

大変有難うございます！早速試してみます！

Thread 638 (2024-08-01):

keyball44 / 特定キー（２箇所）反応無し、ダイオード確認済、基盤剥がれあり

ny1030, 2024-08-01:
初めてkeyball44を組み立てており、こちらのトラブルについて解決方法など相談させてください 🙇🏻

## 起きている事象
右手用の基盤について画像の赤丸２箇所のキーが反応しない状態です
また1箇所はキーソケットを一度交換しようとして、基盤のプリントが剥がれてしまっています

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

## 確認したこと
- ダイオードの導通チェック：それぞれのソケットに繋がっているダイオードとの導通およびダイオード単体での導通はできていることをテスターで確認しました
- スイッチ押下時の導通：スイッチを押した状態でテスターを当てて導通できていることを確認しました
- Microproのピンとの導通：どちらのソケットもcol02と繋がっているようだったので導通を確認しましたが、**どちらもcol02と導通ができませんでした**
  - なお、同じ列でcol02と導通できているソケットはあるので、ソケット側の問題と判断しました

## 相談事項
問題の2箇所についてそれぞれ以下を教えていただけないでしょうか
- 基盤が剥がれている箇所については、何かリカバリする方法はありましたら教えてもらえないでしょうか
- 基盤が剥がれていない箇所については、はんだづけはやり直したものの依然としてcol02と同通できません。他に確認する観点などありましたら教えていただけないでしょうか

以上となります。よろしくお願いします

ny1030, 2024-08-01:
https://github.com/Yowkees/keyball/discussions/639 で質問しましたのでクローズします

Closed 2024-08-01.

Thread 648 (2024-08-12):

ProMicro Data端子とtrrsジャック間が導通していない

takeru1968, 2024-08-12:
質問失礼致します。
当方、初めての自作キーボード作成のため、
情報不足等至らない点があるかと思われますが、
ご教授して頂けると幸いです。
## 概要
左手側基盤(非トラックボール側)ProMicroのData端子とtrrsジャックData端子が導通していない
## 詳細
- 下記issueと同様の症状が発生(USB接続とは反対側のキーがすべて反応しない)
[TRSケーブルで繋いだ方のキーボードが認識されない #245](https://github.com/Yowkees/keyball/discussions/245)
[片方のキーボードが認識されない #301](https://github.com/Yowkees/keyball/discussions/301)
- issue同様に左右ProMicroのData端子をテスターで導通確認したところ、導通していない。
- さらに細かく調べたところ、右手側ProMicroのData端子から左手側trrsジャックまでは導通していることを確認。
- 左手側ProMicroのData端子とGNDは導通(画像赤丸部をテスターでテスト)
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
- 左手側のProMicroとtrrsジャックの端子が導通していない(テスターで画像の赤丸同士をテスト)
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
- 上記の場合の対応策、追加で確認が必要な箇所等がある場合はお教えしていただきたいです。

以上、ご回答のほど、よろしくお願い致します。

Yowkees, 2024-10-02:
投稿に気付けずご回答がとても遅くなり申し訳ありません。
すでに解決済かも知れませんがご回答させていただきます。

下記画像の緑丸部のパターンが剥がれてDATA線が断線していると思われます。
そのため、青点どうしをエナメル線等で接続していただくと解決します。
お手数ですがご対応お願いいたします。
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

takeru1968, 2025-02-26:
> 投稿に気付けずご回答がとても遅くなり申し訳ありません。 すでに解決済かも知れませんがご回答させていただきます。
>
> 下記画像の緑丸部のパターンが剥がれてDATA線が断線していると思われます。 そのため、青点どうしをエナメル線等で接続していただくと解決します。 お手数ですがご対応お願いいたします。 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

返信いただき、ありがとうございます。
回答の期間の方が空いてしまい申し訳ありません。
上記青い点を銅線ではんだ付けの上、
導通を確認したのですが、
症状が改善していない状態となっています。
追加で確認が必要な箇所がある場合、
ご教授頂ければと思います。

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

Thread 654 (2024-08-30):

一部キーが反応しない

apo2983, 2024-08-30:
ピンセットでキーソケット左右をショートさせると文字が入力できるけど、
キースイッチをつけてスイッチを押した場合には文字が入力できない場合は
何を疑えばいいのでしょうか？

yoichi, 2024-09-11:
キースイッチの足が曲がって、キーソケットにちゃんと刺さってなくてそういう状況になったことあります。

参考：https://zenn.dev/kyoh86/articles/9b9da6d1e9d598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
（自分はこの記事見てキースイッチを抜いたら見事に足が曲がっていました。）

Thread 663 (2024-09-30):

トラックボール感度や動作が頻繁に不安定になってしまう

cocomode18, 2024-09-30:
先日初めてkeyball39を購入しこちらの正規ファームウェア（Keyball39_via_v1.3.2）を利用させて頂いてますが、以下の2つの問題があります。

- 1. トラックボールに一定時間（体感としては数秒〜数分ほど）触れずにいると、反応が悪くなる
  - OLEDを見るとトラックボールを正しく認識していない様子
  - トラックボールを物理的に外して戻すとだいたい解決し、その後しばらくは問題なく動作する
- 2. トラックボールに一定時間（体感としては数秒〜数分ほど）触れずにいたり、物理的に外して戻すとトラックボール感度（CPIやスクロール除数）が設定していた状態から変化する
  - OLED上に表示されているCPI/SCROLL_DVI値は変わらないが、トラックボール/スクロール感度が明らかに早くなる
  - 一度特殊キーでCPI/SCROLL_DVI値を上下すると元に戻る

これらの問題を解決する方法はありますでしょうか？
問題の切り分けもできておらず、はんだ付け不良なのかファームウェア側なのかだけでもわかると追求しやすいのですが、アドバイスいただけないでしょうか？

cocomode18, 2024-10-02:
（追記）
トラックボールのセンラーレンズ（透明の部品）がセンサーから外れやすい状態になっており、軽くマスキングテープでそれを仮止めしてみたら１つ目の問題は解決しました。もう少し安定して固定できるよう何か対策をして見ようと思います。

２つ目の問題はまだ未解決ですが、ファームウェアを自分で書き換えてデフォルトのCPIを変更してみようと思います。

Closed 2024-10-11.

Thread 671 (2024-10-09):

Help with LED issue

JulioPDX, 2024-10-09:
This was my fault but how would I connect LED 3 directly to LED 5 on the ball side? I burned out one of the pads on LED 4 :(. Thank you for making this awesome board!

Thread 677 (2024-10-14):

ジャンパの基盤を剥離させてしまった。トラックボールが反応しない。keyball39

Dr-cafelatte, 2024-10-14:
先日keyball39を購入させていただきました。
右手トラックボール側の光学センサー用信号線のジャンパ形成が上手くいかず、基盤が剥離してしまいました。
お手数ではございますが対処法があれば教えていただけますでしょうか。
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

Dr-cafelatte, 2024-10-15:
追記。
はんだが得意な人と確認し、画像のように右手トラックボール側表面を、クロスを作るようにジャンパを形成しましたが、変わらずOLEDの移動量も全て0のままでした。
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

Yowkees, 2024-10-29:
ご連絡が遅くなり申し訳ありません。

修理の方法は適切です。
下記の同色同士が導通しているか、また違う色どうしがショートしてしまっていないかご確認をお願いします。

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

Dr-cafelatte, 2024-11-21:
違う色同士のショートは確認できませんでした。
また、青色同士のみ導通しておりませんでした。

Yowkees, 2024-11-22:
ご確認ありがとうございます。
青点どうしが導通していなかったということで、下記画像の青点どうしをエナメル線か導線で接続してください。
これでトラックボール復活できると思います。
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

Dr-cafelatte, 2024-11-22:
ありがとうございます！
無事トラックボールが反応するようになりました。
部品を買い替えることなく修理できると思っていなかったので本当に感謝しております。
忙しい中、迅速な対応ありがとうございました。

Closed 2024-11-22.

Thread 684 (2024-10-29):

特定のキーが勝手に反応しない&特定のキーが勝手に反応してしまう

tatatata222, 2024-10-29:
初めての自作キーボードでトラブルが発生してしまい困っています。

どなたかご教授いただけますと幸いです。

現在keyball39を使用しております。

現在起きている問題は下記のとおりです。

▶︎レイヤー1が勝手に反応してしまう

現在レイヤー1にテンキーを仕込んでいます。

ただタイピングをしている時に勝手にレイヤー1になってしまい、文字入力をする時に数字をご入力してしまいます。

キー側の問題なのかな？と思いつつ現在仕込んでいる親指の一番左側からキーの場所を変更し直したり、半田付けをしなおしたりしてみたのですが、症状が改善しません。

▶︎レイヤー2と3が反応しない時がある

上記の問題に付随してなのですが今度はレイヤーが反応しない時があります。

これもキーや半田付けのミスによるものなのかな？と思いつつキーを変更しても症状が改善しませんでした。

接触不良が問題ではなさそうなので、膨大な労力をかけて作成したにも関わらずお手上げ状態です。。。

現在もこちらの文章はkeyballを使っているので我慢すれば使えるっちゃ使えるので巣が困っています。

どなたかお答えいただけますと幸いです。

tatatata222, 2024-10-29:
またこちらのキーボールですが使っているマックブックの電源を落とすと再度接続しない押さないと接続がされないのと、何度の接続をしなおしても接続がされない時があります。

一度つながると接続不良になることはないので接触自体に問題はないとは思うのですが、そこそこ不便で困っています。この点に関してもお答えいただけますと幸いです。

tatatata222, 2024-10-29:
追加です。レイヤー以外に他のキーが勝手に押される現象はございません。

Yowkees, 2024-10-30:
ご連絡ありがとうございます。

ちょっとこれまで聞いたことがない現象です。
レイヤー切り替えボタンを他のキーに移動しても再現しますか？
キーマップのスクリーンショットを共有いただければ幸いです。

以上、お手数ですがご確認お願いいたします。

tatatata222, 2024-10-30:
お世話になります。

レイヤー切り替えボタンを移動しても再現されました。

ただファームウェアの方を最新に更新したら不具合が完全に解消しました。

早急にご対応いただき感謝申し上げます。

引き続きどうぞよろしくお願い申し上げます。

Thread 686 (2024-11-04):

Missing Drill Layer in Trackball PCB gerber file

ya-luotao, 2024-11-04:
Thank you so much for sharing this fantastic open-source keyboard project! I really appreciate all the hard work and dedication you’ve put into creating and sharing this.

I recently used the provided gerber files to order PCBs in JLCPCB and building Keyball39 , but unfortunately, I encountered an issue. It seems that the gerber file of Trackball PCB is missing the drill layer. Would you have a chance to take a look?

Thanks again for this project and your time!

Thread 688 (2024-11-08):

【Keyball39】左側のLEDが全て点灯しない

isheik, 2024-11-08:
Keyball39愛用させていただいています。素敵なデバイスをありがとうございます！

左右のキーボード共にLEDが全て点灯する状態でしばらく使用しておりました。ある日気がつくと左側（非トラボ側）のLEDのみ全てつかなくなっていることに気が付きました。左右共にキーボード入力自体は問題なく機能しています。

はんだ付けの見直しや1番目のLEDを交換してみたところ、一度また点灯するようになったのですが、少し使用しているとまた点灯しなくなりました。それ以降稀に点灯することはあるものの、大体非点灯となっている状態です。

はんだ付けのどこかが悪いのかなと考えているのですが、不審な点やPro MicroのどのピンのはんだがLEDへの電気入力などに対応しているのかなどご助言いただけますと幸いです。

参考として左側のはんだ付けの状態の写真をいくつか共有させていただきたいと思います。

お手数ですがよろしくお願いいたします。

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

isheik, 2024-11-14:
投稿場所が適切でなかったため、#694で質問し直させていただきました。そのためこちらはCloseさせていただきます。

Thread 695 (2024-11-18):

スクロール停止直後にcursorが, ピクピク動く現象が発生

kyo219, 2024-11-18:
現象を説明するために動画を添付します.
(説明性のため, 感度をあえて高くしています)
https://github.com/user-attachments/assets/6cd648a3-709f-4034-a897-d821f863d7ee

- 同様の現象が起きている方はいらっしゃいますでしょうか?
- 黒色のトラックボールを使用していますが, 他色の方が読み取り精度が良い等あればご教示いただきたいです.
(というのも, センサー部分を直接指で触ってスクロールした場合, この現象が起きないため相性的な所を疑っています)

kyo219, 2024-11-21:
トラックボール台がブカブカなことが問題な気がしてきました.
現状ネジをしっかり閉めた状態ですが, 机の揺れ等でもトラックボールが揺れます（それによりcursorがピクピクする.

Yowkees, 2024-11-21:
ご連絡ありがとうございます。

トラックボールが不安定ですか？
ブカブカというか、ボールはプラスチックケースには触らず、セラミックボール３個で支持されています。
私の手持ちのKeyballではキーボードを揺すってもボールやカーソルは動きません。
もしかするとセラミックボールが無くなっている、もしくはセラミックボール以外にボールに触れているものが無いかご確認お願いします。

kyo219, 2024-11-22:
@Yowkees

ご回答ありがとうございます.!
こちら確認したところ, セラミックボールが無くなっておりました..

以下のような, 2mmタイプのセラミックボールを3つ購入すれば代替となりえますでしょうか？
https://www.monotaro.com/g/01218880/

kyo219, 2024-12-12:
こちら、2mmタイプのセラミックボールを追加購入して、挿入したところ改善されました。
従ってclose

Closed 2024-12-12.

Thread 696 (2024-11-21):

Keyball44 EN build guide does not have conthrough direction instructions

tschmoog, 2024-11-21:
Hello!

Thank you for creating such a cool and wonderful product. I am very excited to use and learn it, and had a lot of fun building it.

I was following your English guide on how to build Keyball44, however, in this version there is no instruction showing which direction the conthrough pins should go. I can see this step is present in the JP versions and other Keyball versions.

Unfortunately, I saw this too late and so I put some of my conthrough pins in the wrong direction which caused some connection issues. I was able to fix it by soldering both sides (pro micro and PCB side) for anyone who has also made this error.

Can this step be added to that guide for future users?

Thank you again and have a good day!

Yowkees, 2024-11-21:
Thank you very much for choosing Keyball!
And thank you for your fixing buildguide.

Closed 2024-11-21.

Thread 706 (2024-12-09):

右のキーボードの1つのキーが同一キーとして認識されてしまう

akaneko5200, 2024-12-09:
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

お世話になっております、今回初の自作キーボードに挑戦しかなりのかずの接点不良も解消してきたのですが9割方解消したのですが1箇所だけ改善しない問題が発生しました。
添付画像の赤枠のキーが塗りつぶしの位置のキーとして認識されます。
（例:赤枠=H、塗りつぶし=Lとした場合Lを押してもHとして認識されてしまう）
この場合はどこのはんだ付けを直したら改善しますでしょうか？お知恵を拝借できればと存じます。

yoichi, 2025-03-20:
https://github.com/Yowkees/keyball/blob/main/keyball61/design_data/Circuit%20of%20Keyball61%20Rev2%20Ball_side.pdf
だとともに COL2-ROW2 なので、ダイオードの向きが逆になってないですかね？

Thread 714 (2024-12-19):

keyball44のトラックボールを付ける側のみの販売はされておりますでしょうか。

GUTRA004, 2024-12-19:
keyball44を購入し、組み立ている者です。
トラックボールを付ける側の組み立て途中に、誤ってTRRSソケットを基板の裏側に取り付けてしまいました。
keyball44のトラックボールを付ける側の、基板、ダイオード、キーソケット、TRRSソケット、タクトスイッチ、4連ピンソケット、L字コンスルーのみの販売はされておりますでしょうか。
お忙しいところ恐縮ですが、ご返信のほどよろしくお願いいたします。

Closed 2025-01-02.

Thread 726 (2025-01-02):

qmk_firmwareのビルドが、`RGBLIGHT_LED_COUNT`という変数に関するエラーで成功しない

taichi-k, 2025-01-02:
（注：私は、自作キーボード・qmk_firmwareに関して、全くの素人です。的外れな起票をしていたら申し訳ございません。）

https://note.com/yinouet1001/n/n856b45220ad4
に従い、mac環境にて、qmkを利用したkeyballのfirmwareのビルドを試みたのですが、以下のエラーがでて`.hex`ファイルの生成ができませんでした。

```
QMK Firmware 0.27.4
⚠ keyball/keyball39: Build marker "keyboard.json" not found.
☒ keyball/keyball39: LAYOUT_right_ball: Layout macro should not be defined within ".h" files.
☒ keyball/keyball39: LAYOUT_left_ball: Layout macro should not be defined within ".h" files.
☒ keyball/keyball39: LAYOUT_dual_ball: Layout macro should not be defined within ".h" files.
☒ keyball/keyball39: LAYOUT_no_ball: Layout macro should not be defined within ".h" files.
Making keyball/keyball39 with keymap default

⚠ keyball/keyball39: Build marker "keyboard.json" not found.
☒ keyball/keyball39: LAYOUT_right_ball: Layout macro should not be defined within ".h" files.
☒ keyball/keyball39: LAYOUT_left_ball: Layout macro should not be defined within ".h" files.
☒ keyball/keyball39: LAYOUT_dual_ball: Layout macro should not be defined within ".h" files.
☒ keyball/keyball39: LAYOUT_no_ball: Layout macro should not be defined within ".h" files.
avr-gcc (Homebrew AVR GCC 8.5.0_2) 8.5.0
Copyright (C) 2018 Free Software Foundation, Inc.
This is free software; see the source for copying conditions.  There is NO
warranty; not even for MERCHANTABILITY or FITNESS FOR A PARTICULAR PURPOSE.

Compiling: platforms/avr/drivers/ws2812_bitbang.c                                                  In file included from platforms/avr/drivers/ws2812_bitbang.c:26:
drivers/ws2812.h:60:30: error: 'RGBLIGHT_LED_COUNT' undeclared here (not in a function); did you mean 'RGBLIGHT_SAT_STEP'?
 #    define WS2812_LED_COUNT RGBLIGHT_LED_COUNT
                              ^~~~~~~~~~~~~~~~~~
platforms/avr/drivers/ws2812_bitbang.c:154:26: note: in expansion of macro 'WS2812_LED_COUNT'
 ws2812_led_t ws2812_leds[WS2812_LED_COUNT];
                          ^~~~~~~~~~~~~~~~
 [ERRORS]
 |
 |
 |
make[1]: *** [.build/obj_keyball_keyball39_default/ws2812_bitbang.o] Error 1
make: *** [keyball/keyball39:default] Error 1
Make finished with errors
```

mac環境以外にも、Linux環境でも同様のエラーが発生してしまったため、起票に至ります。

toxaO, 2025-01-14:
qmkのバージョンの問題だと思われます。
0.27系で試したところ同様のエラーが出ました。
0.24系でコンパイルすると通ると思われます。
根本的な原因に関しては調べたのですが解決しませんでした……

yoichi, 2025-03-19:
参照されている手順
https://note.com/yinouet1001/n/n856b45220ad4
が、qmk/qmk_firmware の最新をcloneする手順のようですが、keyballの公式のファームウェアビルド手順
https://github.com/Yowkees/keyball/tree/main/qmk_firmware/keyboards/keyball#how-to-build
に従ってQMK 0.22.14を使うようにする
```
$ git clone https://github.com/qmk/qmk_firmware.git --depth 1 --recurse-submodules --shallow-submodules -b 0.22.14 qmk
```
とどうでしょうか？

taichi-k, 2025-06-23:
@toxaO @yoichi
コメントいただきありがとうございます！
教えていただいた通り、qmk_firmwareのバージョンによる問題の可能性が高そうですね...

諸事情により、私の手元では問題解決を試せなくなっているのですが、
👍 リアクションが、toxaO様のコメントについていることから、バージョンを揃えることで解決できそうかなと思います。

一定期間コメントが付かなければ、解決としてCloseさせていただきます。
助かりました🙇 ありがとうございました。

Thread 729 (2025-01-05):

TRRS経由で接続した方のキーボードが動作しません。

nobinovice3323, 2025-01-05:
当方知識が浅く、独力での解決が困難なため質問をさせて頂きます。
ビルドガイドに従い、一通りの組み立てを行いました。PCBを個別にPCに接続すると一通り動作してくれるのですが、TRRSを経由して接続させると、接続された側？に電源が供給されていない状態です。
過去のIssuesからpro microのはんだ付け、TRRSジャックのはんだ付けをそれぞれ見直しましたが、改善しませんでした。
右のTRRSジャックのはんだ部分は、やり直しをしすぎて基盤を削ってしまっている状態です。
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

解決方法をご教示頂ければ幸いです。

Closed 2025-01-08.

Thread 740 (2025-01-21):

右手親指のキーを押した時に、振動で自動マウスレイヤーが反応してしまうことがある

yasukawa-sashimi, 2025-01-21:
自作キーボードに初挑戦し、その後試行錯誤しながらこのデバイスの奥深さにハマっております。
使用しているのはkeyball44です。

自動マウスレイヤー機能が大変便利でONにしているのですが、右手親指のトラックボールに近い方のキーを押した際に、おそらくわずかな振動に反応してマウスレイヤーに切り替わってしまうことがあります。数回に1回程度。OLED上でもレイヤー1が一瞬表示されているのを確認。

該当キーはレイヤー0では「かな」を、マウスレイヤーのレイヤー1では「MouseBtn 4（戻るボタン）」を割り当てているため、日本語入力にしようとすると不意に戻るボタンが発動してしまい結構致命的なストレスになっております。

該当キー押下以外にもデバイスに振動を与えると同じようにマウスレイヤーに切り替わってしまうようです。
クッションゴムの位置やネジを締め直すなどしてみましたが、頻度は減りましたが完全には治っておりません。

1. これは個体差や組み立てやパーツの影響なのでしょうか（該当キーはKailhロープロファイルの赤）。
2. ケースなどを別途用意することで解消できるものでしょうか。
3. センサー基盤はコンスルーで差し込んでいますが、これをはんだ付けすることで解消する可能性はあるでしょうか。
4. あるいは、ファームウェアでセンサー感度やマウスレイヤーに切り替わるまでの時間調整（タイムアウトの逆）を調整できたりするのでしょうか。

自動マウスレイヤーをOFFにすれば問題は起こらないのですが、この機能が非常に便利なため諦めることができず悩んでおります。
何かアドバイスいただけると幸いです。よろしくお願いいたします。

yasukawa-sashimi, 2025-01-21:
すみません、 Discussionsの方に移させていただきます。

Closed 2025-01-22.

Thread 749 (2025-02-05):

Trackball PCB kicad files

tirorex, 2025-02-05:
Thank you so much for a project!

Couldn't find KiCad files for Trackball PCB (where mount sensor).

Please, add it to project.

Thank you in advance.

talex-tnt, 2025-04-18:
Hello there, I couldn't find them either,
It would be great to have them as well.

Thanks the whole project!

talex-tnt, 2025-04-18:
Well, I managed to find some files here: https://github.com/Yowkees/keyball/tree/main/keyball46/ball_design_data

tirorex, 2025-04-18:
> Well, I managed to find some files here: https://github.com/Yowkees/keyball/tree/main/keyball46/ball_design_data

These are gerbers,  unusable for production (missing drill and other layers).

Need to either fix it or open KiCad files

talex-tnt, 2025-10-07:
Found one on AliExpr for 20/30$ and replaced the busted one.. it was not identical but worked just fine.

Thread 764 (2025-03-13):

Connection with TRRS cable is no longer possible on Keyball61.

shiraya-ma, 2025-03-13:
# TRRS接続ができなくなった

お世話になっております。

Keyball61を組み立てて正常に使用していたのですが、突然TRRSケーブルでの接続がうまくできなくなりました。

テスターの準備はあるので、導通の確認が必要な箇所があればご指示いただければと思います。
（あるいははんだが上手く盛れていない部分のご指摘）

## 症状
- TRRSで接続された、USB接続されていない側のキー、ボールの操作が動作しない
- LEDのプロファイルが同期されない
- どちらのマイコンにUSBを接続しても、TRRSで接続された側は前述の症状がでる

## 試したこと
- TRRSケーブルを交換して確認
  - 症状変わらず
- TRRSジャックを再度はんだ付け
- マイコンのはんだが上手く盛れていない部分を再度はんだ付け

## 画像

### 右手側にUSB接続した状態
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

### 左手側にUSB接続した状態
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

### 右手側
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

### 左手側
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

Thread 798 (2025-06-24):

OLED_ENABLE = noにするとビルドエラーが発生する

masa0612, 2025-06-24:
原因となる対象の行は以下
https://github.com/Yowkees/keyball/blob/9ffe9f6c9416f9428a49bc69235a35d2d5e1fb30/qmk_firmware/keyboards/keyball/lib/keyball/keyball.c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

OLED_ENABLE  = no だとcode_to_nameが定義されていない状態となるが、
この行で参照してしまいビルドエラーとなる。

原因はわかったがどう治すべきかqmkの知見が無いためIssueで報告させていただきました。

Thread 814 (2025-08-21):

キー配置が初期状態に戻る

HidemotoNakada, 2025-08-21:
1月から快適に使用しています。ありがとうございます。

ここ数日、急にキー配置のカスタマイズが無効になることがあります。
特になにか変わった動作をしているわけではなく、
タイプしている途中で突然キー配置がデフォルトに巻き戻る感じです。

このような症状が出る理由としてなにか考えられることがありますでしょうか。

よろしくお願いいたします。

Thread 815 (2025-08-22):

Looking for advice on adding a mouse wheel to the Keyball61.

mathematicsofpaul, 2025-08-22:
Hi Yowkees,

Thank you for designing such an amazing keyboard!

I was wondering if you had any advice on somehow modding the Keyball61 to include a scroll wheel using a Pro Micro Type-C? I was just finding it tricky using the native layer 3 scroll option and wanted to mod my keyball61 to have a scroll wheel.

Since I am quite new to custom keyballs - which files would you suggest I modify in order to have the scroll wheel work? I was looking at using the following scroll wheel.

https://keebd.com/products/encoder-roller-with-push-switch

Kind regards, Paul.

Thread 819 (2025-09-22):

Bottom row not responding on Keyball61

divad1196, 2025-09-22:
Hi,

Thank you for the keyboard design.
I bought a kit and it was my first time building a keyboard myself.

I have done a few things wrong and fixed a few issues already:
- The keyboard was mirrored due to the "left" jumper not being soldered (I have not seen it on the keyball61 guide though..)
- The OLED screens were off, I re-soldered the jumpers near the pro-micro

Since I struggled with understanding the directives, I skipped the "test" phase. I also assumed that I have too little knowledge to troubleshoot it anyway and I could just test each keys after the keyboard was fully assembled.

Now, most issues seems fixed except an important one:
**The bottom row keys** (row4 I assume) **are not responding**, none of them (I don't have the ball for the trackball at the moment).

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

Since this impact a whole row, I thought a single element could be the cause.

- I believe that all diodes are correctly oriented, but I cannot see it and don't know how to check if that's the case
- I struggle to bridge the jumpers near the pro-micro. I don't know what they are for.
  The right-most one was a bit dammage (one of the parts of the jumper was black instead of grey. I finally managed to solder it but what got fixed was the OLED screen so I assume this is not the cause.

Any help would be appreciated.
Thank you and have a nice day

divad1196, 2025-09-26:
@jtuyen hi,
That's already what I tried with some old multimeter I found (still has a needle).

I don't understand where the last row goes on the PCB and which diode to check. I tried to check all of them but I actually don't know hoe to test properly with the multimeter:
- putting voltmeter on both sides of the diode don't do anything
- if I put on the diode and on a pin of the micro controller, it "always" triggers. It's not consistant with most pins on the Micro-controller except the "Raw" pin that always triggers

I expected to find a test that works for all diode except a a few.

So, basically: yes, still have the issue because I don't have the skills to troubleshoot. Still searching though.

divad1196, 2025-09-27:
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

Thank you for the help, your last comment was right: I resoldered the pin on the controller and then it worked (just also had to re-solder one switch). Now all keys worked, the OLED screens as well, ... just not the trackball.

For the trackball sensor, I soldered the sensor in the wrong direction and I am unable to unsolder it from the pcb, I just ordered a replacement part, hopefully this goes well...

For the first paragraphs: I searched and found the diagram, but I absolutely don't understand it nor could correlate it with the PCB. For the multimeter I don't know what the "continuity mode" is or what "shorted diode" mean. This probably shows how little knowledges I have. Still, that's things I search when I hear about them to learn, so thank you for pointing it to me.

As most issues are solved and the trackball sensor replacement should (hopefully) fix the last issue, I will close the issue.
Thank you for your help.

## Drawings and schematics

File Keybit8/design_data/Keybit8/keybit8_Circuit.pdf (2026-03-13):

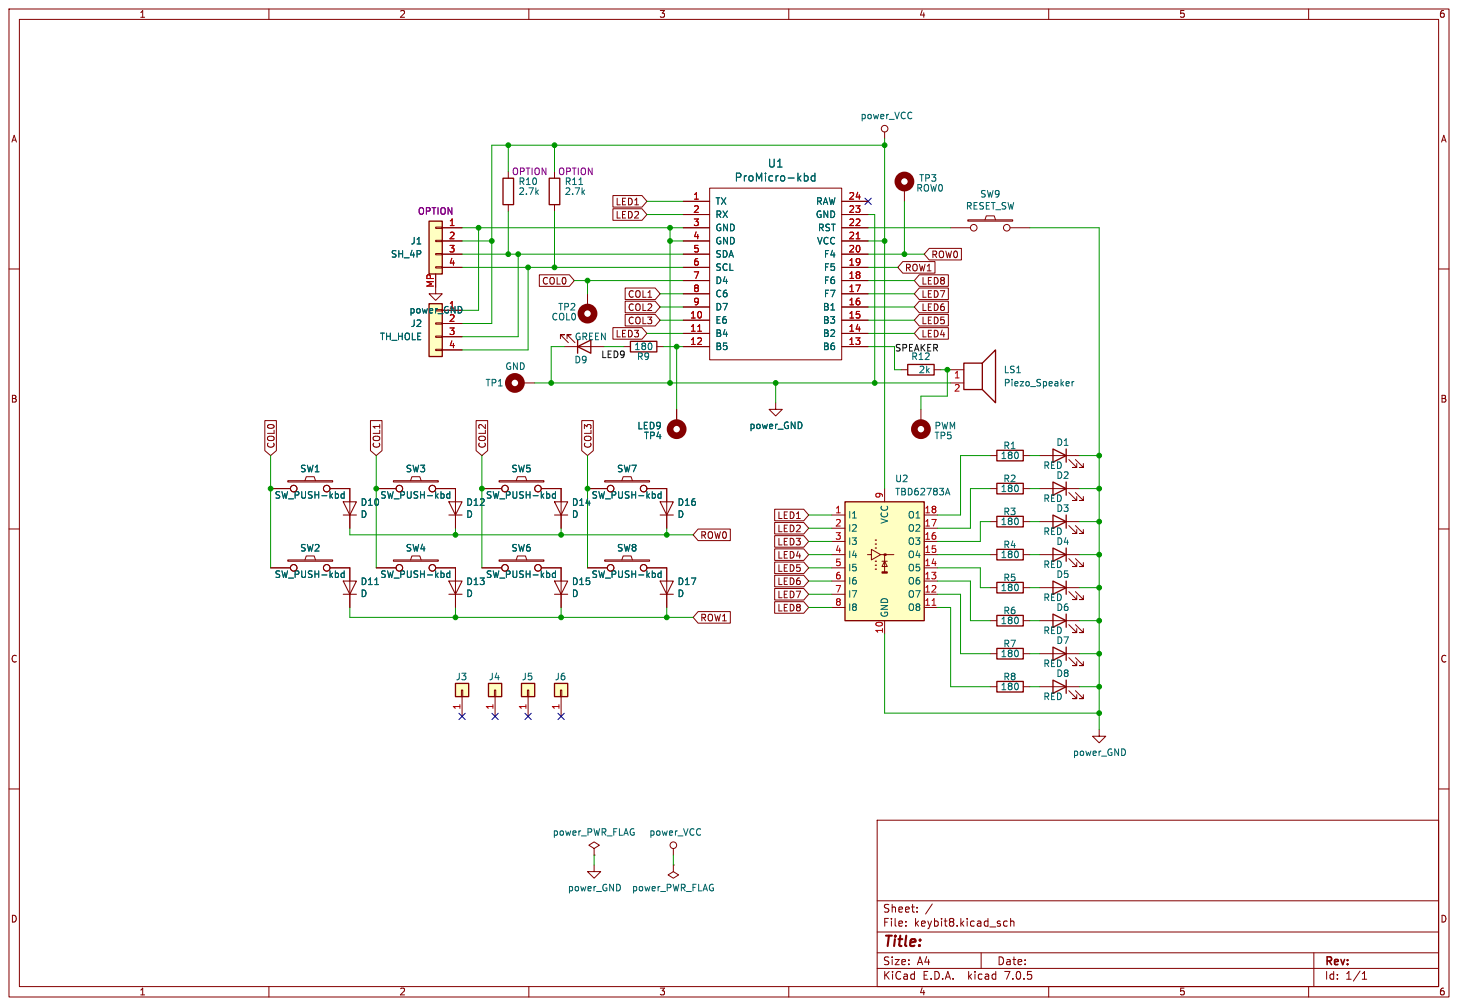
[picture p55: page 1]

Id: 1/1 Title: File: keybit8.kicad_sch Sheet: / power_PWR_FLAG

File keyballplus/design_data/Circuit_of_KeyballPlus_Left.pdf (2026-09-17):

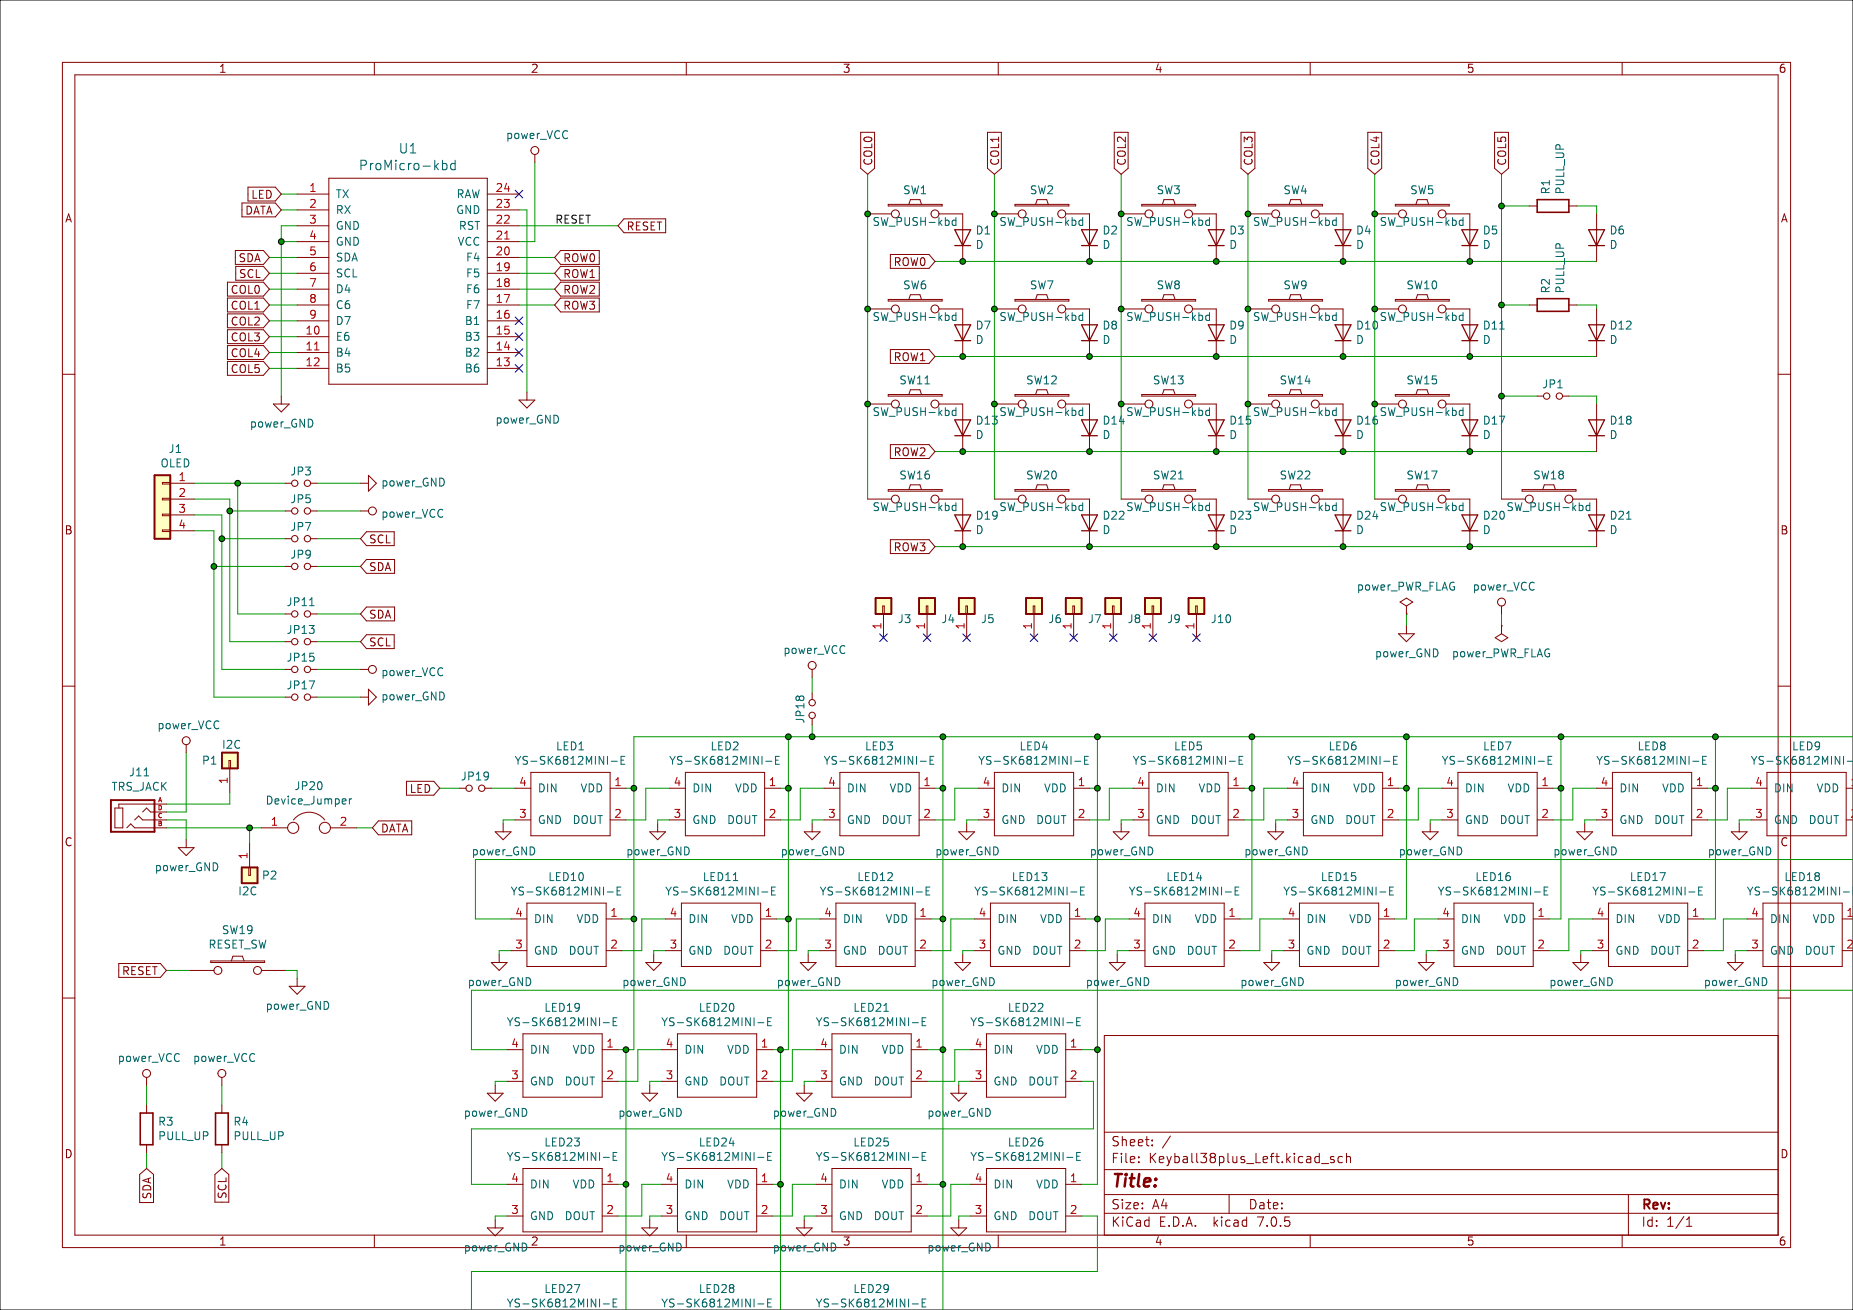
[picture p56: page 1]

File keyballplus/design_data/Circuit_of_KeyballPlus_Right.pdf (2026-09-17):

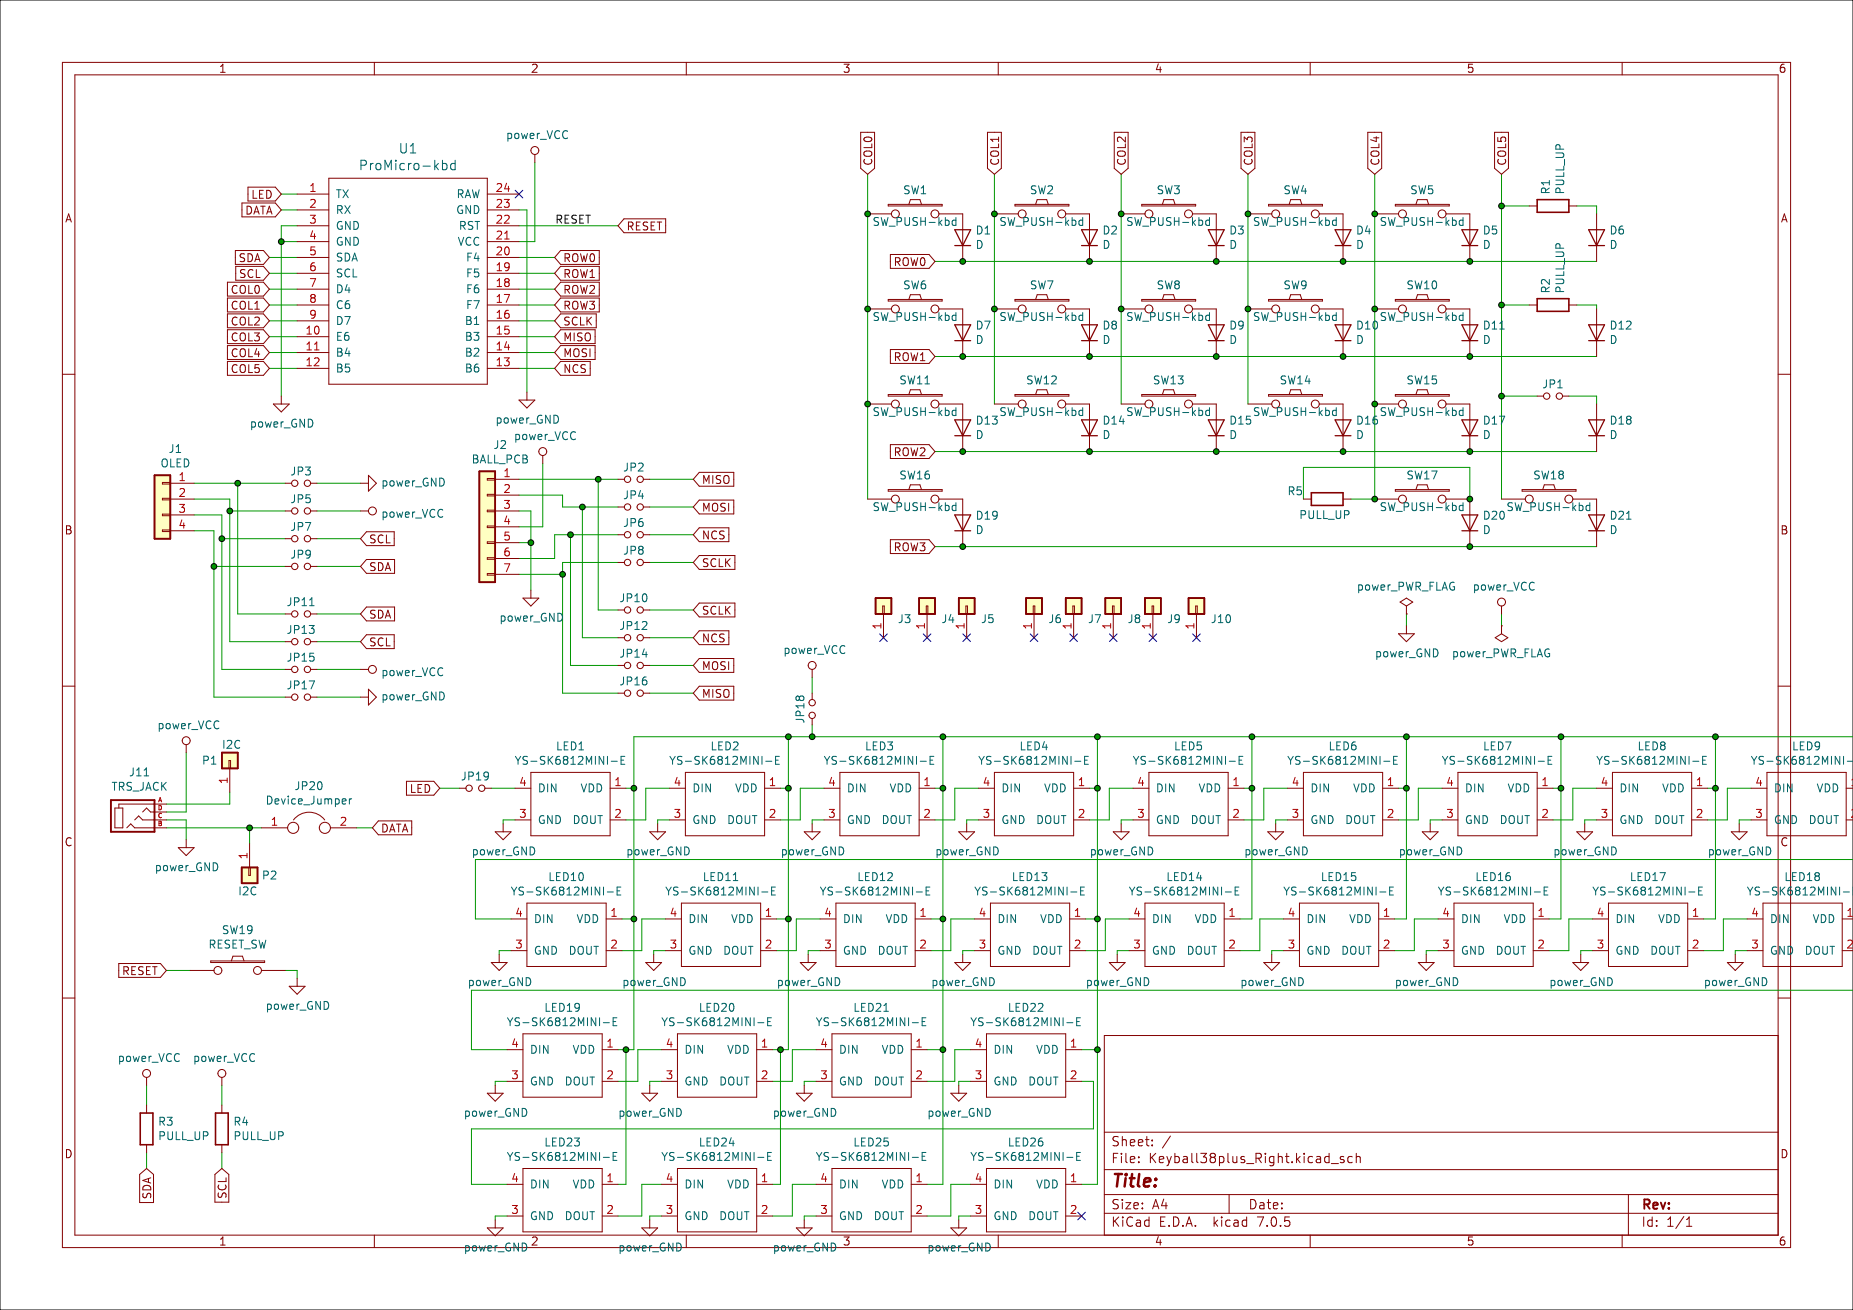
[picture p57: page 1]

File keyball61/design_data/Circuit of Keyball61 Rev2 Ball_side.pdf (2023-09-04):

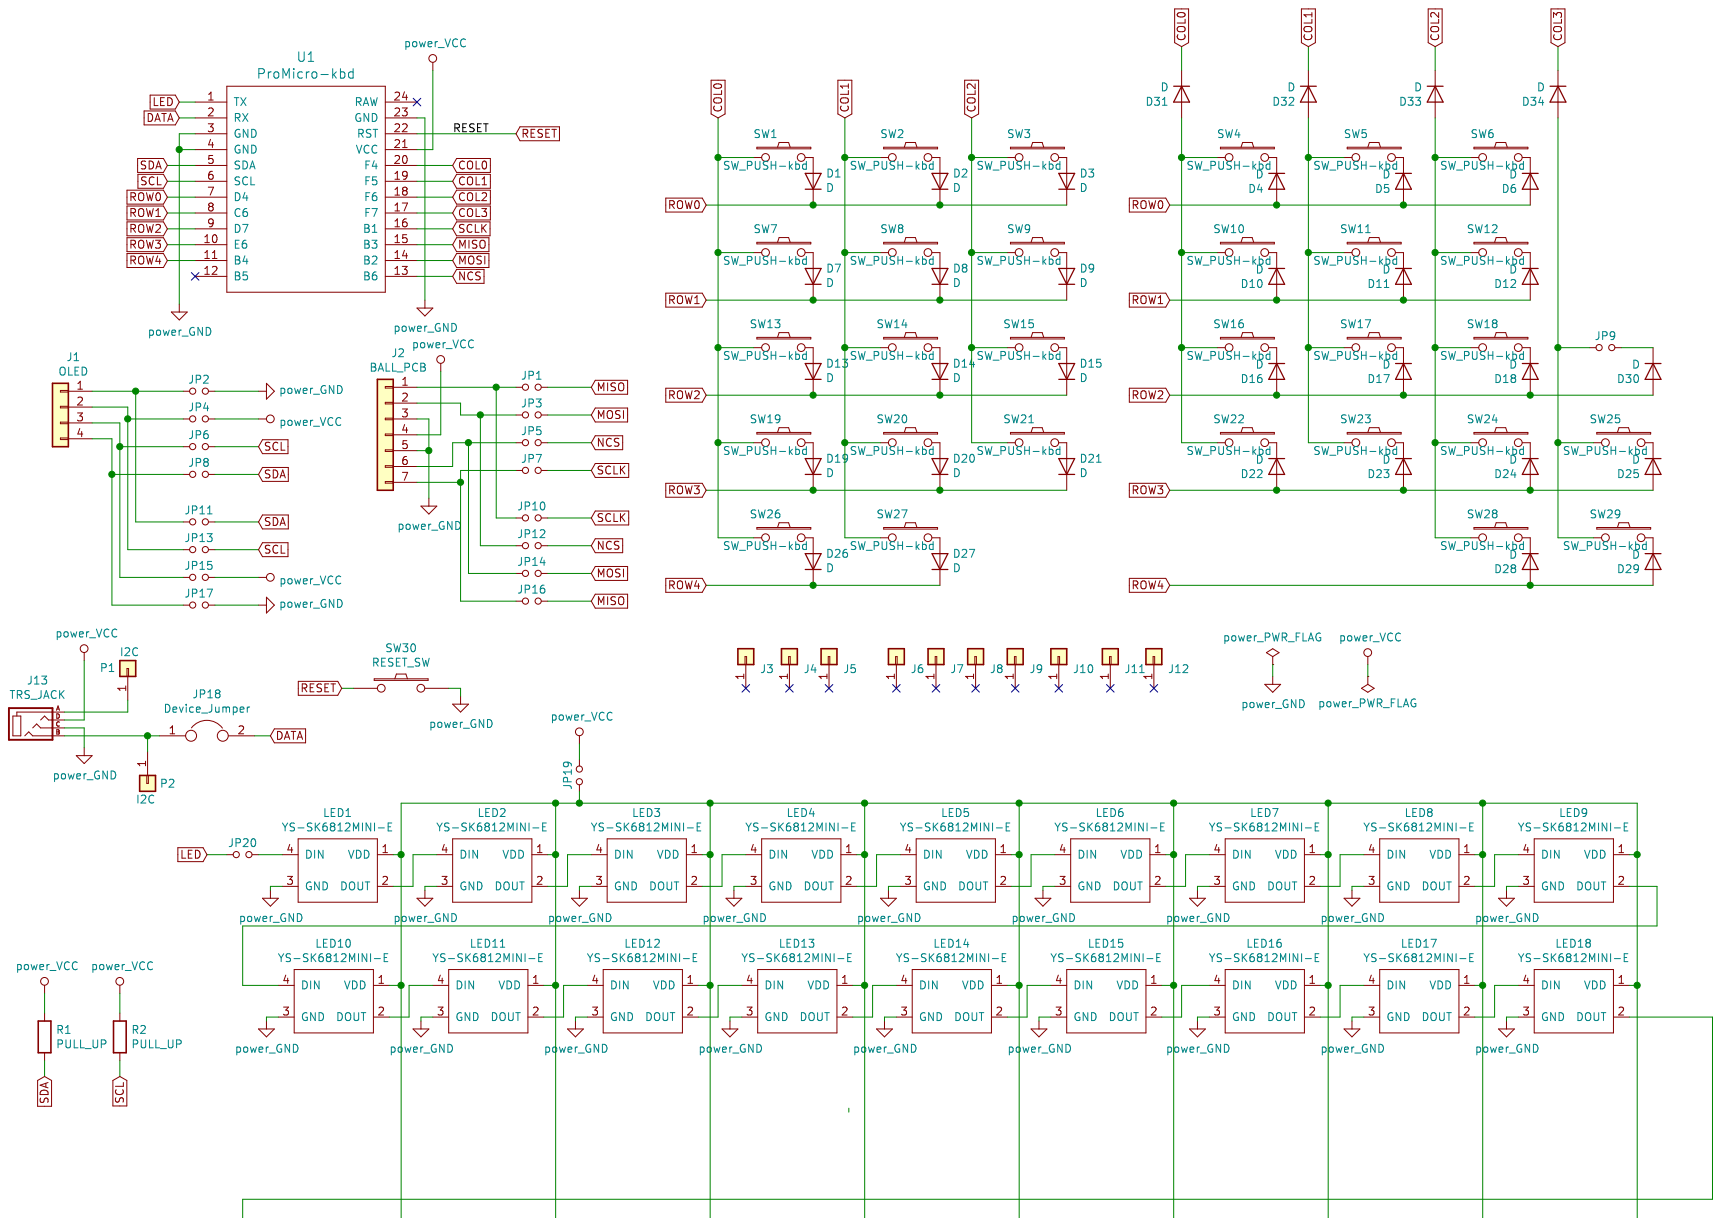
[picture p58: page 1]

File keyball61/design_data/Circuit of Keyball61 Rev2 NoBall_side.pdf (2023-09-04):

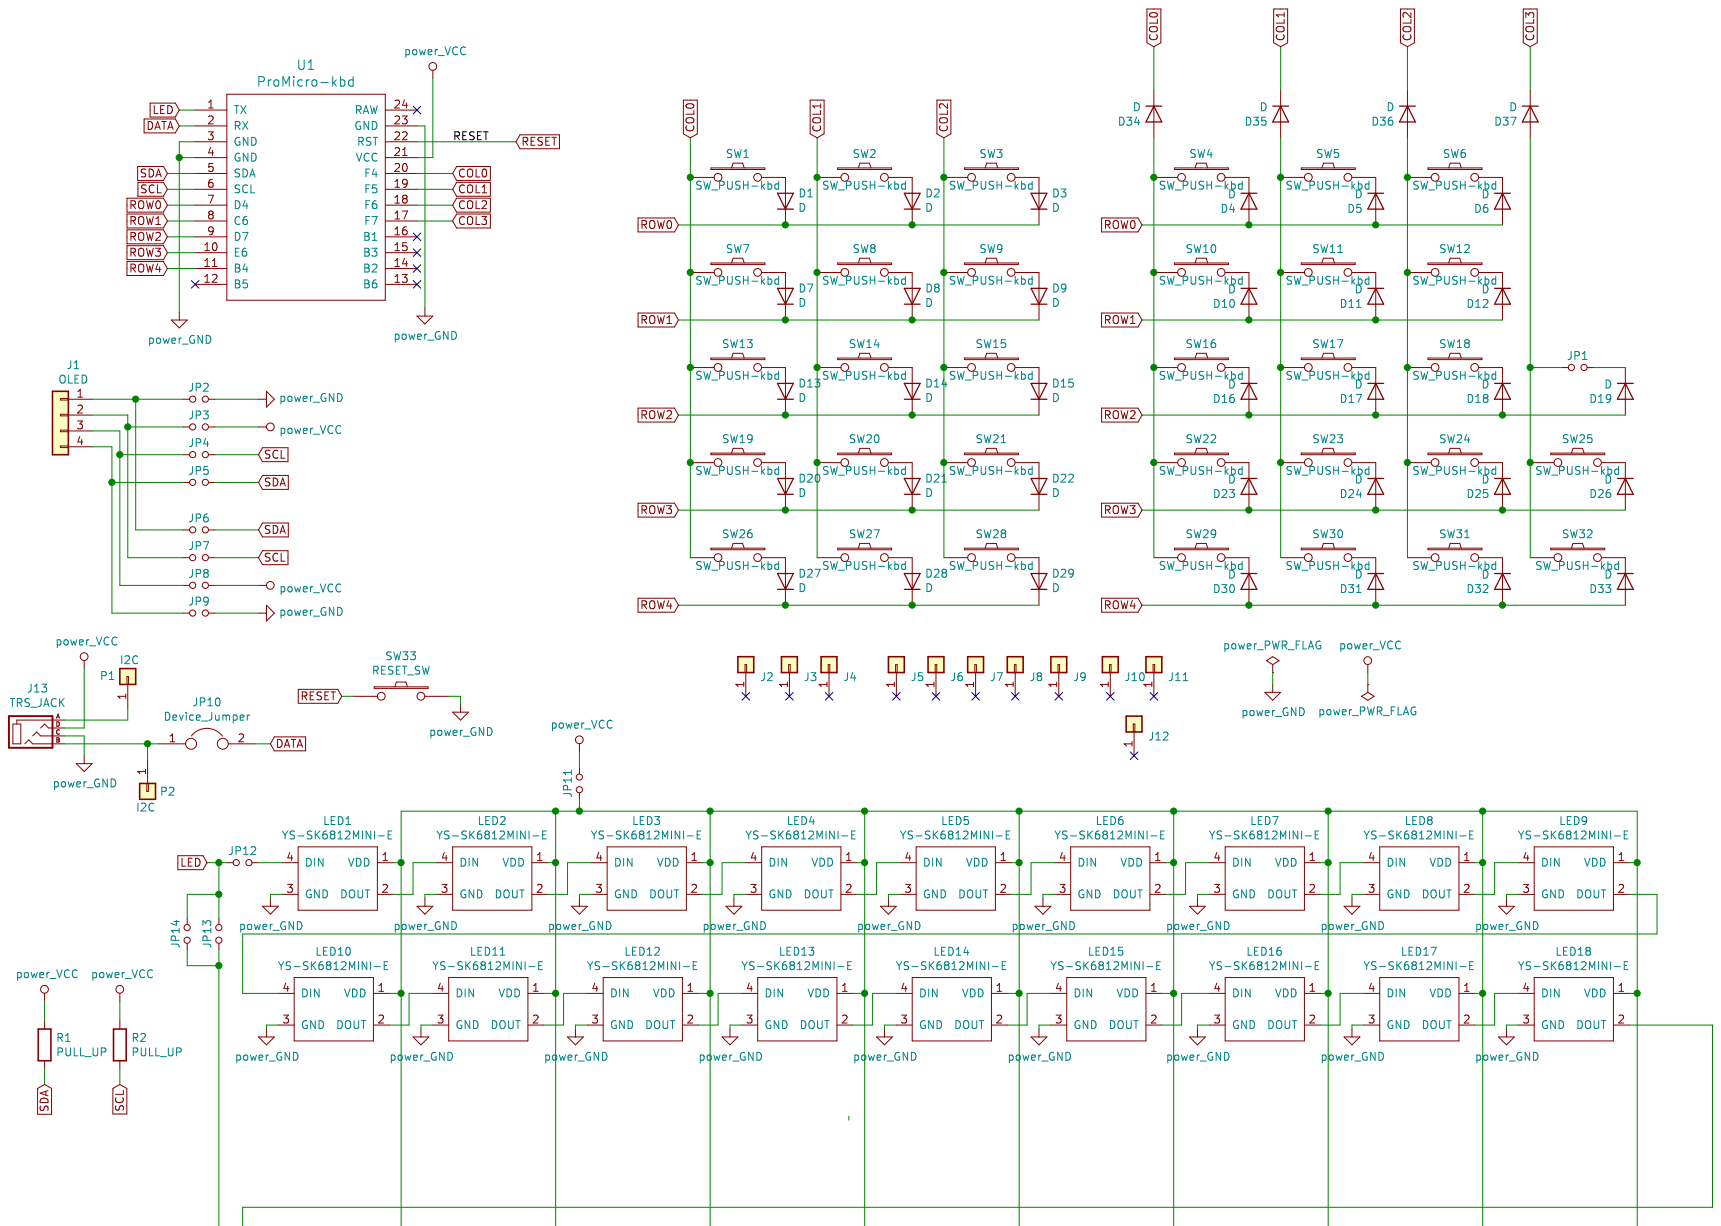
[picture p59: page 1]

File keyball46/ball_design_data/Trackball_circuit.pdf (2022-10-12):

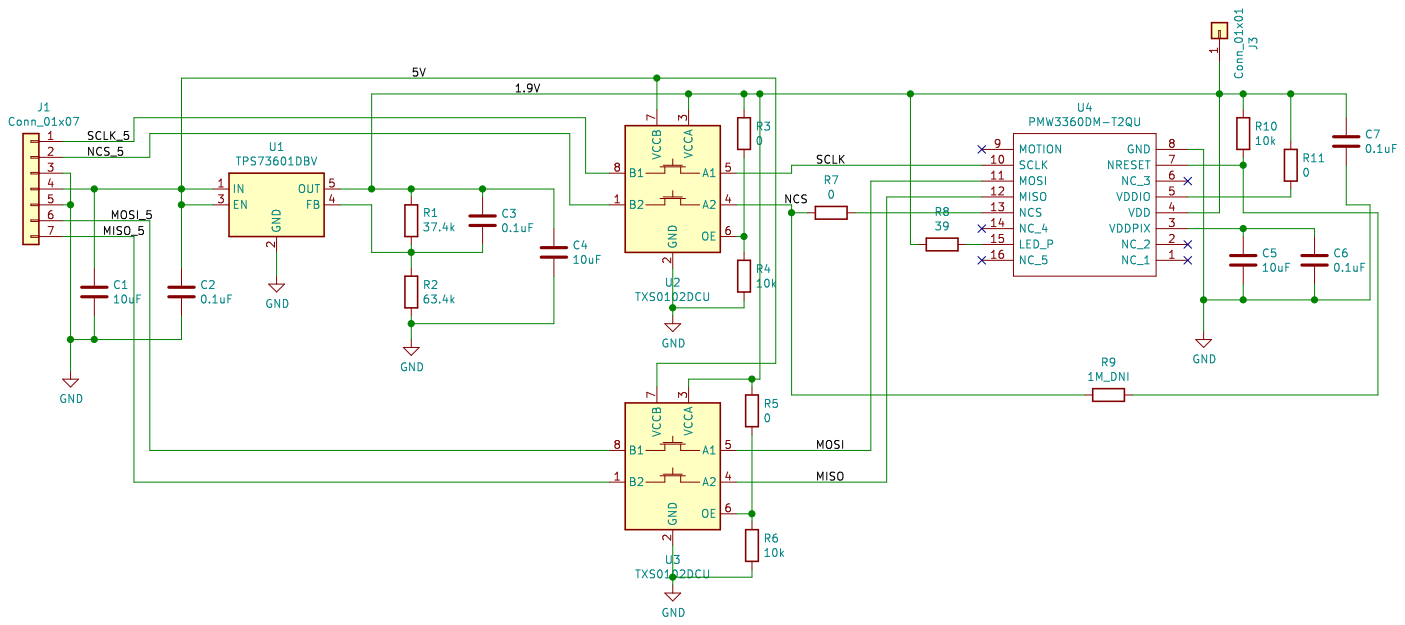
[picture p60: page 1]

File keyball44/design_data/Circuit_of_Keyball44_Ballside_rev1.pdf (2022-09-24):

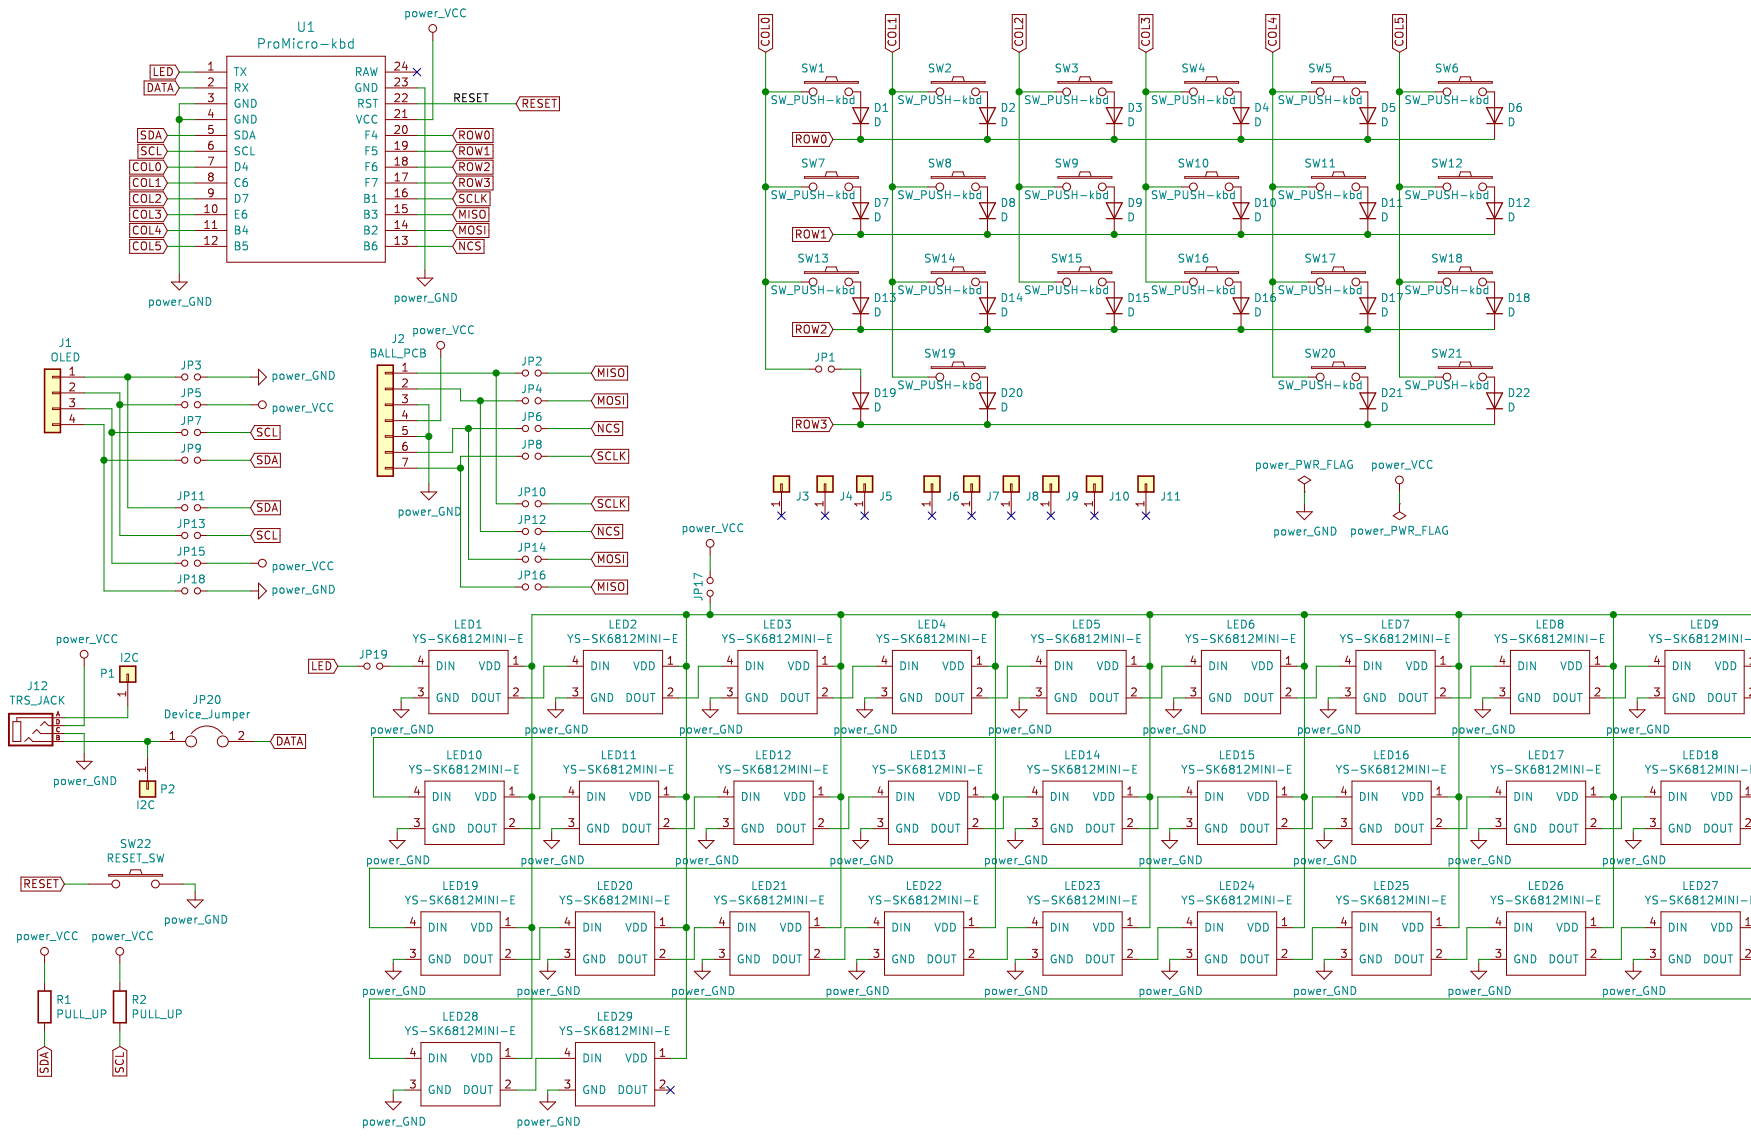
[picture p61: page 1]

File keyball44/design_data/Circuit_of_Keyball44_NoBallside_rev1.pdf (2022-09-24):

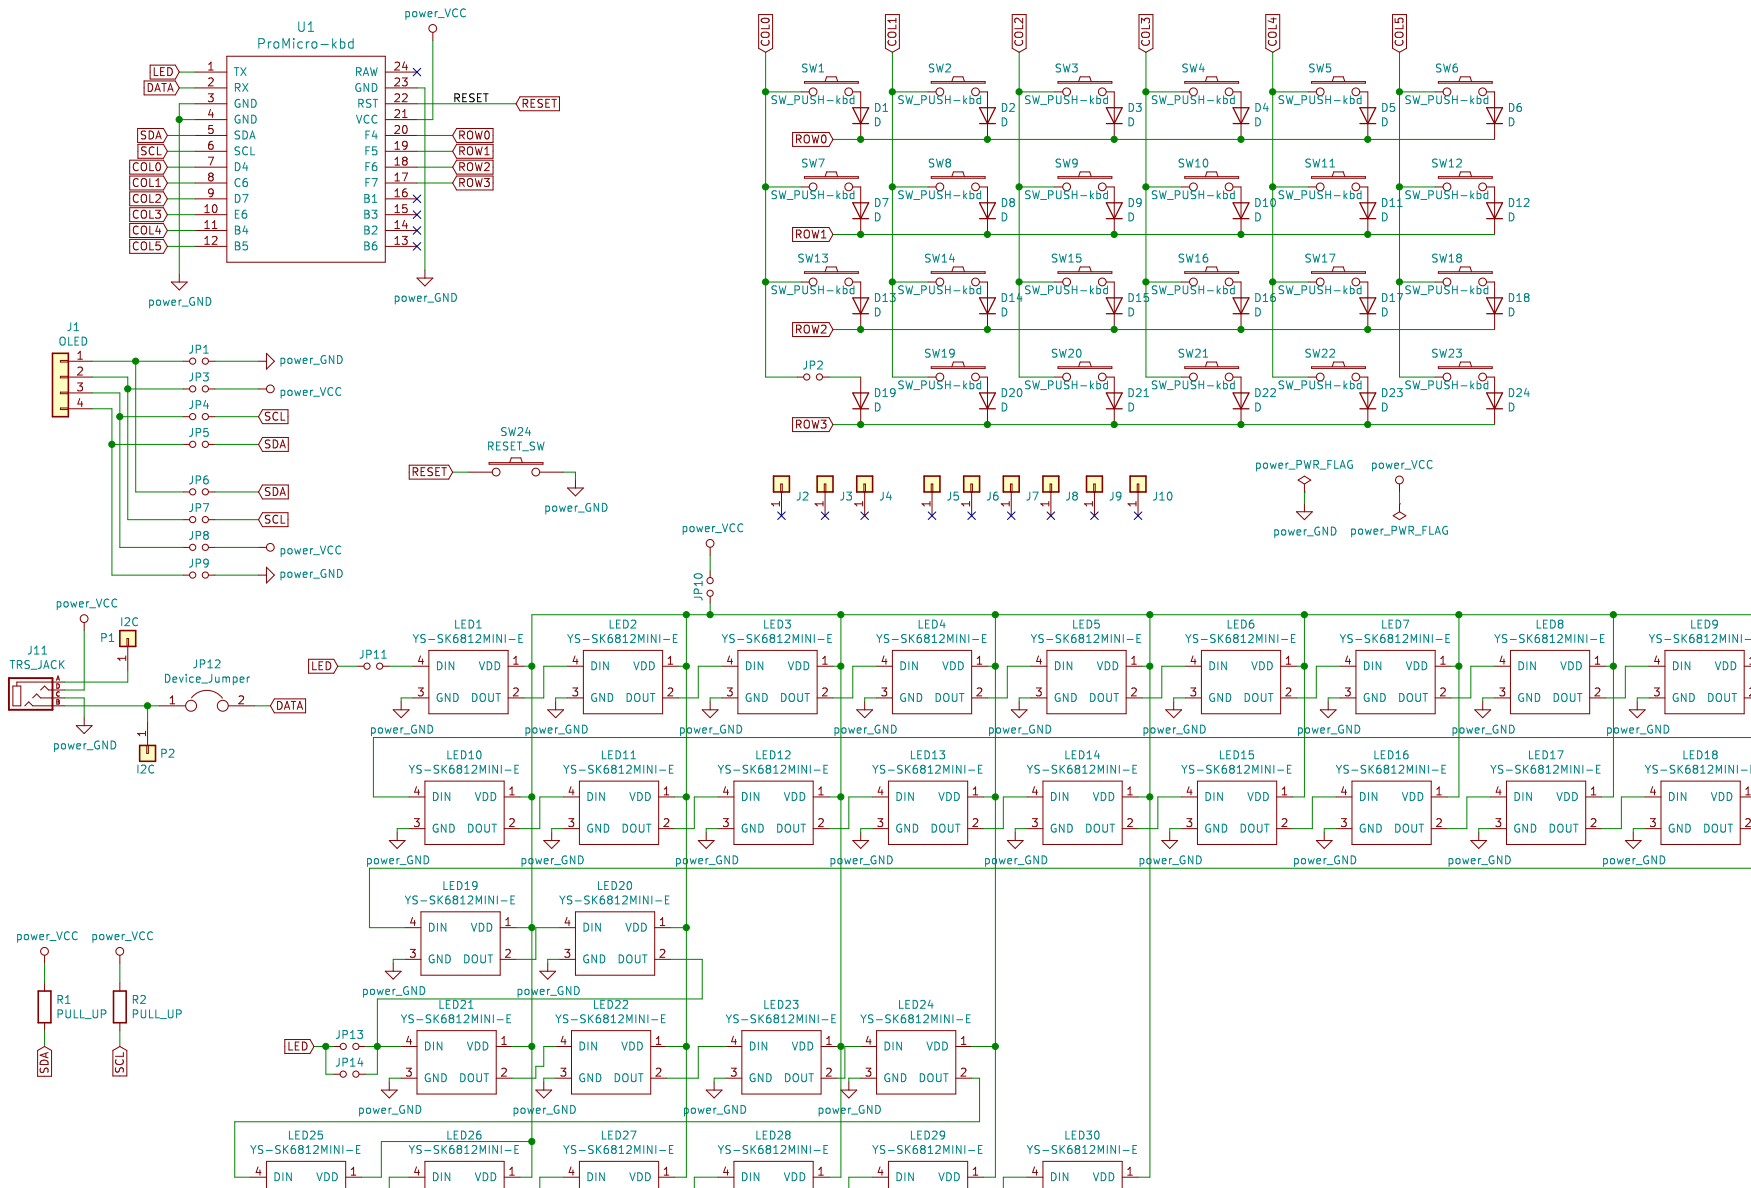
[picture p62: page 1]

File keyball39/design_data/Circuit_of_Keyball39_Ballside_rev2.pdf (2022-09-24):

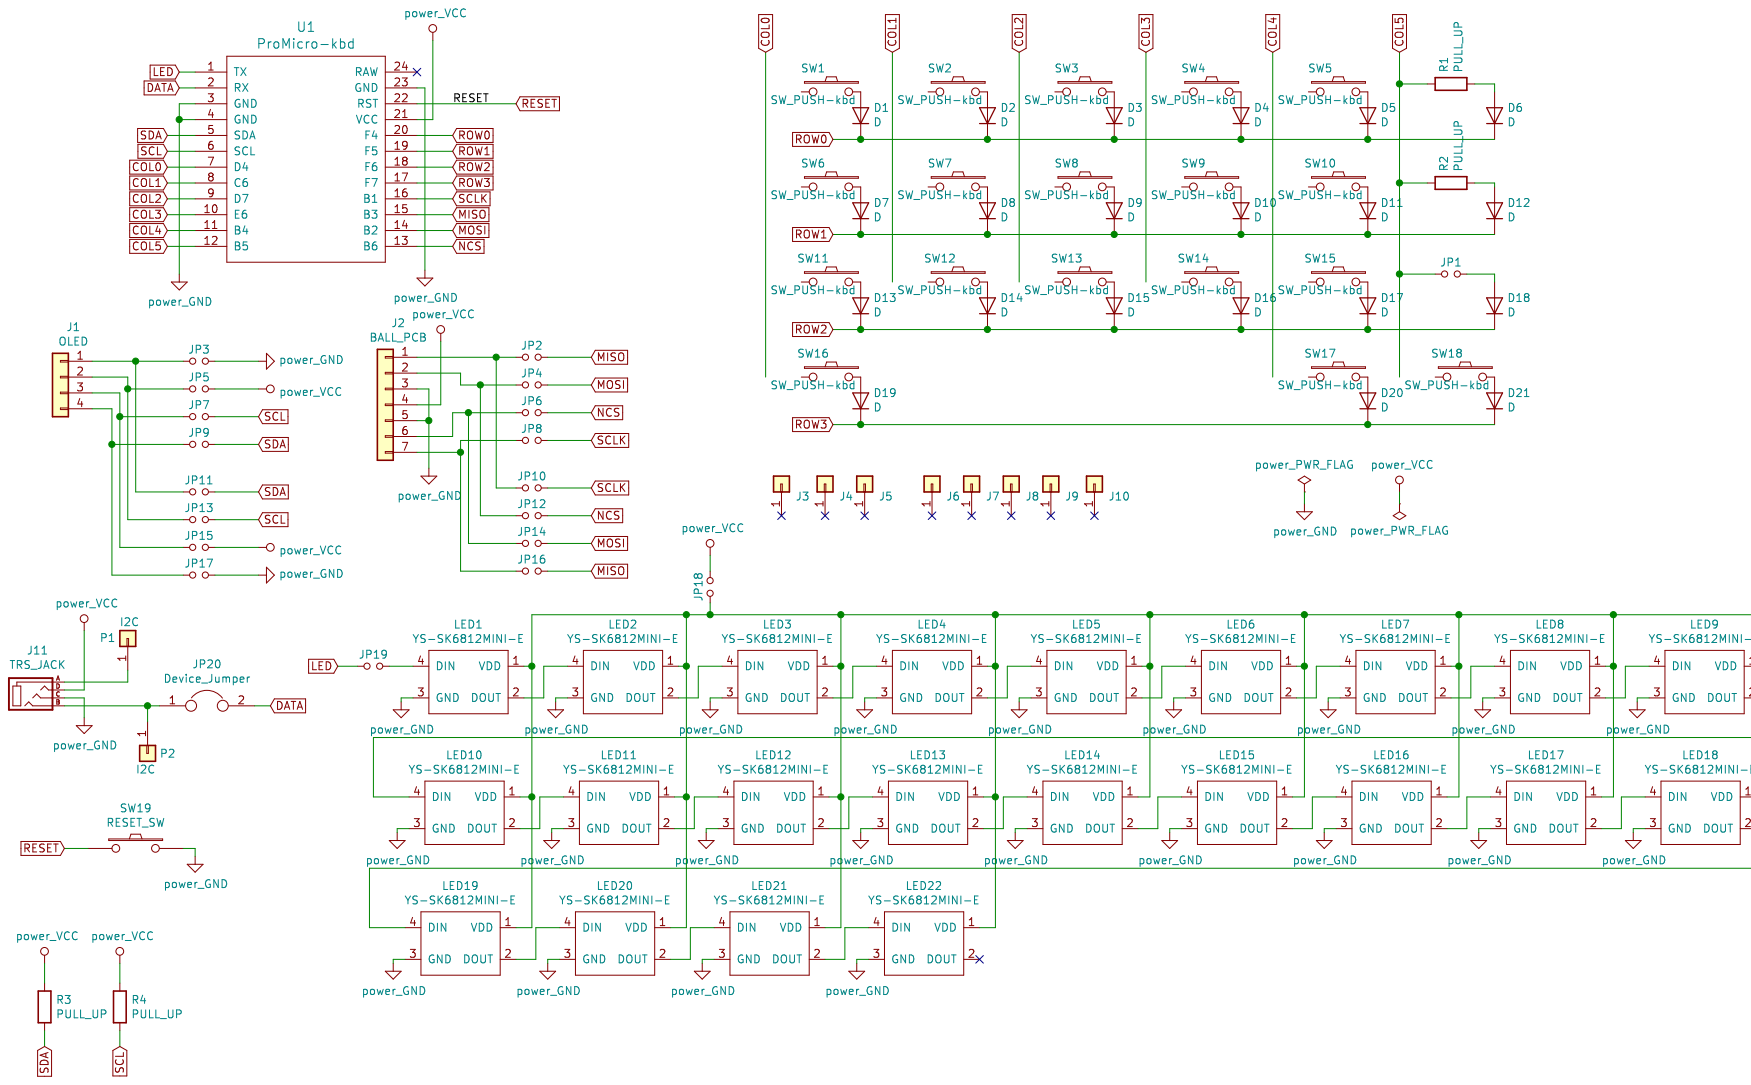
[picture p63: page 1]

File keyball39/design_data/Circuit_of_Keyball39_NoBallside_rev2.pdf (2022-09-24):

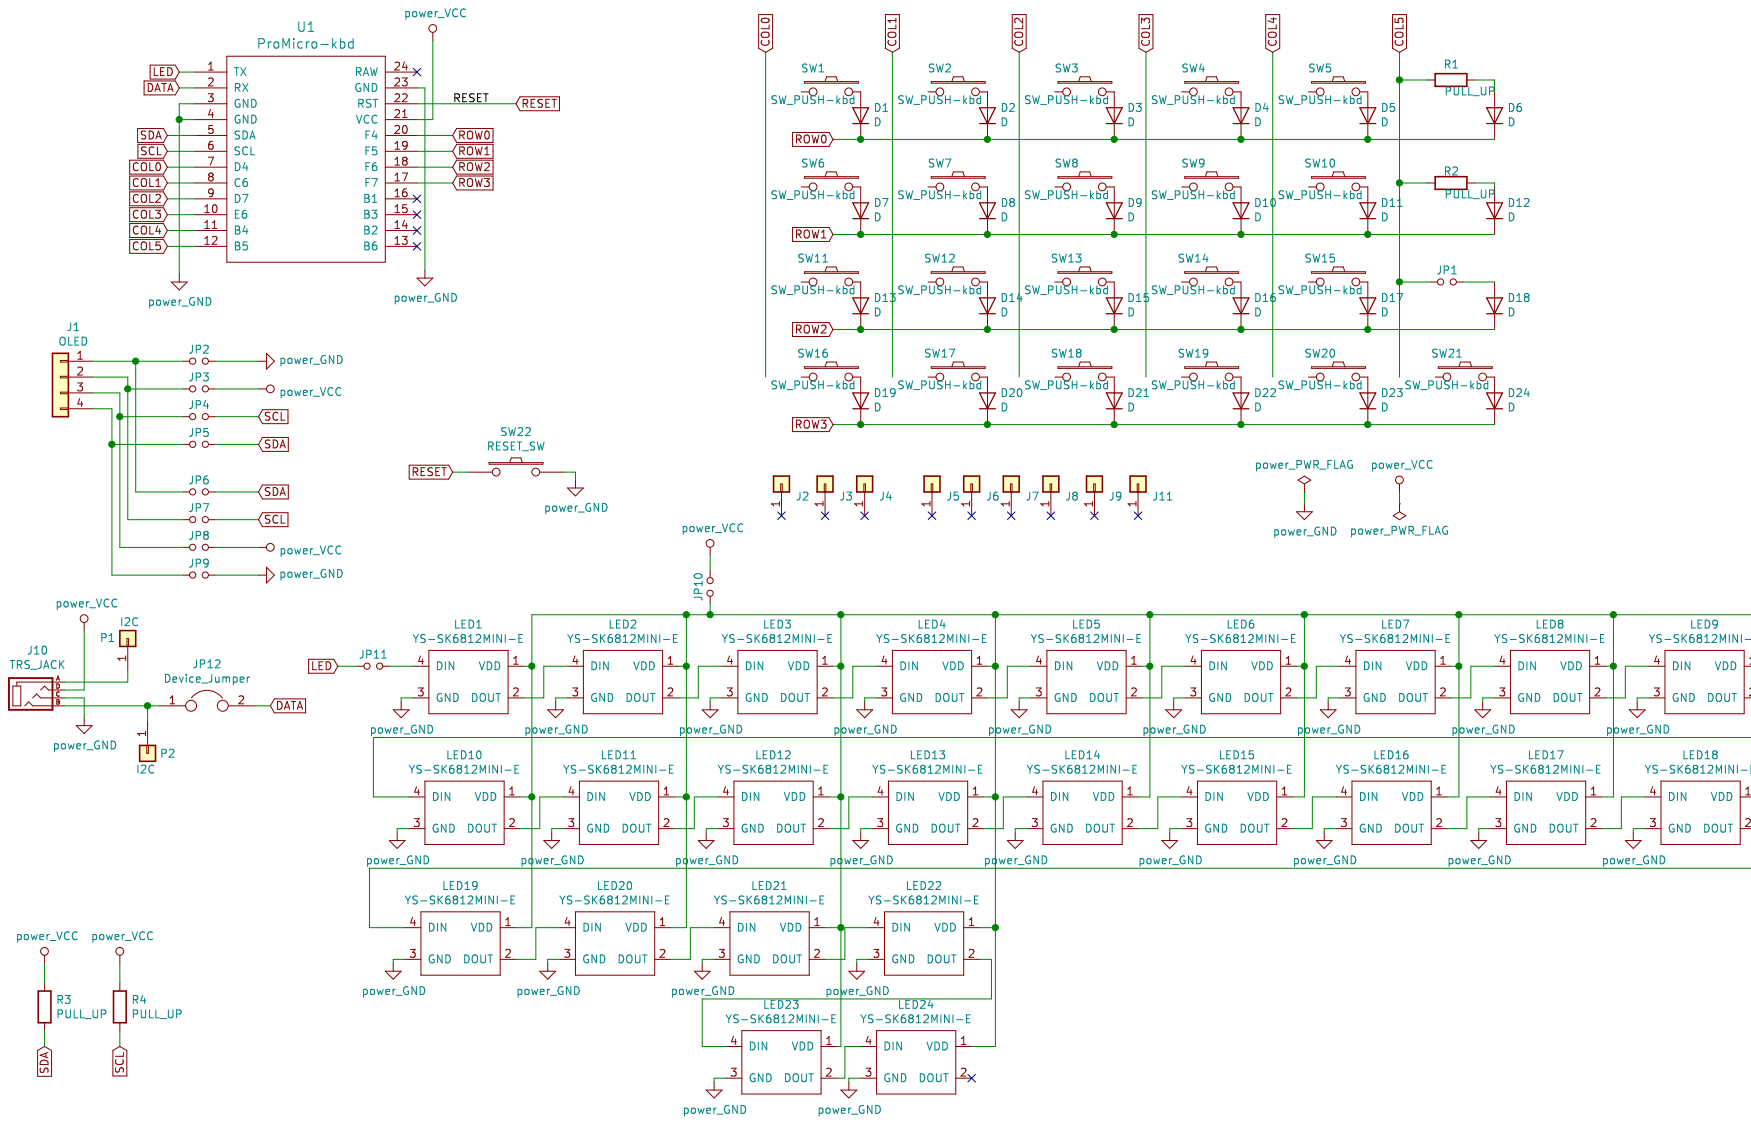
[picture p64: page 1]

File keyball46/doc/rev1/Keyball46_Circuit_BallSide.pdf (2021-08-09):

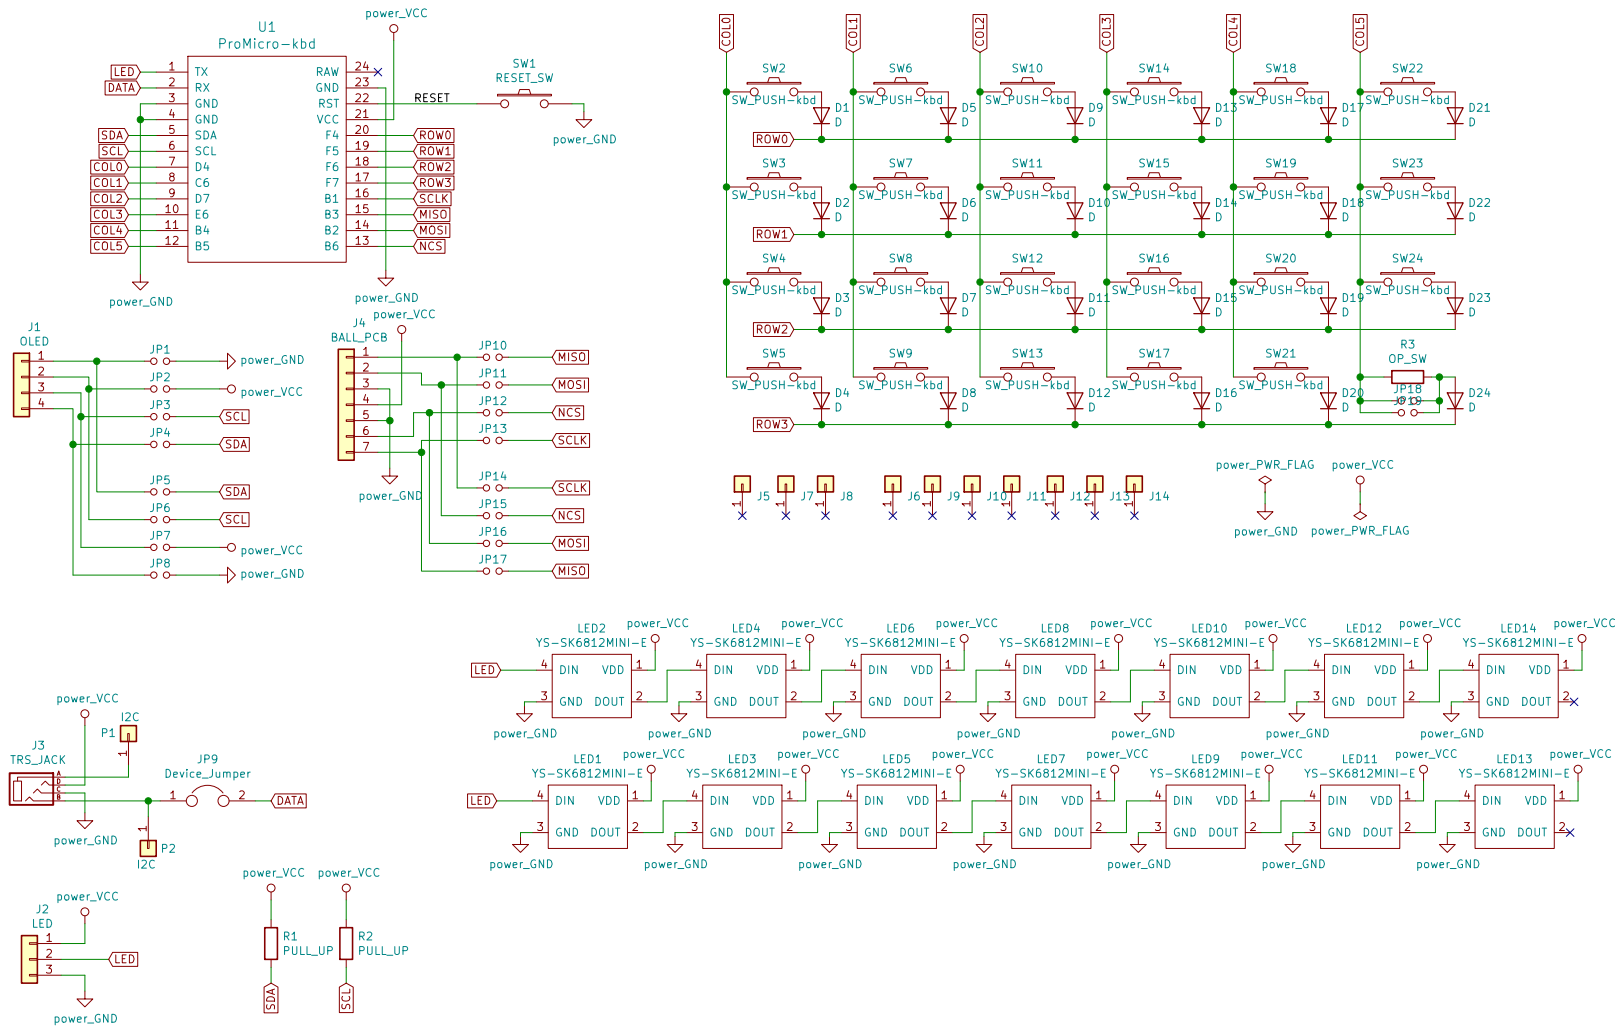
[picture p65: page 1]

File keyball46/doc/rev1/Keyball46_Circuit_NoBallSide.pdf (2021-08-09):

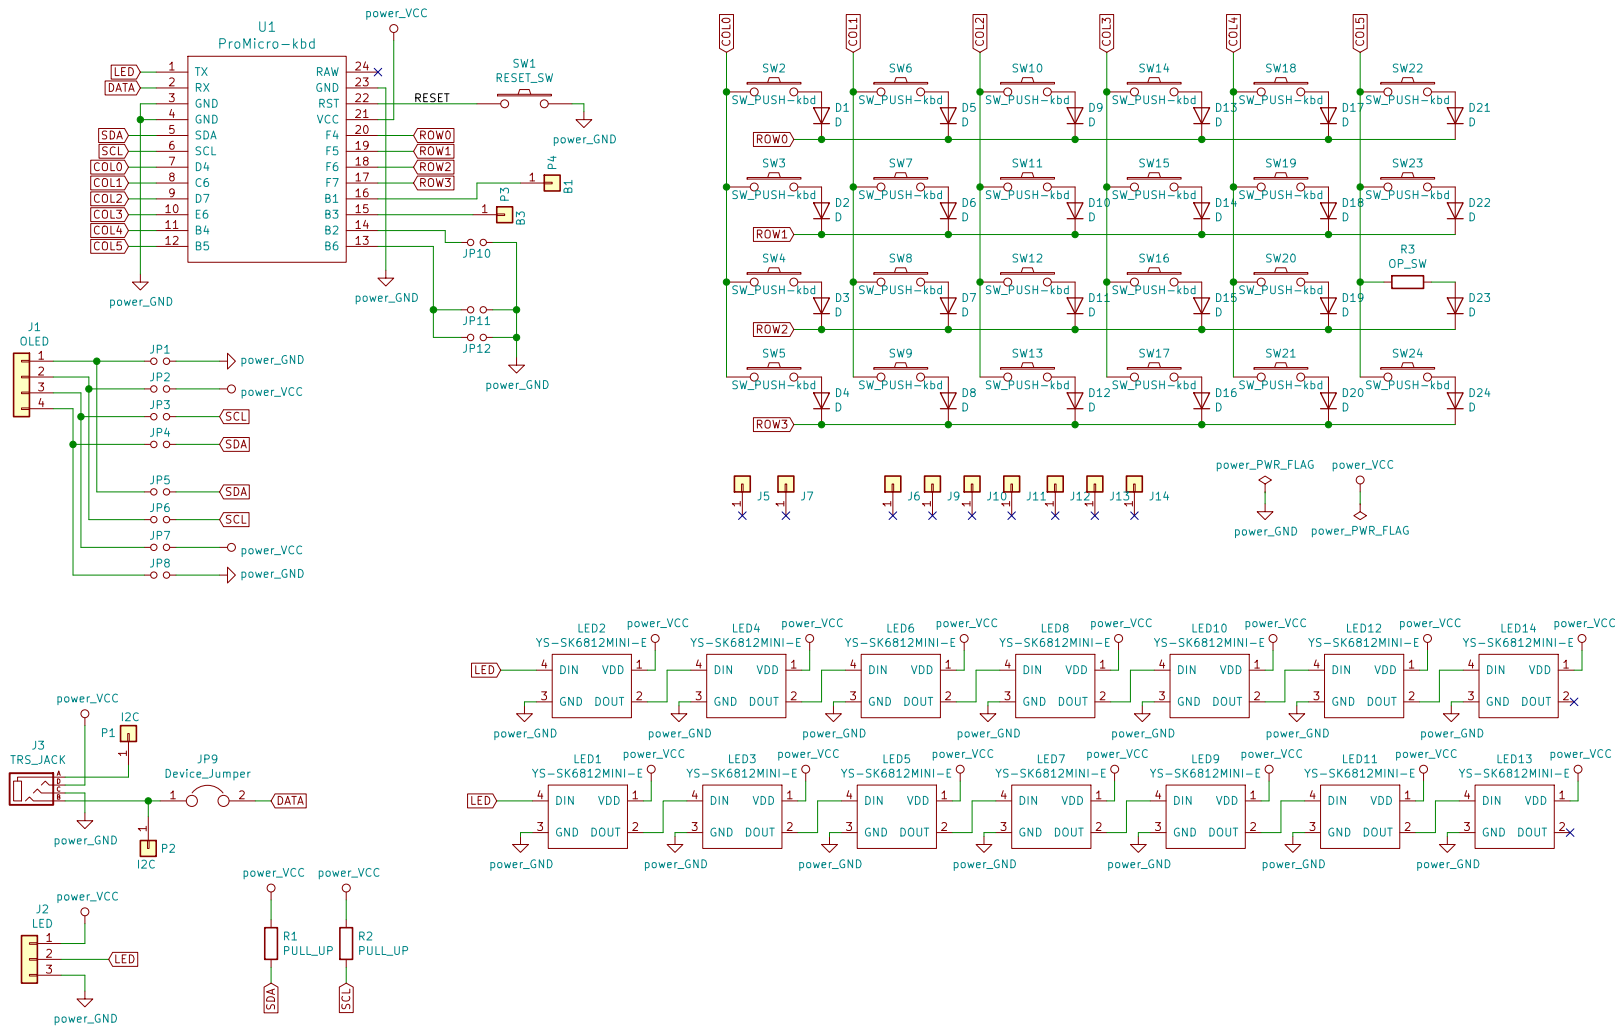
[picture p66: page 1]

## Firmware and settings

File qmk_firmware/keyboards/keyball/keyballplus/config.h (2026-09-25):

/*
Copyright 2022 @Yowkees
Copyright 2022 MURAOKA Taro (aka KoRoN, @kaoriya)

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
You should have received a copy of the GNU General Public License
along with this program.  If not, see <http://www.gnu.org/licenses/>.
*/

#pragma once

// Key matrix parameters
#define MATRIX_ROWS         (4 * 2)  // split keyboard
#define MATRIX_COLS         6
#define MATRIX_ROW_PINS     { F4, F5, F6, F7 }
#define MATRIX_COL_PINS     { D4, C6, D7, E6, B4, B5 }
#define MATRIX_MASKED
#define DEBOUNCE            5
#define DIODE_DIRECTION     COL2ROW

// Split parameters
#define SOFT_SERIAL_PIN         D2
#define SPLIT_HAND_MATRIX_GRID  F6, B5
#define SPLIT_USB_DETECT
#ifdef OLED_ENABLE
#    define SPLIT_OLED_ENABLE
#endif

// If your PC does not recognize Keyball, try setting this macro. This macro
// increases the firmware size by 200 bytes, so it is disabled by default, but
// it has been reported to work well in such cases.
//#define SPLIT_WATCHDOG_ENABLE

#define SPLIT_TRANSACTION_IDS_KB KEYBALL_GET_INFO, KEYBALL_GET_MOTION, KEYBALL_SET_CPI

// RP2040 controller conversion needs the Pro Micro SPI pins used by the sensor.
#ifdef MCU_RP
#    define SPI_DRIVER SPID0
#    define SPI_SCK_PIN B1
#    define SPI_MOSI_PIN B2
#    define SPI_MISO_PIN B3
#    define SPLIT_HAND_MATRIX_GRID_LOW_IS_LEFT
#endif

// RGB LED settings
#define WS2812_DI_PIN       D3
#ifdef RGBLIGHT_ENABLE
#    define RGBLED_NUM      58
#    define RGBLED_SPLIT    { 29, 29 }  // (29 + 26)
#    ifndef RGBLIGHT_LIMIT_VAL
#        define RGBLIGHT_LIMIT_VAL  150 // limitated for power consumption
#    endif
#    ifndef RGBLIGHT_VAL_STEP
#        define RGBLIGHT_VAL_STEP   15
#    endif
#    ifndef RGBLIGHT_HUE_STEP
#        define RGBLIGHT_HUE_STEP   17
#    endif
#    ifndef RGBLIGHT_SAT_STEP
#        define RGBLIGHT_SAT_STEP   17
#    endif
#endif
#ifdef RGB_MATRIX_ENABLE
#    define RGB_MATRIX_SPLIT    { 29, 29 }
#endif

#ifndef OLED_FONT_H
#    define OLED_FONT_H "keyboards/keyball/lib/logofont/logofont.c"
#    define OLED_FONT_START 32
#    define OLED_FONT_END 195
#endif

#if !defined(LAYER_STATE_8BIT) && !defined(LAYER_STATE_16BIT) && !defined(LAYER_STATE_32BIT)
#    define LAYER_STATE_8BIT
#endif

// To squeeze firmware size
#undef LOCKING_SUPPORT_ENABLE
#undef LOCKING_RESYNC_ENABLE

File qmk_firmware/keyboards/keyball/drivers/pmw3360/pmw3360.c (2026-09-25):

/*
Copyright 2022 MURAOKA Taro (aka KoRoN, @kaoriya)

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
You should have received a copy of the GNU General Public License
along with this program.  If not, see <http://www.gnu.org/licenses/>.
*/

#include "quantum.h"
#include "pmw3360.h"

// Include SROM definitions.
#include "srom_0x04.c"
#include "srom_0x81.c"

#define PMW3360_SPI_MODE 3
#define PMW3360_CLOCKS 2000000

#ifndef PMW3360_SPI_DIVISOR
#    ifdef __AVR__
#        define PMW3360_SPI_DIVISOR (F_CPU / PMW3360_CLOCKS)
#    else
#        define PMW3360_SPI_DIVISOR 64
#    endif
#endif

static bool motion_bursting = false;

bool pmw3360_spi_start(void) {
    return spi_start(PMW3360_NCS_PIN, false, PMW3360_SPI_MODE, PMW3360_SPI_DIVISOR);
}

uint8_t pmw3360_reg_read(uint8_t addr) {
    pmw3360_spi_start();
    spi_write(addr & 0x7f);
    wait_us(160);
    uint8_t data = spi_read();
    wait_us(1);
    spi_stop();
    wait_us(19);
    // Reset motion_bursting mode if read from a register other than motion
    // burst register.
    if (addr != pmw3360_Motion_Burst) {
        motion_bursting = false;
    }
    return data;
}

void pmw3360_reg_write(uint8_t addr, uint8_t data) {
    pmw3360_spi_start();
    spi_write(addr | 0x80);
    spi_write(data);
    wait_us(35);
    spi_stop();
    wait_us(145);
}

uint8_t pmw3360_cpi_get(void) {
    return pmw3360_reg_read(pmw3360_Config1);
}

void pmw3360_cpi_set(uint8_t cpi) {
    if (cpi > pmw3360_MAXCPI) {
        cpi = pmw3360_MAXCPI;
    }
    pmw3360_reg_write(pmw3360_Config1, cpi);
}

static uint32_t pmw3360_timer      = 0;
static uint32_t pmw3360_scan_count = 0;
static uint32_t pmw3360_last_count = 0;

void pmw3360_scan_perf_task(void) {
    pmw3360_scan_count++;
    uint32_t now = timer_read32();
    if (TIMER_DIFF_32(now, pmw3360_timer) > 1000) {
#if defined(CONSOLE_ENABLE)
        dprintf("pmw3360 scan frequency: %lu\n", pmw3360_scan_count);
#endif
        pmw3360_last_count = pmw3360_scan_count;
        pmw3360_scan_count = 0;
        pmw3360_timer      = now;
    }
}

uint32_t pmw3360_scan_rate_get(void) {
    return pmw3360_last_count;
}

bool pmw3360_motion_read(pmw3360_motion_t *d) {
#ifdef DEBUG_PMW3360_SCAN_RATE
    pmw3360_scan_perf_task();
#endif
    uint8_t mot = pmw3360_reg_read(pmw3360_Motion);
    if ((mot & 0x88) != 0x80) {
        return false;
    }
    d->x = pmw3360_reg_read(pmw3360_Delta_X_L);
    d->x |= pmw3360_reg_read(pmw3360_Delta_X_H) << 8;
    d->y = pmw3360_reg_read(pmw3360_Delta_Y_L);
    d->y |= pmw3360_reg_read(pmw3360_Delta_Y_H) << 8;
    return true;
}

bool pmw3360_motion_burst(pmw3360_motion_t *d) {
#ifdef DEBUG_PMW3360_SCAN_RATE
    pmw3360_scan_perf_task();
#endif
    // Start motion burst if motion burst mode is not started.
    if (!motion_bursting) {
        pmw3360_reg_write(pmw3360_Motion_Burst, 0);
        motion_bursting = true;
    }

    pmw3360_spi_start();
    spi_write(pmw3360_Motion_Burst);
    wait_us(35);
    spi_read(); // skip MOT
    spi_read(); // skip Observation
    d->x = spi_read();
    d->x |= spi_read() << 8;
    d->y = spi_read();
    d->y |= spi_read() << 8;
    spi_stop();
    // Required NCS in 500ns after motion burst.
    wait_us(1);
    return true;
}

bool pmw3360_init(void) {
    spi_init();
    setPinOutput(PMW3360_NCS_PIN);
    // reboot
    pmw3360_reg_write(pmw3360_Power_Up_Reset, 0x5a);
    wait_ms(50);
    // read five registers of motion and discard those values
    pmw3360_reg_read(pmw3360_Motion);
    pmw3360_reg_read(pmw3360_Delta_X_L);
    pmw3360_reg_read(pmw3360_Delta_X_H);
    pmw3360_reg_read(pmw3360_Delta_Y_L);
    pmw3360_reg_read(pmw3360_Delta_Y_H);
    // configuration
    pmw3360_reg_write(pmw3360_Config2, 0x00);
    // check product ID and revision ID
    uint8_t pid = pmw3360_reg_read(pmw3360_Product_ID);
    uint8_t rev = pmw3360_reg_read(pmw3360_Revision_ID);
    return pid == 0x42 && rev == 0x01;
}

uint8_t pmw3360_srom_id = 0;

void pmw3360_srom_upload(pmw3360_srom_t srom) {
    pmw3360_reg_write(pmw3360_Config2, 0x00);
    pmw3360_reg_write(pmw3360_SROM_Enable, 0x1d);
    wait_us(10);
    pmw3360_reg_write(pmw3360_SROM_Enable, 0x18);

    // SROM upload (download for PMW3360) with burst mode
    pmw3360_spi_start();
    spi_write(pmw3360_SROM_Load_Burst | 0x80);
    wait_us(15);
    for (size_t i = 0; i < srom.len; i++) {
        spi_write(pgm_read_byte(srom.data + i));
        wait_us(15);
    }
    spi_stop();
    wait_us(200);

    pmw3360_srom_id = pmw3360_reg_read(pmw3360_SROM_ID);
    pmw3360_reg_write(pmw3360_Config2, 0x00);
    wait_ms(10);
}

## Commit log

2021-06-19 fix RGB light hanrdware settings as split keyboard
    [config.h]
2021-06-19 make keymaps using trackball driver
2021-06-19 doc trackball driver
2021-06-22 fix and rewrite LAYOUT macro
    [config.h]
2021-06-23 prototype double balls firmware
2021-06-27 revise trackball driver and related
2022-02-03 Add via.json upload
    VIA対応用のjsonファイルを修正しました。
    ボール位置によるレイアウト切り替え部が、どのようなアドレス割り当てになっているか解析できず考慮出来ておりません。申し訳ありません。
    ご検討いただければ幸いです。
2022-02-03 Add default keymap upload
    デフォルトキーマップを検討してみました。
    Keyball39は数字列（記号列）が無いので、シフトっぽいレイヤーは削除しまして、
    １．カッコキーを中央へ集める
    ２．レイヤー１は記号とマウスクリック等動作、ファンクションキーを配置
    ３．レイヤー２は一時的な数字や数式キーの入力がメインですが、トグルでレイヤー２へ固定した場合には右手でマウスを持ち、左手でテンキーを操作しているような数値入力デバイスとしての機能を目指しています。
    という方針でキーマップを作製してみまし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
2022-03-02 Update Build guide of Keyball61
    I add the article of putting aclylic spacers.
2022-03-20 Add Keyball61's circuit PCB and Acryl Data
    Add Keyball61's circuit PCB and Acryl Data for our Customers.
    [Keyball61_Rev1_BallSide_Bottom_Acryl_Clear2mm.dxf, Keyball61_Rev1_NoBallSide_Bottom_Acryl_Clear2mm.dxf]
2022-03-21 replace PCB socket image
    replace PCB socket image
2022-03-21 change PCB socket image
    change PCB socket image
2022-04-02 scroll snap feature
    introduce scroll snap feature. scroll snap locks an axis to scroll at
    first, then unlock it if ball moved to another axis an amount.
    apply clang-format. configuration for clang-format is changed in QMK.
    this apply it on files exclude config.h files.
    [pmw3360.c]
2022-04-11 use correct clock to communicate with PMW3360 sensor
    [pmw3360.c]
2022-04-21 keyball61: extend delay after unselect pin
2022-04-22 keyball61: more extend delay after unselect pin
2022-06-15 Delete acrylic spacers from Buildguide
    Delete acrylic spacers from Buildguide
2022-09-24 Add design data of Keyball39
    Add design data of Keyball39
    [Keyball39_BottomAcryl_2mm_136x185mm.dxf, Keyball39_MiddleAcryl_3mm_98x187mm.dxf]
2022-10-25 Add top PCB data of Keyball61
    Add top PCB data of Keyball61
2023-01-17 Use info.json to define USB device descriptor parameters
2023-01-22 bump up device_version to "1.0.0"
2023-01-30 Fix number of MX switchews
    Fix number of MX switchews
2023-08-12 fix number of switch
2023-09-04 Update of PCB and Circuit to Rev2
    Update of PCB and Circuit to Rev2
2023-09-04 Delete keyball61/design_data/Circuit of Keyball61 Rev1 Ball_side.pdf
    to Rev2
2023-09-04 Delete keyball61/design_data/Circuit of Keyball61 Rev1 NoBall_side.pdf
    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
2023-09-17 brush up landing pages
2023-09-17 replace or remove links to shirogane-lab.com
    shirogane-lab.com is current domain.
2023-09-28 注意書きを追加
2023-10-02 add middle acryl data
    add middle acryl data
    [Keyball61_MiddleAcryl_3mm.dxf]
2023-10-17 change default buildguide to 12P pin-sockets
    change default buildguide to 12P pin-sockets
2023-11-27 Add KiCad file of Keyball44 middle PCB
    Add KiCad file of Keyball44 middle PCB
2023-11-27 Add KiCad file of Keyball39 middle PCB
    Add KiCad file of Keyball39 middle PCB
2023-11-27 Add KiCad file of Keyball61 middle PCB
    Add KiCad file of Keyball61 middle PCB
2023-12-06 Print up to 3 pressing keys on OLED
2024-03-21 Improve optical sensor (PMW3360) driver
    * Improved register access timings
    * Stabilized motion burst
    * Makde SROM uploadable, to support high CPI setting
    * Fix Keyball 61's develop keymap
    [pmw3360.c]
2024-03-22 remove redundant function call
    which is inserted on conflict resolution.
2024-03-23 define constants always
    remove some `ifdef` switches.
2024-03-25 enable SPLIT_OLED_ENABLE
    to fix https://github.com/Yowkees/keyball/issues/526
    [config.h]
2025-12-08 Pin the docker old image to use
2026-03-12 Add Garber and circuit of Keybit8
    Add Garber and circuit of Keybit8
    [keybit8.GBL, keybit8.GBO, keybit8.GBS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]
2026-03-13 Add circuit diagram of Keybit8
    Add circuit diagram of Keybit8
2026-09-17 Add disign_data of KeyballPlus
    Add disign_data of KeyballPlus
    [KeyballPlus_Left_Bottom_AcrylicPlate_2mm.dxf, KeyballPlus_Left_Middle_AcrylicPlate_3mm.dxf, KeyballPlus_Right_Bottom_AcrylicPlate_2mm.dxf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]
2026-09-25 fix: don't nest SPI bus acquisition in pmw3360_init (#883)
    pmw3360_init() opened the SPI bus and then called pmw3360_reg_write() and
    pmw3360_reg_read(), each of which opens the bus again. That nesting was
    harmless until QMK 0.26.0, where qmk/qmk_firmware#23439 gave the ChibiOS
    spi_start()/spi_stop() bus mutex semantics:
    bool spi_start(...) {
    spiAcquireBus(&SPI_DRIVER); // acquired on every call
    if (spiStarted) {
    return false; // returns without releasing
    }
    Only spi_stop() releases the bus, so the inner call is a second
    spiAcquireBus() from the same thread. ChibiOS mutexes are not recursive, so
    it blocks forever. SPI_USE_MUTUAL_EXCLUSION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
    [pmw3360.c]
2026-09-25 fix: port rp2040 support for keyball39 (#882)
    [config.h]
2026-09-25 ci: bump actions in composite actions to Node 24 (#876)
    Every build job currently emits a deprecation warning:
    Node.js 20 is deprecated. The following actions target Node.js 20 but
    are being forced to run on Node.js 24: actions/checkout@v4
    The workflows under .github/workflows/ were already moved to Node 24
    runtimes, but the two local composite actions under .github/actions/ were
    left behind on v4:
    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
2026-10-26 Fix Keyball+ build guide: update firmware link, swap cover/kit photosDocs/keyballplus buildguide (#890)
    * Add Keyball+ build guide (draft based on Keyball39)
    Keyball39のビルドガイドをベースに、Keyball+向けのビルドガイド（jp/en）を
    新規作成。以下のKeyball+固有の差分を反映:
    - 全キーがロープロファイル（Kailh Choc V1/V2）。キーソケットはchoc用39個のみ
    - LEDは左右非対称（左29個・右26個、合計55個）
    - ファームウェアの書き込みはKeyball Link（REMAPではない）
    - 自前ビルド用リポジトリのリンクをkeyball-plus-firmwareに変更
    画像は暫定的にkeyball39のものを相対パスで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
2026-10-26 Remove accidentally committed raw photo folder, fix .gitignore, and sync guide content (#891)
    PR #890 のマージ時、クリーンアップ前の状態（カメラの生写真・RAW/TIFF/PSD含む
    約820MB）がそのまま取り込まれてしまったため、本コミットで削除する。
    - keyballplus/doc/rev1/images/Keyball Plus/ を削除（追跡対象外のまま復活しないよう
    .gitignoreのバグも修正: ファイル自体がkeyballplus/内にあるのに
    "keyballplus/..."から始まるパスを書いていたため一度も機能していなかった）
    - ビルドガイド本文を最新化（PR #890マージ後に行った追加修正を反映）:
    - 写真5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
2026-10-27 Keyball+ build guide: socket combinations, 38-key option, REMAP, RP2040Docs/keyballplus buildguide (#893)
    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
2026-10-27 Document RP2040 ProMicro firmware flashing for Keyball39/44/61 (#892)
    * Document RP2040 ProMicro firmware flashing for Keyball39
    Keyball+のビルドガイドで追加したRP2040 Pro Micro向けの手順を
    Keyball39にも反映（jp/en）:
    - 3-7章: RP2040はリセットボタンが基板裏面にあるため、組み立て前に
    ファームウェアを書き込む必要がある旨と具体的な書き込みモードへの
    入り方を追記
    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
2026-10-30 Follow-up to #892: RP2040 notes, firmware chapter split, and test-firmware step removal (Keyball39/44/61) (#894)
    * Add RP2040 ProMicro insertion-orientation note to Keyball39/44/61 guides
    Keyball+向けに追加した「RP2040 ProMicroを差し込む際に使用しないホール
    （赤丸箇所）」の注意書きと写真を、既存のRP2040対応記述（書き込み手順・
    ファーム選択表）がある3-7章の、コンスルーピンにProMicroを差し込んで
    はんだ付けする手順の直後に追加（jp/en、Keyball39/44/61）。
    写真はKeyball+用に撮影したものをそのまま流用（ユーザー指示により、
    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

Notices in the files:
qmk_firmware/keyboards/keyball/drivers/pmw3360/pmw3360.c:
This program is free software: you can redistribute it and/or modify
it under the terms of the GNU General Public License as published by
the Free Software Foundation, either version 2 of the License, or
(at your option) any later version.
